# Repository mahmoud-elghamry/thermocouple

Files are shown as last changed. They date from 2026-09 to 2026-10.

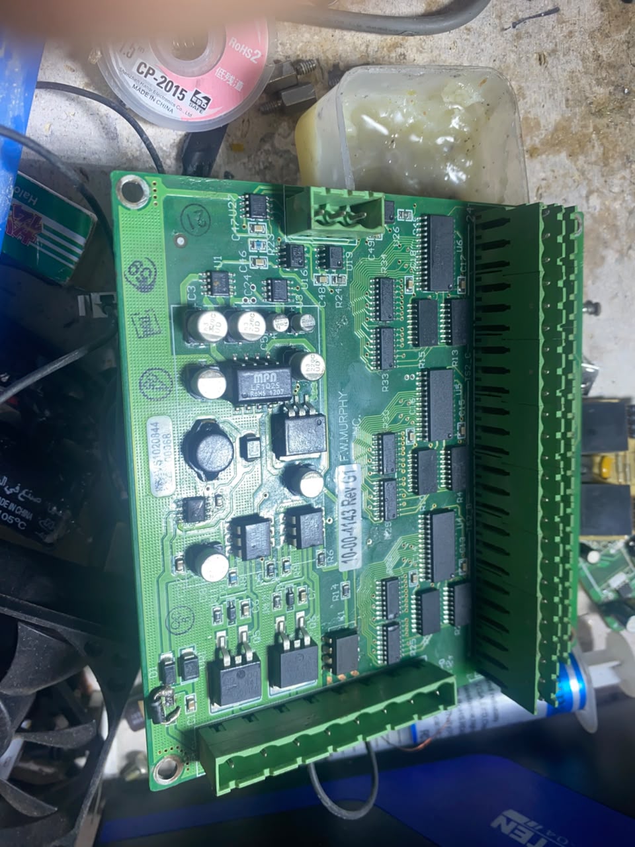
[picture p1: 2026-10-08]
docs/reference/benchmarks/murphy-tdxm/photo-7.jpg

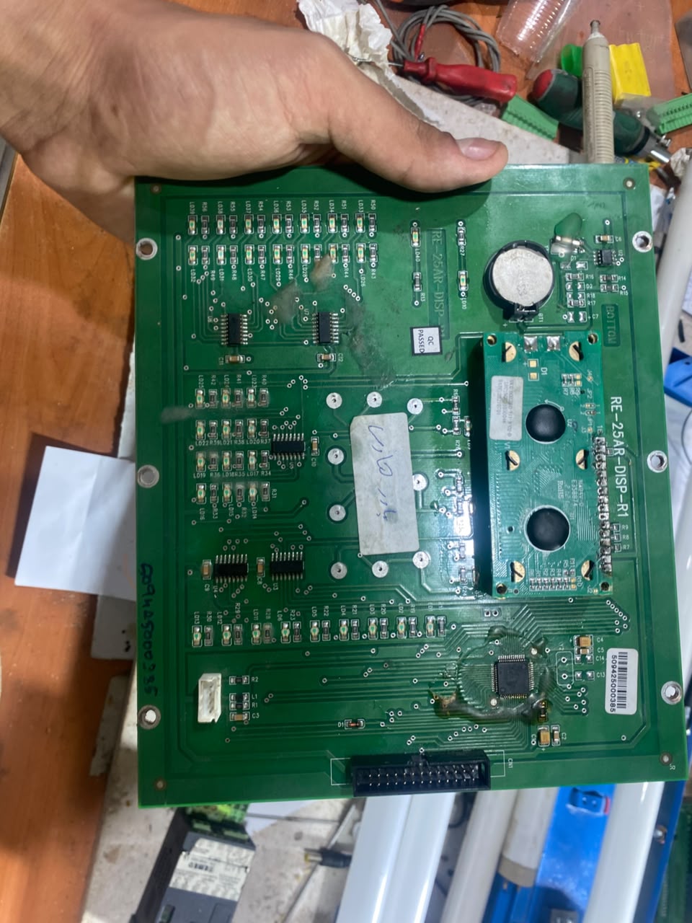
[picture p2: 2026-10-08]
docs/reference/benchmarks/murphy-tdxm/photo-6.jpg

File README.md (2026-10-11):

# Thermo — 24-channel thermocouple protection board

> Working on this repository with an AI agent? Start at **`AGENTS.md`**,
> then `docs/STATE.md`.

One board that reads **24 K-type thermocouples** on one engine (grounded,
insulated or mixed probes, roughly 50 m cables, no VFD) and opens a common
run-permit contact when any channel passes its own setpoint, the sensor fails
or the unit itself fails. It is being built to go on real equipment.

The output is **energised to run**: loss of power, a reset or a fault opens
the contact, so the engine cannot start.

## Where things are

| | |
|---|---|
| **The active board** | `hardware/24ch/` (REV A3, 3x AD7124-8) — see its README; repairs before ordering in `docs/ISSUES.md` P0 |
| **Earlier 8-channel board** | `hardware/8ch/` (REV A2) — reference only, never ordered |
| **Firmware** | `firmware/` — today only the 8-channel images; the 24-channel firmware is not written yet (I-100, I-104, I-118, I-119) |
| **What is done and what is next** | `docs/STATE.md` |
| **Open problems** | `docs/ISSUES.md` |
| **Why things are the way they are** | `docs/decisions/` (start with `0031`) |
| **Commands that actually work here** | `docs/TOOLS.md` |

`hardware/single-channel/` and `_old/` are **superseded** and kept only as a
record. Do not work from them and do not modify them.

## Build and check

```powershell
pwsh -File firmware\build.ps1                 # firmware images + host tests
cd hardware\24ch\gen; python build.py          # 24-ch schematic, ERC, netlist check
python docs\check_docs.py                     # entry documents agree with each other
```

> **The firmware images are not interchangeable.** The eight-channel image
> drives the run output HIGH only while it is *safe to run*; the legacy
> single-channel images drive the same pin HIGH on *over-temperature*.
> Flashing the wrong one inverts the safety function. `program.ps1` warns you.

## State

An **engineering prototype**: nothing has been built or electrically tested.
The isolation rules in `.kicad_dru` are functional, not qualified against any
standard; the contacts are rated for low-voltage signal loads only (30 VDC /
1 A). `docs/ISSUES.md` is the full list; nothing is claimed as done without a
report to back it.

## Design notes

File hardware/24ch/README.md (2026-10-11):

# hardware/24ch — the 24-channel board (REV A3)

One board for all 24 K-type thermocouples (`docs/decisions/0031`), front end
and parts per `docs/decisions/0032` (read all three revisions at its end).
`hardware/8ch/` (REV A2) stays as the reference design and is not modified.

## The schematic is generated

Edit the generator in `gen/`, never the `.kicad_sch` files:

```powershell
cd hardware\24ch\gen
python build.py      # writes the sheets, runs ERC, checks the netlist against the model
```

`build.py` exits non-zero unless kicad-cli ran cleanly and wrote fresh reports, ERC has **0 errors and 0 warnings** and every
pin in the exported netlist matches the model in `gen/c_*.py`.

| File | What it holds |
|---|---|
| `gen/c_power.py` | battery input, PTC, protection, LM5164 5 V buck, 5 V crowbar |
| `gen/c_mcu.py` | ATmega1284P, crystal, ISP, LCD header, five buttons |
| `gen/c_iso.py` | B0505S, LP2985, preload, AVDD clamp, 3x ISO7761, REF3030, V_MID/V_BIAS, engine-reference feed/sense |
| `gen/c_out.py` | trip relay (poles in series), alarm relay, isolated RS-485 |
| `gen/c_bank.py` | one bank: 2 headers, 8 input networks, AD7124-8, 2 ADT7310 (used three times) |
| `gen/model.py`, `emit.py`, `libs.py`, `sexp.py`, `customlib.py` | the generator itself |
| `lib/thermo24.kicad_sym` | AD7124-8 and ADT7310 symbols (generated) |

Every page is A4 or A3 (the owner prints nothing bigger): `build.py` splits a
sheet into `<name>_1`, `<name>_2` pages when it would not fit A3, and stops if a
page still comes out larger.

Nets that appear on more than one sheet become global labels automatically;
all others are local. References: banks 1xx/2xx/3xx, isolation 4xx, MCU 5xx,
power 6xx, outputs 7xx.

## The board

Run with KiCad's python (`C:/Program Files/KiCad/10.0/bin/python.exe`), in order:

| Step | Command | What it does |
|---|---|---|
| 1 | `pcb_new.py` (once) | empty 170 x 145 mm 4-layer board |
| 2 | `kicad-tool pcb sync thermo24.kicad_pcb thermo24.kicad_sch` | footprints and nets from the schematic (needs `KICAD10_FOOTPRINT_DIR`) |
| 3 | `place.py` | every footprint per floor plan v2; prints courtyard overlaps (must be 0) |
| 4 | `rules.py` | domains by pad position (a net in two domains stops it), net classes, `.kicad_dru`, planes, barrier keep-outs, U601 thermal vias |
| 5 | `route24.py --passes 30 --threads 4 [--board copy --tag x]` | Freerouting via DSN/SES, then zone refill |
| 6 | `finish.py` / `maze.py` | **incremental only, after a routing result is kept**: DRC, stubs, lock, hand routes (`add`), maze router + rip-up |
| - | `guard.py`, `fab.py` | `guard.py`: write guard for every tool that saves the board (refuses while KiCad has it open or another tool holds `output/.writer.json`; `guard.sha256`). `fab.py`: a NEW `production/24ch-reva3-<time>-<sha6>/` per run, DRC and plots on a snapshot copy (source never saved), `MANIFEST.txt` (commit, hashes, DRC, KiCad version), `ORDER-NOTES.txt` (I-106/I-105) |
| 7 | `buck24.py`, `move.py`, `capnear.py`, `fiducials.py`, `vbias_pour.py`, `silk.py` | **local repairs (`0034` D3, `0035`)**: buck stage, move parts, put a cap beside its pin (`capnear.py U403 1 C407 --apply`, `capnear.py via REF PAD`), fiducials, V_BIAS guard pours, silkscreen; then `finish.py dangling`/`dedupe`, `maze.py`, `pincaps.py` |
| - | `cost.py`, `view.py`, `kicad_ui.ps1`, `padcheck.py` | BOM cost from LCSC; render a region; drive the KiCad GUI; pad-gap check before routing |

Domains: sensor island = x < 42 or y > 103 (mm, y down); barrier bands x 42-45
and y 100-103, 3 mm copper-free on all layers; RS-485 bus pocket x 55-84,
y < 22. `fpinfo.py` lists courtyard sizes.

## Not done yet

See `docs/STATE.md`. Board repairs from the Astra review (`docs/decisions/0034`):
I-111 decoupling/buck parts beside their pins, I-112 fiducials, I-113 RUN PERMIT
label, I-114 CJ sensors, button header (`0034` D2), I-115 gates, I-116 accessory BOM.
Then `gen/fab.py` again. Every "check" item in `0032` still applies.

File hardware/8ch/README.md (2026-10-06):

# 8-channel thermocouple protection board — engineering prototype

**Status: not released for fabrication.** See “Where this actually stands”
below before drawing any conclusion from a clean check report.

This directory is a self-contained KiCad 10 project. It does not share files
with, and must not be confused with, the single-channel board in `hardware/single-channel/`.

---

## What the board is

| | |
|---|---|
| Size / stack-up | 250 × 140 mm, 4 layers |
| Measurement | 8 × MAX31856, one per K-type input, on a shared isolated island |
| Controller | ATmega32A-PU in a DIP-40 socket, internal RC oscillator, 5 V |
| Local HMI | 16×2 HD44780 in 4-bit mode, five buttons, contrast pot |
| Output | Energised-to-run SPDT dry contact (G5LE-1 24 V) via a BSS131 (240 V) low-side switch, REV A2 (`0022`) |
| Comms | Isolated half-duplex RS-485 (ADM2587E) with jumper-selected termination and bias |
| Supply | 24 VDC in → PTC + series Schottky + TVS → TSR 1-2450 → 5 V |
| Sensor supply | IA0505S isolated DC-DC → LP2985-3.3 → +3V3_SENS |

### Layer stack-up

```
F.Cu    signal + ground pour
In1.Cu  ground planes   GND_SENS | GND_CTRL | GND_RS485
In2.Cu  supply planes   +3V3_SENS | +5V_CTRL | +5V_RS485
B.Cu    signal + ground pour + chassis/PE ring
```

No signal is routed on In1 or In2. Every outer-layer track therefore has an
uninterrupted return directly beneath it, and the In1/In2 pair provides the
interplane capacitance that does most of the high-frequency decoupling for the
microvolt front end.

### Three copper islands

```
      x=6           x=145  x=151.5                  x=208 x=214     x=244
   +-----------------+ gap +-------------------------+ gap +---------+
   |  SENSOR ISLAND  |     |  CONTROL ISLAND         |     |         |  y=6
   |  8 × MAX31856   |     |  ATmega32A, LCD,        |     |(control)|
   |  GND_SENS       |     |  relay, 24 V input      |     |         |  y=97
   |  +3V3_SENS      |     |                   ------+-----+---------+
   |                 |     |                   | gap band            |  y=99
   |                 |     |                   |   RS-485 ISLAND     |
   +-----------------+     +-------------------+   GND_RS485         |  y=134
```

Signals cross a barrier only through U10/U11 (ISO7760 / ISO7761) and U15
(ADM2587E). The gap bands are emitted as KiCad rule areas, so the autorouter
cannot bridge them and a reviewer can see the intent on the board.

A fourth net, `CHASSIS_SHIELD`, is the cable-shield / protective-earth
reference. It is a B.Cu loop 3 mm inside the board edge, bonded to the four
plated M3 mounting holes, to J1.3, J4.4 and the eight thermocouple shield
screws — deliberately isolated from all three signal grounds so a shield
current cannot become a measurement ground loop.

---

## Files

| File | Role |
|---|---|
| `thermocouple_8ch.kicad_sch` | schematic root (A4 index) — the structural source of truth, with its sheets: |
| `power` / `mcu` / `isolation` / `relay_rs485.kicad_sch` | one A4 sheet per function (`docs/decisions/0021`) |
| `channel.kicad_sch` | the thermocouple channel, drawn once, used by TC1-TC8 (`0019`) |
| `thermocouple_8ch.kicad_pcb` | board |
| `thermocouple_8ch.kicad_pro` | project, **including the net classes** |
| `thermocouple_8ch.kicad_dru` | custom clearance rules (isolation, relay, chassis) |
| `sch_layout/build.py` | builds the schematic (base `05d6abd` + `sch_layout/`), with its own ERC and netlist gate |
| `kit_list.py` | the technician's through-hole kit list |
| `apply_rules.py` | writes net classes and `.kicad_dru` into the project |
| `board/` | the generator, split by responsibility - see `board/__init__.py` |
| `generate_board.py` | command-line entry point for `board/` |
| `route.py` | DSN → Freerouting → SES, then pours, stitching and finishing |
| `close_gaps.py` | joins anything DRC still reports as unconnected |
| `check_board.py` | structural checks DRC cannot make (islands, barriers, decoupling, cold junction, filter symmetry) |
| `run_all.ps1` | snapshot validation by default; explicit regeneration after owner authorization |
| `validate.ps1` / `check_commands.ps1` | fresh copy, source hashes, checked native exits and report gates |
| `test_gates.ps1` | fault injection for native-command and report failures |

Design rules live in the **project**, not in the scripts. Anyone opening
`thermocouple_8ch.kicad_pro` in KiCad sees the same track widths, via sizes and
clearances the generator used.

---

## Validating and rebuilding

```powershell
pwsh -File hardware\8ch\run_all.ps1
```

The default validates a fresh snapshot under `production/` without changing the
source hardware, including zone refill on the copy before DRC. Errors stop the
pipeline; warnings remain visible. Full regeneration requires `-Regenerate`; the owner lifted the REV A0 freeze
(`docs/decisions/0014`), so run `board_provenance.py --check` first. The commands
below are the regeneration sequence:

```bash
python sch_layout/build.py --in-place
kicad-cli sch erc --output erc-report.rpt --severity-error --severity-warning thermocouple_8ch.kicad_sch
kicad-cli sch export netlist --output thermocouple_8ch.net thermocouple_8ch.kicad_sch
python apply_rules.py
kicad-tool pcb sync thermocouple_8ch.kicad_pcb thermocouple_8ch.kicad_sch
"C:\Program Files\KiCad\10.0\bin\python.exe" generate_board.py
"C:\Program Files\KiCad\10.0\bin\python.exe" route.py --passes 40 --threads 1
"C:\Program Files\KiCad\10.0\bin\python.exe" check_board.py
kicad-cli pcb drc --output drc-report.rpt --severity-error --severity-warning --schematic-parity thermocouple_8ch.kicad_pcb
```

`generate_board.py` and `route.py` need KiCad 10's bundled Python (`pcbnew`).
Re-running regeneration discards the existing routing. Snapshot validation
checks the current saved board without relying on regeneration reproducibility.

### External tools

Routing needs **Freerouting 2.4.x** and a **Java 25** runtime. Neither is in
this repository. Defaults are `%LOCALAPPDATA%\kicad-tools\freerouting.jar` and
`%LOCALAPPDATA%\kicad-tools\jre25\*\bin\java.exe`; override with
`FREEROUTING_JAR` and `FREEROUTING_JAVA`. Freerouting 2.4.1 is compiled to
class-file version 69, so a Java 21 runtime will not load it.

---

## Check results

Read `erc-report.rpt` and `drc-report.rpt`; these numbers come from them.

| Check | Before | Now |
|---|---|---|
| clearance | 304 | **0** |
| shorting items | 19 | **0** |
| tracks crossing | 22 | **0** |
| dangling vias | 7 | 1 (warning) |
| hole clearance / hole-to-hole | 6 / 5 | **0 / 0** |
| zones intersecting | 2 | **0** |
| starved thermals | 2 | **0** |
| solder-mask bridges | 2 | **0** |
| footprint/symbol field mismatch | 146 | **0** |
| silkscreen overlap / over pad | 10 / 3 | 6 / 2 (warnings) |
| **unconnected items** | 46 | **0** |
| **schematic ↔ PCB parity** | — | **0** |
| ERC errors | 7 | **0** |
| ERC warnings | 189 | 171 (all `endpoint_off_grid`) |

**Zero errors.** The nine remaining violations are warnings: six silkscreen
overlaps, two pieces of silkscreen over a pad, and one dangling via.

`check_board.py` passes all six structural checks that DRC cannot make - island
membership, isolation barrier, decoupling proximity, cold-junction distance,
input-filter symmetry and routing completeness. Zero courtyard overlaps, zero
parts off the board edge, all 167 footprints carry a courtyard.

### Fabrication output

Generated into `production/8ch/` (not committed - regenerate it):

```bash
kicad-cli pcb export gerbers --output ../../production/8ch/     --layers F.Cu,In1.Cu,In2.Cu,B.Cu,F.Paste,B.Paste,F.Silkscreen,B.Silkscreen,F.Mask,B.Mask,Edge.Cuts     --subtract-soldermask thermocouple_8ch.kicad_pcb
kicad-cli pcb export drill --output ../../production/8ch/ --format excellon     --drill-origin absolute --excellon-units mm --generate-map --map-format gerberx2 thermocouple_8ch.kicad_pcb
kicad-cli pcb export pos --output ../../production/8ch/thermocouple_8ch-pos.csv     --format csv --units mm --side both thermocouple_8ch.kicad_pcb
kicad-cli pcb export ipcd356 --output ../../production/8ch/thermocouple_8ch.d356 thermocouple_8ch.kicad_pcb
```

Eleven Gerber layers, Excellon drill plus map, the `.gbrjob`, a placement CSV
and an IPC-D-356 netlist for the fab's electrical test.

**Do not hand-edit the board.** `generate_board.py` clears every track, via,
zone and drawing, so anything drawn by hand in KiCad is erased on the next run.
Fixes belong in `board/` or in `route.py`.

---

## Where this actually stands

Nothing here makes this board safe to put on a machine. The following remain
open and none of them can be closed by DRC, ERC, or a 3D render:

- **The shared sensor island is a conditional proof of concept.** It isolates
  the group of eight channels from the controller. It does **not** isolate the
  channels from each other. It is only valid if the eight thermocouple sheaths
  are measured to be at the same potential, on the same equipotential bond.
  That measurement has not been made.
- **MAX31856 is not a galvanic isolator.** It is a better thermocouple
  front end than MAX6675 — filtering, fault detection, input protection — but
  T+/T− are not separated from AGND/DGND. Its presence does not solve a
  grounded tip or a 50 m cable.
- **The isolation rules are functional, not certified.** `.kicad_dru` enforces
  3 mm between islands. That number comes from the tightest part on the board
  (the IA0505S module's own pin pitch), not from a creepage/clearance analysis
  against IEC 61010 at a stated working voltage and pollution degree.
- **The PE ring's spacing is set by connector geometry.** Screw terminals put
  the shield pin 5.00 mm from the adjacent signal pin, which leaves 2.4 mm of
  copper gap. The chassis clearance rule is 1.5 mm for that reason. It is not
  a mains-rated separation.
- **The dry contact is marked LOW-VOLTAGE LOAD ONLY** and its clearances are
  chosen to match that, not a mains rating.
- **No noise, EMC or real-sensor testing has been done.** Cables run about 50 m
  from engine cylinder bodies to a separate panel, with no VFD in the installation.
  Layout symmetry and a plane pair improve the odds;
  they do not substitute for measurement.
- **The unregulated isolated DC-DC needs review.** IA0505S is an unregulated
  ±5 V module. At the ~12 % load this island draws, its output can sit well
  above 5 V. The AP2112K was replaced by LP2985-3.3 with a higher input rating
  (decision 0002), but the converter's real output still needs measurement.
- **DRDY and FAULT are not brought to the MCU.** Both isolators are fully
  allocated (ISO7760: 6/6 forward; ISO7761: 5 forward + 1 reverse for MISO), so
  crossing sixteen more signals needs a second isolator plus fault-OR logic.
  The firmware reads the MAX31856 fault register (0x0F) on every sample. This
  is a deliberate trade-off — see the plan document — not an oversight.
- **Stock and price snapshots in `passives_catalog.json` are not a live
  availability guarantee.** Re-check before ordering.

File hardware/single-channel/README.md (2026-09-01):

# Thermocouple meter PCB

Editable two-layer KiCad 10 PCB for an ATmega32A, MAX31856, off-board 16x2
LCD, alarm LED and 5 V SPDT relay. The board is 150 x 70 mm. It accepts a
regulated 5 V input and makes 3.3 V locally with an AMS1117-3.3. The MCU and
MAX31856 run at 3.3 V; the LCD runs at 5 V.

The thermocouple front end follows the MAX31856 application guidance:

- BIAS is connected to T-.
- Matched 100 ohm series resistors are fitted in T+ and T-.
- 100 nF is fitted differentially across T+ and T-.
- 10 nF common-mode capacitors are fitted from each input to ground.
- 100 nF local bypass capacitors are fitted at AVDD and DVDD.

Generate the PCB from the deterministic Python source, run DRC, then export
Gerbers, drill files, PDF and 3D previews:

```powershell
& 'C:\Program Files\KiCad\10.0\bin\python.exe' .\generate_board.py
& .\build_outputs.ps1
```

J2 is a standard 16-pin HD44780 LCD header. J4 is a 6-pin AVR ISP header.
The ATmega32 uses its internal 8 MHz clock, so no crystal is required.

PB3 (DIP pin 4) drives Q1 through R4; Q1 switches the K1 coil. D1 clamps the
coil flyback voltage, R5 keeps the relay off during reset, and D2/R6 indicate
the output state. J5 exposes COM/NO/NC. This contact area is intended only for
low-voltage loads in this revision; it is not documented or certified for mains.

## Delivered fabrication files

- `thermocouple_meter.kicad_pcb`: editable KiCad 10 board.
- `drc-report.txt`: zero violations and zero unconnected pads.
- `gerbers/`: copper, solder-mask, silkscreen, outline and drill files.
- `output/thermocouple_meter_gerbers.zip`: fabrication archive.
- `output/thermocouple_meter_layers.pdf`: printable layer plots.
- `output/positions.csv`: component positions.
- `output/pcb_top.png`, `pcb_bottom.png`, `pcb_isometric.png`: 3D previews.
- `output/kicad_happy_pcb_analysis.json`: extra PCB/DFM analysis.
- `output/kicad_happy_gerber_analysis.json`: extra Gerber analysis.

Three global fiducials are included. The router also forbids layer changes in
pad keepouts, eliminating the via-in-pad warnings found during the additional
DFM pass. The remaining PCB-analyzer warning is low test-point coverage, which
is accepted for this hand-assembled educational revision.

This board is for the **MAX31856 final hardware**. MAX6675 is used only as a
Proteus fallback and is not a pin-compatible replacement for MAX31856.

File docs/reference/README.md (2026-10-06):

# Reference

Background documents. **These are not sources of truth any more.**

The live documents are `AGENTS.md` at the repository root and the five files in
`docs/`. If something here disagrees with `docs/STATE.md`, `docs/ISSUES.md` or
`docs/decisions/`, those win.

| File | What it is | Still useful for |
|---|---|---|
| `INDUSTRIAL_8CH_PLAN_AR.md` | the original requirements and architecture study | the reasoning behind the isolation architecture, the No-Go conditions, the standards list. **Its §22 prototype geometry (250 x 140, 30 mm channel pitch) was never justified - see `0028`, I-090** |
| `SOFTWARE_ARCHITECTURE_AR.md` | the MCAL/HAL/APP layering | firmware work |
| `CONNECTIONS.md` | pin map used by the Proteus simulation | the simulation only — not the 8-channel board |

`analysis/` holds a kicad-happy run against the single-channel board from
2026-09-01. It is kept on disk but not tracked: it is machine output, and the
findings it supported are now issues in `docs/ISSUES.md`.

Moved to `_old/docs-reference/` on 2026-10-06: `DESIGN_REVIEW_AR.md` (single-channel
review, findings already in ISSUES), `LESSONS_LEARNED_AR.md`, `PROJECT_GUIDE_AR.md`.

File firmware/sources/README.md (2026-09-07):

# Source lists

One file per link unit, one source path per line, relative to `firmware/src/`.

Both build systems read these files instead of carrying their own copy of the
list. Before this, `Makefile` and `build.ps1` each held a hand-maintained set
of sources that had already started to drift, and a file added to one but not
the other builds green on the developer's machine and fails in CI, or worse,
links a different program than the one that was tested (`I-022`).

Blank lines and `#` comments are ignored.

| File | Links into |
|---|---|
| `base.txt` | every target: GPIO, SPI, board pin map, LCD |
| `app_8ch.txt` | the eight-channel protection application, minus its converter |
| `bank_max31856.txt` | the real board's converter bank (`U2`..`U9`) |
| `bank_max6675.txt` | the Proteus simulation's converter bank |
| `app_legacy.txt` | the superseded single-channel board's application |
| `sensor_max31856.txt` | single-channel MAX31856 backend for the legacy app |
| `sensor_max6675.txt` | single-channel MAX6675 backend for the legacy app |
| `host_test.txt` | the pure modules the host tests link natively |
| `host_test_app.txt` | `main_8ch.c`'s application modules, linked natively against HAL doubles alongside `main_8ch.c` itself (pulled in by `#include`, not listed here - see the list's own comment) (I-042) |
| `host_test_driver.txt` | the MAX31856 bank driver, linked natively against a register model (I-042) |

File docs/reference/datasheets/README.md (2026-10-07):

# Datasheets

The documents this design was actually reasoned against. Downloaded 2026-09-10.

Tracked on purpose. A hardware project that cites a clamping voltage or an
input range should be able to show where the number came from, and manufacturer
URLs rot. About 23 MB in total.

| File | Part | What it settles here |
|---|---|---|
| `ATmega32A.pdf` | ATmega32A | fuse map (`firmware/fuses.md`): `CKSEL` for internal RC 8 MHz, BOD levels, and that **JTAGEN is programmed from the factory and occupies PC2-PC5** |
| `TSR1-series.pdf` | Traco TSR 1-2450 (was `U14`; replaced by LM5164, `0016`) | input range **6.5-36 V**, which is what carries a cranking dip and what fails on a 58 V load dump (`I-028`) |
| `R-78HB-0.5.pdf` | Recom R-78HB (candidate) | input **9-72 V**, 0.5 A. The wide-input candidate - note the 9 V minimum is *worse* for cranking than the 6.5 V fitted part |
| `G5LE-relay.pdf` | Omron G5LE-1 DC24 (`K1`) | coil 1.44 kOhm / 16.7 mA, must-operate 18 V, **must-release 2.4 V** - why an energised relay does not drop out during a cranking dip |
| `ISO7760.pdf` | TI ISO7760 (`U10`) | six-channel digital isolator, control to sensor island |
| `ISO7761.pdf` | TI ISO7761 (`U11`) | five-forward/one-reverse isolator, carries MISO back |
| `LP2985.pdf` | TI LP2985-3.3 (`U13`) | the 3.3 V sensor-island regulator chosen in `docs/decisions/0002` |
| `LM74930.pdf` | TI LM74930-Q1 | not fitted. An ISO 16750-2 load-dump protection controller, kept as the reference for what the battery case in `I-028` would actually need |
| `LM5164.pdf` | TI LM5164 (`U14`), SNVSAU4D, from ti.com, added 2026-09-26 | the source of every value in `CALCULATIONS.md` section 1: 100 V absolute maximum, EN/UVLO thresholds, R_RON, feedback, ripple injection |
| `ADM2587E.pdf` | ADI ADM2582E/ADM2587E (`U15`), Rev. C, from LCSC `C12081` (analog.com blocked), added 2026-09-26 | supply current: **120 mA maximum**, 98 mA typical into 54 Ohm - replaced the 100 mA estimate in `CALCULATIONS.md` 1.1 |
| `MAX31856.pdf` | Maxim MAX31856 (`U2`-`U9`), 19-7534 Rev 0, from LCSC `C116632` (analog.com blocked the workstation), added 2026-09-26 | **T- is biased to ~0.735 V by the BIAS output**, and the typical circuit ties BIAS to T- with a floating thermocouple - so the ungrounded probes of `0008` need no extra resistor (`I-027`). BIAS floats between conversions, which is why the firmware runs continuous mode |
| `BSS131.pdf` | Infineon BSS131 (`Q1` since REV A2), Rev. 2.6, from LCSC `C151498`, added 2026-09-28 | **240 V** V(BR)DSS against D2's 96.8 V clamp; VGS(th) 0.8-1.8 V; RDS(on) 20 Ohm max at 4.5 V; **pinout 1 G, 2 S, 3 D** (p1 drawing); ESD Class 0 (`I-066`, `0022`) |
| `1812L-PTC.pdf` | LUTE 1812L series (`F1` 1812L075/60GR since REV A2), from LCSC `C48985874`, added 2026-09-28 | **60 V** max, 0.75 A hold / 1.5 A trip, R min 0.090 Ohm, and the **hold-current derating table** that sets the 70 °C limit in `CALCULATIONS.md` 4.4 (`I-068`) |

## Not here

The **actual physical K-type probe** and extension cable have no recorded
manufacturer/model. The owner reports a probably grounded junction and accepts
the shielded extension-cable basis (`0029`, 2026-10-07). `MAX31856.pdf` is the
reader IC's datasheet, not the probe's. It is already available offline; do not
download it again or substitute a generic probe catalog as an exact match.
An electrically ungrounded junction still measures temperature. Identify the
installed/chosen probe before obtaining its exact temperature/insulation limits.
ADI/Omega reference download attempts in this cloud returned HTTP 403.

Not downloaded: `IA0505S` (`U12`, XP Power), the SMBJ TVS series
(`D2`; Littelfuse blocks download - the SMBJ33A figures used in `I-028` are
33 V standoff, 36.7-40.6 V breakdown, 53.3 V clamping, 600 W at 10/1000 us),
`SS310`, `1N4007`/`M7`, and the `2N7000` REV A1 used.

## Adding one

Keep the filename the part name, add a row above saying **what question the
document answers for this project** - not what the part is. A datasheet nobody
can say the purpose of is a 3 MB file nobody opens.

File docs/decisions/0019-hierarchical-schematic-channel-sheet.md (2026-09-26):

# 0019 — A3 root plus one channel sheet used eight times

* Status: accepted; amended by `0021` (functional sheets on A4)
* Date: 2026-09-26
* Deciders: owner (asked for A4 sheets, a channel drawn once), agent (the split)
* Relates to: `I-062`, `I-002`, `docs/decisions/0012`

## Context

The schematic was one flat A2 sheet with all 201 parts. It was correct but
hard to print or read. The owner asked for sheets per function on A4, with
the thermocouple channel drawn once and used eight times.

Net names are not cosmetic here. `apply_rules.py` assigns net classes by name
pattern, and those classes drive the isolation rules in `.kicad_dru`. The
board generator finds the RS-485 planes by name, and `check_board.py` sorts
nets into islands by name. A hierarchical sheet prefixes every net that stays
inside it with the sheet path.

Measured on the netlist: only **seven** nets leave a channel (its CS, plus
SCK, MOSI, MISO, +3V3_SENS, GND_SENS and CHASSIS_SHIELD). The other blocks,
however, have 65 sheet-local nets, and many of them are named in the rules
and in the generator: `+5V_RS485`, `GND_RS485`, `RELAY_*`, `RS485_*`,
`+24V_*`, `+5V_ISO`.

## Options

* **(a) Every function on its own A4 sheet.** This renames about 65 nets
  across the isolation rules, the plane generator and the checks.
* **(b) The channels only, as one reused sheet; the rest stays on the root,
  packed onto A3.** This renames 40 nets, all inside channels, all following
  one pattern: `/TCn_FILT_P` becomes `/TCn/FILT_P`.
* **(c) Keep the old names** by bringing every internal net out to a root
  label. This needs more than a hundred extra labels on the root, which is
  more clutter than the flat sheet had.

## Decision

**(b).** It delivers what the owner wanted most: one channel drawing, reused.
It confines the renames to a single pattern, which three places can match.
The isolation-relevant names of the control, RS-485 and relay blocks are not
touched at all. The root is A3, not A4: the MCU, isolators, power supply,
RS-485 and relay together do not fit A4 at a readable size.

How it is done and proved:

* `sch_layout/hier.py` derives the two files from the flat wired sheet, as
  the last step of `build.py`. It refuses if any channel's symbols are not
  placed exactly like channel 1's.
* `netlist_fingerprint.py --allow-renames` matches nets by their pin sets:
  all 645 pins stayed on the same nets, no component was added or removed.
  Exactly two deliberate differences: the 40 renames, and JTC1–8's value
  `TCn_K_TYPE` becomes `K_TYPE`, because KiCad 10 keeps one value per symbol,
  not per sheet instance. The baseline was regenerated from that proven
  netlist, with the reason written into it.
* `apply_rules.py` patterns now read `/TC?/FILT_?`, `/TC?/RAW_?` and
  `/TC?/MISO_CH`. **Without that change the channel nets fall to Default,
  and DRC reported 499 isolation violations on a test copy.**
* `sch_layout/rename_board_nets.py` renames the board's nets in place, so
  pads, tracks and zones move together; `kicad-tool pcb sync` alone moved
  only the pads. Copper is unchanged.

## Consequences

* Result on the workstation, KiCad 10.0.6: ERC 0/0; netlist IDENTICAL to the
  revised baseline; DRC 0 errors, 0 warnings, 0 unconnected, 0 parity;
  `check_board.py` all 6 ok; all 40 channel nets in `SensorSignal`.
  `build.py` from `05d6abd` reproduces the result (IDENTICAL, ERC 0/0).
* A new channel-level net needs a pattern in `apply_rules.py` of the form
  `/TC?/NAME`.
* `validate.ps1` and `board_provenance.py` now carry `channel.kicad_sch`.
* The flat wired sheet exists only as an intermediate in `build.py`'s scratch
  folder. `populate_schematic.py` still writes flat, label-only output as
  before; `build.py` carries it to the hierarchy.

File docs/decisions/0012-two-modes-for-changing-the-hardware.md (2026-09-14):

---
status: accepted
date: 2026-09-13
deciders: Zain
amends: 0010
---

# Two modes for changing the hardware, with a guard between them

## Context

Until now the hardware had exactly one way to change: run the pipeline.
`populate_schematic.py` rewrites the schematic, `generate_board.py` clears every
track, via, zone and drawing and re-places from `board/`, and `route.py` runs
Freerouting over the result. `AGENTS.md` rule 9 said, correctly, that nothing
drawn by hand survives.

That was the right architecture for getting from nothing to a placed, routed,
DRC-clean board. It is the wrong one now, and the reason is `docs/decisions/0010`:
REV A0 is frozen, and what the board needs from here are surgical changes -
nudge one silkscreen label, drop one dangling via, add two resistors for the
run-permit read-back.

Regenerating for a change that size is not conservative, it is reckless:

    move one silkscreen label
      -> generate_board.py clears the whole board
      -> Freerouting routes from scratch, differently every run
      -> a board nobody has verified, in place of one that passed
         0 DRC errors, 0 unconnected, 0 parity

Meanwhile a KiCad MCP is now installed (`.mcp.json`), which makes direct editing
practical for an agent rather than only for a human in the GUI.

## Decision

**Both modes are legitimate. Pick by the size of the change.**

| | Generative | Incremental |
|---|---|---|
| How | `populate_schematic.py`, `generate_board.py`, `route.py` | KiCad, or the KiCad MCP's seven write tools |
| Right for | new parts, a changed stack-up, re-placement, anything touching many nets | one label, one via, a value, a small local edit |
| Cost | full re-route, full re-verification, new Gerbers | none beyond the edit and its checks |
| Reproducible | yes - rerun and get the same board | no - the edit lives only in the file |

**What is forbidden is not either mode. It is running the generator on top of
hand edits without knowing they are there**, which destroys work silently and
which nothing in the project could previously detect: `netlist_fingerprint.py`
compares the *schematic's* connectivity and never looks at the PCB, and
`validate.ps1` hashes files only within a single run.

So a guard was added: `hardware/8ch/board_provenance.py`.

- `--record` stores the SHA-256 of `thermocouple_8ch.kicad_pcb` and
  `.kicad_sch` as the generator left them. Run it after every generator run.
- `--check` compares. It exits non-zero when the files have drifted, which
  means hand edits exist and a generator run would lose them. It also refuses
  while KiCad holds a `~*.lck`, because a second writer is exactly how the
  board was lost on 2026-09-07.
- `--status` reports without failing.

Tested on 2026-09-13: drift detected on a one-byte change, lock file detected,
and a clean tree reports `regenerating is safe`.

## The rule for crossing between modes

Going generative → incremental is free. Going the other way is not:

> Once the board has been hand-edited, the generator may not be run until the
> edit is either **folded back into `board/` and the part tables**, or
> **deliberately abandoned** - and `--record` re-run to say so in writing.

`--check` enforces the first half. The second half is a human decision and
should leave a line in `docs/STATE.md` saying what was given up.

## On closing KiCad

The guard **refuses** while KiCad has the project open. It does not close
KiCad, and no agent should: the window may hold unsaved work, which is the
2026-09-07 failure exactly. Opening KiCad is harmless; closing it is the user's
call.

## Consequences

**`board/`, `generate_board.py` and `route.py` stay.** They are not dead. They
are how the board is rebuilt when a change is big enough to deserve it, and
they remain the record of how REV A0 came to exist. This decision does not
retire the generative pipeline; it stops it being the only option.

**`check_board.py` still applies in both modes.** Its six structural checks -
island membership, isolation barrier, decoupling proximity, cold-junction
distance, filter symmetry, routing completeness - read the board as it is on
disk and do not care who wrote it.

**A hand-edited board cannot be reproduced from source.** That is the real
price. It is acceptable for a frozen revision whose Gerbers already exist; it
would not be acceptable while the design was still moving.

**The MCP's seven write tools are NOT permitted.** They were, for a few hours
on 2026-09-13, until the server's source was read. Correction below.

## Correction, same day: the MCP is read-only here

This decision originally allowed the KiCad MCP's seven write tools in
incremental mode. That was written from the tool list, not from the code. The
code says otherwise.

`add_wire` in `schematic_editor.py` does this: read the file as text, build a
`(wire (pts ...))` string, strip the final `)`, concatenate, write the file
back. No parser, no schema, no check that the coordinates land on a pin, no ERC
afterwards. `add_label` and the rest are the same shape. That is a blunter
instrument than `populate_schematic.py`, which at least resolves pin positions
from `kicad-tool sch query symbol --format json` before it places anything.

So the incremental mode stands, but its tool is **KiCad itself, or our own
scripts** - not the MCP. The MCP stays for what it is genuinely better at:
reading the PCB through `pcbnew` (real track lengths, via counts, zone areas)
instead of through hand-written regex, which got connectivity wrong twice on
2026-09-07.

The seven write tools are denied in `.claude/settings.json` so this is enforced
rather than merely written down.

## Rejected

**Stay purely generative.** Rejected: it makes a one-label fix cost a full
re-route and re-verification, which in practice means the fix never happens -
`I-006` and `I-024` have been open since the board was first routed for exactly
this reason.

**Go purely incremental and delete the pipeline.** Rejected: the measurements
still ahead (`I-003`, `I-004`, `I-013`) may force a change big enough to want a
clean regeneration, and `I-028` could still replace the whole input stage.
Throwing away a working generator before those are settled would be premature.

**Let an agent close KiCad automatically.** Rejected on the evidence: the
2026-09-07 loss was unsaved work in an open window. An agent cannot tell
whether a window holds unsaved work, and losing a user's edits to save a prompt
is a bad trade.

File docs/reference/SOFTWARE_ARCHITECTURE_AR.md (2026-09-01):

# تقسيم البرنامج إلى MCAL / HAL / APP

## لماذا التقسيم؟

الهدف أن قرار المشروع لا يختلط بسجلات الميكرو أو بتفاصيل نوع الحساس. لو تغير
MAX6675 إلى MAX31856، تتغير طبقة Driver واحدة فقط، ويبقى منطق الشاشة والإنذار
كما هو. ولو تغير ATmega32 لاحقًا، نستبدل MCAL بدل إعادة كتابة التطبيق كله.

```text
APP: main + pure logic + 100/95 C decision
             |
HAL: LCD | temperature sensor | alarm output
             |
MCAL: GPIO | SPI | board pin mapping
             |
Hardware: ATmega32A registers and pins
```

## MCAL — Microcontroller Abstraction Layer

هي الطبقة الوحيدة التي تعرف سجلات AVR وأرقام البورتات. لا تتخذ قرار تشغيل
الريلاي ولا تعرف معنى درجة الحرارة.

| الملف | الوظيفة |
|---|---|
| `include/mcal/gpio.h` | أنواع ودوال عامة لضبط اتجاه الرجل وكتابتها وقراءتها. |
| `src/mcal/gpio.c` | تنفيذ GPIO باستخدام DDRx وPORTx وPINx. |
| `include/mcal/spi.h` | واجهة بدء SPI ونقل بايت مع نتيجة نجاح/فشل. |
| `src/mcal/spi.c` | إعداد SPI Hardware ونقل بانتظار محدود يمنع التعليق الدائم. |
| `include/mcal/board.h` | أسماء أرجل اللوحة: LCD وCS وPB3. |
| `src/mcal/board.c` | ربط الأسماء بأرجل PORTA وPORTB الحقيقية. |

ميزة `board.c`: إذا نقلنا LED من PB3 إلى رجل أخرى، نغير Pin Mapping في مكان
واحد بدل البحث داخل جميع الملفات.

## HAL — Hardware Abstraction Layer

تحول الهاردوير إلى وظائف مفهومة للتطبيق. APP تطلب «اقرأ الحرارة» أو «شغل
الخرج»، ولا ترسل SPI أو تحرك بتات GPIO بنفسها.

| الملف | الوظيفة |
|---|---|
| `include/hal/lcd.h` | واجهة بدء الشاشة وطباعة سطر. |
| `src/hal/lcd.c` | HD44780 في 4-bit mode وإرسال البايت على مرحلتين. |
| `include/hal/temperature_sensor.h` | واجهة موحدة لعينة فيها حرارة وصلاحية وبتات Fault. |
| `src/hal/temperature_max6675.c` | Driver محاكاة Proteus: إطار 16-bit وOpen fault. |
| `src/hal/temperature_max31856.c` | Driver اللوحة: تهيئة K-Type وقراءة الحرارة والأعطال. |
| `include/hal/alarm_output.h` | واجهة تشغيل/فصل خرج الإنذار. |
| `src/hal/alarm_output.c` | يقود PB3 ويحفظ حالته الحالية. |

ملفا الحساس ينفذان نفس أسماء الدوال في `temperature_sensor.h`. أثناء البناء
يُربط **ملف واحد فقط** منهما مع بقية البرنامج، لذلك APP لا تحتاج `#ifdef` ولا
تعرف أي MAX مستخدم.

## APP — Application Layer

| الملف | الوظيفة |
|---|---|
| `include/app/app_config.h` | حدود 1000/950 وسياسة الخرج عند عطل الحساس مع فحص Compile-time. |
| `include/app/app_logic.h` | واجهة المنطق المستقل القابل للاختبار. |
| `src/app/app_logic.c` | Hysteresis وتنسيق القراءة ورسائل Fault بلا سجلات AVR. |
| `src/app/main.c` | التهيئة، القراءة الدورية، إعادة المحاولة، LCD والـWatchdog. |

APP تنفذ السياسة التالية:

```text
Fault?             -> Output OFF
Output OFF و T>=100 -> Output ON
Output ON  و T<=95  -> Output OFF
T بين 95 و100       -> احتفظ بالحالة السابقة
```

## كيف ينتج ملفا HEX؟

`firmware/build.ps1` يبني ملفات MCAL وHAL المشتركة وAPP مرة واحدة، ثم:

- يربطها مع `temperature_max31856.c` لينتج `thermocouple_meter_max31856.hex`.
- يربطها مع `temperature_max6675.c` لينتج `thermocouple_meter_max6675.hex`.

يستخدم البناء `-Wall -Wextra -Werror`؛ أي Warning يعامل كخطأ. كما يحذف فقط
ملفات البناء `.o/.elf/.hex` قبل البناء حتى لا يبقى HEX قديم لا يطابق السورس.
بعد بناء AVR، يبني ويشغّل `tests/test_app_logic.c` على الكمبيوتر لاختبار حدود
100/95، الأعطال، الدرجات السالبة وتنسيق LCD. وMakefile ينشئ Dependency files
حتى يؤدي تغيير Header إلى إعادة بناء الملفات التابعة له بدل استعمال Object قديم.

أمر البناء على هذا الجهاز:

```powershell
& D:\tasks\thermo\firmware\build.ps1
```

## ماذا نغير عند التوسعة؟

- حد الحرارة: `app_config.h` فقط.
- نوع حساس جديد: Driver جديد في HAL يطبق `temperature_sensor.h`.
- ريلاي إضافي: Output جديد في HAL، ثم سياسة جديدة في APP.
- ميكرو مختلف: MCAL وboard mapping، مع إبقاء واجهات HAL/APP قدر الإمكان.

## النتيجة الحالية

- MAX31856: البناء ناجح، Program 2454 bytes، Data 191 bytes.
- MAX6675: البناء ناجح، Program 1932 bytes، Data 189 bytes.
- لا توجد أخطاء أو تحذيرات Compile.
- اختبارات Application logic تعمل وتنجح محليًا، وملف GitHub Actions يعيد
  البناء والاختبار عند كل Push أو Pull Request بعد رفع التعديلات.
- الزيادة الصغيرة في الحجم مقابل النسخة السابقة هي ثمن اكتشاف Faults، فحص
  إعداد MAX31856، Timeout، رسائل آمنة وWatchdog؛ وما زالت الذاكرة بعيدة عن الحد.

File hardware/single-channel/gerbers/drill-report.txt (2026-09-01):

Drill report for thermocouple_meter.kicad_pcb
Created on 2026-09-01T04:04:53

Copper Layer Stackup:
    =============================================================
    L1 :  F.Cu                      front
    L2 :  B.Cu                      back

Drill file 'thermocouple_meter-PTH.drl' contains
    plated through holes:
    =============================================================
    T1  0.300mm  0.0118"  (30 holes))
    T2  0.800mm  0.0315"  (43 holes))
    T3  1.000mm  0.0394"  (24 holes))
    T4  1.300mm  0.0512"  (4 holes))

    Total plated holes count 101

Drill file 'thermocouple_meter-NPTH.drl' contains
    unplated through holes:
    =============================================================
    T1  3.200mm  0.1260"  (4 holes))

    Total unplated holes count 4

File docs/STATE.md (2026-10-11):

# Current state

**Read second, after AGENTS.md; then read all of ISSUES.md (P0 first). Hard limit: 60 lines.**
**Last updated:** 2026-10-11 (workstation: doc sync, NORI answers, then the P0 repairs).

## Where we are

* REV A2 (8ch, reference) passes every gate (below), FW 0.2.1; never ordered. Next order is the
  24-ch **REV A3**. Superseded files are in `_old/` (see its README).

## 2026-10-08: ONE 24-channel board (`0031`) — read it before any work

* `0031` supersedes most of `0030`; still valid there: D2 comms never in trip path, D5, D8.
* Front end **3x AD7124-8** on one isolated island in parallel; 20 M TC- bias, mid-rail reference
  wire, CJ sensors at the terminals, open-TC check one channel per scan (~4 s each).
* 20x4 LCD (bought locally) + 5 buttons (+ panel header, `0034` D2); trip + alarm relay (30 VDC / 1 A signal);
  isolated RS-485/Modbus (ADM2587E); shield at panel entry; **all parts from one source** (NORI, I-103).
* `0032` = circuit + parts after Codex/Opus reviews (power `CALCULATIONS` 7, front end, floor plan).

**2026-10-09: 24-ch board, `hardware/24ch/` (README there), decisions `0032`-`0033`.**
Schematic 467 symbols, ERC 0/0, 12 pages A3/A4. Board 170 x 145 (`0033` D1). Fab NORI (I-106); parts ~$105 (`gen/cost.py`).
Board routed 2026-10-09 (history: git log). The 2026-10-09 fab set is **outdated**, moved to `production/_OLD_DO_NOT_ORDER/`
(board changed 2026-10-11) - never order from it; `gen/fab.py` makes a new one. Board: `hardware/24ch/thermo24.kicad_pcb`.

## Start here - next steps

**2026-10-11 (one session):** docs synced to `0031`-`0035`, `docs/check_docs.py` guards them (CI too);
ISSUES re-triaged (P0 = blocks the order only). NORI: our spec rides in ORDER-NOTES (I-106, I-105).
Board (`thermo24.kicad_pcb`, backups `output/bak/`): LM5164 stage re-laid (`gen/buck24.py`), ISO7761 +
MCU caps beside pins, crystal to the XTAL pins (I-121), J503 panel-button header (`0034` D2), fiducials,
installer silk (I-113), V_BIAS guard pours (`gen/vbias_pour.py`, I-105). Gates: DRC+parity+refill 0/0/0;
ERC 0/0 (468 symbols); `pincaps.py` 33/33 pass (exit 0).
New tools: `move.py`, `capnear.py` (spot search, rip, `via`), `finish.py dedupe`, `guard.py` on every writer.
**I-111 closed** (`0035` D6, owner: AD7124 supplies by plane vias, REGCAP/REFOUT <= 5 mm): `pincaps.py` 0 over.
**Next (only P0 left = I-078):** send `production/24ch-reva3-20261011-094327-940d10/` (git 7c7e25c, clean;
DRC 0/0/0, pincaps 0) to NORI for the turnkey quote incl. ACCESSORIES.csv. I-108 closed (owner: buy a 2004A that
fits H6-H9/J502), I-106/I-103 closed (ORDER-NOTES). Board warnings: 8 dangling stubs, 0 errors.
Then firmware P1 (I-118/119/104/100); bench P2 (I-120, I-101, I-105).

## Measured, not claimed (REV A2, before the shrink)

| Check | Result |
|---|---|
| Workstation, 2026-10-09 | 8ch snapshot `production/validation-20261009-043553-906505`: ERC/DRC 0/0, netlist identical; firmware 4 builds / 3 suites PASS. Separate 24ch report above. |
| `validate.ps1` 2026-10-06 22:09, after the cleanup | ERC 0/0; netlist IDENTICAL 202/163/647; 129/129 MPN match; DRC 0/0/0/0 (`production/validation-20261006-220958-ac80be`) |
| `firmware/build.ps1` 2026-10-06, after the cleanup | 3 suites PASS; 4 images built (8ch FW 0.2.1, 5918 B on 2026-10-01) |
| Cloud gates, 2026-10-07 | `make all test`: 4 targets/3 suites pass; ERC/DRC 0/0; netlist 202/163/647 identical; 129 MPN match; source unchanged (`production/validation-20261007-080427-e91cea`) |
| Board area (pcbnew, 2026-10-06) | 250.1 x 140.1 mm; 193 parts, courtyards 67 cm² = 19 % |

No physical qualification/SPICE. Git works; GitHub API HTTP 403.

## Preserve for hardware work
* Konnect is the only KiCad MCP (`0013`); run `board_provenance.py --check` before any board write, `--record` after.
* `route.py` re-drills vias to a 0.15 ring after the SES import (I-075). Check the exported drill file, not only DRC.
* `build.py` starts from `05d6abd` + `sch_layout/reva2.py`. kicad-tool clones inherit their MPN (I-054).
* `kicad-tool pcb sync` needs `KICAD10_FOOTPRINT_DIR`. Freerouting is deterministic for a given input.
* Never change a baseline to make a gate pass. Never edit `hardware/single-channel/` or anything in `_old/`.

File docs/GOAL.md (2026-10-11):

# Goal and requirements

**Owner: the user.** An agent may propose a change here but must not rewrite it
alone. Changes go through `docs/decisions/`. Status column synced to `0031`-`0034`
2026-10-11 at the owner's request.

**Keep under 120 lines.**

---

## The goal

A system that reads **24 K-type thermocouples** on **one 24-channel board**
(owner, 2026-10-08, `decisions/0031`; replaces three modules, `0024`). Any channel
trip opens the potential-free shutdown contact. A standalone 8-channel unit is the
same board partly fitted.

It is going onto real equipment. It is not a demonstration.

## Where it runs

Earlier eight-channel installation basis, corrected 2026-09-07. The 2026-09-29
24-channel clarification supersedes the system count; do not extrapolate the
old one-engine/one-probe-per-cylinder mapping to all 24 channels.

| | |
|---|---|
| The machine | Earlier basis: one eight-cylinder engine, no VFD. Common series shutdown for all 24 confirmed; physical sensor/engine mapping remains unconfirmed |
| The sensors | K-type; probably grounded-junction (owner, 2026-10-07), not verified. Earlier basis: cylinder bodies; exact model and 24-channel mapping unconfirmed |
| The unit | Same panel or nearby; K-type shielded twisted extension cable, roughly 50 m basis accepted (`0029`); exact cable/termination to be specified |
| Vibration and heat | Existing basis is a separate panel; moving acquisition onto/near the engine requires a fresh environmental assessment |
| The 24 V supply | Engine battery per accepted decision `0016`; surge qualification remains open (I-028/I-077) |

For the existing eight-channel same-engine basis, the shared isolated island
floats with the probe group and the barrier separates it from the controller.
That rationale must be rechecked if channel assignment spans different machines.

## What it must do

| # | Requirement | Status |
|---|---|---|
| R-1 | Read 24 K-type thermocouples, grounded, insulated or mixed | One board REV A3, 3x AD7124-8 (`0031`, `0032`): schematic and routed board exist, layout repairs open (`docs/ISSUES.md` P0); not built or tested |
| R-2 | Open the common potential-free dry-contact circuit when any channel exceeds its own setpoint | Trip relay G6K-2F-Y, both NO poles in series (`0032` rev 3); signal loads only, 30 VDC / 1 A (I-092); per-channel limits are 24-ch firmware (I-100); I-081 accepted limit |
| R-3 | Energised to run — power loss, reset or fault must stop the machine | Relay held only by a heartbeat from completed scans (I-118); single-fault limits in I-081 |
| R-4 | Show readings, channel limits and state locally | 20x4 LCD on standoffs on the board, five buttons plus a header for panel buttons (`0031` D4, `0034` D2); per-channel editing is firmware (I-100) |
| R-5 | Latch startup/reset/trip until manual ACK with valid, cool channels | Owner reconfirmed 2026-10-07 (`0029`, I-089 closed); per-channel reset checks pending I-100; I-073 fixed |
| R-6 | Detect a broken sensor (each channel checked about every 4 s) | **Open sensor trips by default**; "alarm only" is a deliberate, saved per-channel setting the display shows (owner 2026-10-09, `0034` D1; replaces `0031` D5's open default). Wire-to-wire or wire-to-sheath shorts can read plausibly on any two-wire front end; see `I-011` |
| R-7 | Survive an engine installation and 50 m cable runs | **not proven — needs measurement** |
| R-8 | Each channel has its own operator-settable persistent setpoint; values chosen at commissioning | Accepted 2026-10-07 (`0029`); the 24-ch firmware is not written yet; the 8-ch firmware has one shared limit (I-100) |
| R-9 | Communication with a PLC/SCADA master | Isolated RS-485 / Modbus RTU fitted on the board (`0031` D7, I-094); protocol not written; never in the trip path (I-086) |

## What it must not do

- Allow the machine to run when the unit itself has failed.
- Report a temperature it is not confident in.
- Depend on the isolation barrier for mains-level separation. It is not
  qualified for that.
- Treat potential-free contacts as unlimited ratings; they carry low-voltage signal loads only (30 VDC / 1 A).

## Response time

The trip must happen within **1 s** of the setpoint being crossed. The 24-ch
scan is ~0.62 s for 14 slots (I-119); contact timing is measured at the bench
(I-013, I-120). Communication is not in the shutdown path. Watchdog timing:
I-097, I-118.

## Explicitly out of scope for now

- Certification to IEC 61010 / IEC 61508.
- 4-20 mA or 0-10 V analogue output.
- Any IoT or cloud path. RS-485 to a local master only.

## Isolation and installation questions

All 24 thermocouples share one isolated island. That isolates the group from
the controller but **not the channels from each other**; accepted because all
24 are on one engine (owner, `0031`). A probe on another machine needs a fresh review.

Accepted, and the reasoning is now on record correctly in
`docs/decisions/0009-operating-environment-corrected.md`: the eight sensors sit
on one engine block, so channel-to-channel differences are small, and there is
no VFD injecting common-mode current into the frame. `0003` reached the same
answer from a wrong premise and is superseded; `0008` over-corrected from
another wrong premise.

Still to be confirmed before the unit is trusted:

- Measure the potential between the sensor sheaths and the panel ground with the
  engine running and while cranking (`I-004`).
- Verify the probable grounded junction against its actual model/continuity;
  ungrounded probes can also measure temperature (`0029`, I-026).

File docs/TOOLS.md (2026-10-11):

# Tools and commands

Only commands that have actually been run in this repository. If one stops
working, fix it here rather than working around it in a session.

---

## Installed

| Tool | Where | Used for |
|---|---|---|
| KiCad 10.0.6 (same as the cloud; updated 2026-09-26) | `C:\Program Files\KiCad\10.0` | everything hardware |
| KiCad Python (`pcbnew`) | `…\10.0\bin\python.exe` | the board generator and router scripts |
| `kicad-cli` | `…\10.0\bin\kicad-cli.exe` | ERC, DRC, netlist, BOM, Gerbers, 3D render |
| `kicad-tool` | `%USERPROFILE%\.local\bin` | schematic edits, schematic↔board sync. Install: `uv tool install git+https://github.com/mash/kicad-skills.git` - **never** `pip install kiutils`, that pulls upstream and breaks it |
| Freerouting 2.4.1 | `%LOCALAPPDATA%\kicad-tools\freerouting.jar` | autorouting via Specctra DSN/SES |
| Temurin JRE 25 | `%LOCALAPPDATA%\kicad-tools\jre25\*\bin\java.exe` | runs Freerouting |
| avr-gcc | see `firmware/build.ps1` | firmware |
| Konnect | `C:\Users\Public\AI-Tools\konnect\konnect.exe` (what `~/.claude.json` registers; `sch_layout/kon.py` needs it on PATH or in `KONNECT`) | the KiCad MCP - 226 tools; IPC when KiCad is open, S-expressions when it is closed |

Freerouting and the JRE are **not** in the repository. Override the paths with
`FREEROUTING_JAR` and `FREEROUTING_JAVA` if they move.

## Hardware — source-preserving validation

```powershell
pwsh -File hardware\8ch\run_all.ps1
```

This is now the default: copy the four KiCad source files into a fresh
`production/validation-*` directory, run ERC and the A0 netlist contract, then
refill and DRC the copy. The source hashes must remain unchanged. Errors,
unconnected pads and parity failures stop the run; warnings are reported.
KiCad ERC exit 5 can mean warnings, so its report is parsed before accepting it.

```powershell
pwsh -File hardware\8ch\test_gates.ps1  # injected native/report failures
```

## Hardware — regeneration

The explicit `run_all.ps1 -Regenerate` path checks every native exit and report,
and refuses while KiCad editors are open. **Authorized since the owner lifted
the REV A0 freeze on 2026-09-15** (`docs/decisions/0014`). It re-routes the
whole board, so everything after it has to be re-verified. The individual
commands, from `hardware/8ch/`:

```powershell
$py  = 'C:\Program Files\KiCad\10.0\bin\python.exe'
$cli = 'C:\Program Files\KiCad\10.0\bin\kicad-cli.exe'
$env:KICAD_CLI = $cli
$env:KICAD10_FOOTPRINT_DIR = 'C:\Program Files\KiCad\10.0\share\kicad\footprints'

python sch_layoutuild.py --in-place       # schematic: base 05d6abd + sch_layout/ (own ERC + netlist gate)
& $cli sch erc --output erc-report.rpt --severity-error --severity-warning thermocouple_8ch.kicad_sch
& $cli sch export netlist --output thermocouple_8ch.net thermocouple_8ch.kicad_sch
python apply_rules.py                        # net classes + .kicad_dru into the project
& $env:KICAD_TOOL pcb sync thermocouple_8ch.kicad_pcb thermocouple_8ch.kicad_sch
& $py generate_board.py                      # placement, planes, keepouts, PE ring, silkscreen
& $py route.py --passes 25 --threads 1       # DSN -> Freerouting -> SES -> stitching -> pours
& $cli pcb drc --output drc-report.rpt --severity-error --severity-warning --schematic-parity thermocouple_8ch.kicad_pcb
& $py close_gaps.py                          # joins whatever DRC still reports as open
& $py check_board.py                         # structural checks DRC cannot make
```

**Since the schematic is hierarchical (I-062), the order is different**, learned
on the REV A2 run (2026-09-28):

1. Schematic changes go into `sch_layout/` (a new part or a pin change in
   `reva2.py`-style code called from `fixes.py`, its position in `extra.py`,
   its block in `rootlayout.py`). Then run `build.py --in-place`.
   (`populate_schematic.py` was the flat-sheet tool; it is in `_old/` since
   2026-10-06.)
2. A deliberate connectivity change needs a new baseline. Write it only
   after `build.py`'s fingerprint lists exactly the differences you intended.
3. `kicad-tool pcb sync` needs `KICAD10_FOOTPRINT_DIR` set. Without it, every
   footprint comes back "unresolved" and new parts are not added.
4. `build.py` changes the sheet files, so `board_provenance.py --check`
   reports DRIFT. That is not hand work; run `--record`.
5. **Freerouting once stopped by itself after 2 s** ("Fanout stage
   interrupted", 151 unconnected), and `route.py` still exited 0. Re-running
   `generate_board.py` + `route.py` worked. Always read the unconnected count;
   DRC is the gate that catches it.

### After any generator run that ADDED parts

```powershell
python hardware\8ch\check_mpn_consistency.py          # --fix rewrites mismatches
```

`kicad-tool` creates a new symbol by cloning an existing one of the same type,
and the clone brings the donor's `MPN`/`Manufacturer`/`LCSC` with it. On
2026-09-16 that gave six new capacitors a **100 nF** part number and six new
resistors a **10 k** one. ERC passed, the netlist fingerprint passed - neither
looks at MPN. Run this whenever `build.py` adds symbols.
`I-054`.

## Firmware

```powershell
pwsh -File firmware\build.ps1     # -Wall -Wextra -Werror, plus host unit tests
```

## Visual check

```powershell
& $cli pcb render --output output\board_3d_top.png --width 1600 --height 1000 --side top --quality high thermocouple_8ch.kicad_pcb
```

## Gerbers — only when DRC is clean

Do not run this while `docs/ISSUES.md` still lists `I-001`.

A release goes to its own folder per revision under `production/`, not next to
the sources. The current one is `production/8ch-reva2/` (2026-09-28, with
`RELEASE.txt`, the upload zip and `validation-report/`). Superseded packages move to
`production/_OLD_DO_NOT_ORDER/` (REV A0, REV A1 - none was fabricated); stale
`validation-*` runs are deleted. `production/` is gitignored.

**Name the layers.** Without `--layers`, KiCad 10 plots every layer - Fab,
Courtyard, User.1-4 - and a fab may read them as copper or silk.

```powershell
$out = '..\..\production\8ch-reva2'
New-Item -ItemType Directory -Path $out | Out-Null     # fails if it exists: new revision, new folder
& $cli pcb export gerbers --check-zones --layers 'F.Cu,In1.Cu,In2.Cu,B.Cu,F.Mask,B.Mask,F.Paste,B.Paste,F.Silkscreen,B.Silkscreen,Edge.Cuts' --output "$out\" thermocouple_8ch.kicad_pcb
& $cli pcb export drill   --output "$out\" --format excellon --excellon-units mm --generate-map --map-format gerberx2 thermocouple_8ch.kicad_pcb
& $cli pcb export ipcd356 --output "$out\thermocouple_8ch.d356" thermocouple_8ch.kicad_pcb
& $cli pcb export pos     --output "$out\cpl.csv" --format csv --units mm --side both thermocouple_8ch.kicad_pcb
& $cli sch export bom     --output "$out/bom.csv" --fields 'Reference,Value,Footprint,MPN,Manufacturer,LCSC,${QUANTITY}' --group-by 'Value,MPN,LCSC' thermocouple_8ch.kicad_sch
```

The technician's kit (every through-hole part plus what is not on the board;
`0027`): `<KiCad python> hardware\8ch\kit_list.py <release>	echnician_kit.csv 3`.

Copy `docs/STATE.md`'s check numbers into the release folder as well. A
fabrication package without the report it passed is not a package.

## Schematic layout (`I-002`, `I-062`) - `hardware/8ch/sch_layout/`

**The schematic is six files, all A4, since 2026-09-26** (`0019`, `0021`):
`thermocouple_8ch.kicad_sch` (the root, an index of sheet blocks),
`power.kicad_sch`, `mcu.kicad_sch`, `isolation.kicad_sch`,
`relay_rs485.kicad_sch`, and `channel.kicad_sch` (used by TC1-TC8). Nets
that stay inside one sheet carry its path: `/TCn/FILT_P`, `/POWER/+24V_RAW`,
`/RELAY_RS485/GND_RS485`. A new one needs an `apply_rules.py` pattern
`/SHEET/NAME`, or it lands in Default and the isolation rule fires; board
scripts compare through `board/units.bare()`, which drops a functional-sheet
path. Print it: `kicad-cli sch export pdf --pages 1,2,3,4,5,6` gives the root,
the four functions and TC1 (TC2-TC8 are the same drawing). Compare netlists across a rename with
`netlist_fingerprint.py OLD NEW --allow-renames [map.json]` (nets matched by
pins), and carry a rename to the board with
`<KiCad python> sch_layout/rename_board_nets.py BOARD map.json` **before**
`kicad-tool pcb sync` - sync alone renames pads and leaves tracks behind.

```sh
python hardware/8ch/sch_layout/build.py              # scratch copy, prints the gate
python hardware/8ch/sch_layout/build.py --in-place   # rewrite the schematic
```

Measured 2026-09-24 in the cloud: about a minute; netlist IDENTICAL, ERC 0/0,
output equal to the committed sheet apart from UUIDs. With the `hier.py` step,
2026-09-26 on the workstation: 3 min, IDENTICAL, ERC 0/0 (put KiCad's `bin`
and the Konnect folder on PATH first). Every write goes through
Konnect over stdio (`kon.py`). Needs `konnect` and `kicad-cli` on PATH and
`KICAD10_SYMBOL_DIR` set (the cloud hook does all three; on the workstation set
it to `C:\Program Files\KiCad\10.0\share\kicad\symbols`).

| File | Holds |
|---|---|
| `build.py` | entry point and the gate |
| `fixes.py` | netlist corrections carried by the drawing (`I-058`, `I-057`) |
| `channel.py`, `chmap.py` | the channel template and which parts are which channel |
| `extra.py` | placement of every other block, in 1.27 mm grid units |
| `relayout.py` | move/rotate a part and carry its pin labels and NC flags |
| `route.py` | wires: never through another net's pin, wire, pin lead or a body |
| `labels.py` | one label per wired group, placed where its text is clear |
| `hier.py` | flat wired sheet -> A4 root + `channel.kicad_sch` x 8 + the functional sheets (`0019`, `0021`) |
| `rootlayout.py` | which functional block each root item belongs to |
| `funcsheets.py` | moves each block onto its A4 sheet (POWER, MCU, ISOLATION, RELAY_RS485; `0021`) |
| `sexpr.py` | minimal KiCad S-expression reader/writer (no kiutils) |
| `rename_board_nets.py` | renames board nets in place from a rename map |

**It starts from a label-only base** (`05d6abd`) and refuses one with wires.
Change a part's position in `extra.py`/`channel.py`, re-run, look at the
render (`kicad-cli sch export svg`), repeat. A netlist difference means the
layout moved connectivity - fix the script, never the baseline.

## Which mode am I in, and may I write?

Two ways to change the hardware, and a guard that tells them apart -
`AGENTS.md` rules 8 and 9, `docs/decisions/0012`.

```powershell
python hardware\8ch\board_provenance.py --status   # report, never fails
python hardware\8ch\board_provenance.py --check    # exit 1 if writing would lose work
python hardware\8ch\board_provenance.py --record   # after a generator run
```

`--check` fails for two reasons, and the message says which:

- **KiCad holds the project open** (`~*.lck` next to the board). Ask the user
  to close it. **Do not close KiCad yourself** - it may hold unsaved work,
  which is exactly how the board was lost on 2026-09-07.
- **The files have drifted** from the last generator run, so hand edits exist
  and regenerating would destroy them. Either fold them back into `board/`, or
  abandon them deliberately and `--record` again.

## One KiCad MCP, and what else there is

`Konnect` is the only KiCad MCP wired up. The Seeed server was
retired 2026-09-14 - `docs/decisions/0013`. Which layer does what:

| Layer | Tool | When |
|---|---|---|
| Live editing and queries | **Konnect** | KiCad open **or** closed |
| Offline deep analysis | `kicad` skill analysers | feeds `emc`; produces `net_lengths`, `ground_domains`, `layer_transitions` |
| File read/write CLI | `kicad-tool` skill | scripted edits, the generative pipeline |
| **This board's own rules** | `check_board.py`, `netlist_fingerprint.py`, `board_provenance.py`, `check_mpn_consistency.py`, `validate.ps1`, `test_gates.ps1` | **nothing generic can replace these** |

The last row is the point. Island membership, the isolation barrier, the
cold-junction distance, the 167/154/555 netlist contract, whether a generator
run would destroy hand edits - these are this project's rules. No MCP knows
them and none ever will.

## The KiCad IPC API - measured on this machine, 2026-09-13

KiCad's official API is protobuf over an NNG socket. Measured by reading the
installed binaries, not the docs:

| | Finding | Where |
|---|---|---|
| Server present | `kiapi.dll`, `nng.dll` | `KiCad/10.0/bin/` |
| **Server enabled** | **`"enable_server": false`** | `%APPDATA%/kicad/10.0/kicad_common.json` |
| Client library | `kipy` **not installed** | `pip install kicad-python` |
| Version | 10.0.3 | `kicad-cli version` |
| Schematic handler | **`API_HANDLER_SCH` present** | `_eeschema.dll` |
| Board handler | `API_HANDLER_PCB` present | `_pcbnew.dll` |
| Document types | `DOCTYPE_SCHEMATIC`, `DOCTYPE_PCB`, `DOCTYPE_SYMBOL`, `DOCTYPE_FOOTPRINT` | `kiapi.dll` |
| Schematic objects | 22 `KOT_SCH_*` including **`SYMBOL`, `PIN`, `LINE`, `JUNCTION`, `LABEL`, `NO_CONNECT`** | `kiapi.dll` |
| Edit commands | `GetItems`, `CreateItems`, `UpdateItems`, `DeleteItems`, `ParseAndCreateItemsFromString`, `HitTest`, `GetBoundingBox` | `kiapi.common.commands` |
| Transactions | **`BeginCommit` / `EndCommit`** - edits land in KiCad's undo stack | `kiapi.common.commands` |
| Plot / export | **zero commands** | grep found none |
| Run DRC / ERC | **none** - only `InjectDrcError`, for reporting *into* KiCad | `kiapi.board.commands` |

So the shape of it: **IPC can edit, and cannot verify.** `kicad-cli` and our
scripts stay the verification path either way.

**Correction to an earlier claim in this file.** It used to say the IPC API
"needs KiCad open, making the two-writer hazard permanent". That is backwards.
Editing *through* KiCad's API means KiCad is the only process writing the file,
and the edit joins its undo stack - which is **safer** than writing the file
under an open editor, which is precisely the 2026-09-07 failure. The real
Windows hazard is different and specific: a client that cannot find the socket
may **fall back to editing the file directly** while KiCad has it open. On
Windows, NNG `ipc://` is a named pipe under `\.\pipe\`, not a file, so
socket auto-detection fails on a default install. Set `KICAD_API_SOCKET`
explicitly before letting any IPC client write, and confirm it is live with a
read call first.

The "cannot plot or export before KiCad 11" half of that claim was correct and
is confirmed by the table above.

## Reading a datasheet

`pdftotext` ships with Git for Windows - no separate poppler install needed.

```powershell
& "C:\Program Files\Git\mingw64in\pdftotext.exe" -f 12 -l 14 docs
eference\datasheets\ATmega32A.pdf -
```

It is on the Bash tool's PATH as plain `pdftotext`, and on PowerShell's only by
full path. `-f`/`-l` bound the page range; a 400-page datasheet dumped whole is
unreadable. Version here is 4.00 (Xpdf build), verified 2026-09-13.

## EMC and SPICE

The `emc` skill consumes the `kicad` skill's analyser JSON, so run those first:

```powershell
python $env:USERPROFILE\.claude\skills\kicad\scriptsnalyze_schematic.py thermocouple_8ch.kicad_sch --analysis-dir ..\..\docs
eferencenalysispython $env:USERPROFILE\.claude\skills\kicad\scriptsnalyze_pcb.py thermocouple_8ch.kicad_pcb --full --analysis-dir ..\..\docs
eferencenalysispython $env:USERPROFILE\.claude\skills\emc\scriptsnalyze_emc.py --analysis-dir docs
eferencenalysis\ --text
```

Set `PYTHONIOENCODING=utf-8` first or the text report dies on an arrow
character under cp1252. `docs/reference/analysis/` is gitignored.

First run: 2026-09-13, 122 findings, triaged into `I-045` - most of the volume
is one heuristic firing per net. **The `spice` skill cannot run here:** it
needs ngspice, LTspice or Xyce on PATH and none of the three is installed.
KiCad's built-in ngspice is a library inside the GUI, not a CLI, so it does not
satisfy the skill.

## Cloud sessions (Claude Code on the web)

`.claude/hooks/session-start.sh`, registered as a `SessionStart` hook in
`.claude/settings.json`. It runs only when `CLAUDE_CODE_REMOTE=true`; on this
workstation it exits at once. It installs avr-gcc, KiCad 10 `kicad-cli` (KiCad
PPA), `pwsh`, `uv` + `kicad-tool`, and Konnect 0.11.1 (prebuilt Linux release -
keep the version equal to `konnect.exe --version` here), then registers Konnect
at **local** scope in the container. `.mcp.json` stays empty. No
`KICAD_API_SOCKET` is needed there: no KiCad GUI, so Konnect edits files directly.
First session takes a few minutes; its last lines list any tool that is
**MISSING**, with a log path. Tested 2026-09-24 in WSL Ubuntu without root:
pwsh, uv, kicad-tool and Konnect installed; the apt steps need root, which the
cloud container has.

**Measured in the real cloud container, 2026-09-24** - WSL did not show this:
the proxy returns **403 for `ppa.launchpadcontent.net` and `astral.sh`**, and
`add-apt-repository` fails (no `apt_pkg`). Worse, `apt-get install kicad` then
succeeds from Ubuntu's own archive with **KiCad 7.0.11**, which cannot open
these files, and the summary said *all tools present*. The hook now accepts
only a `kicad-cli` reporting `10.x`, and falls back to KiCad's image
`ghcr.io/kicad/kicad:10.0` (10.0.6; `docker.io` answers 429) behind a
`kicad-cli` wrapper in `~/.local/bin`, plus the stock library tables in
`~/.config/kicad/10.0`. `uv` falls back to PyPI. GitHub release downloads
(pwsh, Konnect) work. Result: every tool present, Konnect connected, second
run 16 s. The same image carries KiCad's `pcbnew` Python and `ngspice`, so
`-Regenerate` is closer than the table below says - Freerouting and a JRE are
what is still missing.

| Workstation | Cloud equivalent |
|---|---|
| `pwsh -File firmware\build.ps1` | `make -C firmware all test` (build.ps1 needs MSVC) |
| `pwsh -File hardware\8ch\run_all.ps1` | `pwsh -File hardware/8ch/validate.ps1` |
| `run_all.ps1 -Regenerate` | by hand, measured 2026-09-24: Temurin JRE 25 (`github.com/adoptium/temurin25-binaries`) and `freerouting-2.4.1.jar` (`github.com/freerouting/freerouting` releases) into `~/.local/opt`; KiCad's footprints copied out of the image; then `apply_rules.py`, `kicad-tool pcb sync`, and `generate_board.py` / `route.py` / `close_gaps.py` run with the image's `python3` (`docker run --user root` with `/tmp`, `/home`, `~/.local` mounted, `FREEROUTING_JAR`, `FREEROUTING_JAVA`, `JAVA_TOOL_OPTIONS=` cleared). Routing takes ~12 min. |

**Cloud work lives only in the container until it is pushed.** Commit and push
to a `claude/*` branch before the session ends; `git push` is in `ask`, not
`deny`, so the owner approves each push.

## Konnect - editing through a running KiCad

`docs/decisions/0013`. A single binary at `D:	ools\konnect\konnect.exe`,
registered at **user scope** - `~/.claude.json` for Claude Code,
`~/.codex/config.toml` for Codex - so both find it in every project. The
project's `.mcp.json` declares **no** servers: naming it in both places is a
collision, and on 2026-09-14 it produced `CONNECTION_CLOSED` against a server
that was provably healthy (starts in 0.01 s, survives idle, answers
`initialize`). 226 tools in 21 toolsets, loaded on demand:
`list_toolboxes`, then `load_toolset` for `sch_wiring`, `sch_analysis`,
`sch_batch`, `sch_export`, `sch_components`. `unload_toolset` keeps context
small.

**Three preconditions, in order. Check them; do not assume them.**

1. KiCad's API server is on - `kicad_common.json` -> `api.enable_server: true`.
2. **The editor you need is open**, not just the project manager. The handlers
   live in `_eeschema.dll` and `_pcbnew.dll`; with only `kicad.exe` running you
   get `AS_UNHANDLED` on every request.
3. `KICAD_API_SOCKET` is set. It lives in the user-scope registration and is
   **not optional on Windows**: NNG makes an `ipc://` endpoint a named pipe,
   not a file, so auto-detection fails and a client can decide KiCad is not
   running and start editing the file underneath it. `.mcp.json` carries the
   same warning for anyone setting the project up elsewhere.

Confirm with `open_project`, which reports `ipc_available` and
`kicad_ui_running`, **before** any write.

Useful, verified on this schematic 2026-09-13:

```
get_pin_connections {schematic, reference, pin_number}   net + absolute x/y
export_netlist_summary {schematic}                       every pin, one call
list_schematic_wires {schematic}                          -> count: 0  (I-002)
connect_pins / batch_connect_pins                        wire by ref+pin
run_erc, generate_netlist, export_schematic_svg          the checks
set_visual_baseline / compare_visual_baseline            visual regression
```

The argument is `schematic`, not `path` - the error message names the field it
wanted, so read it rather than guessing.

**Opening KiCad creates `~*.lck` and `board_provenance.py --check` will refuse
while it is there. That is correct.** Do not close KiCad to get past it
(`AGENTS.md` rule 8).

**Konnect is not installed into `~/.claude`.** `konnect init` would add 6
skills, 2 agents and 4 hooks to the global config; only the MCP server is wired
up here. The hooks guard the IPC-versus-file-fallback case and are worth
revisiting.

## 24-channel board (`hardware/24ch/`) - pipeline and the order of work

Lessons from 2026-10-08, when routing took a whole day it should not have.
Read `hardware/24ch/README.md` for the commands; this is the *order* and why.

**Two phases. Know which one you are in.**

1. **Generative, until placement is frozen.** `gen/build.py` (schematic),
   `kicad-tool pcb sync`, `gen/place.py`, `gen/rules.py --route-prep`,
   `gen/fanout.py`. Each run rebuilds from the generator and wipes every hand
   edit. Any move of a part invalidates all tracks, so routing restarts from
   `output/fanned.kicad_pcb`. Do placement experiments here, not after routing.
2. **Incremental, once a routing result is kept.** Never run `place.py` again.
   Freerouting reads the tracks already on the board and routes only what is
   missing, so a second run *continues* (`route24.py --board <kept copy>`);
   lock the good tracks first so it does not rip them up. The last few
   connections in congested spots are finished by direct edits:
   **Konnect (`pcb_routing`, `pcb_export`) through a running KiCad first**,
   or a person in KiCad with the interactive router (push-and-shove) - an
   engineer closes 50-80 short connections in a few hours. Computer-use on the
   KiCad window is the last resort, after Konnect was tried.

**Before any long Freerouting run (each pass is 2-8 minutes):**

**Interactive finishing and locks (2026-10-09):** the handed-off board had
3,336 locked tracks/vias and 558 unlocked. KiCad's Shove router cannot move
locked surrounding copper. Locking a kept route is useful when protecting it
from an autorouter, but is not a permanent finishing setting: before a local
Shove operation, select and unlock the necessary neighbouring tracks/vias,
leave footprints and unrelated copper protected, then save and re-run DRC.
Do not interpret a blocked escape as proof that the board needs re-placement.

- Run `gen/padcheck.py`. Freerouting sees the DSN clearance (net class + the
  `--pad` margin). If that is larger than the gap between two pads *of the same
  part*, every such pad is "already a violation" and Freerouting never connects
  it. On 2026-10-08 the AD7124 LFCSP (0.25 mm between pads) against 0.20 +
  0.06 mm, and the relays (1.4 mm) against a 2.0 mm Contact class, left ~85
  connections that no number of passes could route. Fix: class clearance below
  the tightest in-part gap (Island/Default 0.15 mm, Contact 1.0 mm); the big
  clearances *to other classes* (3 mm island, 2 mm contacts) belong in
  `.kicad_dru` pair rules, and `route24.py --contact-rule` passes the contact
  one to the router as a `class_class` rule.
- Watch the unrouted count per pass in `output/freerouting*.log`. If it stops
  falling for ~5 passes, stop and find the cause; more passes, more threads or
  a longer run will not fix a rule or placement problem.
- Result of the 2026-10-09 variants (same board, 30 passes, KiCad DRC after import):
  router margin 25 um -> 395-488 clearance errors (Freerouting rounds below 0.15 mm);
  40 um plus the contact/chassis pair rules -> 10 errors, 25 unconnected. Those are
  now `route24.py` defaults. The router's own "unrouted" count (69) includes plane
  nets; only KiCad DRC's unconnected count matters.
- Prefer 2-3 variants in parallel (`--board output/var_x.kicad_pcb --tag x`,
  each with its own `var_x.kicad_pro` copy) over one long run.
- Long router runs cost no model usage. If you must stop (usage limit, owner
  away), **start the long run in the background first**, then stop.

**Finishing the last connections (2026-10-09), in this order:**
1. `gen/finish.py drc` then `finish.py stubs` (pad-to-via stubs the router dropped).
2. `route24.py --tag x --passes 2` on a **locked** board (`finish.py lock`): a short
   fill. Longer locked or unlocked runs did not help - Freerouting counted ~209
   "unrouted" against KiCad's 13 and gained one per 5-10 min pass.
3. `gen/maze.py` - a grid maze router (0.05 mm) with the real clearances (0.21 to
   pads/vias/power, 0.16 signal-to-signal, 2 mm contacts, 1.5 mm chassis), domain and
   barrier masks, via-to-plane endings for plane nets. `--skip NET` leaves a net for
   hand routing (it would have drawn a 40 mm decoupling loop).
4. `maze.py --ripup` -> `finish.py rip` -> `maze.py`: rips the few signal tracks in the
   way; the rip-up's target nets route first, else the ripped nets retake the corridor.
* Codex in the desktop app, asked to use KiCad's interactive router, wrote a script per
  connection on board copies instead: 4 of 7 correct, but >50 % of the owner's weekly
  limit. Prefer `maze.py`; give an agent the GUI only with a hard budget.

* **Driving the KiCad GUI (2026-10-09).** The computer-use MCP returned an all-dark screenshot on this
  machine every time, while a GDI capture worked: `gen/kicad_ui.ps1` (cap / crop / click / keys, DPI-aware,
  Windows scaling 125 % -> clicks are in the 1536x864 screenshot frame). Calibrate board mm to screen from
  the status bar `X Y`. Only with the owner away from the keyboard: keys go to the foreground window, and
  in pcbnew plain letters are hotkeys (a stray Ctrl+A selected 5683 items). The interactive router (X, Shove)
  could not leave a pad boxed in by another net's track - fix the blocker first.
* **One writer, also for scratch copies.** After a session restart an orphaned background loop kept writing
  `output/work.kicad_pcb` while a new one started - both runs were wasted. `tasklist | grep python` first.
* **When a general tool fails twice on one connection, stop and route it by hand coordinates**
  (`finish.py add NET LAYER W x1,y1 x2,y2 ... [via]`) after reading the blockers (`near.py`-style listing of
  tracks in a box). Rip-up loops around a dense LFCSP cascaded instead of converging.

**Looking at the board yourself:** `kicad-cli pcb export pdf` (or `sch export
pdf`) and render pages with PyMuPDF (`pip install pymupdf` into
`C:\Users\malgh\AppData\Local\Programs\Python\Python310`); `kicad-tool ...
render-region` needs `rsvg-convert`, which is not installed. Konnect's
`pcb_export` also writes SVG/PNG. Ask the owner for photos only of what is not
in the files (the LCD module bought locally, the enclosure, the panel).

**Schematic pages are A4 or A3 only** (owner, 2026-10-08): `build.py`
splits sheets and refuses anything bigger.

**Finishing the 24-ch board (2026-10-09)** - `gen/finish.py nori` pushes tracks off pads to the NORI
0.2 mm (re-run until DRC is clean; tracks pinned at both ends by hand), `finish.py dangling` deletes
router stubs, each checked by a DRC run on a copy (pcbnew cannot load a second board after a Remove:
board edits run in a child process). `maze.py` with `THERMO24_MAZE_IN2=1` may use In2.Cu. A work copy in
`output/` needs its own `.kicad_pro`/`.kicad_dru` next to it, or DRC uses default 0.2 mm classes.
`gen/silk.py` places labels by obstacle search (pads, Fab body outlines, other text; KiCad text boxes
include line spacing - use the glyph box); board min text height 0.8 mm. `gen/fab.py` runs DRC with
`--refill-zones --save-board` so the Gerbers carry the pours DRC checked (scripts save boards unfilled).
Render check: `kicad-cli pcb render --side top`.

- **24-ch gates (I-115):** `gen/build.py` and `gen/fab.py` exit non-zero if kicad-cli fails or writes no fresh report (exit 5 = violations, also a fail); `gen/guard.py` (`check`, `claim`, `sha256`) refuses while KiCad holds a `~*.lck` or another tool holds `output/.writer.json`; `fab.py` writes a new `production/24ch-reva3-<time>-<sha6>/` from a snapshot copy (source never saved) with `MANIFEST.txt` and `ORDER-NOTES.txt`. Test on copies: `THERMO24_SCH_OUT` (build.py), `THERMO24_FAB_PCB` / `THERMO24_FAB_SCH` / `THERMO24_FAB_OUT` (fab.py), `THERMO24_WRITER_CLAIM`.

**Local repairs on the 24-ch board (2026-10-11, `0035`):** `gen/capnear.py U403 1 C407 [--soft-vias]
[--avoid "TC*"] [--apply [--rip]]` finds a spot within N mm of a pin and scores what is in the way;
`capnear.py via REF PAD [mm]` puts a plane via beside a pad (never in it, never in a band); `move.py` moves
named parts and drops only their own-net tracks; then `finish.py dangling`, `finish.py dedupe`, `maze.py`,
`pincaps.py`. A rip-up near the AD7124 went badly (maze made DOUT_ISO 168 mm): there, route by hand
(`finish.py add`) after listing **all layers** in the box, B.Cu included.
* pcbnew python: `via.GetWidth()` without a layer raises a modal assert dialog that hangs the script -
  use `GetWidth(pcbnew.F_Cu)`. After `board.Remove(zone)` the zone list is stale: read first, remove last.
* Delete tracks "touching a pad" by the pad's **own net** only - another net's segment can end under a pad.
* Paths with backslashes written through a bash heredoc can turn ``/`` into control characters; check
  with `python -m py_compile` and a grep for control characters.

## Things that will bite you

- **A gate that reads a file can pass on the wrong file.** Two did on
  2026-09-26: `close_gaps.py` read a `drc-report.rpt` from 2026-09-07 and said
  "no missing connections" on a board with one (it now runs its own DRC with
  `--refill-zones` and refuses an older report), and `check_mpn_consistency.py`
  read only the root after `I-062` - 56 symbols checked instead of 128, still
  "all match" (it now follows every `Sheetfile`). When a check's count drops,
  suspect the check.
- **`populate_schematic.py` (now in `_old/`) refused the hierarchical root**
  (`I-062`); `sch_layout/build.py` replaced it.

- **`PCB_VIA::GetWidth()` needs a layer argument** in KiCad 10. The no-argument
  form trips a wxWidgets assert that opens a modal dialog and hangs a headless
  run. `generate_board.py` disables wx asserts for this reason.
- **KiCad's SWIG bindings degrade after any `board.Remove()`** — every container
  accessor then returns bare pointers, for the rest of the process. Clearing is
  done in a child process (`generate_board.py --clear-only`).
- **Freerouting's multi-threaded optimiser is broken** by its own warning and
  generates clearance violations. Always `--threads 1` for a run you keep
  (on 2026-10-08 a single-thread 24-ch pass took 8 min against 2.5 min on 4
  threads; 4-thread runs are for comparing variants, and their result must pass
  KiCad DRC before it is kept).
- **Killing `route24.py` does not stop Freerouting.** The Java process keeps
  running (`taskkill /F /IM java.exe`), and Freerouting writes its `.ses` only
  at the end - a cancelled run leaves nothing to import.
- **Codex 0.162 alpha cannot run any command with the elevated Windows sandbox**
  (`helper_unknown_error: setup refresh had errors`; it then reviews blind). Run
  `codex exec -c 'windows.sandbox="unelevated"' -s read-only -o report.md - < brief.txt`.
- **`kicad-tool` on Windows needs `KICAD_CLI`** (its default is the macOS path;
  the error is a bare `[WinError 2]`) and `KICAD10_FOOTPRINT_DIR` for `pcb sync`.
- **Freerouting rounds clearances down** (0.2454 mm against a 0.25 mm rule), so
  `route.py` pads the values it writes into the DSN.
- **KiCad exports every copper layer as `(type signal)`.** `route.py` rewrites
  In1/In2 to `(type power)` so signals stay on the outer layers.
- **`kicad-tool` regenerates UUIDs on every write**, so a label UUID from an
  earlier query is stale after the first delete. Re-query each round.
- **Heredocs in this environment mangle backslashes.** Write patch scripts to a
  file instead of piping them inline.

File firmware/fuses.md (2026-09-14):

# Fuse map — ATmega32A, THERMO-8CH REV A0

**A unit whose fuses have not been read back and recorded is not a unit that
has been commissioned.** Programming the flash is half the job; the fuses
decide the clock, the brown-out threshold and which pins exist.

Issues: `I-015`, `I-032`, `I-016`.

---

## The values

| Fuse | Factory default | **Required** |
|---|---|---|
| Low | `0xE1` | **`0x3F`** |
| High | `0x99` | **`0xD1`** |
| Lock | `0xFF` | `0xFF` for prototypes — see below |

Program them with `firmware/program.ps1`, which reads them back and fails if
they do not match.

---

## Low fuse `0x3F` = `0b0011_1111`

| Bit | Name | Value | Meaning |
|---|---|---|---|
| 7 | BODLEVEL | 0 | brown-out trigger level **4.0 V** |
| 6 | BODEN | 0 | brown-out detector **enabled** |
| 5 | SUT1 | 1 | start-up 16K CK + 65 ms |
| 4 | SUT0 | 1 | (crystal, slowly rising power) |
| 3–0 | CKSEL3..0 | 1111 | **crystal oscillator, 3–8 MHz** (`Y1`) |

### CKSEL is the one that will bite you

The factory default is `CKSEL = 0001` — internal RC at **1 MHz**. The firmware
is built with `F_CPU=8000000UL`.

On a fresh chip that has not had its fuses set, every `_delay_ms()` runs **eight
times longer** than the code intends. The 456 ms sensor scan becomes about
3.6 s, and the 1 s trip requirement in `docs/GOAL.md` is missed by roughly four
times.

Nothing reports this. The image is correct, the build is clean, the LCD updates,
the temperatures are right. The unit simply takes four seconds to open a contact
it was specified to open in one. This is `I-032`.

### Brown-out at 4.0 V, not 2.7 V

`docs/ISSUES.md` `I-015` says the right level is 2.7 V "at 3.3 V". That was
wrong, and it is corrected here.

`U1` runs from **`+5V_CTRL`**, not 3.3 V. The 3.3 V rail (`+3V3_SENS`) feeds the
eight MAX31856 converters, and they are on the far side of the isolation
barrier. On a 5 V rail the correct trigger is **4.0 V**: it resets the part
before the supply sags into the region where instruction execution is undefined
and arbitrary code could raise `RUN_PERMIT`.

With BOD disabled — the factory default — a slow supply sag is exactly the
condition under which this unit would permit an engine to run while executing
garbage.

---

## High fuse `0xD1` = `0b1101_0001`

| Bit | Name | Value | Meaning |
|---|---|---|---|
| 7 | OCDEN | 1 | on-chip debug disabled |
| 6 | JTAGEN | 1 | **JTAG disabled** |
| 5 | SPIEN | 0 | serial programming enabled — required for ISP |
| 4 | CKOPT | 1 | low-power oscillator, correct for the internal RC |
| 3 | EESAVE | 0 | **EEPROM preserved through a chip erase** |
| 2 | BOOTSZ1 | 0 | boot size 1024 words (unused) |
| 1 | BOOTSZ0 | 0 | |
| 0 | BOOTRST | 1 | reset vector at 0x0000 |

### JTAG is enabled by default and it takes four pins

`JTAGEN` is programmed (enabled) on a factory chip, and JTAG occupies **PC2,
PC3, PC4 and PC5** — `SPARE_PC2`..`SPARE_PC5` in the schematic.

Any future use of those pins reads a constant value until `JTAGEN` is
unprogrammed. The first one planned is the run-permit driver read-back on PC2
(`I-016`, part of the REV A1 change set in `docs/decisions/0010`).

### EESAVE protects the setpoint

The operator setpoint lives in EEPROM (`src/hal/settings_store.c`, `I-012`).

With `EESAVE` programmed (`0`, as specified here) a chip erase leaves it alone,
so reprogramming a unit in the field keeps its setpoint.

With `EESAVE` unprogrammed — the factory default — reprogramming **erases the
setpoint**. The unit then comes back config-locked: it shows `SET SETPOINT` and
refuses to permit running until an operator stores one. That is the safe
behaviour and it is deliberate, but the site has to be told why, or it looks
like the unit failed.

---

## Lock bits

Leave at `0xFF` while prototyping, so the fuses and the flash can still be read
back for diagnosis.

For production units, consider `0xFC` (LB1, LB2 programmed — further programming
and verification disabled). The trade-off: it prevents reading the image back
from a unit that has come off a machine, which is usually the first thing you
want when something has gone wrong in the field. Do not set it until the design
is settled.

---

## Verification

```powershell
avrdude -c usbasp -p m32 -U lfuse:r:-:h -U hfuse:r:-:h -U lock:r:-:h
```

Expect `0x3F`, `0xD1`, `0xff`. `program.ps1` does this automatically and exits
non-zero on a mismatch, but a commissioning record should carry the values read
back from that specific unit, together with the firmware version shown on the
LCD at boot (`APP_FIRMWARE_VERSION` in `include/app/version.h`).

---

## These values assume the crystal is fitted

`Y1` (8 MHz) with `C60`/`C61` 22 pF load capacitors drives `U1` pins 12 and 13,
added to the schematic on 2026-09-15 as part of REV A1 (`docs/decisions/0010`,
`I-032`). The low fuse moved from `0x24` to `0x3F` in the same change.

**A chip fused `0x3F` on a board with no crystal will not run at all** — it
waits for an oscillator that never starts, and looks bricked. Recovery needs a
high-voltage programmer or an external clock injected on XTAL1. If you are
programming a board without `Y1` fitted, use `-LowFuse 0x24` and set
`BOARD_HAS_RUN_PERMIT_SENSE` back to `0`.

The high fuse does not change. With the crystal, `R-9` (Modbus RTU) is no
longer gated on oscillator accuracy — see `docs/decisions/0010` consequences.

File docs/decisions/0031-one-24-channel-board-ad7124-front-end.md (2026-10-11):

# 0031 — One 24-channel board, AD7124-8 front end, single-source parts

* Status: accepted (owner, 2026-10-08). Engineering items marked "design" or
  "verify" are still open.
* Date: 2026-10-08
* Deciders: owner; front end reviewed adversarially by Codex gpt-6.1-sol
  (read-only, `production/review-20261008/codex-frontend-review.md`, local)
* Supersedes: `0030` D1, D1a, D3, D4, D4a, D6, D7 and its W3 work item.
  `0030` D2 (comms never in the trip path), D5 (signal relay) and D8 (per-channel
  setpoints, timing) still apply. Partly supersedes `0024` (three modules).
* Relates to: I-101, I-102, I-091, I-092, I-093, I-094, I-095, I-096, I-097,
  I-078, I-081, I-085, I-090, I-100; `0020`, `0028`, `0029`

## Why the plan changed the same day

`0030` kept 8x MAX31856 per module. The probes are made to order and their
junction type is unknown and may be mixed (I-101). With grounded probes the
engine joins every T- line, and the MAX31856 BIAS outputs then fight (ADI
guidance: T- of several MAX3185x must not be joined; `CALCULATIONS` 6.1).
Commercial instruments that accept both probe types connect **one probe at a
time to one converter** (Murphy TDXM, 24 channels; NI 9213, 16 channels with
high-value bias to COM; `reference/benchmarks/murphy-tdxm/`).

Once the front end is a multiplexed converter, two of the reasons `0030` gave
for rejecting one 24-channel board disappear: there are no 24 BIAS sources on
one island, and the channel design is new on either path.

## Decisions

**D1. One 24-channel board** (owner, 2026-10-08), replacing three stacked
modules. One MCU, one power stage, one trip relay, one display and keypad. No
inter-module RS-485, master role, stack header, ACK fan-out diodes or address
jumpers. A standalone 8-channel unit is the same PCB with one acquisition bank
fitted, its channel count fixed at the factory and locked; a missing required
channel trips.
* Accepted cost (Codex Q6): a welded trip contact or an undetected MCU fault
  now affects all 24 channels instead of 8 (I-081 scope grows). A second relay
  in series can be added later if the owner wants it.

**D2. Front end: 3x AD7124-8 on one isolated island, scanning concurrently.**
Each converts 8 differential channels through its internal mux (16 AIN pins,
all used). One AD7124 for 24 channels would take 24 x 41.8 ms = 1.0 s before
diagnostics, so it is rejected (Codex Q6b). Rejected: per-channel isolation
(8 converters + 8 isolated supplies per bank; Codex Q5), LTC2983 (167 ms per
channel), ADS124S08 (6 pairs, narrower input window at gain 32; Codex Q5).
Required changes from the review, to be designed before the schematic:
* **Common-mode reference:** each TC- biased through a high value (order of
  10-39 Mohm) **plus one protected reference wire** from the island to the
  engine at mid-rail, not AVSS. Every mix of probes must work, including all
  insulated, and losing the reference wire or the last grounded probe must not
  read plausibly. The leakage budget (~38 nA for 1.5 V at 39 Mohm) includes
  protection, board and connector leakage. Common-mode recovery after burnout
  (39 Mohm x 20 nF = 0.78 s) limits the filter capacitors.
* **Input protection redesigned:** the REV A2 BAV199 rail clamp allows ~4.2 V
  against the AD7124's AVDD + 0.3 V = 3.6 V absolute maximum.
* **Cold junction:** a sensor next to each terminal group, not the ADC die
  sensor (CN-0391 uses local RTDs). K-type NIST functions in firmware, done in
  voltage, not by adding temperatures.
* **Diagnostics every scan:** SPI CRC and register read-back, device ID and
  silicon revision, channel tag and fresh-data checks, error register, MCLK
  counter, zero and non-zero checks through the gain used, and a reference
  check against an **independent** quantity (a reference-derived ladder cannot
  see reference drift; a 2 % rise reads ~10 °C low).
* **Timing:** 25 SPS single-cycle settling is ~42-43 ms per switched channel
  (Rev B Table 61), so 8 TC + 2 checks is ~0.47 s per bank, the three banks in
  parallel. Burnout is tested on **one channel per scan in rotation**, so each
  channel is checked about every 4 s (owner: acceptable, 2026-10-08). Burnout
  readings are never used as temperatures. The firmware loop must service the
  ADCs faster than the 50 ms loop delay, and the watchdog follows I-097.
* **Known limit:** a wire-to-wire or wire-to-sheath short can read plausibly
  on any two-wire thermocouple front end, including per-channel isolation.
  R-6 is amended to say so.

**D3. Processor: ATmega32A class is enough** (Codex Q6c: 24 conversions per
scan ~30 ms estimated; present image 5918 B flash, 437 B static RAM). Prefer a
pin-compatible ATmega644PA or ATmega1284P (same code, 2-8x memory) **if** stock
and footprint check out at the single source (D6). Murphy's board uses a
44-pin Microchip 8-bit MCU for 24 channels (inferred from photo-2).

**D4. Operator interface on the board** (owner, 2026-10-08). The panel door
is not modified.
* **20x4 character LCD** (HD44780-compatible, 16-pin header) on standoffs above
  the board; no tall parts under it. **Bought locally in Egypt** (owner,
  2026-10-08): LCSC had no 20x4 in stock (HS204A C5329590: 3 pcs). It plugs into
  a header and is screwed on, so it is not part of the factory assembly. This is
  the one agreed exception to D6. Rejected: 128x64 ST7920 from LCSC (8 lines, but
  needs a framebuffer and more firmware).
* **Five buttons beside the LCD:** UP, DOWN, SET (enter/save), ESC, and a
  larger or differently coloured **ACK**.
* Still to ask the operations engineer: is opening the door to read the
  display and press ACK acceptable?

**D5. Outputs.** One **trip** relay (energised-to-run, `0030` D5) and one
**alarm** relay of the same signal type (owner, 2026-10-08), for warnings that
must not stop the engine: open thermocouple, approaching limit. Whether an
open thermocouple trips or only alarms is a firmware setting; its default is
still to be chosen (owner said alarm-only is acceptable). **Superseded by `0034` D1:
an open thermocouple trips by default.** Both contacts:
30 VDC / 1 A maximum, signal loads only.

**D6. All parts from one source** (owner, 2026-10-08). The board will most
likely be made and assembled by NORI, who probably order from abroad. Every
part, including terminals, LCD and buttons, must come from **one catalogue**
with stock, so nothing needs a separate search or shipment. The owner recalls
that NORI buys parts, and has boards above two layers made, **in China**, so
**LCSC is the primary catalogue**. As a fallback each part should be stocked at **LCSC and at one
global distributor (DigiKey or Mouser)**: then the BOM works whichever route
NORI buys through. A part found only at one of them is flagged in the BOM. This rules out
special imports such as Phoenix FRONT-MC terminals and Newhaven displays
unless that catalogue stocks them.

**D7. RS-485 / Modbus RTU fitted** (owner, 2026-10-08) so the board can send
readings to a PLC/SCADA and take commands. **Isolated**, because the far end is
outside this board's ground: ADM2587E as in REV A2 (LCSC C12081, 6,979 pcs
2026-10-08; ~120 mA, into I-096); Chipanalog CA-IS2092W (C5121950) is a cheaper
alternate to evaluate. It is never in the trip path: no message can grant RUN,
clear a trip or bypass protection, and comms loss never grants RUN. Remote
setpoint writes, if allowed at all, need CRC, read-back and a local enable
(jumper or menu lock); to be specified with the protocol.

**D8. Cable shield bonded at panel entry** to a ground bar, not on the PCB.
Each thermocouple then needs two terminals (48 in total), pluggable 3.81 mm
blocks, possibly in tiers as on the Murphy board. Plus cold-junction sensors
at each terminal zone.

**D9. Mounting:** the board on standoffs on a metal plate in the panel, with
screws. Not DIN rail.

**D10. Board size is set by a to-scale floor plan**, not assumed. 100 x 100 mm
is not expected to hold 48 TC terminals, power and relay terminals, a 20x4
LCD (~98 x 60 mm) and five buttons. The first concept floor plan (2026-10-08,
placeholder blocks) came out at 170 x 130 mm; v1 with the `0032` parts is
170 x 120 mm, 4 layers. The floor plan is shown to the owner before any board write.

## Work split now

| Worker | Does |
|---|---|
| W1 Claude workstation | Floor plan, front-end design, schematic and board (only hardware writer) |
| W2 Codex | Calculations (fuse I-102, power I-096, front-end numbers), firmware core |
| W3 cloud | **On hold.** The RS-485 master/display task is cancelled |

## What could still go wrong (and how it is caught)

* A part goes out of stock between design and order: dated stock check at the
  single source before ordering, alternates named in the BOM.
* Assembly capability: AD7124-8 is a 5 x 5 mm LFCSP; confirm NORI assembles
  it, otherwise the order fails.
* Engine ground voltage during cranking is unknown: owner measurement
  requested (DC and AC, between distant probe locations and to battery
  negative).
* Grounded/insulated/mixed behaviour is proven only on the bench: build the
  first small batch, test all mixes and a cut wire, before machine use.
* Engine-room humidity, oil and vibration: **washing and conformal coating are
  mandatory** (`0032` rev 3, I-105); locking
  connectors to be decided.

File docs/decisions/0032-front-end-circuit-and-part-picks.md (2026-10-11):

# 0032 — Front-end circuit and first part picks for the 24-channel board

* Status: **accepted, revision 4** (2026-10-08): revision 1 after Codex reviews, then
  revisions 2-4 at the end of this file, which override the text above them. The 24-ch
  schematic implements revision 4; every "check" not closed in `ISSUES.md` is still open.
* Relates to: `0031` (architecture), I-101, I-103, I-091, I-093, I-094, I-095,
  I-096; Codex review `production/review-20261008/codex-frontend-review.md`
* Sources: AD7124-8 Rev B (LCSC C97314 PDF), local datasheets, LCSC stock read
  2026-10-08 in the browser

## Per-channel input (x24)

```
TC+ ──┬────────── R_s 1k ──┬────────┬──── AIN(2k)
      │                    │BAV199  │ C_cm 1n C0G to AVSS
      │                    │        ├── C_d 10n C0G ──┐
TC- ──┼── R_b 20M to V_mid │        │                 │
      └────────── R_s 1k ──┴────────┴──── AIN(2k+1) ──┘
```

* **R_b = 20 Mohm from each TC- terminal to V_mid**, on the terminal side of R_s,
  so the bias current does not flow through R_s. 39 Mohm was dropped: LCSC
  stocks 99 pcs at 33 M and 54 pcs at 39 M, but 245,086 at 20 M (FRG0805F2005TS,
  C3013337, 1 %).
  * Grounded probes, 100 mV between cylinders: I = 0.1 / 20M = 5 nA; error
    = 5 nA x 50 ohm assumed TC- lead = 0.25 uV = 0.006 degC (41 uV/degC).
  * Floating probe: common-mode shift = (I+ + I-) x R_b = 2 x 3.3 nA (AD-B p.7
    typ, full power) x 20M = 0.13 V. Leakage budget for 1.5 V headroom:
    1.5 / 20M = 75 nA per channel (was 38 nA at 39M).
  * Common-mode recovery after burnout: 20M x 2 x 1 nF = 40 ms (was 0.78 s
    with 10 nF C_cm at 39M, Codex Q2).
* **R_s = 1 kohm per leg** (0805, 1 %): limits clamp current. ADC input
  current mismatch error <= 3.3 nA x 1k = 3.3 uV = 0.08 degC worst, typically
  far less. Check: AD-B input current max over temperature.
* **Clamp: BAV199 per leg** to AVDD and AVSS, after R_s (low leakage, pA-nA;
  Nexperia 5 nA max at 75 V, 25 degC). **Check:** REV A2's code C5184419
  (15,280 pcs) is an **HXY MOSFET** BAV199, not Nexperia; its leakage must be
  read from the HXY datasheet, or a Nexperia code found. HXY datasheet (LCSC
  PDF, read 2026-10-08): IR 5 nA max at 70 V, 25 degC; VF 0.9 V at 1 mA; no
  high-temperature leakage figure, so measure it at the bench or prefer Nexperia. A Schottky clamp was rejected: its
  reverse leakage at 85 degC is microamps, which breaks the 75 nA budget.
  Codex Q1c: BAV199 lets the node reach ~AVDD + 0.9 V at 1 mA against the
  AD7124's AVDD + 0.3 V. The AD7124 also rates **AINx input current 10 mA**
  absolute maximum (AD-B p.13, Table 4). **Check:** whether a second series
  resistor (1k) between the clamp node and the AIN pin is needed so the
  internal diode never carries more than its allowance; leaning yes, it costs
  48 resistors.
* **Filter:** C_d 10 nF C0G across the pair, C_cm 1 nF C0G each leg to AVSS
  (was 100 nF / 10 nF). Burnout charge time to gain-32 full scale:
  (10n + 1n/2) x 78 mV / 0.5 uA = 1.6 ms. RFI corner 1/(2 pi x 2k x 10.5n)
  = 7.6 kHz; 50/60 Hz rejection is the AD7124's digital filter.
* **Gain 32**: full scale +/-2.5 V / 32 = +/-78 mV covers K-type to ~1370 degC.
  High-gain CMR window at 3.3 V: 0.116 to 3.184 V (AD-F Table 3 note 8), i.e.
  about +/-1.5 V around V_mid.
* No TVS on the thermocouple inputs: any practical TVS leaks microamps.
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

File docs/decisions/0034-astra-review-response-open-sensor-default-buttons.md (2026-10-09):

# 0034 - Response to the Astra review: open-sensor default, buttons, layout repair

* Status: accepted (owner 2026-10-09 for D1; engineer's call, owner delegated, for D2-D3)
* Date: 2026-10-09
* Builds on: `0031`, `0032`, `0033`
* Evidence: `docs/reference/review-20261009-astra.md` (Codex GPT-6-Astra, whole-project
  review at commit `5f8abc6`; its evidence files stay in `production/review-20261009-system/`)
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

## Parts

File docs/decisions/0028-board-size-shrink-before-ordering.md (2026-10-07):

# 0028 — Shrink the board before ordering; stay on four layers

* Status: **proposed — the owner chooses the target size** (see "Open")
* Date: 2026-10-06
* Deciders: owner (raised by an outside engineer; "no mechanical constraint")
* Relates to: `I-090`, `I-025`, `0014` (four layers), `0024` (3 modules), `I-078`

## Context

An experienced engineer told the owner the board is large with empty areas:
it could be much smaller, or two layers, and perhaps 100 x 100 mm "with
difficulty".

Measured on the REV A2 board (KiCad 10, courtyards, 2026-10-06):

* Outline **250 x 140 mm = 350 cm²**, four layers.
* 193 parts, all on the top side. Their courtyards total **67 cm², 19 % of the
  board**. The largest are U1 (DIP-40, 51.5 x 18.4 mm), K1, eleven terminal
  blocks (16 x 11 mm each), J2 (1 x 16 LCD header, 42 mm long), U12, U15.
* **No decision or calculation ever justified 250 x 140.** It came from the
  first 8-channel plan (`board/config.py`, there since `f60e6d3`, 2026-09-07)
  and was never questioned. `CALCULATIONS` 5.5 already notes it is "not an
  optimized minimum".
* The owner says there is **no enclosure or panel constraint** on the shape.

A to-scale map is in `production/board-size-map.svg` (local, not tracked).

### Prices (JLCPCB online calculator, 2026-10-06)

Bare PCB, 5 boards, 1.6 mm FR-4, green, HASL, calculator defaults. Shipping by
DHL is about $31-33 in every case. Not checked: PCBWay, and assembly (PCBA) and
stencil, which change much less with size.

| Size | 4 layers | 2 layers |
|---|---|---|
| 250 x 140 (now) | **$46.60** ($25 engineering fee + $21.60 board) | $20.90 |
| 160 x 100 | **$34.90** ($25 + $9.90) | $11.70 |
| 100 x 100 | **$8.00** (special offer, no engineering fee) | $4.00 |

So the money is small next to the parts (eight MAX31856 per board). The
step that matters is 100 x 100: four layers become **$8** because the $25
engineering fee disappears. 160 x 100 saves only ~$12 per order.
The bigger gain of any shrink is **panel space**: three modules (`0024`).

## Options

| | Target | What changes | Risk |
|---|---|---|---|
| **A** | **~160 x 100 mm** (−55 % area) | Placement and routing only. Schematic, netlist, BOM and firmware stay the same | Low: re-place, re-route, re-verify everything (DRC, power stage `0026`, vias I-075, drill file) |
| B | **100 x 100 mm** (−70 %) | Also: U1 DIP-40 → ATmega32A-AU (TQFP-44, SMD, same firmware); J2 1x16 → 2x8 header; probably parts on both sides; a denser analogue area | Medium-high: a schematic change, a new netlist baseline, a tighter isolation layout, and maybe two-sided assembly (costs more) |
| C | Two layers | Already tried in the old `8ch-2layer` (now `_old/`): hours of routing, 14 unfinished `+3V3_SENS` connections, and no ground plane under the microvolt inputs | Rejected: it saves $14-26 per order at the cost of the 50 m-cable noise immunity. Shrinking saves as much without that loss |

## Recommendation

**Shrink, and keep four layers.** The outside engineer was right about the
size and wrong about the layers.

The 2026-10-06 audit of inherited choices (I-091 to I-099) shows that the size
is not the only thing carried over unexamined. Several of those choices set the
board's edge length and area: where the HMI goes, the relay, the shield
screws, isolated RS-485, the DIP-40 and the channel pitch. So **the target size
is chosen after the owner answers I-091 to I-096, not before**:

* If the answers keep every part, go to A (~160 x 100), with a layout-only change.
* If the owner accepts the part changes in I-095 (TQFP MCU, 2x8 header, J6/C51/
  R17-R24 removed), and maybe I-093/I-094, then **B (100 x 100, $8) becomes
  realistic**. In that case it is one schematic change plus one layout pass,
  done once.

## Remaining design work

1. Complete I-091 (HMI delegated to design team in `0029`), I-092 (dry-contact
   ratings), I-093 (shield termination), I-094 (RS-485 form) and I-095 (verified parts).
   The owner conditionally accepts part changes (update below). I-096 is for
   the agent to do.
2. Then choose A or B. The agent proposes the floor plan and the owner approves
   it before any board write.

## Consequences

* `production/8ch-reva2/` stays **on hold**. The shrink is a new layout, so
  the board revision becomes **A3** (silkscreen, `BOARD_REV`, firmware
  `APP_TARGET_BOARD`).
* Every hardware gate is re-run and re-quoted after the shrink. The power-stage
  distances in `CALCULATIONS` 5.2 are re-measured, not assumed.
* I-025 (two-layer backup) is closed; the backup is in `_old/8ch-2layer/`.

## Update 2026-10-07 — sourcing candidate and conditional part changes

The owner permits changing the MCU and other components **provided the exact
replacements are available and suitable for normal use**. Exact choices,
ATmega32A-AU stock, proposed deletions and the floor plan still need review. Check
pin mapping, electrical/reset behavior, package, lifecycle and dated supplier
stock before committing to a replacement. The LCD will sit off the main PCB;
button mounting and cable distance remain design work (I-091, delegated in `0029`).

**NORI Solutions is the likely supplier, not a final order decision.** The
owner reports local two-layer fabrication and imported four-layer boards.
The supplied calculator screenshot at <https://norisolutions.com/pcb-fabrication>
shows **5 boards, 100 x 100 mm, 4 layers, FR-4 1.6 mm, green, EGP 2,530 total
(EGP 506 each), estimated 2–3 weeks**. No Gerbers are uploaded in the screenshot.
This is an indicative bare-board quote, not proof the current design fits that
size. Finish, stack-up, copper, manufacturing limits, assembly, tax and delivery
inclusions must be confirmed; direct page access in this cloud returned HTTP 403.

Compare like-for-like delivered totals: PCB + shipping + customs/taxes/clearance
+ payment costs, with assembly and components separately identified. The
historical JLCPCB 100 x 100 quote above totals about USD 39–41 with shipping,
before import costs. Re-quote the actual verified A3 size and specifications
with both suppliers before ordering; do not assume the promotional price lasts.

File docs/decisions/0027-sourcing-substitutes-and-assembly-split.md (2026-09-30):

# 0027 — Three sourcing substitutes, technician fits the through-hole parts, three boards

* Status: accepted
* Date: 2026-10-01
* Deciders: owner ("اعمل توصياتك"; technician for THT; 3 boards)
* Relates to: `I-078`, `I-069`, `0024`

## Context

Five BOM lines had no LCSC code and were found under the exact MPN, or as the
same part on a reel: U2-U9, U13, U15, U1 and RV1 (see I-078). Three could not
be found that way.

## Decision

| Ref | Was | Now | Why |
|---|---|---|---|
| K1 | Omron G5LE-1 DC24 | **Omron G5LE-14 DC24**, LCSC `C116965` | G5LE-1 is not at LCSC. The Omron datasheet lists -14 as the "fully sealed" version of the same SPDT relay: same terminals, same footprint. Rejected: G5LE-1-VD DC24, of which only 5 are in stock. |
| C53 | Panasonic EEUFC2A220 | **Rubycon 100YXF22MEFC8X11.5**, LCSC `C88838` | Not at LCSC. The replacement is the same rating (22 uF, 100 V, 105 °C, 8 mm, 3.5 mm pitch), from a known maker, with 11.8 k in stock. Rejected: the cheapest no-name parts. |
| U12 | XP Power IA0505S | **XP Power IA0505S, unchanged; bought at DigiKey** (`1470-1345-5-ND`), hand-fitted | LCSC only has other makers' "IA0505S-1W..." parts, which are the I-069 trap. The XP part is in production (lifecycle "Production") and stocked at DigiKey. |

**Assembly split:** the factory fits the SMD parts. The technician fits every
through-hole part:

* relay, terminal blocks, DIP socket, headers, buttons;
* IA0505S, C53, RV1, LED, test points.

The owner said this is easy for the technician. The factory THT option is
worth taking only if the quote shows the price difference is small.

**Quantity:** 3 boards, one per 8-channel module (`0024`).

## Consequences

* K1's value changed to G5LE-14 DC24. The netlist baseline was revised for that
  value only; connectivity is unchanged.
* The C53 catalog entry now names the Rubycon part.
* U12 needs a DigiKey order (and customs) separate from the fab order. Order it
  early.

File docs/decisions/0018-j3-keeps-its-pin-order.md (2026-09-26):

# 0018 — J3 keeps its COM/NO/NC order; the board moves to match K1

* Status: accepted
* Date: 2026-09-25
* Deciders: owner
* Relates to: `I-058`, `I-061`

## Context

After the `I-058` fix, K1's real contact pads are NO = pad 3 (219, 79.2) and
NC = pad 4 (231, 79.2). `J3` (rot 90, entry facing the edge) presents
COM/NO/NC bottom-to-top. So the relay-to-terminal traces have to cross, and
`RELAY_NC` could only be routed by breaking the 2 mm relay-contact clearance.

## Options

* **(a) Move `J3` (and `R33`, which is in the way) so its pins line up with
  K1's pads.** Only the layout changes. The installer sees the same terminal
  order.
* **(b) Change `J3`'s pin order in the schematic.** Routing gets easier, but the
  order the installer wires to changes.

## Decision

**(a).** J3 is the dry contact of an energised-to-run safety output. A terminal
order that differs from what an installer expects is a wiring error waiting to
happen. A miswired contact can defeat the protection with no visible symptom.
Moving two parts costs less than that risk.

## Consequences

* `board/placement.py`: move `J3` (for example, pins at y 89/84/79) and `R33`.
  Check it in KiCad, then regenerate. DRC must show zero `clearance` errors on
  `RELAY_*`, and `check_board.py` must pass.
* J3's silkscreen and the installation wiring note stay as they are.

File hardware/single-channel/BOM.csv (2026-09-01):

Reference | Quantity | Value | Package | Notes
U1 | 1 | ATmega32A-PU | DIP-40 | Internal 8 MHz clock
U2 | 1 | MAX31856MUD+ | TSSOP-14 | Precision thermocouple converter
U3 | 1 | AMS1117-3.3 | SOT-223 | 3.3 V regulator
J1 | 1 | 5V regulated input | 2-pin 5.00mm terminal block | Observe polarity
J2 | 1 | LCD 16x2 | 1x16 2.54mm header | HD44780-compatible
J3 | 1 | K-type thermocouple | 2-pin 5.00mm terminal block | Use thermocouple-compatible connector if accuracy is critical
J4 | 1 | AVR ISP | 2x3 2.54mm header | 3.3 V programming
J5 | 1 | Relay contacts | 3-pin 5.00mm terminal block | COM / NO / NC; low-voltage loads only
RV1 | 1 | 10k | 3296W trimmer | LCD contrast
R1 R2 | 2 | 100R 0.1% | 0805 | Matched thermocouple input resistors
R3 | 1 | 10k | 0805 | RESET pull-up
R4 | 1 | 1k | 0805 | Q1 base current limit
R5 | 1 | 10k | 0805 | Q1 base pull-down keeps relay off during reset
R6 | 1 | 1k | 0805 | Alarm LED current limit
R7 | 1 | 100R | 0805 | LCD backlight current limit
C1 C2 | 2 | 10uF 10V | 1210 | Regulator input/output
C3 C4 C5 C6 C10 | 5 | 100nF | 0805 | Supply and AREF bypass
C7 | 1 | 100nF C0G | 0805 | Differential thermocouple filter
C8 C9 | 2 | 10nF C0G | 0805 | Common-mode thermocouple filter
TP1 TP2 | 2 | Test point | THT 2mm | DRDY and FAULT
Q1 | 1 | 2N3904 | TO-92 E-B-C | Relay low-side driver; verify the purchased part pinout
D1 | 1 | 1N4007 | DO-41 | Flyback diode across relay coil
D2 | 1 | Alarm LED | LED 5mm | Lights when PB3 alarm output is active
K1 | 1 | SRD-05VDC-SL-C | Songle SRD SPDT THT | 5 V coil; footprint and contact ratings must match purchased relay
H1 H2 H3 H4 | 4 | M3 mounting hole | 3.2mm drill

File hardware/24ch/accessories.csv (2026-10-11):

Item | Qty per board | LCSC | MPN | Maker | Source | Status (lookup 2026-10-11: hardware/24ch/output/accessories-lookup-20261011.md)
TC plug 8 pin 3.81 mm for J101-J302 | 6 | C14234 | WJ15EDGK-3.81-08P-14-00A | KANGNEX | LCSC | 12,333 in stock; no alternate found
ENGINE REF plug 2 pin 3.81 mm for J401 | 1 | C8466 | WJ15EDGK-3.81-02P-14-00A | KANGNEX | LCSC | 88,555 in stock; alt C62113
Panel-button cable housing XH 6 pin for J503 | 1 | C144405 | XHP-6 | JST | LCSC | 21,420 in stock; alt C493080
XH crimp contacts | 6 | C140573 | SXH-001T-P0.6 | JST | LCSC | 996,800 in stock; alt C385122
Panel push buttons (UP DOWN SET ESC ACK) | 5 |  |  |  | local | industrial 12-16 mm, momentary NO, oil/glove rated - pick with the panel (0034 D2)
LCD 16 pin female header for J502 | 1 | C350305 | 2685Y-116CNG1SNA01 | HOAUC | LCSC | 330 in stock; or solder the LCD pins
20x4 HD44780 LCD | 1 |  |  |  | local | bought locally (0031 D4): standard 2004A 98x60 mm, M3 holes 93x55 mm centres, 16-pin row on top, pin 1 7.5 mm right of the top-left hole (fits H6-H9/J502)
LCD standoffs M3 female-female ~15-20 mm | 4 |  |  |  | local | length from the LCD drawing (face ~24 mm above board)
Board standoffs M3 x 10 mm + screws M3 x 6 | 6 |  |  |  | local | not on LCSC
Jumper shunts 2.54 mm for JP731-JP733 | 3 |  |  |  | local | not found on LCSC; fit per RS-485 bus position
Panel fuse 1 A time-delay >= 80 VDC >= 10 kA + holder | 1 |  |  |  | local | spec CALCULATIONS 7.4 / I-102; no DC-rated part on LCSC
Conformal coating acrylic IPC-CC-830 | 1 can per ~10 boards |  | MG Chemicals 419D or equal |  | local | not on LCSC; procedure in ORDER-NOTES (I-105)

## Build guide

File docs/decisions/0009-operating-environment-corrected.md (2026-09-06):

---
status: accepted
date: 2026-09-07
deciders: Zain, Claude
amends: 0003, 0008
---

# The operating environment, corrected

## Context

Two facts in the project record were wrong. Both came from agents assuming
rather than asking, and both were corrected by the user on 2026-09-07.

| Recorded | Actual |
|---|---|
| Eight sensors on the same cylinder | Same engine, **eight different cylinders** |
| A motor/VFD panel | **An engine.** There is no VFD anywhere |
| — | The unit lives in **its own panel**, 50 m of cable away from the engine |
| — | The sensors read **cylinder body** temperature, not exhaust gas |

`docs/GOAL.md` R-7 still says *"Survive a motor/VFD panel and 50 m cable runs"*.
That file is owned by the user, so it is flagged here rather than edited.

## What this settles

**Vibration and ambient temperature are not design constraints.** The board is
in a dedicated panel, not on the engine. The DIP-40 socket, the relay, the
radial electrolytic and the DC-DC modules are all fine where they are. This
removes what would otherwise have been the most serious mechanical problem on
the board - a socketed microcontroller on an engine walks out of its socket.

**The shared isolated island suits this application well.** All eight sheaths
bond to one engine block, so channel-to-channel differences are small. The
island floats up to engine-block potential as a whole and the isolation barrier
carries the difference between the engine and the panel - which is exactly the
job it was designed for. `0003` reached the right answer for the wrong reason;
`0008` over-corrected on a premise that was also wrong.

**Ungrounded probes drop from blocker to insurance.** Worth specifying if the
supplier has them, because they remove the cranking-current path for free, but
they no longer gate the design. `I-026` is downgraded accordingly.

**The setpoint is a stored, operator-settable value.** The user is explicit that
it must not be hard-coded and must survive a power cycle so the engineer can set
it on site. That is `I-012`, and it is a stated requirement rather than a
nice-to-have.

## What is still open

**Where the 24 V comes from is undecided, and it changes the input protection.**

- *A 24 V supply in the panel, off the mains.* The present protection - 0.5 A
  PTC, SS34 series diode, SMBJ33A clamp, TSR 1-2450 - is adequate. No change.
- *The engine's own battery and alternator.* It is not. Load dump on a 24 V
  system reaches 60-120 V; the SMBJ33A clamps near 53 V and the TSR 1-2450 is
  rated to 36 V input, so the regulator sits below the clamp and would be
  destroyed. That case needs a wide-input regulator - the Recom R-78HB series
  runs 9-72 V and KiCad already carries the footprint - plus a clamp chosen
  under its ceiling. Tracked as `I-028`.

The barrier still has to be measured (`I-004`), and no EMC or real-sensor
testing has been done. Neither is changed by any of the above.

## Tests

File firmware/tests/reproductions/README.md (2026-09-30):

# Preserved review reproductions — 2026-09-29

These source files preserve I-073 and I-074 outside ignored `production/`.
They include the current real application source using relative paths. They
are diagnostic reproductions, **not additional passing release gates** and
are deliberately not linked by `firmware/build.ps1` or the Makefile yet.
When fixing the issues, integrate the relevant cases into the normal tests
without retaining duplicate test plumbing indefinitely.

| Source | What is real / modeled | Historical result on reviewed firmware |
|---|---|---|
| `repro_save_ack.c` | Real application/protection/settings/monitor; HAL doubles | Exit 1, seven failed safety assertions. Stored limit 100 C, first save fails at tick 11, inputs change 90 to 120 C at tick 15, successful retry at 23, ACK at 24. RUN_PERMIT is wrongly on at ticks 24–30. A fix must keep it off while hot or invalid and allow normal safe recovery. |
| `repro_boot.c` | Real application **and** MAX31856 bank driver; SPI register model | **I-074 fixed in FW 0.2.1; assertions rewritten.** Historical result on reviewed firmware: exit 0 confirmed the old defect (false CH1 FAULT through tick 19, ACK cleared it at 20, display said SAFE while off). Now exit 0 means the owner's 2026-10-01 policy holds: eight healthy 20 C inputs, stored 100 C limit, output off and status `START: PRESS ACK` for ticks 0-19 (through the driver's settling sweep, no false fault, never SAFE), ACK at tick 20 accepted, permit on, `SAFE`. The same scenario is covered in the normal gate by `test_app_integration.c`; this file keeps the real-driver variant. |

Both were compiled with MSVC C11 `/W4 /WX` and rerun after relocation on
2026-09-29. Output is in
`production/review-20260929/preserved-reproductions/` (ignored).
Loop ticks are simulated iterations, not measured physical milliseconds.

## Windows reproduction

Run from the repository root in PowerShell with the same installed Visual
Studio C build tools used by `firmware/build.ps1`. No AVR programmer or
physical board is involved. This is the compile/run sequence exercised in
the review; inspect each executable's exit code using the table above.

```powershell
$vswhere = 'C:\Program Files (x86)\Microsoft Visual Studio\Installer\vswhere.exe'
$vsInstall = & $vswhere -latest -products * -requires Microsoft.VisualStudio.Component.VC.Tools.x86.x64 -property installationPath
$vsDevCmd = Join-Path $vsInstall 'Common7\Tools\VsDevCmd.bat'
$reproOutput = Join-Path (Get-Location) 'production\review-20260929\preserved-reproductions'
New-Item -ItemType Directory -Path $reproOutput -Force | Out-Null
$common = 'firmware\src\app\protection.c firmware\src\app\sensor_monitor.c firmware\src\app\settings.c'
foreach ($case in @('repro_save_ack', 'repro_boot')) {
    $extra = if ($case -eq 'repro_boot') { 'firmware\src\hal\temperature_max31856_bank.c firmware\src\hal\tc_decode.c' } else { '' }
    $compile = "call `"$vsDevCmd`" -arch=x64 -no_logo && cl /nologo /std:c11 /W4 /WX /Ifirmware\tests\host_mocks /Ifirmware\include firmware\tests\reproductions\$case.c $common $extra /Fe:`"$reproOutput\$case.exe`" /Fo:`"$reproOutput\\`""
    & $env:ComSpec /d /s /c $compile
    if ($LASTEXITCODE -ne 0) { throw "Compilation failed for $case" }
    & "$reproOutput\$case.exe"
    Write-Output "$case exit code: $LASTEXITCODE"
}
```

## Evidence preservation

The production-folder logs and binaries can be regenerated. Keep these
sources and the issue descriptions when committing the review; no commit
was made by the review agent. Original artifact copies remain untouched.
Hardware measurements are not simulated by these tests.

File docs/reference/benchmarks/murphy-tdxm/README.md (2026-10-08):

# Murphy TDXM — a commercial 24-channel engine pyrometer, for reference

Photos taken by the owner on 2026-10-08 of boards from a commercial engine
temperature scanner. They are kept as a design reference for REV A3
(`docs/decisions/0030`). **They are reference only, not a source to copy.**

| File | What it shows |
|---|---|
| `photo-1.jpg` | Display board, solder side (raw PCB 10-05-1281 rev C): 2x17 connector to the input board, through-hole LCD pins |
| `photo-2.jpg` | Display board, component side ("F.W. MURPHY MFG."): custom 7-segment LCD (U17, backlight BL1 under it), LCD driver U7 (PCF8566-type), 44-pin MCU U8, crystal, programming header P2 |
| `photo-3.jpg` | Input board 10-00-4143 rev G1, component side: three rows of pluggable terminals TS2_A/B/C (24 channels), isolated supply block (MPD LF102S, LP2954 regulator, Coilcraft inductor), LDA111 opto-couplers, D2PAK output FETs, 28-pin parts U4-U6 (multiplexers, inferred) |
| `photo-4.jpg` | Display board, solder side close-up (raw PCB 10-05-1281 rev C) |
| `photo-5.jpg` | A second display board (raw PCB 10-05-1261 rev B): RJ-style jack JR1, 2x17 header |
| `photo-6.jpg` | A different product, "RE-25AR-DISP-R1": 16x2 character LCD module on screws, alarm LEDs, coin cell, 26-pin IDC |
| `photo-7.jpg`, `photo-8.jpg` | Input board 10-00-4143 rev G1, whole board: the terminal rows stacked side by side on one edge |

## What the manual says

From the Murphy TDXM manual
(https://www.manualsdir.com/manuals/124629/murphy-temperature-scanner_pyrometer-tdxm.html,
read 2026-10-08):
* Inputs: up to 24 type J or K thermocouples, "grounded or ungrounded". The
  manual **recommends ungrounded**: grounded probes may read wrongly because
  of ground differences.
* Scans all channels in 2 s; a tripped setpoint is detected within 2 s.
* Outputs: two FET sinks (0.5 A, 350 VDC) and one form C solid-state relay
  (0.125 A, 350 VDC / 240 VAC). These are signal-level outputs.
* 10-32 VDC supply, 750 mW maximum. RS-485 Modbus RTU slave. An open
  thermocouple drives the reading high.

## Lessons recorded for REV A3

* **One converter behind analog multiplexers** (inferred from the board):
  only one probe is connected to the measurement at a time, which is how it
  accepts both probe types.
* **Pluggable terminals in tiers along one edge** fit 24 channels into about
  12 cm of board edge.
* **Signal-level solid-state outputs** are normal for this class of device.

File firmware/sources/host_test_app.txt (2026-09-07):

# main_8ch.c is not listed here: tests/test_app_integration.c pulls it in by
# #include, with its own main() renamed out of the way, so it must not also
# be compiled as a separate translation unit (that would link two mains).
# It is already accounted for by app_8ch.txt.
app/protection.c
app/sensor_monitor.c
app/settings.c

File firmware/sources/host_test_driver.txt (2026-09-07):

hal/temperature_max31856_bank.c
hal/tc_decode.c

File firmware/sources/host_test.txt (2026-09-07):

app/app_logic.c
app/protection.c
app/sensor_monitor.c
app/settings.c
hal/tc_decode.c

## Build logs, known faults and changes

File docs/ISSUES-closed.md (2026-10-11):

# Closed issues

Archive of closed issues, moved out of `ISSUES.md` on 2026-10-01 so that file
stays short enough for every agent to read in full (`decisions/0025`). Rows are
kept as they were written. A closed issue is never renumbered or deleted; if it
comes back, reopen it in `ISSUES.md` under the same number.

| # | Closed | What fixed it |
|---|---|---|
| I-089 | 2026-10-07 | Owner reconfirmed manual ACK (`0029`). Retain the I-074 startup/reset latch and no automatic restart; acknowledge only with valid readings below reset limits. A brown-out/watchdog reset still removes RUN until ACK. Per-channel limit conversion and reset checks remain implementation work in I-100. |
| I-074 | 2026-10-01 | Owner policy: **every power-up waits for ACK.** The boot latches `APP_TRIP_CAUSE_STARTUP`, and the display shows `START: PRESS ACK`, never SAFE. The settling sweep can no longer latch a false fault on top. The ACK is accepted only when every channel is valid and cool; otherwise `NO ACK CHn FAULT/HOT`. A blank EEPROM keeps `SET SETPOINT`. 3 logic and 4 integration tests; 4 older integration tests shifted to ACK first (reasons in the commit). `FW 0.2.1`. `build.ps1` 2026-10-01: exit 0, 3 suites PASS, 8ch image 5918 B. Done by a Sonnet sub-agent; reviewed and built in the main tree. Consequence: I-089. |
| I-082 | 2026-10-01 | `program.ps1` now **refuses** any image except `thermo_8ch_max31856.hex` (exact name), exiting 2 before avrdude runs; `-AllowUnapprovedImage` overrides it with a loud warning. Run 2026-10-01 with `legacy_1ch_max31856.hex`: exit 2, no avrdude call. Limit: it checks the name, not the content. Done by a Sonnet sub-agent; reviewed and run in the main tree. |
| I-088 | 2026-10-01 | The status line now shows `NO ACK CHn HOT` / `NO ACK CHn FAULT` after a refused ACK (save-fault and config paths) and clears once the channel cools. Display only: the permit logic is unchanged. Tests are in `test_app_logic.c` (`test_ack_refusal_status_text`) and the extended integration test. `build.ps1` 2026-10-01: exit 0, 3 suites PASS, 8ch image 5840 B. |
| I-055 | 2026-10-06 | Moot: `populate_schematic.py`, which placed new parts at the old offset, was replaced by `sch_layout/build.py` and moved to `_old/hardware-8ch/`. |
| I-025 | 2026-10-06 | The two-layer backup was a revision behind and never finished. Moved to `_old/8ch-2layer/`; four layers stays (`0014`, `0028`). Two layers was re-judged on 2026-10-06 against JLCPCB prices: it saves $14-26 per order and loses the plane under the thermocouple inputs. |
| I-075 | 2026-10-01 | Cause found: the SES import gives every via its netclass drill, so **41** vias placed before routing (U14's six, the 32 MAX31856 supply vias, C41, and two power-stage vias) came back 0.6/0.4. The review saw only U14's six. Fix: `route.py` re-drills any via with a ring under 0.15 mm, and `apply_rules.py` sets `min_via_annular_width` 0.15, so DRC now fails a 0.10 ring; before the fix it reported 39 errors on the old board. Measured 2026-10-01 in the board **and** the exported `.drl`: six 0.3 mm holes at U14, minimum ring 0.15 mm everywhere. |
| I-073 | 2026-10-01 | `protection.c`: a recovered save fault now falls through to the normal ACK checks (every sample valid and at or below the reset temperature). Five regression tests were added to the normal gate (4 in `test_app_logic.c`, 1 in `test_app_integration.c`); they fail against the old code (10 and 14 checks). `repro_save_ack.c`: 7 failures before, all pass after. `firmware/build.ps1` 2026-10-01: exit 0, 3 suites PASS, 8ch image 5598 B. Done by a sub-agent in a worktree and reviewed before landing. |
| I-070 | 2026-10-01 | `APP_TARGET_BOARD` is now `"THERMO-8CH REVA2"`. It is written REVA2 because the LCD cuts at 16 characters and "REV A2" would lose the digit. `_Static_assert`s keep both boot strings at 16 or fewer. |
| I-071 | 2026-10-01 | `.github/workflows/hardware.yml` now compares against `netlist-baseline-reva2.json`. |
| I-065 | 2026-09-28 | Fixed in **REV A2** (`0022`) with both proposed fixes, because neither is enough alone: `U10`/`U11` are now `ISO7760DWR`/`ISO7761DWR` (no F), so an open input defaults HIGH and every CS stays deselected in reset (ISO7761 datasheet, function table); and **`R61` 2k2** now sits between `U11` pin 7 and `MISO_CTRL`, so the AVR wins MISO during ISP. 2k2 rather than the 1k first proposed keeps contention at 2.3 mA, inside the ISO7761's 4 mA (`CALCULATIONS.md` 4.2). No firmware change: SPI is 500 kHz, and the MISO low level with the pull-up is 0.5 V. **Still to do at the bench:** program `U1` in-circuit through `J5`. The finding as written: commit `cf69b03`. |
| I-066 | 2026-09-28 | Fixed in **REV A2** (`0022`): `Q1` is a **BSS131** (Infineon, 240 V, SOT-23, LCSC `C151498`), 2.5x D2's 96.8 V worst clamp. VGS(th) is at most 1.8 V and RDS(on) at most 20 Ohm at 4.5 V, a 0.33 V drop at 16.7 mA (`CALCULATIONS.md` 4.1). Pinout G1/S2/D3 is read from the datasheet drawing. Symbol `Q_NMOS_GSD`; the netlist moved Q1's pin numbers, not its nets. BSS123 (100 V, 3 % margin) was rejected. The part is ESD Class 0, so it needs ESD care at assembly. The finding as written: commit `cf69b03`. |
| I-067 | 2026-09-28 | Fixed in **REV A2** (`0022`): `R53`/`R54` are **100k / 22k**. That is 4.33 V at 24 V and 0.28 mA into PC2's clamp at 58 V (was 1.2 mA). The input still reads a valid high down to 16.6 V (was 17.0 V). Two value changes, no new part (`CALCULATIONS.md` 4.3). The finding as written: commit `cf69b03`. |
| I-068 | 2026-09-28 | Fixed in **REV A2** (`0022`): `F1` is **1812L075/60GR** (LUTE, 60 V, 0.75 A hold, 1812, LCSC `C48985874`). It holds the 0.39 A cranking-floor load up to a 70 °C panel ambient (derating table, `CALCULATIONS.md` 4.4). Faults after the regulator are capped by the LM5164's own current limit. **Open assumption:** the panel's maximum ambient temperature is not known; above 70 °C, look again. LCSC stock is thin (~2 k). The finding as written: commit `cf69b03`. |
| I-069 | 2026-09-28 | Fixed in **REV A2** (`0022`): (a) `U12`'s description now says **XP Power IA0505S, not the 'IA0505S-1WR3'**, and it has no LCSC code that could pull the wrong part. (b) `D3` value and MPN are now **M7** (MDD, SMA, LCSC `C95872`), so the BOM no longer says a bare "1N4007". (c) `D2` is drawn as a unidirectional diode (`Device:D_Zener`), cathode on `+24V_PROT`, with the footprint unchanged. Its `Manufacturer` now matches its LCSC code (R+O). **Still to do on the assembled board:** check D2's band. The finding as written: commit `cf69b03`. |
| I-027 | 2026-09-26 | **No schematic change needed.** MAX31856 datasheet (19-7534 Rev 0, now `docs/reference/datasheets/MAX31856.pdf`): "T- is biased to approximately 0.735V by the BIAS output", and "the thermocouple wires connect directly to inputs T- and T+, with a common-mode bias voltage provided by the BIAS output"; its typical circuit is a floating thermocouple with BIAS on T-. Every channel already ties `BIAS` (pin 2) to `T-` (pin 3) on `/TCn/FILT_N`. The datasheet also says BIAS "is floating when no conversions are taking place" - the bank driver runs continuous mode (`CR0_CMODE`, `temperature_max31856_bank.c`) and verifies it by read-back, so BIAS is always driven. An ungrounded probe (`I-026`, `0008`) therefore works on this board as built. |
| I-045 | 2026-09-26 | All four EMC items settled on the REV A1 board, measured. (a) BAV199 input clamps `D7`-`D22` are on the board (parity 0). (b) Layer-transition return vias: **0 vias on the `/TCn/FILT_*` nets**; 8 on `/TCn/RAW_*` (terminal to 100R) - copper-copper, no thermal EMF, ~0.5 mOhm against 100 Ohm; only effect is loop area for noise, which the bench settles (`I-004`); SPI at ~1 MHz. Accepted, not fixed. (c) Pours stop 6 mm from the edge **by design**: the chassis/PE ring runs 3 mm inside the edge and is kept off every signal ground (`.kicad_dru`). (d) **`U12` decoupling fixed: 18 mm / 10 mm -> 4.2 mm on all four pins** - `C45` had been placed beside `U10`, 55 mm away; `C45`/`C46` now sit under `U12`'s pins, one each side of the barrier (`placement.py`). Board regenerated and routed; `validate.ps1` passed (ERC 0/0, IDENTICAL, DRC 0/0/0/0), `check_board.py` all ok. |
| I-062 | 2026-09-26 | **Schematic is an A3 root plus `channel.kicad_sch` (A4) used by sheets TC1-TC8** (`0019`). `sch_layout/hier.py`, last step of `build.py`, derives it from the flat wired sheet; `rootlayout.py` packs the root blocks onto A3. Only the channels were split: their 7 external nets keep their names through sheet pins; 40 internal nets renamed `/TCn_X` -> `/TCn/X`; every other name untouched. Proved with the new `netlist_fingerprint.py --allow-renames`: 645 pins on the same nets, 201 components; only other change JTC1-8 value -> `K_TYPE` (KiCad 10: one value per symbol). Baseline regenerated from that netlist, reason recorded in it. `apply_rules.py` patterns updated (without it: 499 isolation violations on a test copy); board nets renamed in place by `rename_board_nets.py`, copper unchanged. Workstation: ERC 0/0, netlist IDENTICAL, DRC 0/0/0/0, `check_board.py` all ok, all 40 channel nets `SensorSignal`; `build.py` from `05d6abd` reproduces it. Fab package re-exported (BOM 79 lines). **Amended the same day by `0021`:** the rest of the root now sits on four A4 sheets too (POWER, MCU, ISOLATION, RELAY_RS485), and the root is an A4 index. 56 more nets gained a sheet path. Every board net keeps its netclass (162 compared, 0 changed); `validate.ps1` all green. |
| I-051 | 2026-09-26 | Verified 2026-09-26 from a fresh BOM export: 86 lines / 201 parts, **every line has an MPN except TP1-TP9** (bare pads, nothing to order). 10 lines have no LCSC code (C53, K1, RV1, U1, U2-U9, U10, U11, U12, U13, U15) - they need JLC global sourcing or hand assembly, a sourcing choice, not a gap. `check_mpn_consistency.py`: 128/128. |
| I-032 | 2026-09-26 | The regenerated board carries `Y1` + `C60`/`C61` on `U1` 12/13: parity 0, 0 unconnected. **Fuse the chip `0x3F` only on this board**; `-LowFuse 0x24` is the escape (`fuses.md`). |
| I-016 | 2026-09-26 | The regenerated board carries `R53`/`R54` on `RUN_PERMIT_SENSE`: schematic parity 0, 0 unconnected (`validate.ps1` 2026-09-26). Firmware side was already live. |
| I-024 | 2026-09-26 | Gone with the REV A1 regeneration: DRC reports **0 warnings**, so no dangling via remains. |
| I-006 | 2026-09-26 | Silkscreen now placed by measured boxes, not estimates: `place_labels()` puts free text at its first clear candidate (and refuses to leave the required dry-contact marking anywhere else - it had been printed over K1's pads), designators get corners, 90-degree and a nearest-clear grid fallback. `generate_board.py --silk-only` applies it to a routed board. `validate.ps1`: **DRC 0 errors, 0 warnings.** |
| I-063 | 2026-09-26 | Workstation updated KiCad 10.0.3 -> **10.0.6** (winget), the cloud's version; `Converter_DCDC_Isolated` now present. `validate.ps1` on the workstation: **ERC 0/0, netlist IDENTICAL 201/162/645, DRC 0 errors / 14 warnings / 0 unconnected / 0 parity, sources unchanged.** |
| I-061 | 2026-09-26 | **REV A1 board regenerated and routed.** J3 moved to K1 (`0018`); R59/R60 turned to 270 so R60's GND pad is not walled in; the MAX31856 GND pins (1, 14) get fixed vias like the supply pins (`board/stitching.py`) - left to the pour, one per run floated (U3.14, then U5.14); `route.py` re-stitches pour pieces after closing gaps. Measured on the workstation, KiCad 10.0.3: route.py "0 unconnected pad pairs"; `check_board.py` all 6 ok; `kicad-cli pcb drc --refill-zones --schematic-parity` on a copy: **0 errors, 0 unconnected, 0 parity**, 14 silkscreen warnings (8 overlap, 6 over copper, `I-006`). `validate.ps1` stops on ERC `I-063`, not on the board. Freerouting's own "157 violations" is its plane-less model, not DRC. |
| I-060 | 2026-09-26 | Kept the 0.2 mm thermal vias, board minimum 0.2 mm (`0017`); DRC shows no `drill_out_of_range`. Check the fab quote. |
| I-002 | 2026-09-24 | **The schematic is a drawing.** Every block laid out by function and wired: eight identical channels (connector, 100R pair, filter, BAV199 clamps, MAX31856, CS pull-up, MISO series R), the two isolators with their series resistors, the isolated 5 V / LP2985 rail, the MCU with crystal/reset/LCD/buttons/ISP, RS-485, the relay, and the 24 V input with the LM5164. One label per wired group, placed on its wire where the text fits. Done through Konnect by `hardware/8ch/sch_layout/build.py`, which starts from the last label-only schematic and is repeatable. Measured: netlist **IDENTICAL** to `netlist-baseline-reva1.json` (201/162/645), **ERC 0 errors, 0 warnings** (the 171 `endpoint_off_grid` are gone), `check_mpn_consistency.py` 128/128. What is left is cosmetic: `I-059`. Found `I-058` on the way. |
| I-057 | 2026-09-24 | `U12` relinked to `Converter_DCDC_Isolated:IA0505S` with Konnect `replace_component`, and `populate_schematic.py` changed to match. The KiCad 10 `IA0505S` extends `IA0305S`, so the pins are identical - netlist IDENTICAL - and it is the dual +/-5 V part the board uses (+Vout -> `+5V_ISO`, 0V -> `GND_SENS`, -Vout unused). ERC now reports 0 warnings in the cloud as well as on the workstation. |
| I-053 | 2026-09-15 | **The pitch was never the problem - the part number was a two-way block on a three-way footprint.** Owner ruled that 0.08 mm of pitch does not matter and nothing is to be re-footprinted; checking the order code before applying that ruling showed the premise was wrong in a worse way. Phoenix **1935161 is `PT 1,5/ 2-5,0-H`: 2 positions, 5.0 mm pitch** - not an MKDS at all. So the pitch on the footprint (5.000 mm) was right all along, and what would have arrived is a connector with **one terminal too few** on ten positions - eight thermocouple inputs plus `J1` and `J3`. The MKDS 1,5/3-5,08 the row assumed is order code 1715734. **Fixed without touching a single footprint**, exactly as the owner asked: all ten move to `WJ128V-5.0-3P` (`C8270`, KANGNEX, 5.0 mm, 3 positions) and `J4` to `WJ128V-5.0-04P-14-00A` (`C192769`) - one family, 5.0 mm throughout, stocked at LCSC where this board is sourced, instead of a Phoenix specialty import. `populate_schematic.py` was corrected too, so a rebuild cannot put the wrong number back. Verified: ERC **0 violations**, netlist **188/155/613 IDENTICAL**, BOM exports the new codes on all eleven. Residual, accepted: the footprint's silkscreen body is the Phoenix outline, so the KANGNEX body may sit a fraction outside it - pads and pitch are what solder, and this is a cosmetic courtyard note to check at layout, not a fit problem. |
| I-052 | 2026-09-15 | **`populate_schematic.py --refresh-properties` resets symbol POSITIONS, not just properties, and it silently undid the whole `I-002` re-layout.** Run to make `Y1` pick up its corrected footprint, it moved every symbol back to the coordinate in the generator's part table: `U1` from x 326 to x 29, `U15` from 538 to 254, and ERC went **0 -> 188 `endpoint_off_grid`** because the off-grid table coordinates came back with them. The netlist stayed correct, so `netlist_fingerprint.py` did **not** catch this one - ERC did, which is why the gate hardening in `I-049` mattered. Recovered from the owner's commit `ea0e4ee` (`git show HEAD:... > temp`, verified the extents and paper size, then copied over - `git checkout` was refused as destructive, and verifying first was better anyway). **The flag's name promises far less than it does.** Use a targeted `edit_schematic_component` for a single part's value or footprint; `--refresh-properties` is only safe on a schematic whose layout is still the generator's. |
| I-050 | 2026-09-15 | **A uniform bulk move is not uniform on an off-grid sheet, and it shorted four nets.** Konnect's `bulk_move_schematic_components` snaps each symbol to the 1.27 mm grid **independently**, so `C60` moved with `dy=0` and its y still went 163 -> 162.56, and `U1` moved `+284` from x=42 and landed on 326.39 rather than 326. On a sheet that is off-grid by definition - the 192 `endpoint_off_grid` warnings *are* `I-002` - relative geometry therefore shifts by up to ~0.5 mm and pins that were distinct collide. Four did: `GND_RS485` merged into `+5V_RS485` (**a ground onto a 5 V rail**), `SCK_CTRL` into `GND_CTRL`, `SCK_SENS_RAW` into `GND_SENS`, `RS485_RE_N` into `RS485_DE`. `netlist_fingerprint.py` caught all four; nothing else would have. Two were a passive's pin landing on an IC pin (`C41`/`C42` on `U10`), fixed by moving the passive 3 grid units. The other two were subtler and are `I-049`'s mechanism again: the stale `GND_RS485` and `RS485_RE_N` labels survived pruning **because they had come to rest on a different component's pin** (`U15.19` and `U15.6`), so `prune_dangling_labels()` saw them as legitimately placed. **The rule that follows: once a sheet is on-grid, move only in exact multiples of 1.27 mm** - then the snap is a no-op, which was confirmed on the repair move (all four landed at exactly -3.81, no y drift). |
| I-049 | 2026-09-15 | **A stale label survived a net rename, and the gate could not see it.** Adding the REV A1 parts moved `U1` pin 24 from `SPARE_PC2` to `RUN_PERMIT_SENSE`, but `ensure_labels()` only adds labels and `prune_dangling_labels()` only removes labels **not** on a pin - and this one *was* on a pin. Both names ended up on the same node. ERC saw it: *"Both RUN_PERMIT_SENSE and SPARE_PC2 are attached to the same items; RUN_PERMIT_SENSE will be used in the netlist"*. **KiCad picked the winner, not us, on a safety read-back net.** The netlist happened to be right, which is why the fingerprint diff looked clean. `[multiple_net_names]` is a **warning**, and `Assert-ErcReport` threw only on errors - so the gate was green. Found by reading the report, which is not a gate. Fixed twice over: the stale label deleted, and `Assert-ErcReport` now fails on any warning class outside an explicit tolerated list. Only `endpoint_off_grid` is tolerated, with the reason recorded in the code - 192 of them, all of `I-002`, tracked. Tested both ways: the real report passes, an injected `multiple_net_names` is rejected and the message names the offending class. |
| I-048 | 2026-09-15 | **The project's core tool lived in `%TEMP%` and a reboot deleted it.** `kicad-tool` was installed to `%LOCALAPPDATA%\Temp\thermo-kicad-tool-venv`, which Windows is entitled to clear - and did, taking the entire generative pipeline with it: `ModuleNotFoundError: No module named 'kicad_tool'`. Reinstalled with `uv tool install git+https://github.com/mash/kicad-skills.git` to `~/.local/bin`, which persists. **Never `pip install kiutils`** - that pulls upstream, which lacks the API this fork needs. All five references updated to prefer the persistent path and fall back to the old one: `run_all.ps1`, `validate.ps1`, `populate_schematic.py`, `output/render_review.py`, `docs/TOOLS.md`. Also learned the hard way that `kicad-tool` shells out to `kicad-cli` and needs `KICAD_CLI` set - `run_all.ps1` does it, a bare shell does not, and the failure is a bare `[WinError 2] The system cannot find the file specified`. |
| I-047 | 2026-09-14 | **Found while sequencing `I-002`, fixed before it could fire.** `prune_dangling_labels()` in `populate_schematic.py` deletes every label not sitting exactly on a pin coordinate. Its docstring states the premise - *"connectivity in this schematic is carried entirely by labels placed on pin endpoints"* - and **`I-002` is the task that voids it**: a wired sheet legitimately carries labels on wire segments away from any pin. **The path was live, not hypothetical.** `run_all.ps1` calls `populate_schematic.py --labels-only` as step **1/8 of every run**, including a plain validation, and `__main__` prunes unconditionally - the `--labels-only` switch only skips `ensure_parts()`. So the first `run_all.ps1` after the redraw would have deleted the new connectivity from the file. `netlist_fingerprint.py` is step 3 and would have failed loudly afterwards, but by then the schematic on disk is already damaged - the gate reports the corpse, it does not prevent it. Fixed by a guard: if the sheet matches `\(wire\b`, skip pruning and say so, because ERC is the right tool for dangling labels once a drawing exists. Verified both ways - the real schematic today has **0 wires** so pruning is unchanged, a KiCad-written `(wire (pts ...))` triggers the skip, and `(bus (pts`, `(wire_note` and `"wire"` do not false-positive. `docs/STATE.md` had carried this as a one-line warning since the reverted redraw; it is now code. |
| I-041 | 2026-09-08 | Verified by reading inside the archive, not by trusting the rename. `thermocouple_8ch.pdsprj` is a zip; its `ROOT.DSN` now references `thermo_8ch_max6675_sim.hex`, and that file exists in `firmware/build/` alongside the three other images. The obsolete `thermocouple_meter_max6675_8ch.hex` name is gone. **Proteus itself was not launched**, so this closes the stale-filename defect and nothing more - the simulation has still never been run against the current firmware, and the MAX6675 image remains a simulation aid whose converter is not the one on the board. |
| I-035 | 2026-09-08 | Owner chose X7R; `docs/decisions/0011` has the reasoning and what was rejected. `populate_schematic.py` now writes `100n X7R 50V` for `C1`/`C6`/`C11`/`C16`/`C21`/`C26`/`C31`/`C36`, and `passives_catalog.json` resolves it to `CC0805KRX7R9BB104` (JLCPCB basic, 15.7 M in stock). Acceptable in this position specifically: the capacitor sits across `T+`/`T-` with no DC bias so X7R's voltage coefficient does not apply, the board is in a panel 50 m from the engine so nothing excites its piezoelectric response, and the 10:1 ratio against the C0G common-mode pair - the part CMRR actually depends on - is unchanged. Verified after the edit: ERC 0 errors / 171 `endpoint_off_grid` warnings, DRC **0 unconnected and 0 schematic parity issues**, netlist 167 components / 154 nets / 555 pins. The PCB was not touched. |
| I-044 | 2026-09-08 | Found by the same run, and recorded because the root cause is different from `I-035`. `populate_schematic.py` has specified `C48` (the LP2985-3.3 output bypass feeding all eight MAX31856 and both isolators) as `4.7u X7R 16V` since commit `f60e6d3`, while the committed schematic still carried `1u X7R`. Nothing noticed, because `ensure_parts()` only writes properties for symbols that do not yet exist - an existing symbol keeps its old value unless `--refresh-properties` is passed, and nothing in `run_all.ps1` or `validate.ps1` compares the schematic against its own generator. The generator is the source of truth, so the schematic has been corrected to 4.7 uF and `passives_catalog.json` now carries `CGA0805X7R475K350MT` for it. **The gate gap is the real finding**: `validate.ps1` checks the schematic as committed, so any future drift between generator and schematic is invisible again. A regenerate-then-compare step would close it, but that writes the schematic, so it needs the owner's view on where it belongs relative to the REV A0 freeze. |
| I-040 | 2026-09-08 | Verified 2026-09-08 line by line; every item it lists was already reconciled. `GOAL.md` R-8 now reads *EEPROM implementation exists* and R-9 *deferred for REV A0 by decision 0010*. `AGENTS.md` and `hardware/8ch/README.md` state *no VFD in the installation* - the corrected environment from `0009`, not the old premise. The hardware README says the AP2112K *was replaced by* LP2985-3.3, and records that the passive catalog exists while the 100 nF filter specification still conflicts (`I-035`). `STATE.md` is 60 lines against its 60-line limit, down from 86, and no longer lists closed work as pending. |
| I-005 | 2026-09-08 | Closed as **accepted**, not fixed. DRDY and FAULT on all eight MAX31856 stay unconnected because both isolators are fully allocated; the reasoning is on record in `docs/decisions/0004`. Fault detection reads the status register instead, and since `I-038` the driver also re-reads CR0/CR1 every scan, so a converter that stops answering is caught without those pins. Nothing further to do unless a REV A1 frees isolator channels. |
| I-008 | 2026-09-08 | Closed as **not applicable**. The Murata NCS1S is not on the board and was only ever a candidate for a wide-creepage regulated isolated module; `docs/decisions/0002` chose the LP2985-3.3 path instead and that is what is fitted. Its unknown control-pin logic cannot affect this design. Reopen only if that module is revisited. |
| I-036 | 2026-09-07 | Verified 2026-09-07 by running the gate, not by reading the diff. `main_8ch.c` now keeps `candidate_setpoint_x10` and `active_setpoint_x10` apart: UP/DOWN move only the candidate, protection only ever evaluates the active value, and a save that cannot be read back raises `APP_TRIP_CAUSE_SAVE_FAILED` and discards the candidate instead of the stored limit. `tests/test_app_integration.c` drives the real `main_8ch.c` against HAL doubles and passes. |
| I-037 | 2026-09-07 | Verified 2026-09-07. The `config_locked` branch in `app_format_status_line` now comes **after** the editing branch, so a blank unit shows the candidate limit while still refusing to permit running. Covered by `test_app_integration.c`. |
| I-038 | 2026-09-07 | Verified 2026-09-07, and fixed more strongly than the issue asked for. `configuration_ok()` re-reads CR0 and CR1 and checks them against the masks on **every scan**, not once after init, so a MISO stuck at 0x00 or 0xFF fails immediately instead of reading a plausible 0 degC as valid for ~55 s. A recovered channel also burns one settling scan so it cannot report a conversion that was still running. The residual limit is documented in the source: a MISO stuck at a level that happens to satisfy both masks would still pass, because register read-back is not bus verification. `tests/test_bank_driver.c` passes. |
| I-039 | 2026-09-07 | Verified 2026-09-07 by running it. `check_commands.ps1` provides `Invoke-CheckedNative` plus report assertions; `validate.ps1` checks a snapshot copy and never writes the source board; `test_gates.ps1` injects failures and confirms all eight gates reject them. Three defects in the gates themselves were found while exercising them and fixed - see `I-043`. |
| I-042 | 2026-09-07 | Verified 2026-09-07 by running the gate. `sources/check_lists.py` is now invoked by `build.ps1`, the `Makefile` and firmware CI (10 lists, 19 source files, all accounted for). `tests/test_app_integration.c` links the real `main_8ch.c` against `tests/host_mocks/`, and `tests/test_bank_driver.c` drives the real MAX31856 bank driver against a register model. All three suites report `all checks passed` and `build.ps1` exits 0. |
| I-043 | 2026-09-07 | Found while running the gates for the first time end to end, all three fixed. (1) `build.ps1` exited 1 while every suite passed: `VsDevCmd.bat` writes a harmless "vswhere.exe is not recognized" line to stderr and `ErrorActionPreference = 'Stop'` promotes a native tool's stderr to a terminating error. Native calls now go through `Invoke-Native` and are judged on exit code. (2) `test_gates.ps1` and `validate.ps1` returned a non-zero exit on success - `test_gates.ps1` deliberately runs a command that exits 17 as one of its fixtures and `$LASTEXITCODE` kept that value - so CI would have read a passing gate as a failure. Both now `exit 0` explicitly. (3) Worst of the three: `validate.ps1` printed "Sources unchanged" **without having hashed anything**. Windows PowerShell 5.1 will not bind plain strings from the pipeline to `Get-FileHash`, so both the before and after lists were empty and `Compare-Object` compared two empty sets. A gate claiming a check it never performed is worse than one that fails. Hashing is now by `-LiteralPath` and refuses to report success unless every file was hashed; `validation.json` records four real SHA-256 values where it recorded none. |
| I-030 | 2026-09-07 | Wrote `src/hal/temperature_max31856_bank.c`: eight MAX31856 on one bus, per-channel configured/not-configured state, configuration read back after writing, and a channel that loses the bus re-configured on its next scan instead of taking the bank down. The board has firmware for the first time. |
| I-031 | 2026-09-07 | Added `hal/run_permit.{h,c}` with permit semantics in the name, kept `hal/alarm_output.*` for the superseded board, and stopped tracking every `.hex` in git - a stale binary with the opposite polarity was the actual hazard. `program.ps1` warns when the image is not the eight-channel one. |
| I-011 | 2026-09-07 | `app/sensor_monitor.c`: a reading that has not moved 0.1 degC in 120 scans is frozen, and a jump beyond 50 degC in one scan is not physics. Either marks the sample invalid, which latches the trip. Host-tested including the case of a channel returning from a fault. |
| I-012 | 2026-09-07 | `app/settings.c` + `hal/settings_store.c`: setpoint in EEPROM behind a CRC-16, written then read back. An invalid record does **not** fall back to a working setpoint - there is no safe guess for someone else's engine - it config-locks the unit, which shows `SET SETPOINT` and refuses to permit running until an operator stores one. |
| I-014 | 2026-09-07 | `mcal_spi_transfer` now reads `SPDR` on the timeout path, so `SPIF` clears and the byte stream cannot slip permanently. The re-init path is in the new bank driver. |
| I-015 | 2026-09-07 | `firmware/fuses.md` + `firmware/program.ps1`, which reads the fuses back and fails on a mismatch. **The issue text was wrong and is corrected there**: `U1` runs from `+5V_CTRL`, not 3.3 V, so the brown-out level is 4.0 V. It also found that `JTAGEN` is enabled by default and occupies `PC2`-`PC5`, and that `EESAVE` must be programmed or reprogramming wipes the setpoint. |
| I-017 | 2026-09-07 | `PORTB |= (1 << PB6)` in `mcal_spi_master_init`. |
| I-018 | 2026-09-07 | `HAL_MAX6675_SPI_MODE` defaults to mode 0 - the silicon - and the Proteus target overrides it to mode 1 with a `-D`. Nobody ships the simulation's timing by accident. |
| I-019 | 2026-09-07 | Decoding moved to `hal/tc_decode.c`, which has no AVR headers and links into the host tests. Eight cases including -10 and -200 degC, which is what catches a dropped sign extension. |
| I-022 | 2026-09-07 | `firmware/sources/*.txt` is now the single source list; `Makefile` and `build.ps1` both read it. `sources/check_lists.py` fails if a listed file is missing **or if a `.c` under `src/` is in no list** - the second half is what would have caught `I-030`. |
| I-023 | 2026-09-07 | `include/app/version.h`, shown on the LCD at boot and recorded on the commissioning sheet by `program.ps1`. |
| I-007 | 2026-09-07 | `hardware/8ch/source_passives.py` holds the electrical requirement for all 22 distinct passives and resolves each against LCSC; `passives_catalog.json` is the result with MPN, LCSC code, stock, price and the alternates. 22 of 22 resolved - and the search is what found `I-035`. |
| I-021 | 2026-09-07 | `.github/workflows/hardware.yml` exports the netlist from the committed schematic in a KiCad container and compares it with `netlist_fingerprint.py` against the REV A0 contract, plus a check that every passive still has a part number. |
| I-033 | 2026-09-07 | `README.md` rewritten. It described the project as a 100 degC alarm meter and named the superseded single-channel board as the "final physical design". |
| I-034 | 2026-09-07 | ERC re-run against the real schematic: **171 `endpoint_off_grid`, 0 errors** - confirming the number in `docs/STATE.md` was right. (A 714-violation reading during the session came from a broken intermediate file, not the schematic.) |
| I-010 | 2026-09-07 | `git mv semulation simulation` and the project file from `thermocouble [Autosaved]f.pdsprj` to `thermocouple_8ch.pdsprj`, history kept. Proteus was closed this time. |
| I-020 | 2026-09-07 | Split `generate_board.py` (1211 lines) into a `board/` package of ten modules, 18-258 lines each, by responsibility: config, units, geometry, boardio, placement, silkscreen, zones, copper, stitching, connections. `generate_board.py` is now a 65-line entry point and the stable import surface for `route.py`, `check_board.py` and `close_gaps.py`. Verified identical output: same 166 reference designators, same 16 supply vias, same structural checks, zero courtyard overlaps. |
| I-029 | 2026-09-07 | `docs/GOAL.md` corrected by the user's instruction: R-7 no longer says VFD, R-8 states the setpoint must never be hard-coded, and a new "Where it runs" section records the engine, the cylinder-body sensors, the dedicated panel and the 50 m cable so no agent has to guess again. |
| I-001 | 2026-09-07 | Not nine routing problems but three causes: `add_plane_stitching` filtered on `+3V3_SENS` so five of the six plane nets were never stitched; `finish()` poured the outer grounds *after* stitching so their isolated pieces did not exist yet; and `C56`/`C57`/`R33` sat in a 1 mm strip. Fixed by stitching every plane net, pouring before stitching, adding `stitch_pour_islands`, a 0.6 mm via fallback and a 1 mm placement move. `docs/decisions/0007`. DRC: 0 errors, 0 unconnected. Gerbers in `production/8ch/`. |
| I-009 | 2026-09-07 | `hardware/8ch/README.md` rewritten with the LP2985-3.3 and the measured numbers. |
| I-000 | 2026-09-06 | `Q1` had gate and source swapped — the gate sat on GND and the drive signal on the source, so the MOSFET could never turn on, the relay could never energise and `RUN_PERMIT` could never assert. The machine could not have started. Fixed in `populate_schematic.py`. |
| I-107 | 2026-10-09 | 24-ch routing finished: TC21_NA (old PA loop re-assigned, PA via In2.Cu) and CS_CJ5_ISO (`maze.py` with In2), then `rules.py` full + NORI nudges + stub cleanup + `pcb sync`. `output/drc-synced.rpt`: 0/0/0. |
| I-110 | 2026-10-09 | EP vias moved onto the paste-window gaps: U301 4, U101 2, U201 2 (B.Cu CS_ADC3_ISO and DIN_ISO moved off the pad centre), U601 3 on its only wide gap (hole flush with paste - NORI I-106 Q2). Measured hole-to-paste +0.025..+0.097 mm on the ADCs; `fanout.py`/`rules.py` match. `output/drc-ep.rpt` 0/0/0. |
| I-117 | 2026-10-11 | Entry documents synced 2026-10-11 at the owner's request: GOAL status column to `0031`-`0034` (open TC trips by default, LCD on the board, RS-485 fitted, one island), root README rewritten for the 24-ch board, `0032` header says accepted revision 4, `0031` D5 marked superseded by `0034` D1. `docs/check_docs.py` now catches stale phrases (`docs/superseded.txt`). |
| I-090 | 2026-10-11 | Board 170 x 145 routed on that placement: `production/24ch-reva3-20261009/drc-report.rpt` 0 violations, 0 unconnected; ERC 0/0. Remaining layout work is I-111..I-114. |
| I-095 | 2026-10-11 | ATmega1284P-AU C33575 (LCSC 1,943 on 2026-10-08) chosen; every pin checked against its datasheet in the `0032` revision 4 pin-level review. |
| I-092 | 2026-10-11 | Drawn in `hardware/24ch/gen/c_out.py`: G6K-2F-Y DC5 on +5V, 2N7002 low side, 1N4148W flyback, 10 k read-back of the coil low side, trip drive through a charge pump; checked in the `0032` rev 4 pin review. Stock goes to I-103; rating text stays on the board and I-113. |
| I-077 | 2026-10-11 | Not applicable to the 24-ch board: its relays are G6K-2F-Y DC5 on the regulated 5 V rail (`0032` rev 1), so the 58 V load dump never reaches a coil. The finding concerned the 8-ch board's G5LE DC24 coil. |
| I-097 | 2026-10-11 | Superseded: the 8-ch firmware will not ship. The watchdog (<= 0.5 s) and the scan budget move to I-118/I-119 for the 24-ch firmware. |
| I-099 | 2026-10-11 | 8-ch-only leftovers; the 24-ch board has none of them (SM712 on RS-485, no 0.1 % input resistors). Backlight resistor sizing is in I-096. |
| I-112 | 2026-10-11 | FID1 (7, 10), FID2 (160, 9.5), FID3 (10, 135): 1 mm dot, 2 mm mask, 0.5 mm local clearance so no pour shows in the opening; board-only, out of BOM/CPL (`gen/fiducials.py`). DRC with parity and refill 0/0/0. |
| I-113 | 2026-10-11 | Silk 2026-10-11 (`gen/silk.py`): J701 titled RUN PERMIT C-NO, J601 pin 3 CHAS, J401 adds "2 WIRES, JOINED ONLY AT THE ENGINE", J503 pin legend. The site wiring sheet part moved into I-085. |
| I-115 | 2026-10-11 | `build.py` fails on kicad-cli errors and stale reports; `gen/guard.py` (KiCad lock + writer claim) wraps every board-writing tool; `fab.py` writes a unique release folder from a snapshot (no fills saved into the source), MANIFEST with sha256 and ORDER-NOTES. Each failure path reproduced (Sonnet sub-agent, reviewed); guard refusal re-run 2026-10-11. CI part stays I-084. |
| I-121 | 2026-10-11 | Y501 left of U501 beside pins 7/8, C501/C502 between: XTAL1 33.1 -> 8.3 mm, XTAL2 48.9 -> 14.6 mm (load-cap branches included), vias 4 -> 0 (`0035` D4). XTAL2 is over the 10 mm aimed for because C503 (pin-5 VCC) keeps the straight path. |
| I-116 | 2026-10-11 | `hardware/24ch/accessories.csv`: plugs (C14234 x6, C8466), XH housing/contacts (C144405, C140573), LCD female header (C350305), and the local items (LCD, panel buttons, standoffs, shunts, panel fuse, coating) with what is not on LCSC. `fab.py` copies it into every release as ACCESSORIES.csv. NORI's quote against it stays in I-078. |
| I-111 | 2026-10-11 | `gen/pincaps.py` exits 0 (33 pins) and DRC with parity/refill 0/0/0. LM5164 stage re-laid (`gen/buck24.py`), ISO7761/MCU caps beside pins (`gen/capnear.py`), AD7124 by the rule in `0035` D6 (owner): supplies by plane vias, REGCAPA/REGCAPD/REFOUT <= 5 mm (2.3-4.3). Crystal moved too (I-121). Backups in `hardware/24ch/output/bak/`. |
| I-108 | 2026-10-11 | Owner: no board change; buy a standard 20x4 HD44780 module (2004A, 98 x 60 mm, M3 holes 93 x 55 mm on centres, 16-pin row on top, pin 1 7.5 mm right of the top-left hole) to fit H6-H9/J502 as placed; spec in `accessories.csv`. J503 panel header done (`0034` D2). Panel cut-out moved to I-122. |
| I-106 | 2026-10-11 | Owner: where/how NORI assembles is theirs; our spec is the ORDER-NOTES.txt that `gen/fab.py` writes into every release (layers, ENIG, tented vias, paste, wash, coating). Their acceptance rides in I-078. |
| I-103 | 2026-10-11 | Easiest route (owner): no named alternates list; stock read 2026-10-11 (`output/stock-20261011.csv`, 0 out of stock) and ORDER-NOTES says no substitution without written approval, so NORI reports any shortage on the day and we pick then. Folded into I-078. |

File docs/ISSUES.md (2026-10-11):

# Open issues

**How this file works** (`decisions/0025`, 2026-10-01):

* It is an **index sorted by priority**, and it stays short so every agent
  reads all of it. One table row per issue.
* A row is at most about 600 characters and holds four things: what is wrong,
  why it matters, where the evidence is, and when the issue can be closed.
  Long arithmetic goes to `reference/CALCULATIONS.md`, a choice between
  alternatives goes to `decisions/`, and raw logs go to `production/review-*/`.
  The row points there.
* No narrative sections. A review's findings become rows here. Its coverage
  notes become rows too, or one bullet under "Not verified by anyone" below.
* Numbers are never reused. Closing an issue means moving its row to
  `ISSUES-closed.md` with the date and what fixed it.
* **Review weight.** A finding an agent judged overstated keeps its row, but
  says so, together with the agreed weight and the reason. Nothing is silently
  dropped.

Severity: **blocker** stops fabrication · **high** is a real failure mode ·
**medium** costs time or quality · **low** is tidiness.

**Priority:**

* **P0** blocks the board order.
* **P1** must be done before a unit protects a machine.
* **P2** is measured at the bench when boards arrive.
* **P3** is later, or an accepted limit.

---

## P0 — blocks ordering the 24-ch board (REV A3)

| # | Sev | Issue | Close when |
|---|---|---|---|
| I-078 | medium | **Send the release to NORI and review the quote.** Release `production/24ch-reva3-20261011-094327-940d10/` (git 7c7e25c, tree clean, DRC 0/0/0, pincaps 0, BOM 94 lines all LCSC): send the zip, BOM, CPL, ORDER-NOTES and ACCESSORIES.csv. NORI reads stock on the day and asks before any substitution (ORDER-NOTES; was I-103). Earlier: bare 4-layer EGP 8,710 for 5 / 11,500 for 10 (2026-10-09), parts ~$105/board (`gen/cost.py`). | NORI quote (PCB + assembly + each ACCESSORIES line covered or excluded) reviewed with the owner |

## P1 — before a unit protects a machine

| # | Sev | Issue | Close when |
|---|---|---|---|
| I-122 | low | **Front-panel cut-out drawing** (from I-108): window for the 20x4 LCD and holes for the 5 buttons, from the bought LCD and the panel. Not needed for the board order. | Panel drawing made with the enclosure |
| I-118 | high | **Heartbeat must prove the scan, not just a timer** (Astra R-03): RUN_PERMIT PWM from OC0A can keep the charge pump alive while the main loop hangs. Toggle the heartbeat only when a fresh scan of all channels completes; watchdog not fed from an independent ISR. | Fault injection: hung loop with timers running opens the contact within the set time |
| I-119 | high | **24-ch firmware port list** (Astra R-04/R-05/R-11/R-12): scan needs >= 14 slots (~0.62 s, burnout ~5 s, common-mode ~10 s); ADT7310 0x0000 is 0 degC, not a dead bus (use ID/status/freshness); negative EMF is normal when the tip is colder than CJ; `program.ps1`/fuses are ATmega32 only; integration test mocks readback/WDT/EEPROM; `'1'+index` breaks at CH10; samples need timestamps; fault byte is full; EEPROM A/B records; watchdog <= 0.5 s against the 1 s budget (from I-097). | Each item in target24 with a test or bench measurement |
| I-104 | high | **24-ch firmware requirements from the front-end reviews** (`0032` rev 3-4): burnout lower window + per-channel baseline; ADT7310 ID/config/status checks (0x0000 is 0 degC - I-119), two-sensor cross-check per bank; reference ratio calibrated at production; PGA gain-ratio test; AVDD/6 every scan; mid-power mode; CRC on every read; reversed-polarity fault; open TC trips by default (`0034` D1); >= 14-slot schedule (I-119); RUN_PERMIT PWM into the charge pump toggled only by completed scans (I-118); JTAG off, WDTON, BOD; REFOK active-low. | Implemented and each one shown by fault injection at the bench |
| I-100 | high | **Independent channel limits are required but not implemented** (owner, 2026-10-07, `0029`). The 24-ch firmware is not written; the 8-ch firmware has one scalar setpoint. Needed: 24 operator-adjustable persistent limits, channel selection on the 20x4 LCD, per-channel trip/reset/hysteresis, per-channel "alarm only" and "not fitted" (`0034` D1), CRC/readback, EEPROM A/B records, config lock. Never invent commissioning temperatures. | Behaviour tested on the host and the bench; all build gates pass |
| I-085 | high | **24-channel installation drawing pending** (`0031`): trip (RUN PERMIT C-NO, from I-113) and alarm contacts, J601 3 = CHASSIS bar, J401 FEED and SENSE as two wires joined only at the engine, J503 panel buttons, probe-to-channel map, ground compatibility. An unused input reads open and trips (`0034` D1), so a partly fitted board needs a saved per-channel "not fitted" setting (I-100). | Panel drawing shows every terminal, the contacts' rated load and battery power; all 24 sensors mapped |
| I-102 | medium | **Panel fuse** (off-board, `CALCULATIONS` 7.4): `0020` stands conditionally (1 A time-delay, >= 80 V DC, >= 10 kA, pre-arc I²t >= 1 A²s): steady margin 2.65x at 9 V, inrush screening 0.509 A²s at 32 V = 1.96x. Goes into the accessory BOM (I-116). | Exact fuse and holder picked against DC rating, fault current and derating; startup I²t measured |
| I-091 | medium | **Operator interface** (`0031` D4): 20x4 LCD bought locally, five buttons + panel header (`0034` D2). Ask the operations engineer whether opening the door to read and ACK is acceptable. | Operations engineer answered; LCD part recorded |
| I-093 | medium | **Terminals and shield:** shield bonded at panel entry (`0031` D8); 48 pluggable 3.81 mm TC terminals (Kangnex) on the board. Exact extension cable and gauge still to specify. | Cable specified on the installation drawing (I-085) |
| I-094 | medium | **RS-485/Modbus** (`0031` D7): ADM2587E + SM712 on the board. Remote setpoint writes need CRC, read-back and a local enable; comms loss never grants RUN (protocol: I-086). | Protocol written and tested |
| I-086 | low | No Modbus firmware yet. The master is the plant PLC/SCADA (`0031` D7); the RS-485 hardware is on the board (I-094). Never in the trip path; comms loss never grants RUN. | Register map written and tested |

## P2 — measure at the bench when boards arrive

| # | Sev | Issue | Close when |
|---|---|---|---|
| I-114 | medium | **CJ sensors 25-35 mm from the terminal pads** (Astra R-08). The I-111 repair freed no room near the terminals (2026-10-11), so this is measured, not moved. | Gradient test with LCD, relays and RS-485 loaded: compensated error inside the budget |
| I-105 | high | **Board leakage is a measurement error source** (`0032` rev 3, H1): 3.2 k per leg turns ~10 Mohm node leakage into ~4 degC. **Layout guard done 2026-10-11** (`gen/vbias_pour.py`): V_BIAS pours over each bank's input network on F/B.Cu, island pour cut out there; input-node pads with GND_ISO within 0.5 mm 197 -> 6 (the 6 are ADC pins beside AVSS/EP). Washing + coating: `gen/fab.py` ORDER-NOTES carries the procedure (NORI if offered, else us). R_leak > ~120 Mohm per node. | Coated boards pass a humidity/leakage test at the bench |
| I-101 | high | **Probe junction type cannot be controlled** (custom, maybe mixed). Direction (`0031`): 3x AD7124-8, one probe at a time, 20 M TC- bias + buffered mid-rail engine-reference wire. Circuit in `0032` rev 2 after three Codex reviews: 2.2 k / BAV199 / 1 k protection, 150 ohm AVDD preload as clamp sink, REF3030 cross-check at gain 1, sensed engine-reference wire, 2 ADT7310 per bank, 13-slot scan 0.57 s. Out of scope: DC miswire survival (I-080). Still open (owner 2026-10-09: not before ordering - at the first engine test): engine ground volts at cranking; cable capacitance; hot leakage. | Schematic reviewed; bench test with grounded, insulated, mixed probes, a cut wire and a lost reference wire |
| I-120 | medium | **Bench and field test matrix** (Astra section 12): every channel and its location, <= 1 s contact response, open sensor, mixed grounds and cut FEED/SENSE, CJ gradient, partial power, firmware hang, ACK/startup, EEPROM power cut, Modbus flood, 50 m cable, humidity, installer trial, per-unit production test. | Each row run and logged on the first boards |
| I-098 | medium | **STUCK and step checks may nuisance-trip** (audit 12). A reading that stays inside 0.1 °C for 120 scans (~55 s) trips and needs ACK; a steady or stopped engine body can do that. `MAX_STEP` 50 °C/scan is from the cylinder-body basis, which GOAL says not to extend to all 24. Not inherited, but never validated. | Logged on a running and a stopped engine; window widened if needed |
| I-076 | high | **Buck layout measured, not claimed.** 24-ch U601: after the I-111 repair, measure rails, SW ringing and sensor noise. (8-ch U14 layout history: `0026`, `CALCULATIONS` 5.2.) | Rails, ringing on SW and sensor noise measured on an assembled 24-ch board |
| I-003 | high | The isolated module (24-ch: U401 B0505S-1WR2) is unregulated; its light-load output may approach 6 V. Mitigated by the LP2985 (`0002`) and the preload (`0032` rev 2), never measured. | Module output measured at real load |
| I-004 | high | The isolation barrier was never tested electrically. The 3 mm in `.kicad_dru` is functional, not a standard. | Insulation test across the barrier |
| I-013 | high | The 1 s trip requirement has never been measured. 24-ch budget: I-119 (~0.62 s scan). | Input stepped past the setpoint, contact timed on a scope |
| I-028 | medium | Battery input (24-ch: F601 PTC, D601, D602 SMBJ60A, U601 LM5164; panel fuse I-102). Open: (b) SMBJ60A clamps at ~96.8 V at its peak current, 3.2 V under the LM5164's 100 V; ISO 7637-2 fast pulses not worked through; (c) EMC of the switcher, ties to I-076. History: `git show 7107a94:docs/ISSUES.md`. | Fast-transient analysis or test; EMC and noise measured on hardware |
| I-096 | medium | **5 V budget** (`CALCULATIONS` 7, 7.7): with rev 3-4 parts and R502 = 22 ohm the 5 V worst is ~0.45 A, 9 V battery 0.35 A, 23 % margin on F601 at 70 degC; island preload fitted (`0032` rev 2). Open: the LCD's real backlight current and the operating envelope. | LCD measured; operating envelope (max ambient, min battery) agreed |

## P3 — later, or accepted limits

| # | Sev | Issue | Close when |
|---|---|---|---|
| I-081 | medium | A welded contact or a shorted driver keeps RUN permitted. 24-ch: both trip-relay NO poles in series (`0032` rev 3), so one welded pole is covered; a shorted Q701 or a weld on both poles is not. Read-back is the coil low side, not the contact. **Review weight:** accepted, documented limit (owner, 2026-10-01). A redundant shutdown path is a machine-safety decision. | The owner records the machine's other protection, or asks for a second path |
| I-080 | low | 24 V wired by mistake onto a TC terminal: 24-ch input is 2.2 k + BAV199 + 1 k into the island rails; not re-derived for the shunt clamp (8-ch figure: `CALCULATIONS` 5.3). **Review weight:** agreed low. We do not design for this miswire. | Only if the owner requires miswire tolerance |
| I-026 | low | **Superseded by I-101** (2026-10-08). Probe model does not exist (made to order); junction type to be measured on receipt with clip leads on the tip metal, not fingers. Electrical sheath isolation is not thermal isolation. | I-101 closed and probes classified on receipt |
| I-046 | medium | Konnect is AGPL-3.0; exposure today is zero (nothing distributed, no Konnect code in the repo). | Settled before shipping anything built around Konnect |
| I-054 | low | kicad-tool clones inherit the donor's MPN; `check_mpn_consistency.py` in `validate.ps1` catches it. | kicad-tool fixed upstream |
| I-056 | medium | Doc-system review (2026-09-17). The file-size and row-length parts are handled by `0025`. Still open: a dated evidence log, a decisions index, requirement-to-evidence traceability. | Those three exist, or are explicitly declined |
| I-084 | low | CI has no 24-ch job (schematic ERC/netlist, DRC, `pincaps.py`), and the 8-ch job runs fewer checks than `validate.ps1`. Ties to I-115. | CI runs the 24-ch gates, or the difference is documented |
| I-109 | low | **Cost options for the next revision** (`0033` D3): ADT7310 x6 is $32.4 of $104.9/board; TMP117 (C699536, ~$1.03, I2C, needs a bus change) saves ~$26/board. 52 extended LCSC codes cost a per-order setup fee at JLC-style assemblers (basic-part check by Haiku 5.5 and Sonnet 5.5, 2026-10-09: only 2N7002 -> C8545 and 2.2n -> C28260 C0G qualify, ~$6); non-critical pull-ups, LED resistors and bypass caps could move to basic parts (keep C0G, 20 M, BAV199). Codex 2026-10-09 (`production/review-20261008/codex-alternatives-review.md`): 3 CJ sensors + 2 ISO7761 (~$19, needs terminal-gradient data), RS-485 optional (~$9) or CA-IS2092W (~$5). Market (`market-scan.md`): Murphy TDXM 24-ch $2,200-3,600, PLC routes $1,900-3,300. Open designs (`open-designs-scan.md`): none replaces ours; ADI CN-0376 uses 3 k per input path (ours 3.2 k). | Decided at REV B |

## REV A2 (8-ch reference board) only

The 8-ch board is never ordered (`0031`); these stay open only for it: I-079, I-058, I-072, I-087, I-059, I-064, I-083.

| # | Sev | Issue | Close when |
|---|---|---|---|
| I-079 | medium | **`production/8ch-reva2/RELEASE.txt` said the K1 coil is ~2.9 kOhm.** The G5LE-1 DC24 coil is **1.44 kOhm ±10 %** at 23 °C (16.7 mA; `datasheets/G5LE-relay.pdf`). The 2.9 came from an old I-058 text, copied without checking. The package is marked on hold. | The re-exported package's RELEASE text uses 1.44 kOhm |
| I-058 | high | K1 coil pins were fixed in the schematic and PCB (2026-09-24/26). Before power-up: pins 2-5 read **1.44 kOhm ±10 %**, 1-4 read 0 Ohm and 1-3 open. | Measured on an assembled board |
| I-072 | low | Stale overview text: `hardware/8ch/README.md` (TSR 1-2450), firmware comments on feedback. **Audit 2026-10-06 (24) adds:** VFD comments `config.py:80`, `check_board.py:174`; "C_diff 100n C0G" (X7R since `0011`) `config.py:73`; "AP2112K" for U13 `placement.py:78`; "0.5 A PTC" `apply_rules.py:59`; "G5LE-1" `placement.py:150`; value text "10u 10V" on C45/C46/C55 (MPNs are 25 V/16 V). | Reconciled |
| I-087 | low | The Proteus project simulates a MAX6675, not the fitted MAX31856, so it proves nothing about the real sensor path (review 2026-09-29). | Updated, or labelled as legacy |
| I-059 | low | Field-text overlaps in dense schematic spots; readable, not tidy. | KiCad GUI touch-up |
| I-064 | low | The board overlaps the PCB-editor page frame. Cosmetic; fabrication is unaffected. | Offset applied at a regeneration |
| I-083 | low | `build.py` needs git history (base `05d6abd`); a source ZIP cannot regenerate the schematic. Not wrong, just coupled. | The release notes name the base commit, or the base is kept as a file |

## Not verified by anyone yet

This list is from the 2026-09-29 review coverage. The full table is in
`production/review-20260929/ISSUES-as-reviewed-20260929.md`, which is
local-only.

* Worst-case tolerances of every component; cold-junction gradients; 50 m cable accuracy and noise.
* Partial power-up and backfeed across the isolators; live SPI/ISP edges.
* Contact load and inrush against the relay rating; real contact timing.
* The exact LCD module, cable orientation and terminal mechanical drawings; the fab's rotation preview.
* RS-485 bus details (termination, bias, cable, EMC).
* Stock and lifecycle across all sources (58 parts "unknown").

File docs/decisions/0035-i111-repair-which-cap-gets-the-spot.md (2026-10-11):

# 0035 - I-111 layout repair: which part gets the spot next to the pin

* Status: accepted (engineer's call; owner delegated the layout repair in `0034` D3 and asked on
  2026-10-11 to work the P0 list through without stopping)
* Date: 2026-10-11
* Builds on: `0034` D3 (local repair, no regeneration); gate `hardware/24ch/gen/pincaps.py`

## Context

Moving every decoupling cap beside its pin is local, but the space beside a pin is often
already taken by another part or by routed copper. Each such conflict needed a choice.
Tools written for this: `gen/move.py` (move named parts, drop only their tracks),
`gen/capnear.py` (search a spot within N mm of a pin, score collisions, optional rip of
the signal tracks in the way, plane via beside a pad), `gen/buck24.py` (the LM5164 stage,
recorded as a script like the 8-ch `powerstage.py`).

## Decisions

**D1 - Every AD7124 bypass pin is equal: supplies, regulators and REFOUT.** The thermocouples
convert on the internal reference (`0032` "Converters, reference"), so REFOUT's 100 nF is part
of the measurement, not an unused pin; an early attempt that moved C191 away to make room
for AVDD was reverted. The gate covers AVDD (26), IOVDD (2), REGCAPA (24), REGCAPD (1) and
REFOUT (22) on all three ADCs.
* The ISO7761 island-side cap C408 swapped places with R402 (33 ohm SCLK damping): the cap
  must sit right of pin 16, the resistor can sit under pin 15 with no crossing.

**D2 - Analog input traces are never ripped to make room.** Thermocouple pairs (TC*) keep
their symmetric routes; only digital nets (SCLK, DIN, DOUT, CS, LCD, REFTEST, buttons) are
lifted and re-routed by `maze.py`. A spot that needs a TC track moved is not used.

**D3 - No via inside an SMD pad** (solder wicks down the hole). `maze.py` and `capnear.py`
now refuse it; two found (C408, C505) were removed. The exposed-pad thermal vias of the
AD7124/LM5164 are the only vias in pads, as before (`I-110`).

**D4 - Crystal moved to the XTAL pins (I-121).** Y501 sat ~25 mm away on the other side of
U501, traces under the chip on B.Cu. Moved left of U501 with C501/C502 between it and pins
7/8, traces on F.Cu only: XTAL1 ~8 mm, XTAL2 ~13 mm (C503, the pin-5 VCC cap, keeps the
straight path). Rejected: a 3225 crystal (smaller, would fit closer) - a part change for the
next revision, not needed to pass.

**D5 - The FB check counts the divider resistor.** The LM5164 FB network is R602/R603 at
FB; `pincaps.py` measured only capacitors. Limit unchanged (5 mm).

**D6 - AD7124: the rule follows how each pin is connected (owner, 2026-10-11: "the easiest
solution, even if we change decisions").** The 3 mm rule could not be met around the three
AD7124s without re-routing the SPI bus through the thermocouple area (tried twice, reverted).
* AVDD and IOVDD sit on the +3V3_ISO plane (In2) over the GND_ISO plane (In1): the current path
  is pin - via - plane - via - cap, so what counts is a via beside the pin and beside the cap.
  Gate: own via within 1.5 mm of the pin and of a cap no farther than 12 mm. Result: all six pass.
* REGCAPA, REGCAPD and REFOUT are single traces (no plane), and REFOUT is the reference the
  thermocouples convert against: a long trace picks up the SPI clock and may upset the internal
  regulators. Gate: 5 mm (was 3). Result 2.3-4.3 mm after moving C391-C393 (U301 above/right of
  the ADC) and swapping C193/C197, C293/C297 in the cap rows (REGCAPD 9 -> 3.3 mm).
* Rejected: 3 mm everywhere (re-routes the SPI bus around each ADC by hand, hours, risk to the
  TC traces); no limit (REGCAP/REFOUT at 9-12 mm is a real noise/stability risk).
* Bench check: reference and regulator noise is part of I-120.

## Consequences

* `pincaps.py` checks all five AD7124 bypass pins on each ADC (D6) and is a release gate in `fab.py`.
* A generic rip-up around the AD7124 failed (DOUT_ISO re-routed to 168 mm, three nets
  unroutable) and was reverted from `output/bak/thermo24-20261011-before-adc.kicad_pcb`;
  the ADC neighbourhoods are re-laid by hand coordinates instead.

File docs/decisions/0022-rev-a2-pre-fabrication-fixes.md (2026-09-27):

# 0022 — REV A2: the pre-fabrication review's fixes, and a new revision for them

* Status: accepted
* Date: 2026-09-28
* Deciders: owner (asked the agent to choose; "شوف الأنسب")
* Relates to: `I-065`, `I-066`, `I-067`, `I-068`, `I-069`; amends `0014`, `0016`

## Context

The 2026-09-27 review checked the REV A1 netlist pin by pin against the
datasheets. It found two high findings that had to be settled before ordering
(`I-065`, `I-066`) and three medium ones (`I-067`..`I-069`). REV A1 had a
finished fabrication package in `production/8ch-reva1/`, but it had not been
ordered.

The arithmetic behind every value here is in `CALCULATIONS.md` section 4.

## Decisions

### I-065 — both fixes: (a) R61 2k2 and (b) isolators without the F suffix

Neither fix does the job alone:

* **(b) alone** keeps every CS deselected in reset, because ISO776x without F
  drives an open input HIGH (ISO7761 datasheet, function table). But U11's MISO
  output is still push-pull and still wired straight to the AVR's MISO, so
  ISP still fights it.
* **(a) alone** lets ISP work. But with F parts all eight MAX31856 would still
  be selected while the AVR sits in reset. They would then receive the ISP's
  SCK/MOSI traffic as register writes and drive MISO_SENS against each other.

So both. (b) costs nothing: same package, same pinout, same datasheet. It also
makes the isolators agree with R17-R24, the CS pull-ups that were already
there "so CS defaults high". (a) is one 0805.

**R61 = 2k2, not the 1k first proposed.** The ISO7761 recommends at most
4 mA of output current at 5 V. 1k would allow 5 mA of contention, 2k2 allows
2.3 mA. The cost is 33 ns of RC delay on a 500 kHz SPI and 0.5 V on MISO against
the AVR's pull-up. Both are far inside the limits.

Rejected: **pull-ups on CS1-8_CTRL**. Eight parts, where a part-number change does
the same thing. **Programming only in an external programmer**: it works because
U1 is socketed, but it leaves the reset-state contention and makes every
firmware update a board-out job.

### I-066 — Q1 becomes a BSS131 (240 V, SOT-23)

Q1's drain sits at the battery rail whenever the relay is off. A shorted Q1
energises the relay with no MCU, which is RUN_PERMIT granted by a dead part.
So Q1 must survive the worst voltage D2 lets through, 96.8 V.

| Candidate | V(BR)DSS | Against 96.8 V | Verdict |
|---|---|---|---|
| 2N7000 (fitted) | 60 V | below D2's 66.7 V minimum breakdown | the finding |
| BSS123 | 100 V | 3 % margin | rejected: the margin is thin exactly where the failure is unsafe |
| **BSS131** (Infineon, AEC-Q101) | **240 V** | **2.5x** | **chosen**: VGS(th) at most 1.8 V, RDS(on) at most 20 Ohm at 4.5 V, which is 0.33 V at 16.7 mA |
| BSS127 | 600 V | - | rejected: 21-70 mA and 160-600 Ohm, too weak for the coil |

The cost is about $0.10 against $0.02. One real cost: the BSS131 is ESD Class 0.
It is only exposed through R30 from the MCU, but it needs ESD handling at
assembly. No TO-92 part of this rating was sought: the package change is free,
because the board is regenerated for R61 anyway.

### I-067 — R53/R54 become 100k/22k

Same 4.3 V at 24 V (4.22 V before). At a 58 V dump the current into PC2's clamp
falls from 1.2 mA to 0.28 mA, under the ~1 mA Microchip allows. The input still
reads a valid high down to 16.6 V (17.0 V before). Rejected: **a clamp diode at
PC2**. It works too, but it is a part, where changing two values does the same.

### I-068 — F1 becomes 1812L075/60GR (60 V, 0.75 A hold, 1812)

60 V covers the 58 V suppressed load dump, the design basis of `0016`. The
0.75 A hold still holds the 0.39 A cranking-floor current up to 70 °C
(0.45 A), where a 0.5 A part of the same series is down to 0.35 A at 60 °C.
Stock at LCSC is thin (2265) and the maker is LUTE, not Littelfuse. The
Littelfuse-numbered 60 V parts at LCSC were 0.5 A.

The price of the higher hold is that faults between 0.75 A and 1.5 A may
not trip it. A fault after the regulator cannot get there: the LM5164 limits
its own peak current to 1.25-1.75 A at 5 V, which is at most ~0.4 A from 24 V.
A fault before the regulator is a failed TVS or capacitor, and those go on to a
hard short, which trips the PTC (0.2 s at 8 A) and the panel fuse (`0020`).

Rejected: **1812L050/72GR** (72 V, 0.5 A). It has more voltage margin but may trip
while cranking in a warm panel. **Removing F1**: the panel fuse covers the lead,
but not a board fault well below 1 A.

### I-069 — D2 drawn unidirectional, D3 ordered as "M7"

D2 is now `Device:D_Zener`, which shows its polarity on the schematic. The pins
and the footprint are unchanged. D3's value and MPN are now **M7** (MDD, LCSC
`C95872`), the SMA 1N4007. The BOM can no longer be filled with the through-hole
DO-41 part by name. D2's `Manufacturer` now matches its LCSC code (R+O). U12's
description now warns against the "IA0505S-1WR3" of another maker.

### A new revision: REV A2

The circuit changed, and REV A1 has a complete, uploadable package. A board
that says "REV A1" with a different netlist is the fab mix-up waiting to
happen. So: `BOARD_REV = "A2"`, the netlist contract is
`netlist-baseline-reva2.json` (202 / 163 / 647), and the release goes to
`production/8ch-reva2/`. **`production/8ch-reva1/` must not be ordered.**

## How it was done

These are generative changes (`0012`), because a new part and two new
footprints mean re-placing. The schematic changes live in
`hardware/8ch/sch_layout/reva2.py`, which `fixes.py` applies to the label-only
base. `build.py` therefore still reproduces the whole schematic from source.
Then: `kicad-tool pcb sync`, `generate_board.py`, `route.py`, and the gates.
`populate_schematic.py` was updated to match, for the record.

## Consequences

* The board was re-routed from scratch; everything about it is re-verified,
  not inherited from REV A1 (`docs/STATE.md` has the reports).
* `hardware/8ch-2layer/` (parked, `I-025`) is now a revision behind.
* The ISO776x without F and the LUTE PTC have low LCSC stock. That is fine for a
  prototype run; check it before a production order.

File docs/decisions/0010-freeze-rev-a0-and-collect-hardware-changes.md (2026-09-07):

---
status: accepted
date: 2026-09-07
deciders: Zain
---

# Freeze the board at REV A0 and collect hardware changes into REV A1

## Context

A full review on 2026-09-07 found three problems whose fixes touch the board:
a missing crystal (`I-032`), no read-back on the run-permit driver (`I-016`),
and eight silkscreen overlaps plus one dangling via (`I-006`, `I-024`).

The board is already placed, routed, DRC-clean and has Gerbers in
`production/8ch/`. It cost a long session to get there. Nothing in the pipeline
is incremental: `generate_board.py` clears every track, via, zone and drawing,
and `route.py` runs Freerouting from scratch, so **any** board change - even a
silkscreen nudge - means a full regeneration, a fresh route that will not match
the old one, a new DRC run and new Gerbers.

Set against that, none of the three is a defect in what REV A0 does today. The
unit reads eight thermocouples and opens a contact. The crystal matters for
Modbus and for timing determinism; the read-back matters for detecting a failed
relay driver; the silkscreen matters for looks.

## Decision

**REV A0 is frozen.** No agent regenerates the board. The three changes are
collected here as a REV A1 change set, to be applied together in one
regeneration if and when a respin is worth it.

`hardware/8ch/netlist-baseline-reva0.json` records the connectivity REV A0 was
routed from - 167 components, 154 nets, 555 pins. Any schematic edit is checked
against it with `netlist_fingerprint.py`, and a match is the proof that the
board does not need regenerating. That is what allows `I-002` - redrawing the
schematic so a human can read it - to go ahead without touching the PCB.

## The REV A1 change set

Apply all of it at once, or none of it.

### 1. 8 MHz crystal (`I-032`)

`U1` pins 12 and 13 (XTAL1/XTAL2) are unconnected; the ATmega32A runs on its
internal RC oscillator. Add `Y1` (8 MHz, HC-49 or 3225 SMD) with two 22 pF
load capacitors to `GND_CTRL`, close to the pins.

Then in firmware: change `CKSEL` in `firmware/fuses.md` from `0100`
(internal RC 8 MHz) to `1111` with `SUT1..0 = 11` (crystal, 3-8 MHz, slowly
rising power), making the low fuse `0x3F` instead of `0x24`.

### 2. Run-permit driver read-back (`I-016`)

A divider from the `Q1` drain (`RELAY_LOW`, which swings 0 V to +24 V) to
`PC2`, currently `SPARE_PC2`:

- `R53` 22 k from `RELAY_LOW` to a new net `RUN_PERMIT_SENSE`
- `R54` 4.7 k from `RUN_PERMIT_SENSE` to `GND_CTRL`

At +24 V that gives about 4.2 V at the pin - a valid logic high on the 5 V
rail with margin under VCC. Both are `CONTROL` island nets, so the isolation
rules are unaffected.

The firmware is already written and waiting. `hal/run_permit.c` implements the
check; `mcal/board.h` defines `BOARD_HAS_RUN_PERMIT_SENSE`, which is `0`.
**Set it to `1` in the same commit that adds the divider** - not before. On
REV A0 the pin is unconnected and reading it would invent drive faults out of
noise.

JTAG must also be disabled (high fuse `0xD1`, already specified) or `PC2` is
a JTAG pin and reads a constant.

### 3. Silkscreen and the dangling via (`I-006`, `I-024`)

Nine DRC warnings, all cosmetic: six silkscreen overlaps, two silkscreen over
pads, one via on `+3V3_SENS` at (67.80, 25.92) that reaches the plane and
nothing else. They ride along with the respin because they cost nothing once
the board is being regenerated anyway, and are not worth a regeneration on
their own.

## Consequences

**`R-9` (Modbus RTU over RS-485) is deferred.** The ATmega32A's internal RC is
specified to a few percent over voltage and temperature, which is outside what
an asynchronous 8-bit UART frame tolerates. The RS-485 hardware on the board is
complete and correct - `U15` (ADM2587E), termination and bias jumpers, the
isolated island - but a Modbus master will see frame errors that come and go
with panel temperature. `R-9` is not achievable on REV A0 and `docs/GOAL.md`
records it as deferred rather than ready.

**The trip time depends on an RC oscillator.** The calculated worst case is
623 ms against a 1 s requirement (`firmware/include/app/app_config.h`), so
there is margin for the oscillator's drift. It is still a protection device
whose timebase is not a crystal, and that belongs on the record.

**`I-016` stays open.** The unit cannot detect a welded or failed relay driver.

**The prototype is honest about what it is.** REV A0 is an engineering
prototype for bench and site evaluation, not a product build. Freezing it does
not make it more finished than it is; the open issues say what is missing.

## Rejected

**Respin now.** Rejected by the project owner. The board works for what it has
to do next - be built and evaluated - and a respin buys nothing until that
evaluation has happened. Measuring the barrier (`I-004`), the isolated
converter output (`I-003`) and the real trip time (`I-013`) may well produce
more REV A1 changes, and doing one respin that includes those is better than
two.

**Apply only the silkscreen fixes.** Rejected: the regeneration cost is the
same whether one warning is fixed or all nine, and a re-route that nobody
needed is a fresh chance to introduce something worse.

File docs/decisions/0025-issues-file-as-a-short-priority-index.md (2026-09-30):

# 0025 — ISSUES.md is a short priority index; closed issues live in their own file

* Status: accepted
* Date: 2026-10-01
* Deciders: owner, with the agent's recommendation
* Relates to: `I-056`, `0001`

## Context

The "one line per issue" rule existed so the file would not grow unreadable.
It did not hold. By 2026-09-30 `ISSUES.md` was **72 KB**:

* 94 rows, one of them 7.7 KB (`I-028`);
* four narrative sections from the 2026-09-29 review;
* open and closed issues mixed, and no order of importance.

An agent reads a file that size partly or not at all, which is the failure the
rule was meant to prevent. The owner asked which is right: long rows that
explain everything, or short rows.

An agent does not need the explanation in the row. It needs enough to know
what is wrong and how much it matters, plus where to look. It follows the
pointer when it works on the issue. Long text in the index costs every reader,
every session, for the benefit of the one who works on that row.

## Decision

* `ISSUES.md` holds **open issues only**, grouped by priority:
  * **P0** blocks the order;
  * **P1** before a unit protects a machine;
  * **P2** measured at the bench;
  * **P3** later or accepted.
* Each row is at most about 600 characters: what, why, evidence pointer, close-when.
* Detail goes where it belongs: arithmetic to `CALCULATIONS.md`, choices to
  `decisions/`, logs to `production/review-*/`.
* Closed issues move to **`ISSUES-closed.md`**. It is an archive, read only when
  an old number comes up.
* A finding judged overstated **keeps its row**, marked "Review weight: rated X,
  agreed Y" with the reason. Disagreement is visible, never silent.
* No narrative sections. What a review could not verify becomes one bullet
  under "Not verified by anyone yet".

Result on 2026-10-01: 72 KB → about 11 KB. The pre-restructure text is in git
history (`7107a94`) and, for the uncommitted 2026-09-29 review, in
`production/review-20260929/ISSUES-as-reviewed-20260929.md`.

## Rejected

* **Keep long rows "so every agent understands"**: this is what produced 72 KB.
  The explanation is still one pointer away.
* **One file per issue**: `0001` rejected a scatter of small files, because a
  list you cannot see at once is not an index.
* **Delete closed issues**: their "what fixed it" is how a regression gets
  recognised.

## Consequences

* A new agent reads `AGENTS.md`, `STATE.md` and then all of `ISSUES.md`, which
  is now possible in one read.
* Anyone adding a row keeps it short. A row that needs more has a missing
  calculation or decision file.

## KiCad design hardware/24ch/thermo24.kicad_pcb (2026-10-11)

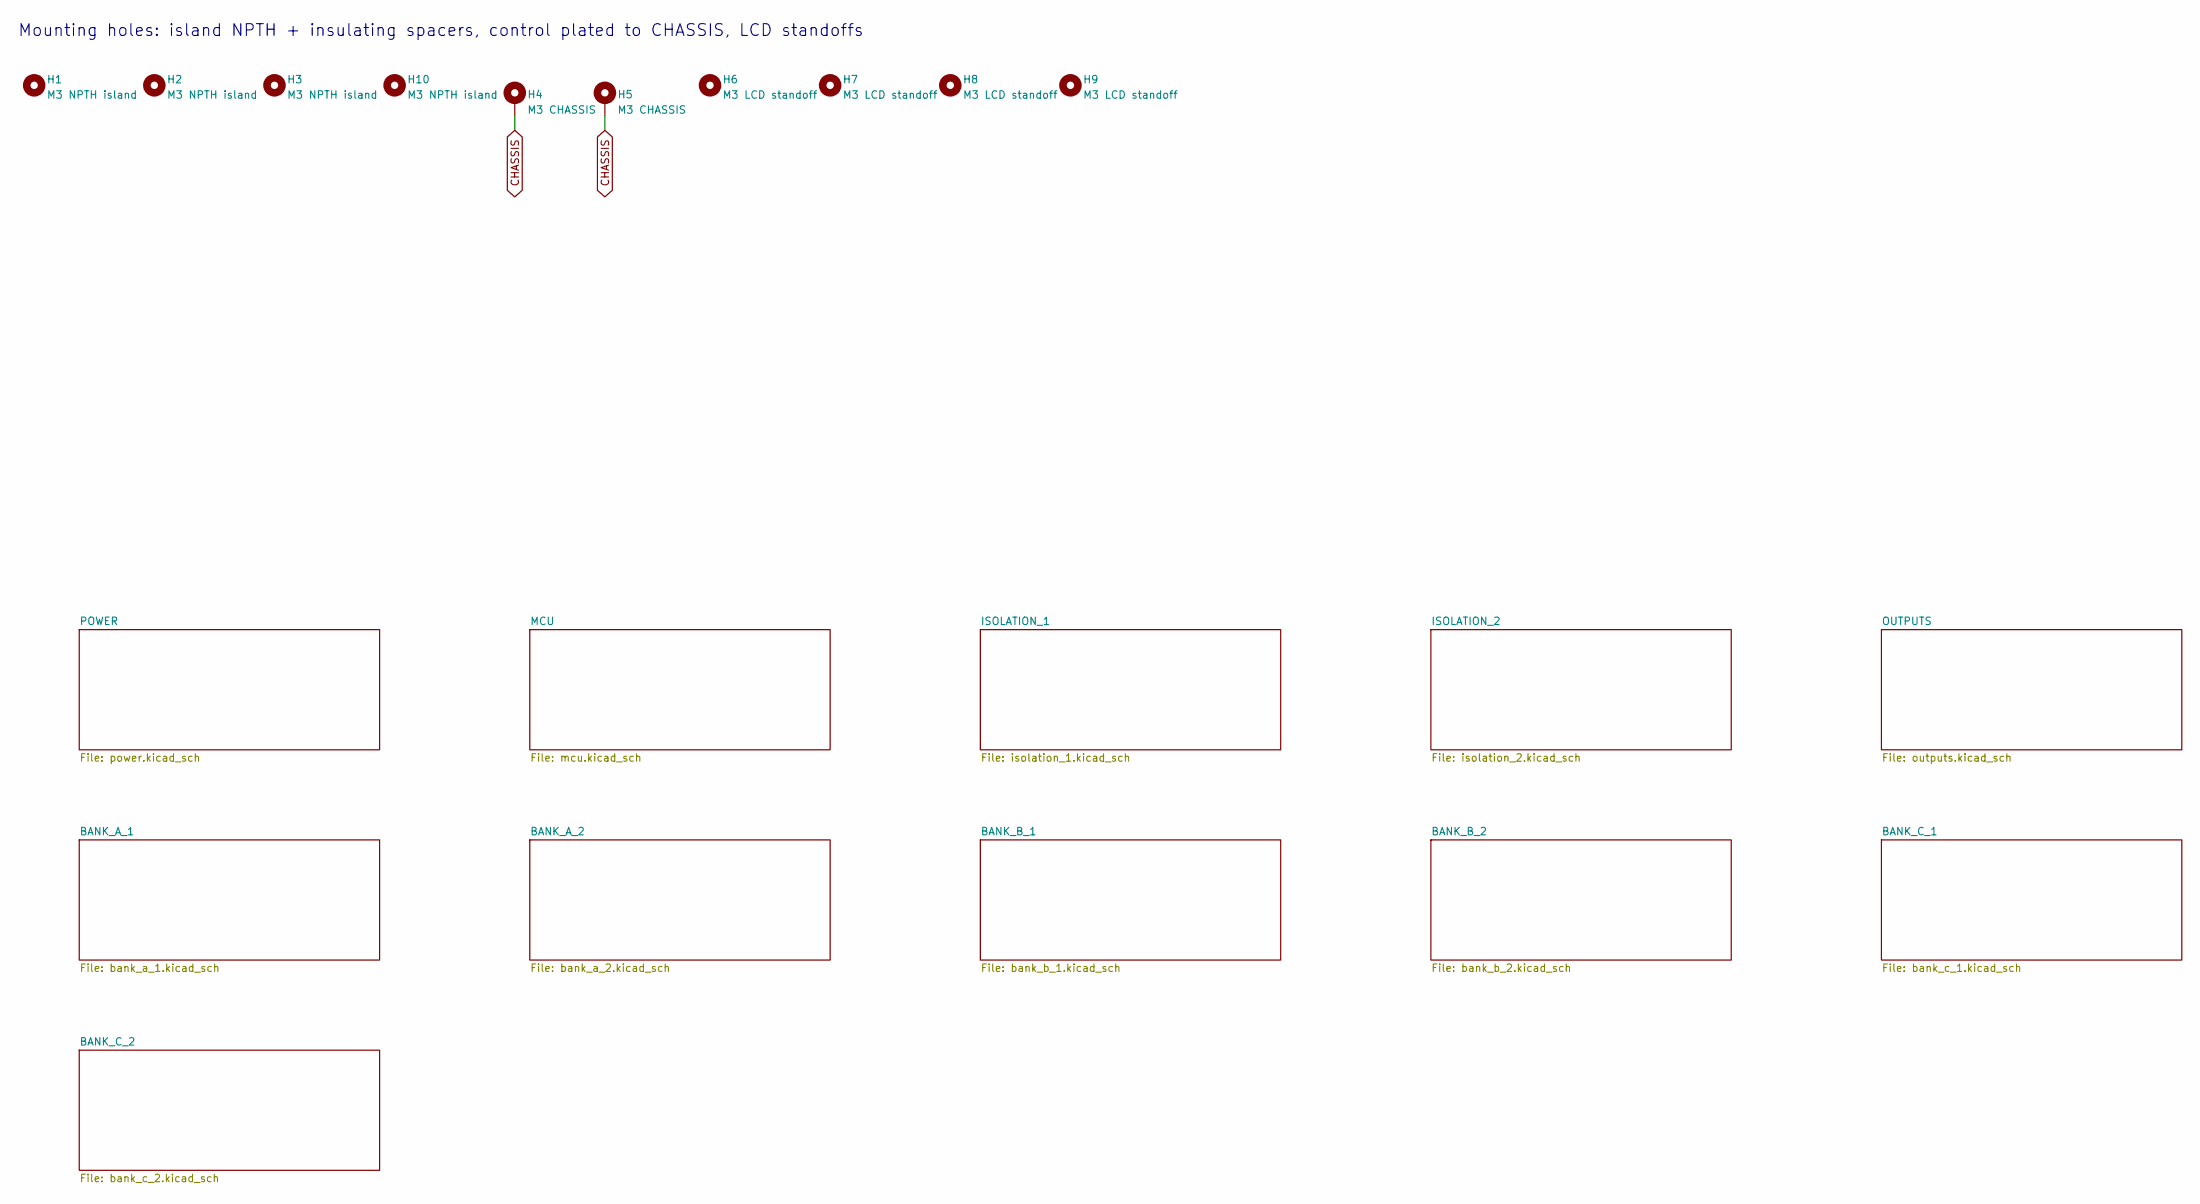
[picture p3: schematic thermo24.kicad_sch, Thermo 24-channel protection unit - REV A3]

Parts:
H1, H2, H3, H10: M3 NPTH island; MountingHole_3.2mm_M3
H4, H5: M3 CHASSIS; MountingHole_3.2mm_M3_Pad
H6, H7, H8, H9: M3 LCD standoff; MountingHole_3.2mm_M3

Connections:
CHASSIS: H4.1 (1_1), H5.1 (1_1); also elsewhere on the board

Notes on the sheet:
Mounting holes: island NPTH + insulating spacers, control plated to CHASSIS, LCD standoffs

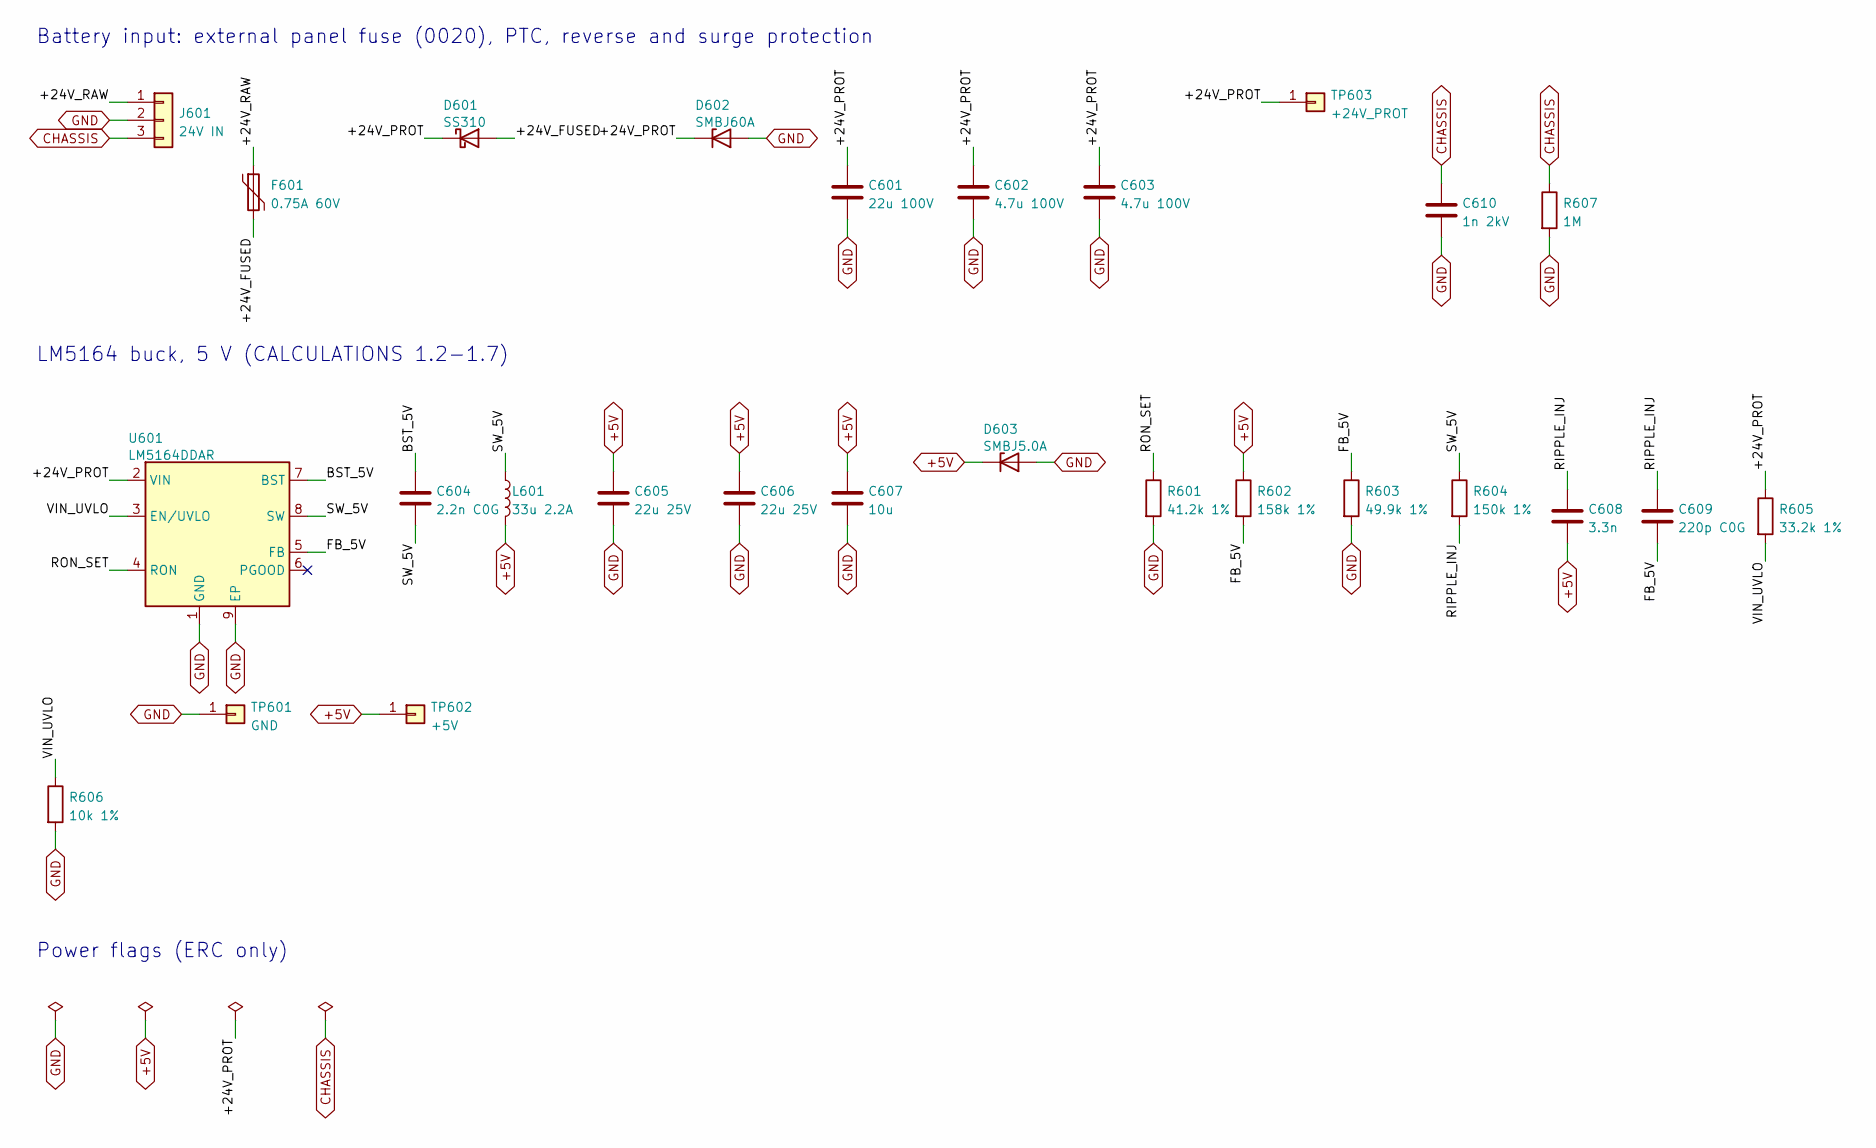
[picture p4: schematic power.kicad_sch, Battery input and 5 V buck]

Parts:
C601: 22u 100V; CP_Radial_D8.0mm_P3.50mm; MPN 100YXF22MEFC8X11.5; LCSC C88838
C602, C603: 4.7u 100V; C_1210_3225Metric; MPN FS32X475K101EGG; LCSC C381466
C604: 2.2n C0G; C_0805_2012Metric; MPN CL21C222JBFNNNE; LCSC C28260
C605, C606: 22u 25V; C_1210_3225Metric; MPN CL32B226KAJNNNE; LCSC C309062
C607: 10u; C_0805_2012Metric; MPN CL21B106KOQNNNE; LCSC C95841
C608: 3.3n; C_0805_2012Metric; MPN 0805B332K500NT; LCSC C1738
C609: 220p C0G; C_0805_2012Metric; MPN CC0805JRNPO0BN221; LCSC C113819
C610: 1n 2kV; C_1206_3216Metric; MPN 1206B102K202NT; LCSC C9196
D601: SS310; D_SMA; MPN SS310; LCSC C15874
D602: SMBJ60A; D_SMB; MPN SMBJ60A; LCSC C49066953
D603: SMBJ5.0A; D_SMB; MPN SMBJ5.0A; LCSC C83333
F601: 0.75A 60V; Fuse_2920_7451Metric; MPN MF-SM075/60-2; LCSC C210842
J601: 24V IN; TerminalBlock_Phoenix_MKDS-1,5-3_1x03_P5.00mm_Horizontal; MPN WJ128V-5.0-3P; LCSC C8270
L601: 33u 2.2A; L_10.4x10.4_H4.8; MPN SMDRH104R-330MT; LCSC C9936
R601: 41.2k 1%; R_0805_2012Metric; MPN FRC0805F4122TS; LCSC C2933440
R602: 158k 1%; R_0805_2012Metric; MPN RT0805BRD07158KL; LCSC C865205
R603: 49.9k 1%; R_0805_2012Metric; MPN 0805W8F4992T5E; LCSC C17719
R604: 150k 1%; R_0805_2012Metric; MPN 0805W8F1503T5E; LCSC C17470
R605: 33.2k 1%; R_0805_2012Metric; MPN FRC0805F3322TS; LCSC C2933418
R606: 10k 1%; R_0805_2012Metric; MPN 0805W8F1002T5E; LCSC C17414
R607: 1M; R_1206_3216Metric; MPN 1206W4F1004T5E; LCSC C17927
TP601: GND; TestPoint_THTPad_D2.0mm_Drill1.0mm
TP602: +5V; TestPoint_THTPad_D2.0mm_Drill1.0mm
TP603: +24V_PROT; TestPoint_THTPad_D2.0mm_Drill1.0mm
U601: LM5164DDAR; HSOP-8-1EP_3.9x4.9mm_P1.27mm_EP2.41x3.1mm; MPN LM5164DDAR; LCSC C477928

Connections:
+5V: C605.1, C606.1, C607.1, C608.2, D603.1 (K), L601.2, R602.1, TP602.1 (Pin_1_1); also elsewhere on the board
/POWER/+24V_FUSED: D601.2 (A), F601.2
/POWER/+24V_PROT: C601.1, C602.1, C603.1, D601.1 (K), D602.1 (K), R605.1, TP603.1 (Pin_1_1), U601.2 (VIN)
/POWER/+24V_RAW: F601.1, J601.1
/POWER/BST_5V: C604.1, U601.7 (BST)
/POWER/FB_5V: C609.2, R602.2, R603.1, U601.5 (FB)
/POWER/RIPPLE_INJ: C608.1, C609.1, R604.2
/POWER/RON_SET: R601.1, U601.4 (RON)
/POWER/SW_5V: C604.2, L601.1, R604.1, U601.8 (SW)
/POWER/VIN_UVLO: R605.2, R606.1, U601.3 (EN/UVLO)
CHASSIS: C610.1, J601.3, R607.1; also elsewhere on the board
GND: C601.2, C602.2, C603.2, C605.2, C606.2, C607.2, C610.2, D602.2 (A), D603.2 (A), J601.2, R601.2, R603.2, R606.2, R607.2, TP601.1 (Pin_1_1), U601.1 (GND), U601.9 (EP); also elsewhere on the board

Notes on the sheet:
Battery input: external panel fuse (0020), PTC, reverse and surge protection
LM5164 buck, 5 V (CALCULATIONS 1.2-1.7)
Power flags (ERC only)

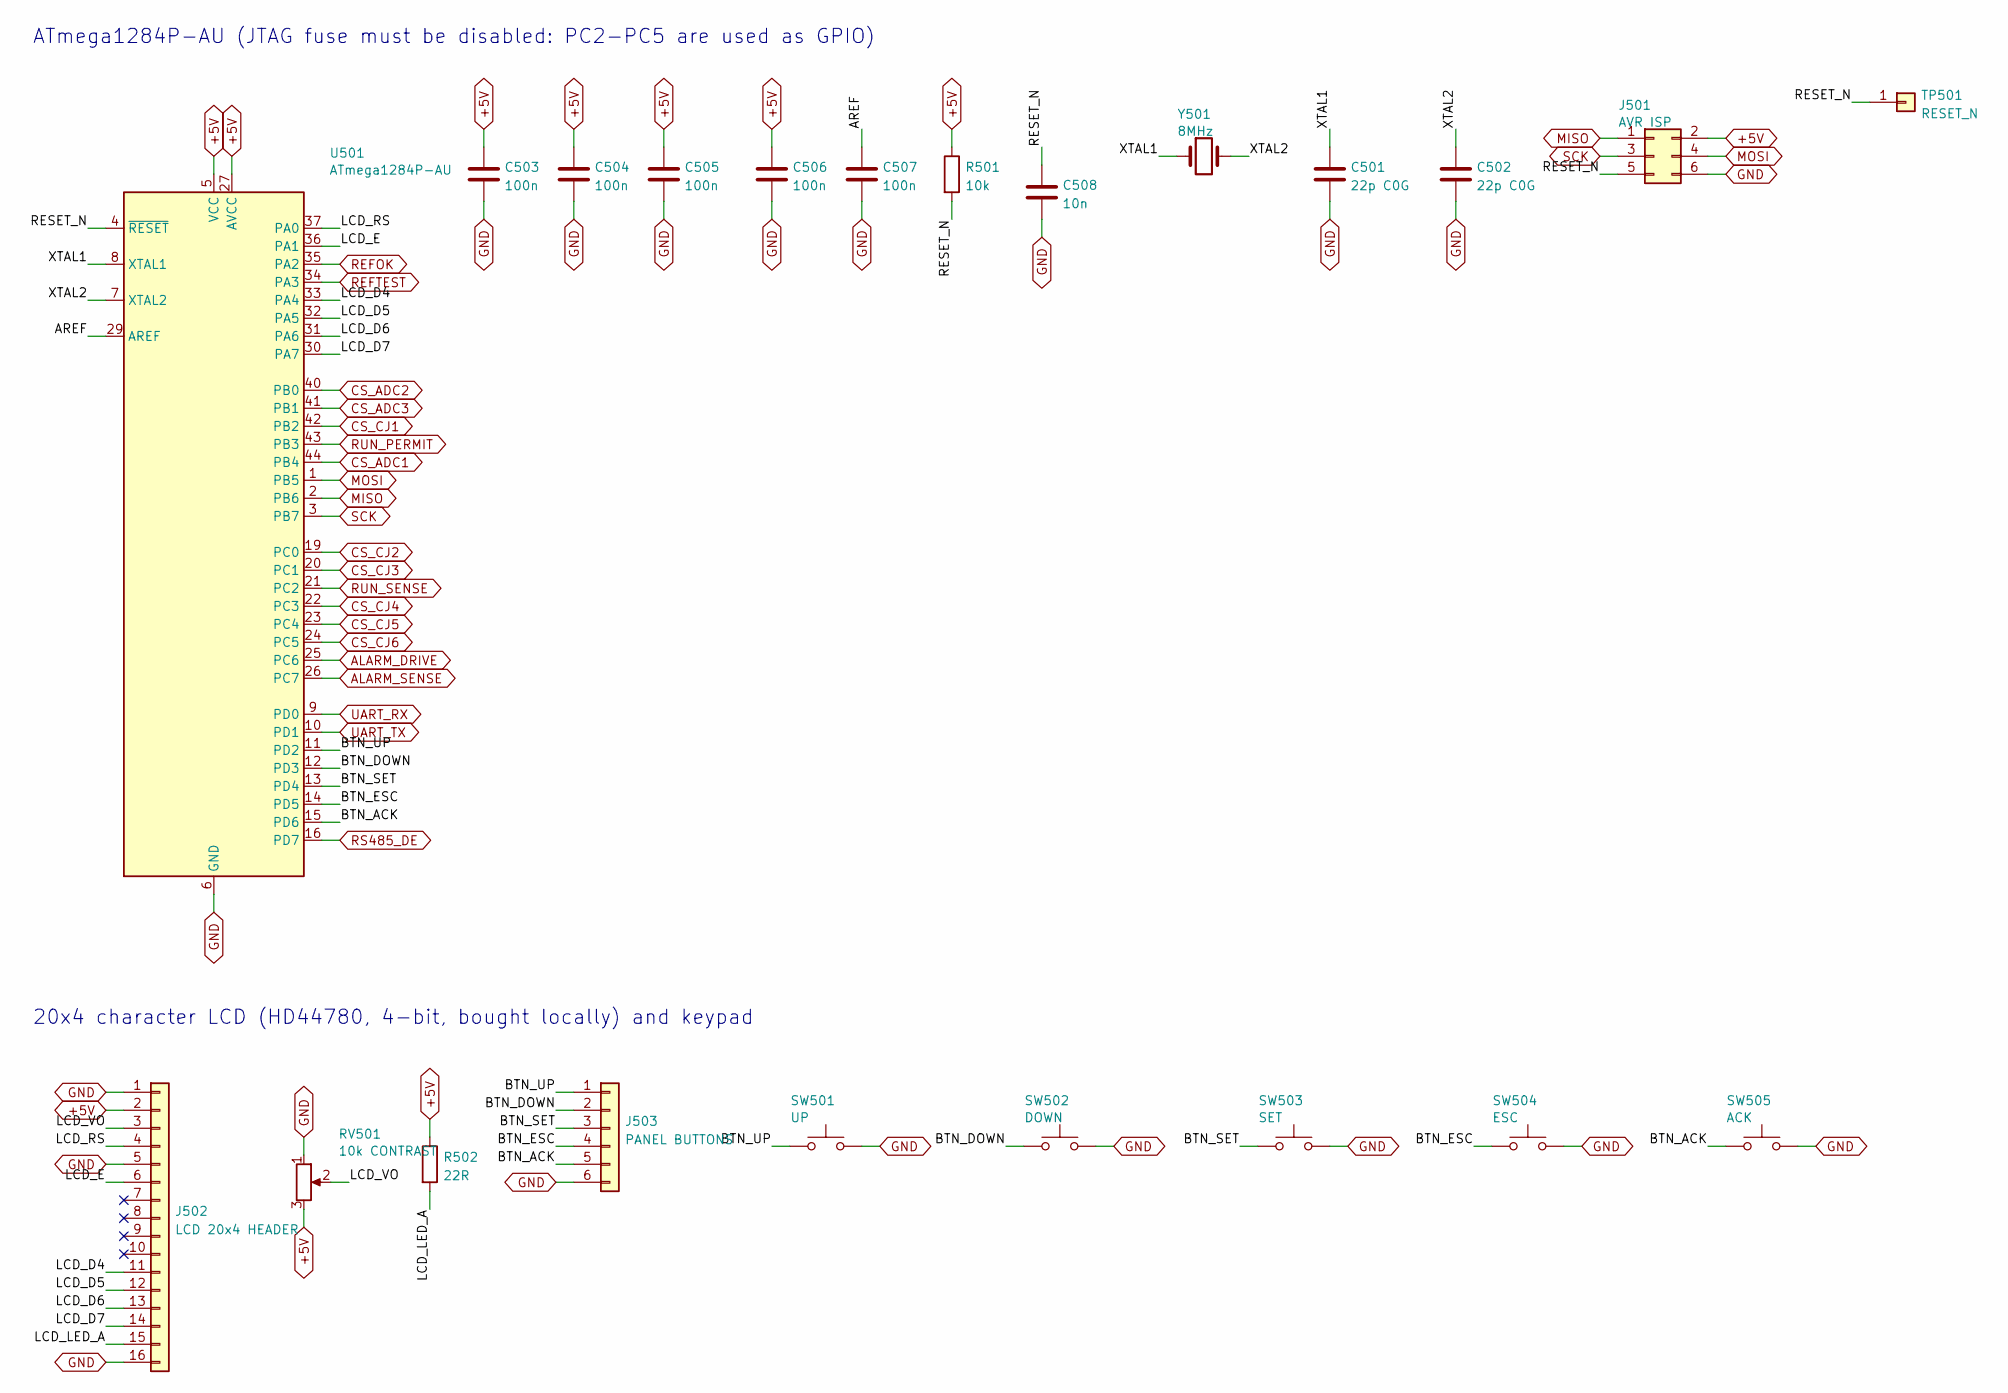
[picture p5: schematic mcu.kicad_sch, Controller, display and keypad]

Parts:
C501, C502: 22p C0G; C_0805_2012Metric; MPN CL21C220JBANNNC; LCSC C1804
C503, C504, C505, C506, C507: 100n; C_0805_2012Metric; MPN CC0805KRX7R9BB104; LCSC C49678
C508: 10n; C_0805_2012Metric; MPN CL21B103KBANNNC; LCSC C1710
J501: AVR ISP; PinHeader_2x03_P2.54mm_Vertical; MPN PZ254V-12-6P; LCSC C492420
J502: LCD 20x4 HEADER; PinHeader_1x16_P2.54mm_Vertical; MPN ZX-PZ2.54-1-16PZZ; LCSC C7501270
J503: PANEL BUTTONS; JST_XH_B6B-XH-A_1x06_P2.50mm_Vertical; MPN B6B-XH-A(LF)(SN); LCSC C144397
R501: 10k; R_0805_2012Metric; MPN 0805W8F1002T5E; LCSC C17414
R502: 22R; R_1206_3216Metric; MPN 1206W4F220JT5E; LCSC C17958
RV501: 10k CONTRAST; Potentiometer_Bourns_3296W_Vertical; MPN 3296W-1-103LF; LCSC C34846
SW501: UP; SW_PUSH_6mm; MPN ZX-QC66-9.5CJ; LCSC C7470135
SW502: DOWN; SW_PUSH_6mm; MPN ZX-QC66-9.5CJ; LCSC C7470135
SW503: SET; SW_PUSH_6mm; MPN ZX-QC66-9.5CJ; LCSC C7470135
SW504: ESC; SW_PUSH_6mm; MPN ZX-QC66-9.5CJ; LCSC C7470135
SW505: ACK; SW_PUSH_6mm; MPN ZX-QC66-9.5CJ; LCSC C7470135
TP501: RESET_N; TestPoint_THTPad_D2.0mm_Drill1.0mm
U501: ATmega1284P-AU; TQFP-44_10x10mm_P0.8mm; MPN ATMEGA1284P-AU; LCSC C33575
Y501: 8MHz; Crystal_SMD_HC49-SD; MPN X49SM8MSD2SC; LCSC C12674

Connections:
+5V: C503.1, C504.1, C505.1, C506.1, J501.2, J502.2, R501.1, R502.1, RV501.3, U501.5 (VCC), U501.17 (VCC), U501.27 (AVCC), U501.38 (VCC); also elsewhere on the board
/MCU/AREF: C507.1, U501.29 (AREF)
/MCU/BTN_ACK: J503.5, SW505.1, U501.15 (PD6)
/MCU/BTN_DOWN: J503.2, SW502.1, U501.12 (PD3)
/MCU/BTN_ESC: J503.4, SW504.1, U501.14 (PD5)
/MCU/BTN_SET: J503.3, SW503.1, U501.13 (PD4)
/MCU/BTN_UP: J503.1, SW501.1, U501.11 (PD2)
/MCU/LCD_D4: J502.11, U501.33 (PA4)
/MCU/LCD_D5: J502.12, U501.32 (PA5)
/MCU/LCD_D6: J502.13, U501.31 (PA6)
/MCU/LCD_D7: J502.14, U501.30 (PA7)
/MCU/LCD_E: J502.6, U501.36 (PA1)
/MCU/LCD_LED_A: J502.15, R502.2
/MCU/LCD_RS: J502.4, U501.37 (PA0)
/MCU/LCD_VO: J502.3, RV501.2
/MCU/RESET_N: C508.1, J501.5, R501.2, TP501.1 (Pin_1_1), U501.4 (~RESET)
/MCU/XTAL1: C501.1, U501.8 (XTAL1), Y501.1
/MCU/XTAL2: C502.1, U501.7 (XTAL2), Y501.2
ALARM_DRIVE: U501.25 (PC6); also elsewhere on the board
ALARM_SENSE: U501.26 (PC7); also elsewhere on the board
CS_ADC1: U501.44 (PB4); also elsewhere on the board
CS_ADC2: U501.40 (PB0); also elsewhere on the board
CS_ADC3: U501.41 (PB1); also elsewhere on the board
CS_CJ1: U501.42 (PB2); also elsewhere on the board
CS_CJ2: U501.19 (PC0); also elsewhere on the board
CS_CJ3: U501.20 (PC1); also elsewhere on the board
CS_CJ4: U501.22 (PC3); also elsewhere on the board
CS_CJ5: U501.23 (PC4); also elsewhere on the board
CS_CJ6: U501.24 (PC5); also elsewhere on the board
GND: C501.2, C502.2, C503.2, C504.2, C505.2, C506.2, C507.2, C508.2, J501.6, J502.1, J502.5, J502.16, J503.6, RV501.1, SW501.2, SW502.2, SW503.2, SW504.2, SW505.2, U501.6 (GND), U501.18 (GND), U501.28 (GND), U501.39 (GND); also elsewhere on the board
MISO: J501.1, U501.2 (PB6); also elsewhere on the board
MOSI: J501.4, U501.1 (PB5); also elsewhere on the board
REFOK: U501.35 (PA2); also elsewhere on the board
REFTEST: U501.34 (PA3); also elsewhere on the board
RS485_DE: U501.16 (PD7); also elsewhere on the board
RUN_PERMIT: U501.43 (PB3); also elsewhere on the board
RUN_SENSE: U501.21 (PC2); also elsewhere on the board
SCK: J501.3, U501.3 (PB7); also elsewhere on the board
UART_RX: U501.9 (PD0); also elsewhere on the board
UART_TX: U501.10 (PD1); also elsewhere on the board

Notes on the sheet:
ATmega1284P-AU (JTAG fuse must be disabled: PC2-PC5 are used as GPIO)
20x4 character LCD (HD44780, 4-bit, bought locally) and keypad

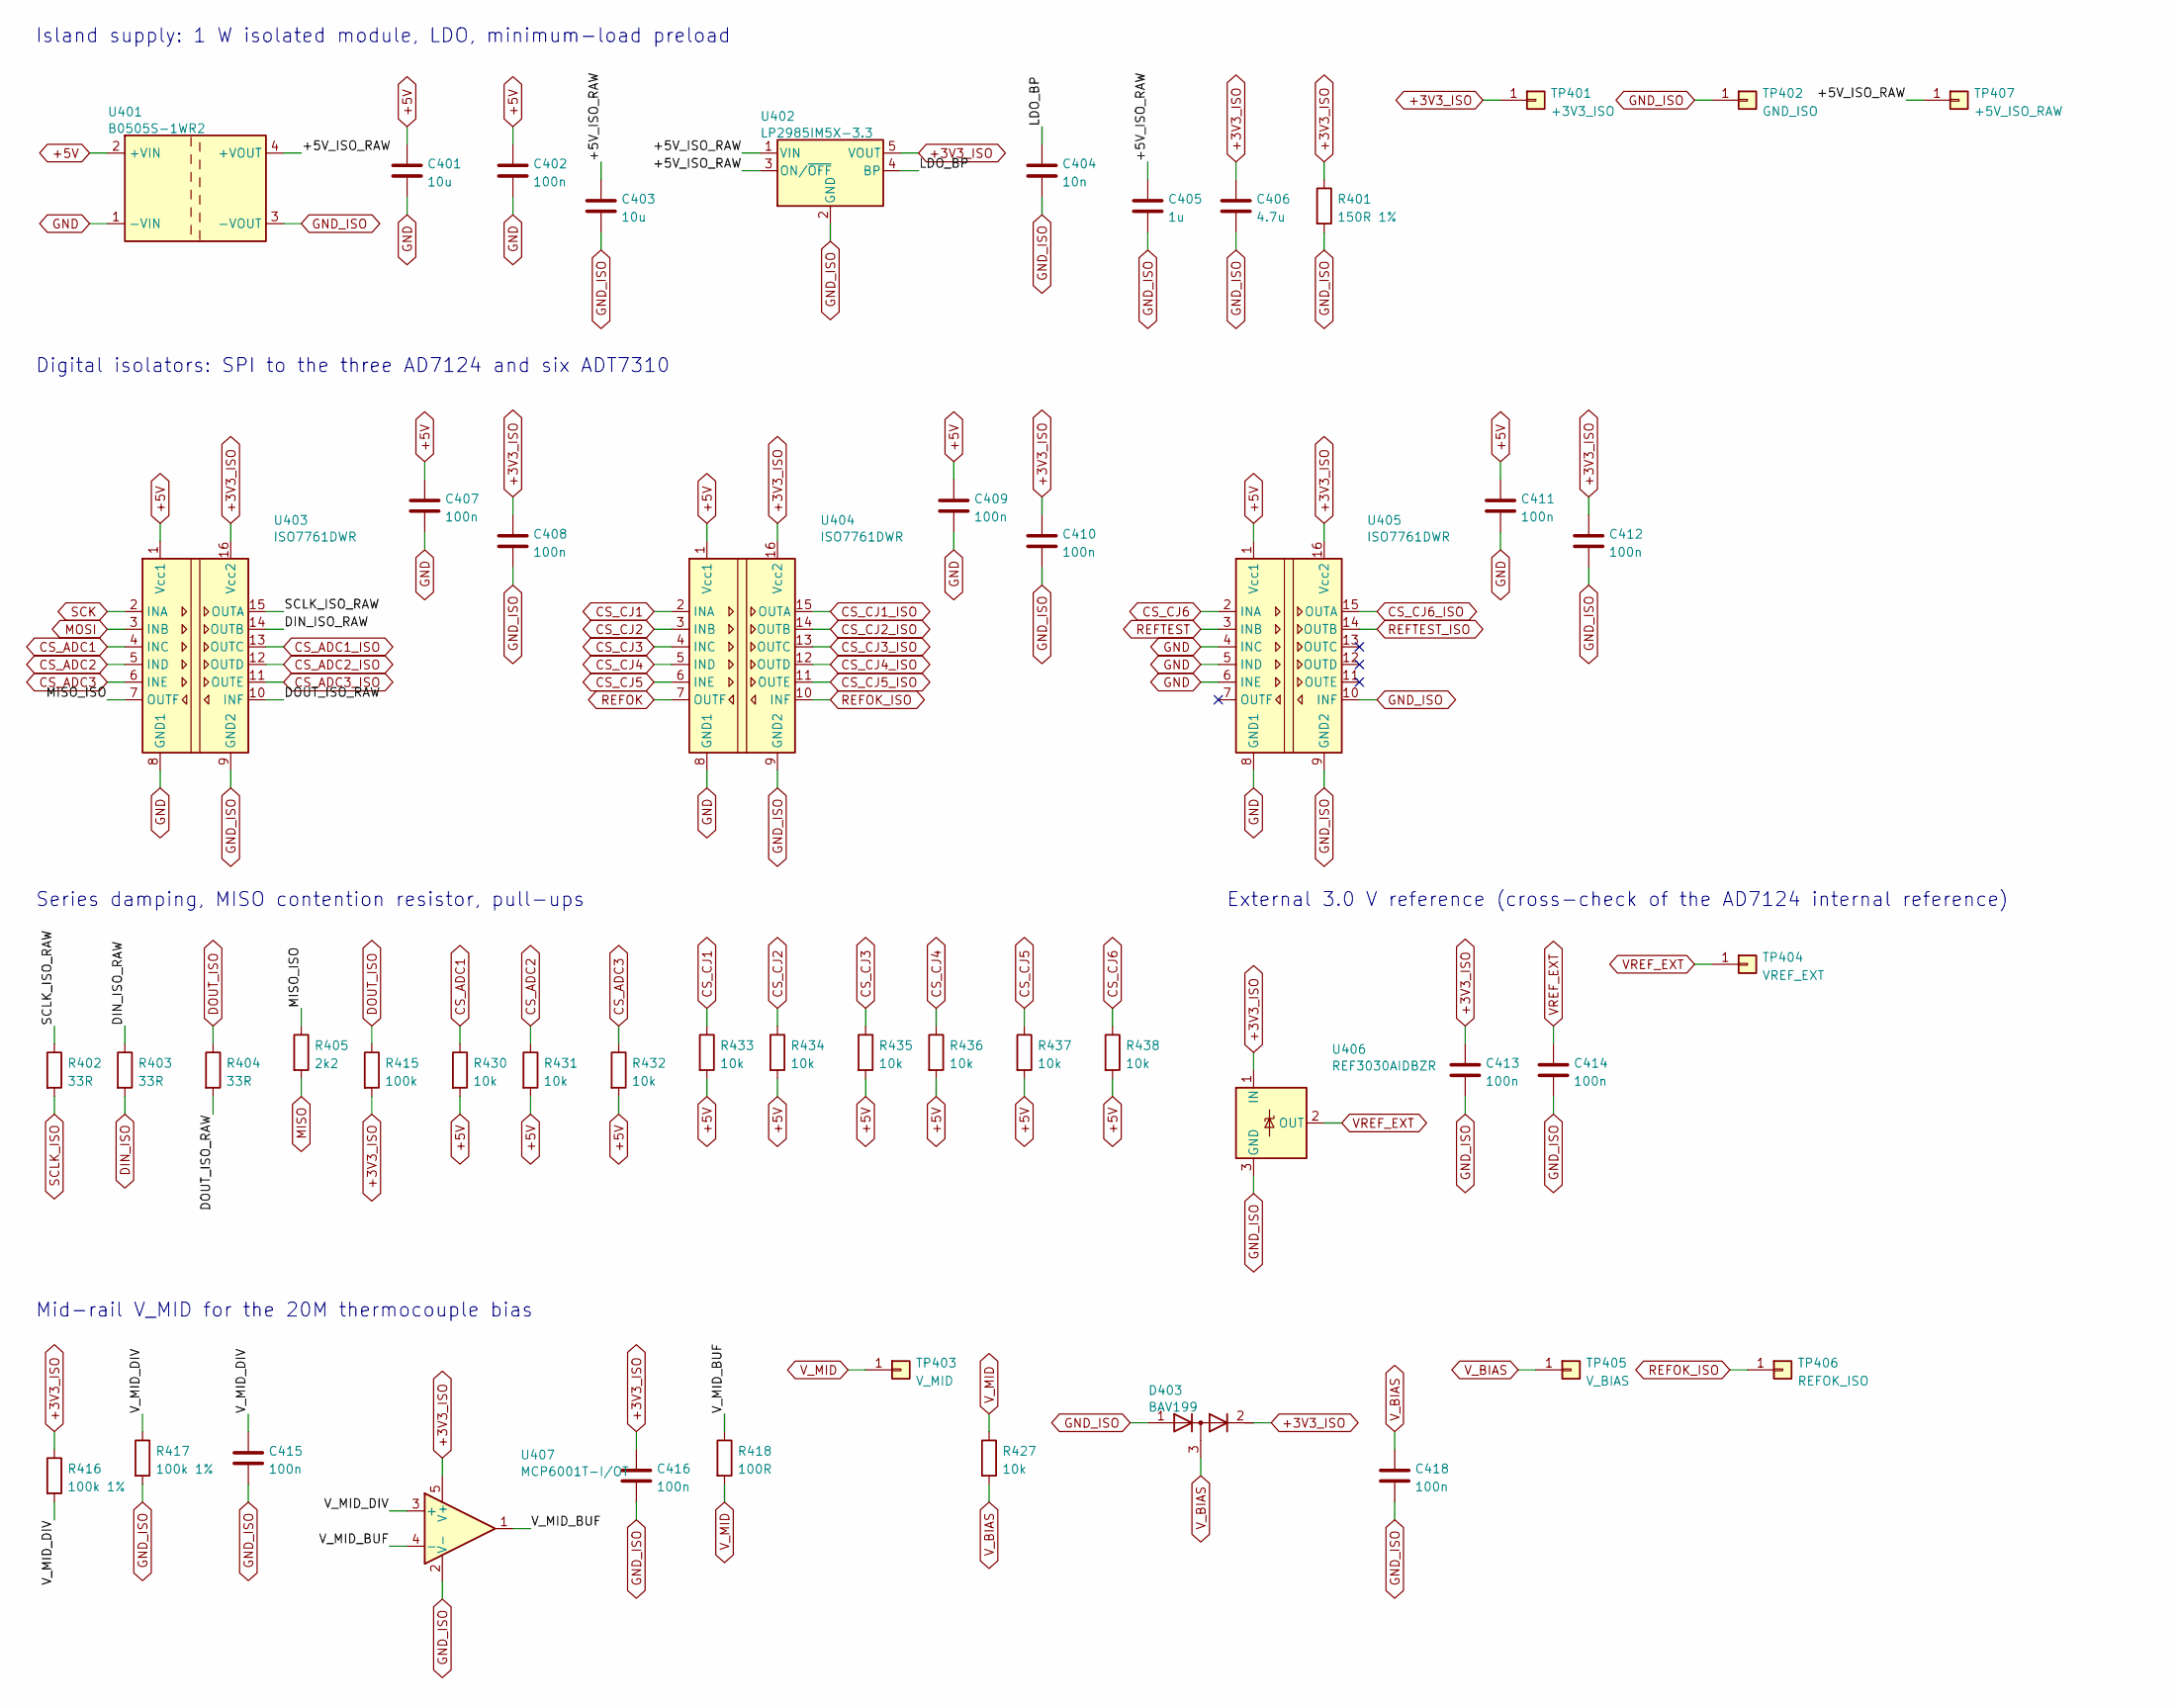
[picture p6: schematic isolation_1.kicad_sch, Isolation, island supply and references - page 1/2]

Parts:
C401, C403: 10u; C_0805_2012Metric; MPN CL21A106KAYNNNE; LCSC C15850
C402, C407, C408, C409, C410, C411, C412, C413, C414, C415, C416, C418: 100n; C_0805_2012Metric; MPN CC0805KRX7R9BB104; LCSC C49678
C404: 10n; C_0805_2012Metric; MPN CL21B103KBANNNC; LCSC C1710
C405: 1u; C_0805_2012Metric; MPN CL21B105KBFNNNE; LCSC C28323
C406: 4.7u; C_0805_2012Metric; MPN CGA0805X7R475K350MT; LCSC C6119943
D403: BAV199; SOT-23; MPN BAV199,215; LCSC C40919
R401: 150R 1%; R_1206_3216Metric; MPN 1206W4F1500T5E; LCSC C17917
R402, R403, R404: 33R; R_0805_2012Metric; MPN 0805W8F330JT5E; LCSC C17634
R405: 2k2; R_0805_2012Metric; MPN 0805W8F2201T5E; LCSC C17520
R415: 100k; R_0805_2012Metric; MPN 0805W8F1003T5E; LCSC C149504
R416, R417: 100k 1%; R_0805_2012Metric; MPN 0805W8F1003T5E; LCSC C149504
R418: 100R; R_0805_2012Metric; MPN 0805W8F1000T5E; LCSC C17408
R427, R430, R431, R432, R433, R434, R435, R436, R437, R438: 10k; R_0805_2012Metric; MPN 0805W8F1002T5E; LCSC C17414
TP401: +3V3_ISO; TestPoint_THTPad_D2.0mm_Drill1.0mm
TP402: GND_ISO; TestPoint_THTPad_D2.0mm_Drill1.0mm
TP403: V_MID; TestPoint_THTPad_D2.0mm_Drill1.0mm
TP404: VREF_EXT; TestPoint_THTPad_D2.0mm_Drill1.0mm
TP405: V_BIAS; TestPoint_THTPad_D2.0mm_Drill1.0mm
TP406: REFOK_ISO; TestPoint_THTPad_D2.0mm_Drill1.0mm
TP407: +5V_ISO_RAW; TestPoint_THTPad_D2.0mm_Drill1.0mm
U401: B0505S-1WR2; Converter_DCDC_Murata_CRE1xxxxxxSC_THT; MPN B0505S-1WR2; LCSC C2992393
U402: LP2985IM5X-3.3; SOT-23-5; MPN LP2985IM5X-3.3/NOPB; LCSC C129375
U403, U404, U405: ISO7761DWR; SOIC-16W_7.5x10.3mm_P1.27mm; MPN ISO7761DWR; LCSC C2871529
U406: REF3030AIDBZR; SOT-23; MPN REF3030AIDBZR; LCSC C38423
U407: MCP6001T-I/OT; SOT-23-5; MPN MCP6001T-I/OT; LCSC C116490

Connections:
+3V3_ISO: C406.1, C408.1, C410.1, C412.1, C413.1, C416.1, D403.2 (K), R401.1, R415.2, R416.1, TP401.1 (Pin_1_1), U402.5 (VOUT), U403.16 (Vcc2), U404.16 (Vcc2), U405.16 (Vcc2), U406.1 (IN), U407.5 (V+); also elsewhere on the board
+5V: C401.1, C402.1, C407.1, C409.1, C411.1, R430.2, R431.2, R432.2, R433.2, R434.2, R435.2, R436.2, R437.2, R438.2, U401.2 (+VIN), U403.1 (Vcc1), U404.1 (Vcc1), U405.1 (Vcc1); also elsewhere on the board
/ISOLATION_1/+5V_ISO_RAW: C403.1, C405.1, TP407.1 (Pin_1_1), U401.4 (+VOUT), U402.1 (VIN), U402.3 (ON/~OFF)
/ISOLATION_1/DIN_ISO_RAW: R403.1, U403.14 (OUTB)
/ISOLATION_1/DOUT_ISO_RAW: R404.2, U403.10 (INF)
/ISOLATION_1/LDO_BP: C404.1, U402.4 (BP)
/ISOLATION_1/MISO_ISO: R405.1, U403.7 (OUTF)
/ISOLATION_1/SCLK_ISO_RAW: R402.1, U403.15 (OUTA)
/ISOLATION_1/V_MID_BUF: R418.1, U407.1, U407.4 (-)
/ISOLATION_1/V_MID_DIV: C415.1, R416.2, R417.1, U407.3 (+)
CS_ADC1: R430.1, U403.4 (INC); also elsewhere on the board
CS_ADC1_ISO: U403.13 (OUTC); also elsewhere on the board
CS_ADC2: R431.1, U403.5 (IND); also elsewhere on the board
CS_ADC2_ISO: U403.12 (OUTD); also elsewhere on the board
CS_ADC3: R432.1, U403.6 (INE); also elsewhere on the board
CS_ADC3_ISO: U403.11 (OUTE); also elsewhere on the board
CS_CJ1: R433.1, U404.2 (INA); also elsewhere on the board
CS_CJ1_ISO: U404.15 (OUTA); also elsewhere on the board
CS_CJ2: R434.1, U404.3 (INB); also elsewhere on the board
CS_CJ2_ISO: U404.14 (OUTB); also elsewhere on the board
CS_CJ3: R435.1, U404.4 (INC); also elsewhere on the board
CS_CJ3_ISO: U404.13 (OUTC); also elsewhere on the board
CS_CJ4: R436.1, U404.5 (IND); also elsewhere on the board
CS_CJ4_ISO: U404.12 (OUTD); also elsewhere on the board
CS_CJ5: R437.1, U404.6 (INE); also elsewhere on the board
CS_CJ5_ISO: U404.11 (OUTE); also elsewhere on the board
CS_CJ6: R438.1, U405.2 (INA); also elsewhere on the board
CS_CJ6_ISO: U405.15 (OUTA); also elsewhere on the board
DIN_ISO: R403.2; also elsewhere on the board
DOUT_ISO: R404.1, R415.1; also elsewhere on the board
GND: C401.2, C402.2, C407.2, C409.2, C411.2, U401.1 (-VIN), U403.8 (GND1), U404.8 (GND1), U405.4 (INC), U405.5 (IND), U405.6 (INE), U405.8 (GND1); also elsewhere on the board
GND_ISO: C403.2, C404.2, C405.2, C406.2, C408.2, C410.2, C412.2, C413.2, C414.2, C415.2, C416.2, C418.2, D403.1 (A), R401.2, R417.2, TP402.1 (Pin_1_1), U401.3 (-VOUT), U402.2 (GND), U403.9 (GND2), U404.9 (GND2), U405.9 (GND2), U405.10 (INF), U406.3 (GND), U407.2 (V-); also elsewhere on the board
MISO: R405.2; also elsewhere on the board
MOSI: U403.3 (INB); also elsewhere on the board
REFOK: U404.7 (OUTF); also elsewhere on the board
REFOK_ISO: TP406.1 (Pin_1_1), U404.10 (INF); also elsewhere on the board
REFTEST: U405.3 (INB); also elsewhere on the board
REFTEST_ISO: U405.14 (OUTB); also elsewhere on the board
SCK: U403.2 (INA); also elsewhere on the board
SCLK_ISO: R402.2; also elsewhere on the board
VREF_EXT: C414.1, TP404.1 (Pin_1_1), U406.2 (OUT); also elsewhere on the board
V_BIAS: C418.1, D403.3 (common), R427.2, TP405.1 (Pin_1_1); also elsewhere on the board
V_MID: R418.2, R427.1, TP403.1 (Pin_1_1); also elsewhere on the board

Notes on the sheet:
Island supply: 1 W isolated module, LDO, minimum-load preload
Digital isolators: SPI to the three AD7124 and six ADT7310
Series damping, MISO contention resistor, pull-ups
External 3.0 V reference (cross-check of the AD7124 internal reference)
Mid-rail V_MID for the 20M thermocouple bias

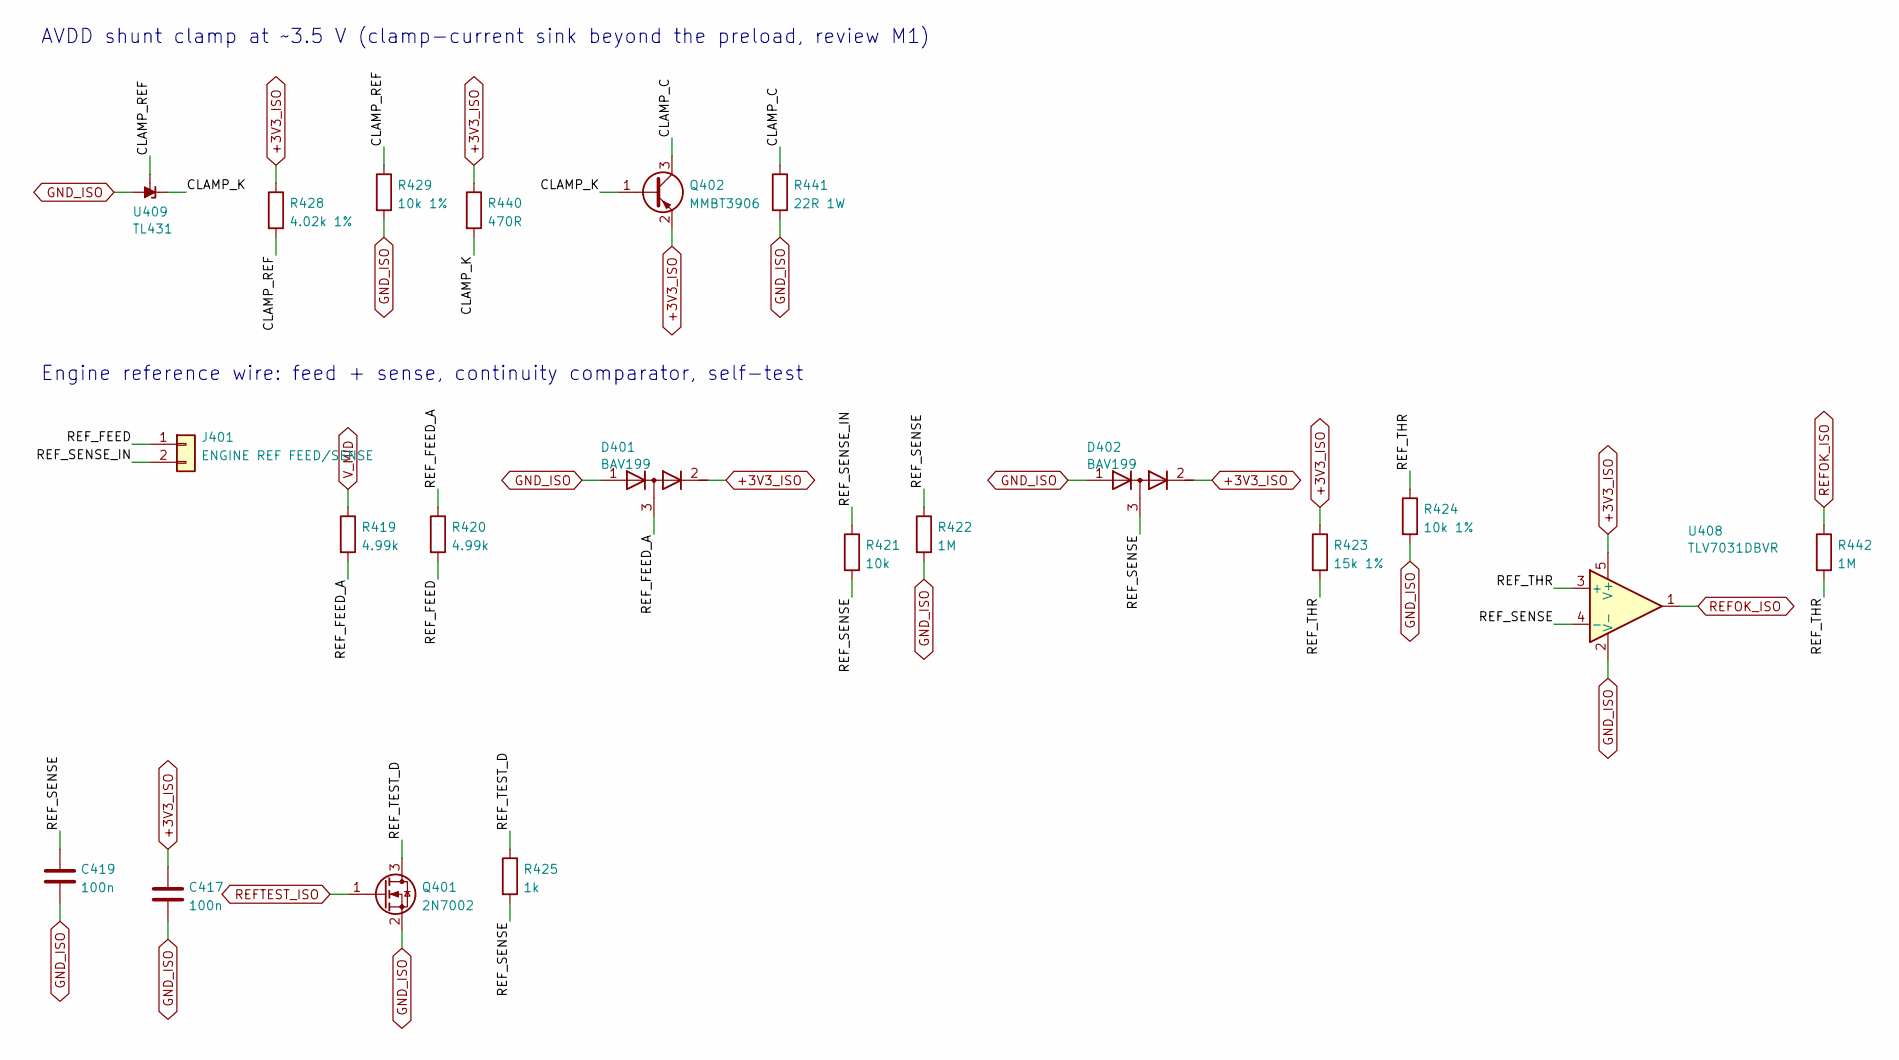
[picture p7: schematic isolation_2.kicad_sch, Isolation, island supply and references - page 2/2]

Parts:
C417, C419: 100n; C_0805_2012Metric; MPN CC0805KRX7R9BB104; LCSC C49678
D401, D402: BAV199; SOT-23; MPN BAV199,215; LCSC C40919
J401: ENGINE REF FEED/SENSE; PhoenixContact_MC_1,5_2-G-3.81_1x02_P3.81mm_Horizontal; MPN WJ15EDGRC-3.81-02P-14-00A; LCSC C8387
Q401: 2N7002; SOT-23; MPN 2N7002; LCSC C8545
Q402: MMBT3906; SOT-23; MPN MMBT3906LT1G; LCSC C53444
R419, R420: 4.99k; R_1206_3216Metric; MPN FRC1206F4991TS; LCSC C3013259
R421: 10k; R_0805_2012Metric; MPN 0805W8F1002T5E; LCSC C17414
R422, R442: 1M; R_0805_2012Metric; MPN 0805W8F1004T5E; LCSC C17514
R423: 15k 1%; R_0805_2012Metric; MPN 0805W8F1502T5E; LCSC C17475
R424, R429: 10k 1%; R_0805_2012Metric; MPN 0805W8F1002T5E; LCSC C17414
R425: 1k; R_0805_2012Metric; MPN 0805W8F1001T5E; LCSC C17513
R428: 4.02k 1%; R_0805_2012Metric; MPN 0805W8F4021T5E; LCSC C17663
R440: 470R; R_0805_2012Metric; MPN 0805W8F4700T5E; LCSC C17710
R441: 22R 1W; R_2512_6332Metric; MPN 25121WF220JT4E; LCSC C118189
U408: TLV7031DBVR; SOT-23-5; MPN TLV7031DBVR; LCSC C2869832
U409: TL431; SOT-23; MPN TL431BIDBZR; LCSC C41283

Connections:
+3V3_ISO: C417.1, D401.2 (K), D402.2 (K), Q402.2 (E), R423.1, R428.1, R440.1, U408.5 (V+); also elsewhere on the board
/ISOLATION_2/CLAMP_C: Q402.3 (C), R441.1
/ISOLATION_2/CLAMP_K: Q402.1 (B), R440.2, U409.1 (K)
/ISOLATION_2/CLAMP_REF: R428.2, R429.1, U409.2 (REF)
/ISOLATION_2/REF_FEED: J401.1, R420.2
/ISOLATION_2/REF_FEED_A: D401.3 (common), R419.2, R420.1
/ISOLATION_2/REF_SENSE: C419.1, D402.3 (common), R421.2, R422.1, R425.2, U408.4 (-)
/ISOLATION_2/REF_SENSE_IN: J401.2, R421.1
/ISOLATION_2/REF_TEST_D: Q401.3 (D), R425.1
/ISOLATION_2/REF_THR: R423.2, R424.1, R442.2, U408.3 (+)
GND_ISO: C417.2, C419.2, D401.1 (A), D402.1 (A), Q401.2 (S), R422.2, R424.2, R429.2, R441.2, U408.2 (V-), U409.3 (A); also elsewhere on the board
REFOK_ISO: R442.1, U408.1; also elsewhere on the board
REFTEST_ISO: Q401.1 (G); also elsewhere on the board
V_MID: R419.1; also elsewhere on the board

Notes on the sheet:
AVDD shunt clamp at ~3.5 V (clamp-current sink beyond the preload, review M1)
Engine reference wire: feed + sense, continuity comparator, self-test

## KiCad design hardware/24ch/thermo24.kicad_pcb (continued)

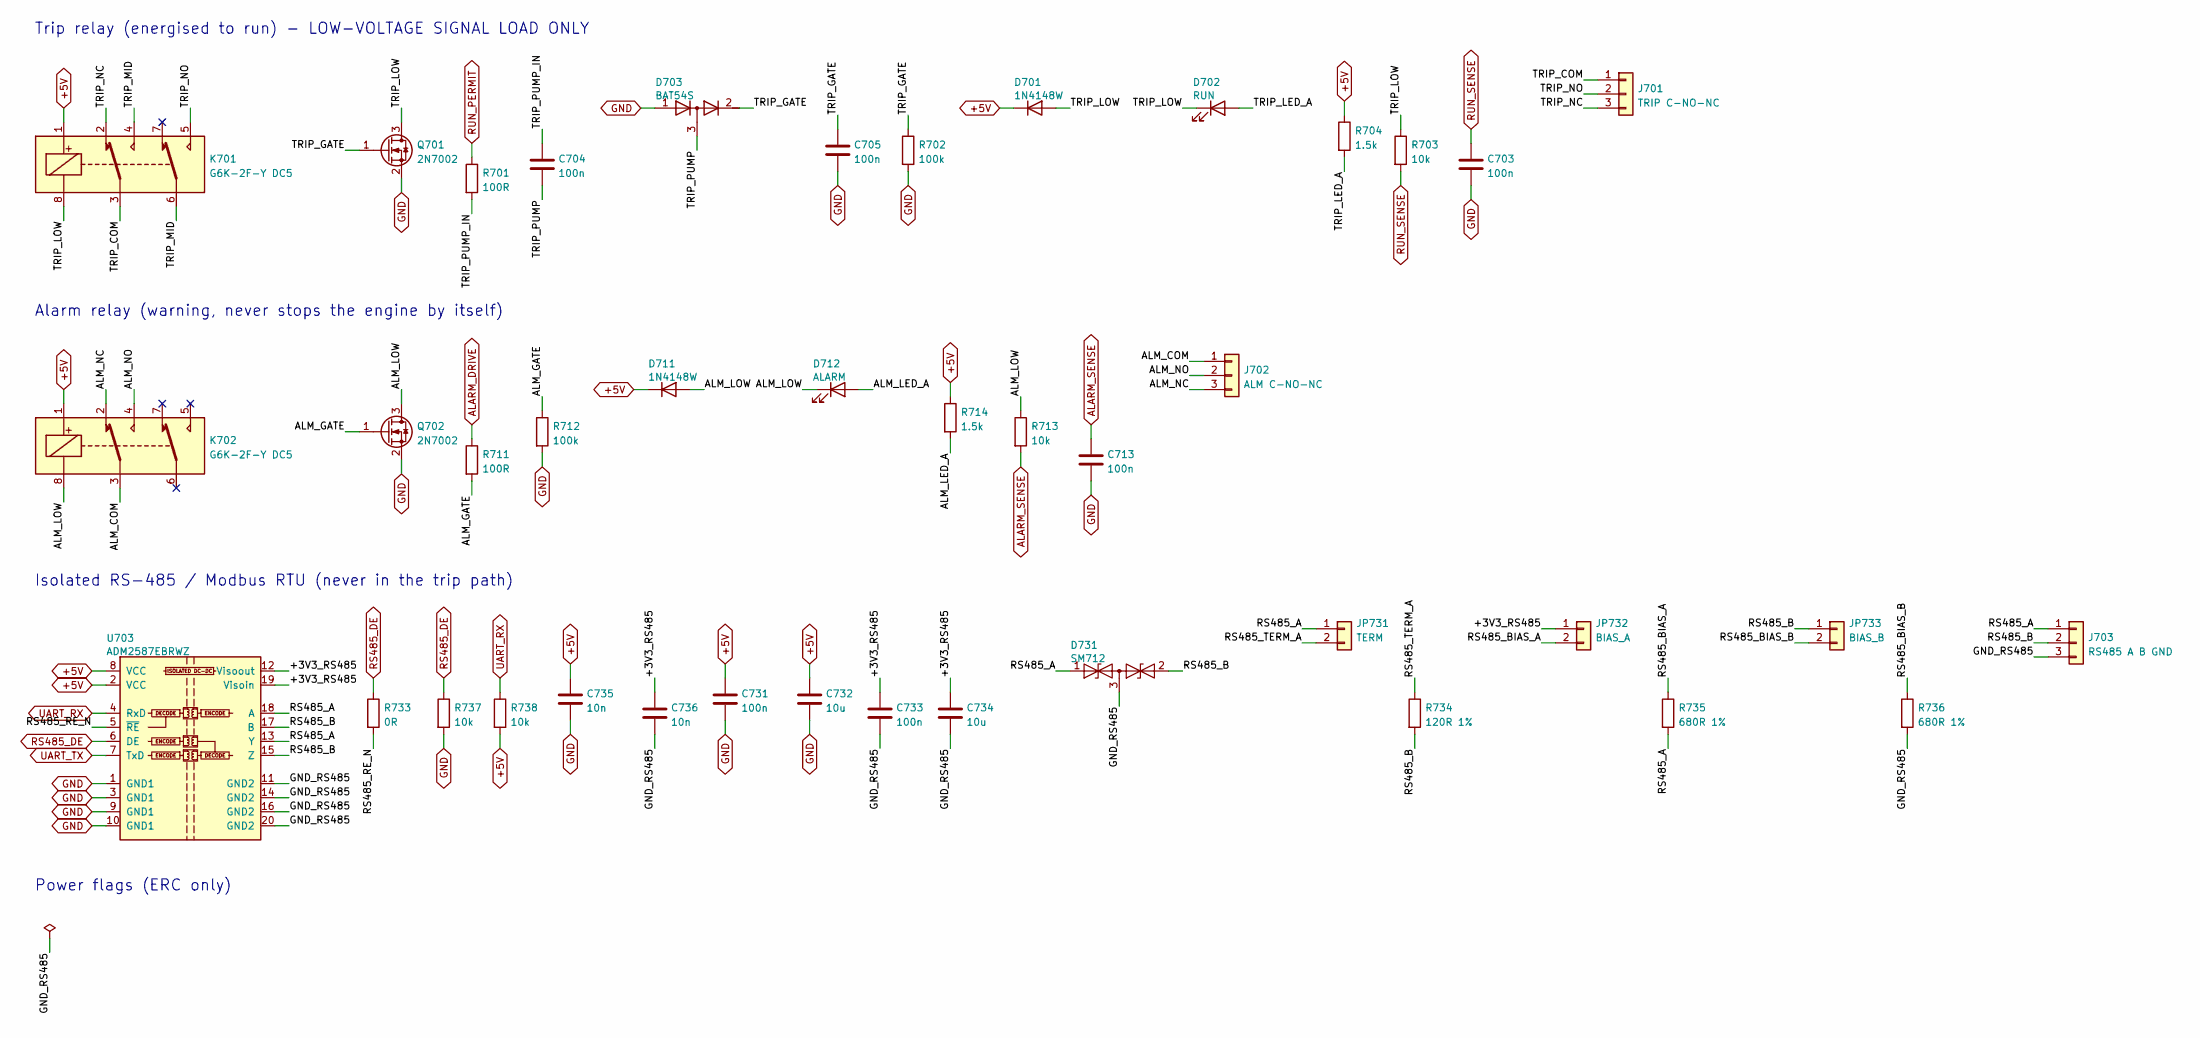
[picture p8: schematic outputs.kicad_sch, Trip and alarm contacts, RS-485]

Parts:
C703, C704, C705, C713, C731, C733: 100n; C_0805_2012Metric; MPN CC0805KRX7R9BB104; LCSC C49678
C732, C734: 10u; C_0805_2012Metric; MPN CL21B106KOQNNNE; LCSC C95841
C735, C736: 10n; C_0805_2012Metric; MPN CL21B103KBANNNC; LCSC C1710
D701, D711: 1N4148W; D_SOD-123; MPN 1N4148W-7-F; LCSC C83528
D702: RUN; LED_D3.0mm; MPN 3A4GUD; LCSC C52034646
D703: BAT54S; SOT-23; MPN BAT54S,215; LCSC C47546
D712: ALARM; LED_D3.0mm; MPN 204-10SURD/S530-A3-L; LCSC C99771
D731: SM712; SOT-23; MPN SM712.TCT; LCSC C12067
J701: TRIP C-NO-NC; TerminalBlock_Phoenix_MKDS-1,5-3_1x03_P5.00mm_Horizontal; MPN WJ128V-5.0-3P; LCSC C8270
J702: ALM C-NO-NC; TerminalBlock_Phoenix_MKDS-1,5-3_1x03_P5.00mm_Horizontal; MPN WJ128V-5.0-3P; LCSC C8270
J703: RS485 A B GND; TerminalBlock_Phoenix_MKDS-1,5-3_1x03_P5.00mm_Horizontal; MPN WJ128V-5.0-3P; LCSC C8270
JP731: TERM; PinHeader_1x02_P2.54mm_Vertical; MPN PZ254V-11-02P; LCSC C492401
JP732: BIAS_A; PinHeader_1x02_P2.54mm_Vertical; MPN PZ254V-11-02P; LCSC C492401
JP733: BIAS_B; PinHeader_1x02_P2.54mm_Vertical; MPN PZ254V-11-02P; LCSC C492401
K701, K702: G6K-2F-Y DC5; Relay_DPDT_Omron_G6K-2F-Y; MPN G6K-2F-Y DC5; LCSC C2982926
Q701, Q702: 2N7002; SOT-23; MPN 2N7002; LCSC C8545
R701, R711: 100R; R_0805_2012Metric; MPN 0805W8F1000T5E; LCSC C17408
R702, R712: 100k; R_0805_2012Metric; MPN 0805W8F1003T5E; LCSC C149504
R703, R713, R737, R738: 10k; R_0805_2012Metric; MPN 0805W8F1002T5E; LCSC C17414
R704, R714: 1.5k; R_0805_2012Metric; MPN 0805W8F1501T5E; LCSC C4310
R733: 0R; R_0805_2012Metric; MPN 0805W8F0000T5E; LCSC C17477
R734: 120R 1%; R_0805_2012Metric; MPN 0805W8F1200T5E; LCSC C17437
R735, R736: 680R 1%; R_0805_2012Metric; MPN 0805W8F6800T5E; LCSC C17798
U703: ADM2587EBRWZ; SOIC-20W_7.5x12.8mm_P1.27mm; MPN ADM2587EBRWZ-REEL7; LCSC C12081

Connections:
+5V: C731.1, C732.1, C735.1, D701.1 (K), D711.1 (K), K701.1, K702.1, R704.1, R714.1, R738.2, U703.2 (VCC), U703.8 (VCC); also elsewhere on the board
/OUTPUTS/+3V3_RS485: C733.1, C734.1, C736.1, JP732.1, U703.12 (Visoout), U703.19 (Visoin)
/OUTPUTS/ALM_COM: J702.1, K702.3
/OUTPUTS/ALM_GATE: Q702.1 (G), R711.2, R712.1
/OUTPUTS/ALM_LED_A: D712.2 (A), R714.2
/OUTPUTS/ALM_LOW: D711.2 (A), D712.1 (K), K702.8, Q702.3 (D), R713.1
/OUTPUTS/ALM_NC: J702.3, K702.2
/OUTPUTS/ALM_NO: J702.2, K702.4
/OUTPUTS/GND_RS485: C733.2, C734.2, C736.2, D731.3 (common), J703.3, R736.2, U703.11 (GND2), U703.14 (GND2), U703.16 (GND2), U703.20 (GND2)
/OUTPUTS/RS485_A: D731.1 (A1), J703.1, JP731.1, R735.2, U703.13 (Y), U703.18 (A)
/OUTPUTS/RS485_B: D731.2 (A2), J703.2, JP733.1, R734.2, U703.15 (Z), U703.17 (B)
/OUTPUTS/RS485_BIAS_A: JP732.2, R735.1
/OUTPUTS/RS485_BIAS_B: JP733.2, R736.1
/OUTPUTS/RS485_RE_N: R733.2, U703.5 (~RE)
/OUTPUTS/RS485_TERM_A: JP731.2, R734.1
/OUTPUTS/TRIP_COM: J701.1, K701.3
/OUTPUTS/TRIP_GATE: C705.1, D703.2 (K), Q701.1 (G), R702.1
/OUTPUTS/TRIP_LED_A: D702.2 (A), R704.2
/OUTPUTS/TRIP_LOW: D701.2 (A), D702.1 (K), K701.8, Q701.3 (D), R703.1
/OUTPUTS/TRIP_MID: K701.4, K701.6
/OUTPUTS/TRIP_NC: J701.3, K701.2
/OUTPUTS/TRIP_NO: J701.2, K701.5
/OUTPUTS/TRIP_PUMP: C704.2, D703.3 (common)
/OUTPUTS/TRIP_PUMP_IN: C704.1, R701.2
ALARM_DRIVE: R711.1; also elsewhere on the board
ALARM_SENSE: C713.1, R713.2; also elsewhere on the board
GND: C703.2, C705.2, C713.2, C731.2, C732.2, C735.2, D703.1 (A), Q701.2 (S), Q702.2 (S), R702.2, R712.2, R737.2, U703.1 (GND1), U703.3 (GND1), U703.9 (GND1), U703.10 (GND1); also elsewhere on the board
RS485_DE: R733.1, R737.1, U703.6 (DE); also elsewhere on the board
RUN_PERMIT: R701.1; also elsewhere on the board
RUN_SENSE: C703.1, R703.2; also elsewhere on the board
UART_RX: R738.1, U703.4 (RxD); also elsewhere on the board
UART_TX: U703.7 (TxD); also elsewhere on the board

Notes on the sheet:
Trip relay (energised to run) - LOW-VOLTAGE SIGNAL LOAD ONLY
Alarm relay (warning, never stops the engine by itself)
Isolated RS-485 / Modbus RTU (never in the trip path)
Power flags (ERC only)

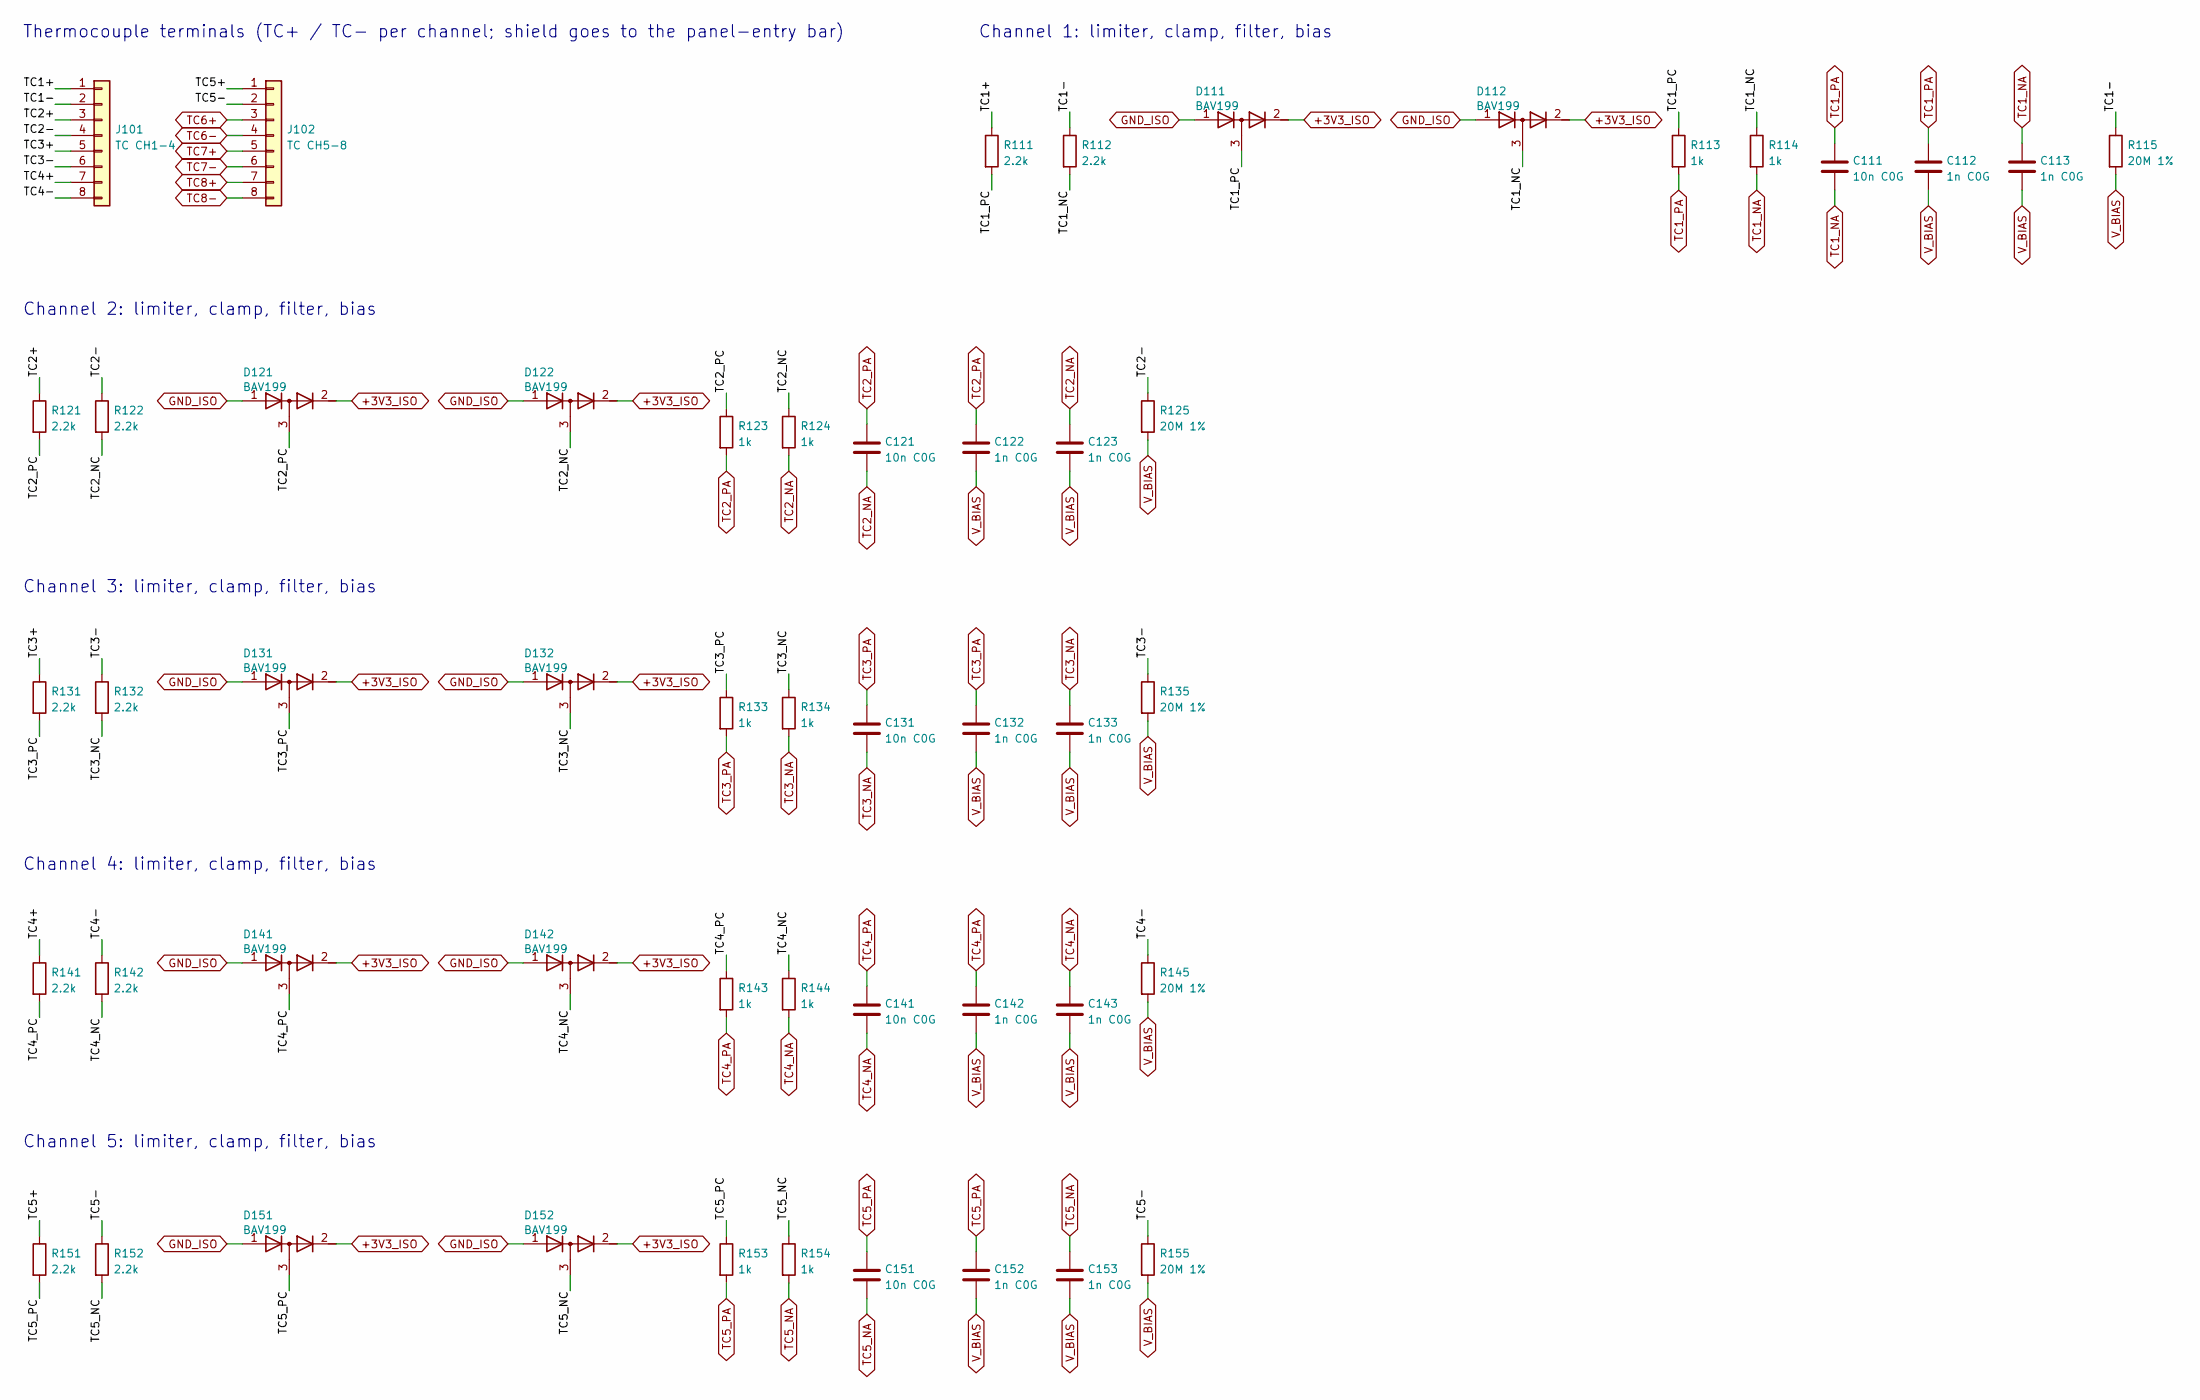
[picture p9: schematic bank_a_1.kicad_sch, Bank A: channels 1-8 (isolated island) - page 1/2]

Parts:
C111, C121, C131, C141, C151: 10n C0G; C_0805_2012Metric; MPN GRM2195C1H103JA01D; LCSC C97905
C112, C113, C122, C123, C132, C133, C142, C143, C152, C153: 1n C0G; C_0805_2012Metric; MPN CL21C102JBCNNNC; LCSC C1791
D111, D112, D121, D122, D131, D132, D141, D142, D151, D152: BAV199; SOT-23; MPN BAV199,215; LCSC C40919
J101: TC CH1-4; PhoenixContact_MC_1,5_8-G-3.81_1x08_P3.81mm_Horizontal; MPN WJ15EDGRC-3.81-8P; LCSC C14235
J102: TC CH5-8; PhoenixContact_MC_1,5_8-G-3.81_1x08_P3.81mm_Horizontal; MPN WJ15EDGRC-3.81-8P; LCSC C14235
R111, R112, R121, R122, R131, R132, R141, R142, R151, R152: 2.2k; R_0805_2012Metric; MPN 0805W8F2201T5E; LCSC C17520
R113, R114, R123, R124, R133, R134, R143, R144, R153, R154: 1k; R_0805_2012Metric; MPN 0805W8F1001T5E; LCSC C17513
R115, R125, R135, R145, R155: 20M 1%; R_1206_3216Metric; MPN FRG1206F2005TS; LCSC C3000606

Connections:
+3V3_ISO: D111.2 (K), D112.2 (K), D121.2 (K), D122.2 (K), D131.2 (K), D132.2 (K), D141.2 (K), D142.2 (K), D151.2 (K), D152.2 (K); also elsewhere on the board
/BANK_A_1/TC1+: J101.1, R111.1
/BANK_A_1/TC1-: J101.2, R112.1, R115.1
/BANK_A_1/TC1_NC: D112.3 (common), R112.2, R114.1
/BANK_A_1/TC1_PC: D111.3 (common), R111.2, R113.1
/BANK_A_1/TC2+: J101.3, R121.1
/BANK_A_1/TC2-: J101.4, R122.1, R125.1
/BANK_A_1/TC2_NC: D122.3 (common), R122.2, R124.1
/BANK_A_1/TC2_PC: D121.3 (common), R121.2, R123.1
/BANK_A_1/TC3+: J101.5, R131.1
/BANK_A_1/TC3-: J101.6, R132.1, R135.1
/BANK_A_1/TC3_NC: D132.3 (common), R132.2, R134.1
/BANK_A_1/TC3_PC: D131.3 (common), R131.2, R133.1
/BANK_A_1/TC4+: J101.7, R141.1
/BANK_A_1/TC4-: J101.8, R142.1, R145.1
/BANK_A_1/TC4_NC: D142.3 (common), R142.2, R144.1
/BANK_A_1/TC4_PC: D141.3 (common), R141.2, R143.1
/BANK_A_1/TC5+: J102.1, R151.1
/BANK_A_1/TC5-: J102.2, R152.1, R155.1
/BANK_A_1/TC5_NC: D152.3 (common), R152.2, R154.1
/BANK_A_1/TC5_PC: D151.3 (common), R151.2, R153.1
GND_ISO: D111.1 (A), D112.1 (A), D121.1 (A), D122.1 (A), D131.1 (A), D132.1 (A), D141.1 (A), D142.1 (A), D151.1 (A), D152.1 (A); also elsewhere on the board
TC1_NA: C111.2, C113.1, R114.2; also elsewhere on the board
TC1_PA: C111.1, C112.1, R113.2; also elsewhere on the board
TC2_NA: C121.2, C123.1, R124.2; also elsewhere on the board
TC2_PA: C121.1, C122.1, R123.2; also elsewhere on the board
TC3_NA: C131.2, C133.1, R134.2; also elsewhere on the board
TC3_PA: C131.1, C132.1, R133.2; also elsewhere on the board
TC4_NA: C141.2, C143.1, R144.2; also elsewhere on the board
TC4_PA: C141.1, C142.1, R143.2; also elsewhere on the board
TC5_NA: C151.2, C153.1, R154.2; also elsewhere on the board
TC5_PA: C151.1, C152.1, R153.2; also elsewhere on the board
TC6+: J102.3; also elsewhere on the board
TC6-: J102.4; also elsewhere on the board
TC7+: J102.5; also elsewhere on the board
TC7-: J102.6; also elsewhere on the board
TC8+: J102.7; also elsewhere on the board
TC8-: J102.8; also elsewhere on the board
V_BIAS: C112.2, C113.2, C122.2, C123.2, C132.2, C133.2, C142.2, C143.2, C152.2, C153.2, R115.2, R125.2, R135.2, R145.2, R155.2; also elsewhere on the board

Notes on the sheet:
Thermocouple terminals (TC+ / TC- per channel; shield goes to the panel-entry bar)
Channel 1: limiter, clamp, filter, bias
Channel 2: limiter, clamp, filter, bias
Channel 3: limiter, clamp, filter, bias
Channel 4: limiter, clamp, filter, bias
Channel 5: limiter, clamp, filter, bias

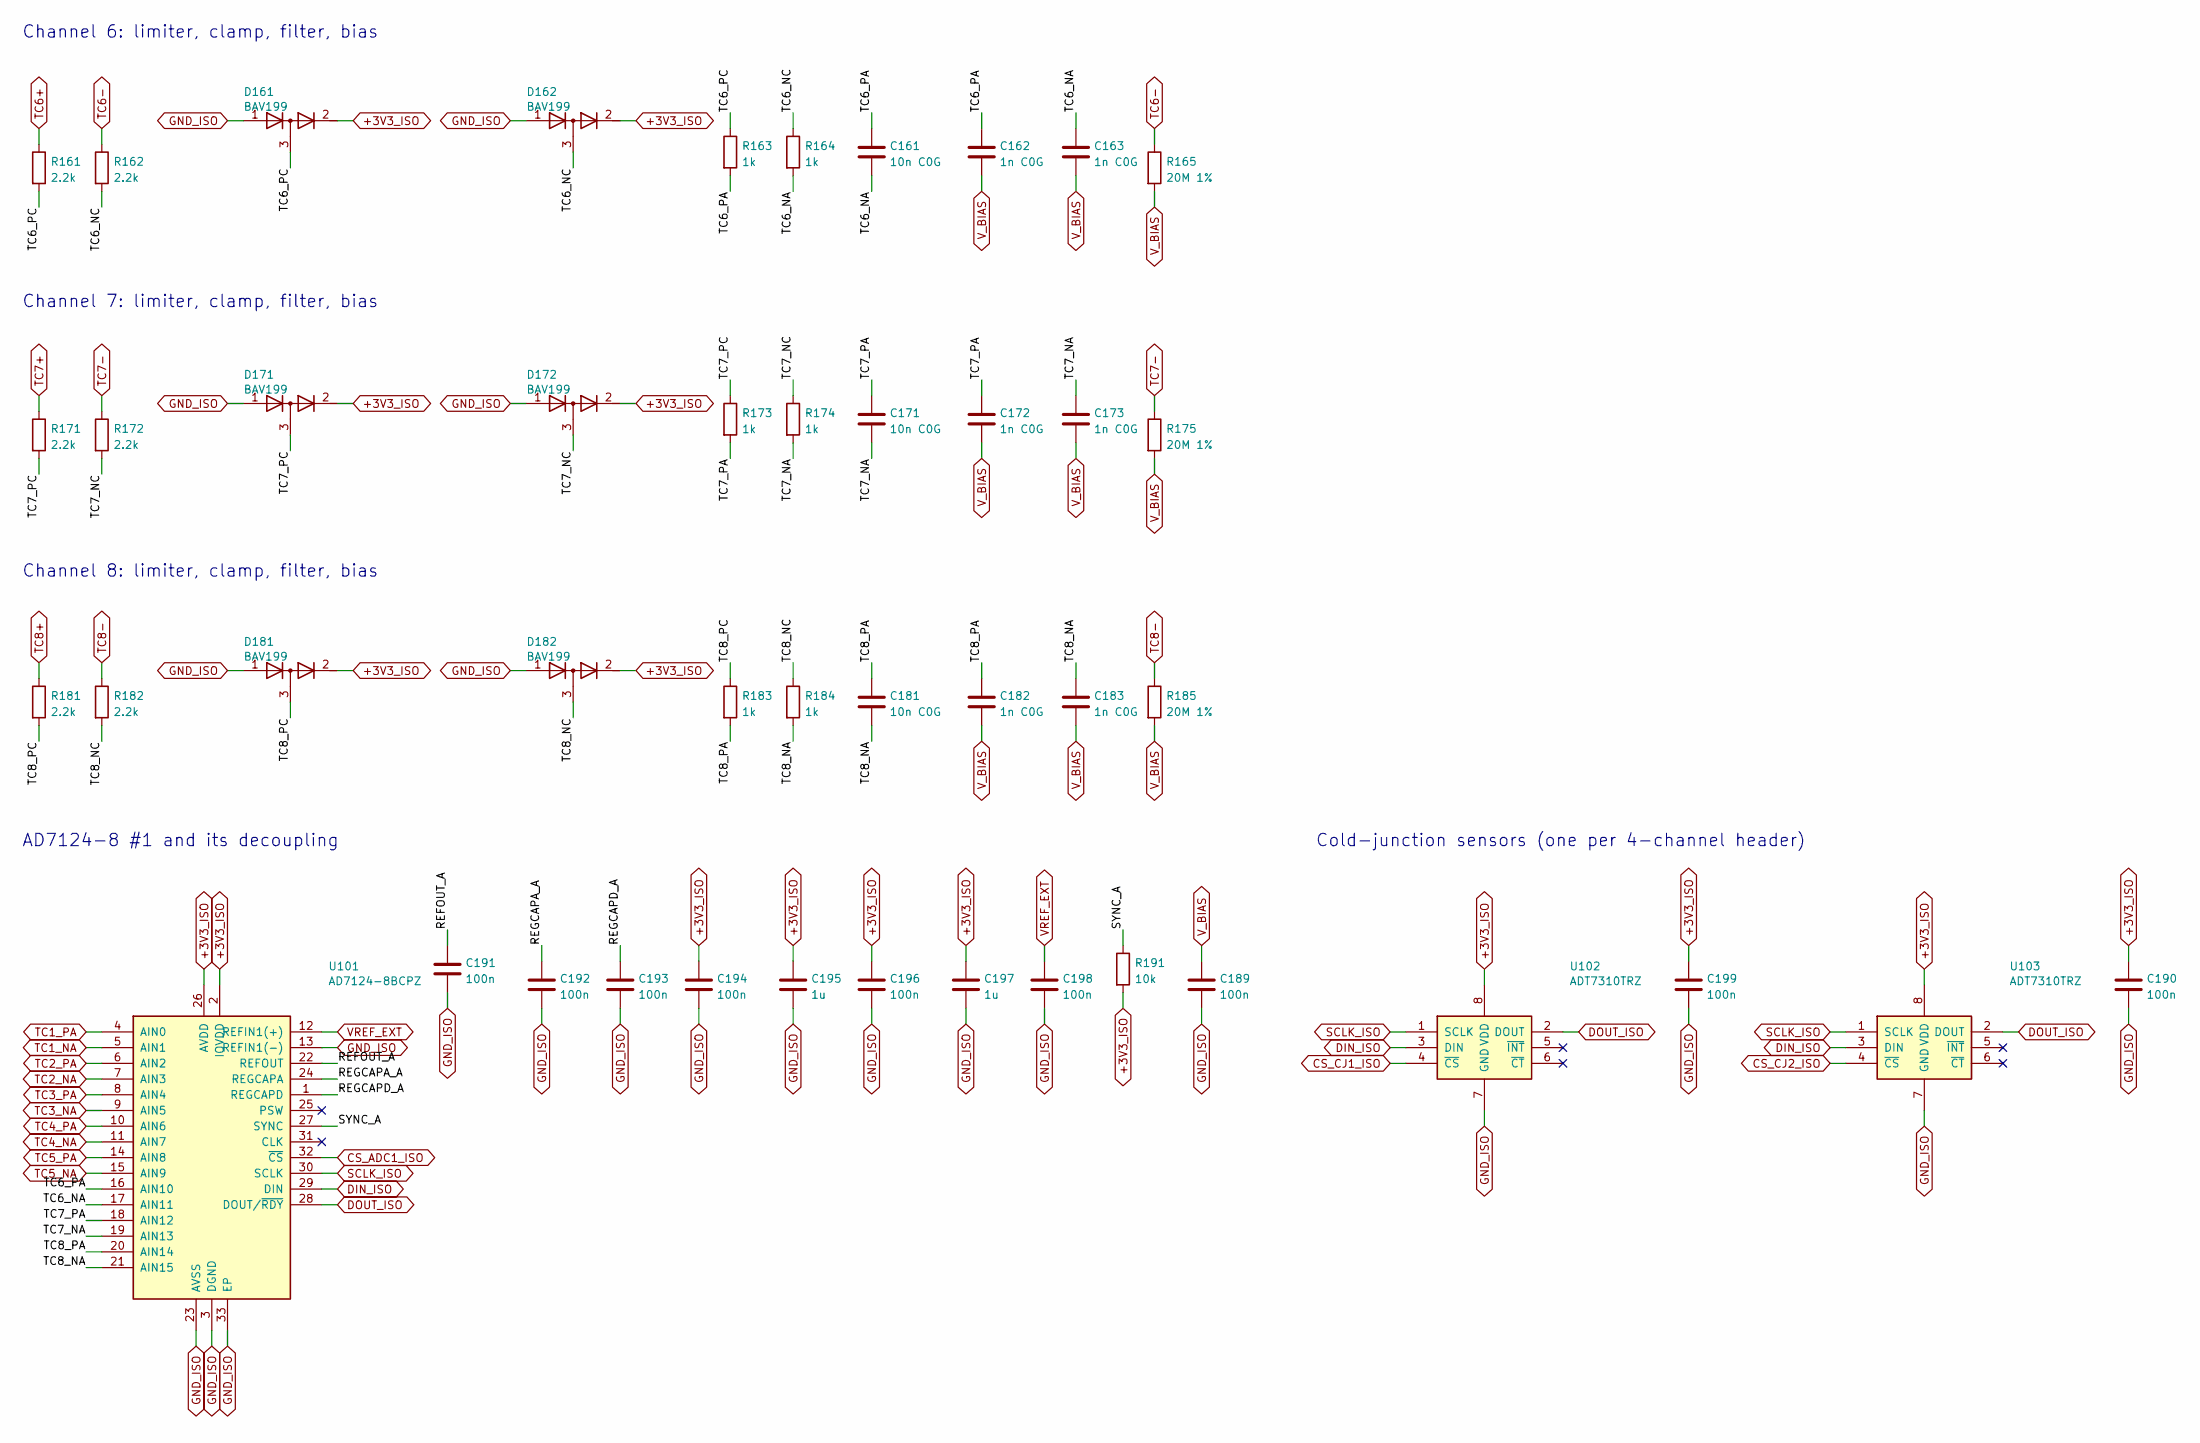
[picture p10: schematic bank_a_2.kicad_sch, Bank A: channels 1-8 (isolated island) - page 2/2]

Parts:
C161, C171, C181: 10n C0G; C_0805_2012Metric; MPN GRM2195C1H103JA01D; LCSC C97905
C162, C163, C172, C173, C182, C183: 1n C0G; C_0805_2012Metric; MPN CL21C102JBCNNNC; LCSC C1791
C189, C190, C191, C192, C193, C194, C196, C198, C199: 100n; C_0805_2012Metric; MPN CC0805KRX7R9BB104; LCSC C49678
C195, C197: 1u; C_0805_2012Metric; MPN CL21B105KBFNNNE; LCSC C28323
D161, D162, D171, D172, D181, D182: BAV199; SOT-23; MPN BAV199,215; LCSC C40919
R161, R162, R171, R172, R181, R182: 2.2k; R_0805_2012Metric; MPN 0805W8F2201T5E; LCSC C17520
R163, R164, R173, R174, R183, R184: 1k; R_0805_2012Metric; MPN 0805W8F1001T5E; LCSC C17513
R165, R175, R185: 20M 1%; R_1206_3216Metric; MPN FRG1206F2005TS; LCSC C3000606
R191: 10k; R_0805_2012Metric; MPN 0805W8F1002T5E; LCSC C17414
U101: AD7124-8BCPZ; LFCSP-32-1EP_5x5mm_P0.5mm_EP3.6x3.6mm; MPN AD7124-8BCPZ; LCSC C97314
U102, U103: ADT7310TRZ; SOIC-8_3.9x4.9mm_P1.27mm; MPN ADT7310TRZ-REEL7; LCSC C578060

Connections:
+3V3_ISO: C190.1, C194.1, C195.1, C196.1, C197.1, C199.1, D161.2 (K), D162.2 (K), D171.2 (K), D172.2 (K), D181.2 (K), D182.2 (K), R191.2, U101.2 (IOVDD), U101.26 (AVDD), U102.8 (VDD), U103.8 (VDD); also elsewhere on the board
/BANK_A_2/REFOUT_A: C191.1, U101.22 (REFOUT)
/BANK_A_2/REGCAPA_A: C192.1, U101.24 (REGCAPA)
/BANK_A_2/REGCAPD_A: C193.1, U101.1 (REGCAPD)
/BANK_A_2/SYNC_A: R191.1, U101.27 (SYNC)
/BANK_A_2/TC6_NA: C161.2, C163.1, R164.2, U101.17 (AIN11)
/BANK_A_2/TC6_NC: D162.3 (common), R162.2, R164.1
/BANK_A_2/TC6_PA: C161.1, C162.1, R163.2, U101.16 (AIN10)
/BANK_A_2/TC6_PC: D161.3 (common), R161.2, R163.1
/BANK_A_2/TC7_NA: C171.2, C173.1, R174.2, U101.19 (AIN13)
/BANK_A_2/TC7_NC: D172.3 (common), R172.2, R174.1
/BANK_A_2/TC7_PA: C171.1, C172.1, R173.2, U101.18 (AIN12)
/BANK_A_2/TC7_PC: D171.3 (common), R171.2, R173.1
/BANK_A_2/TC8_NA: C181.2, C183.1, R184.2, U101.21 (AIN15)
/BANK_A_2/TC8_NC: D182.3 (common), R182.2, R184.1
/BANK_A_2/TC8_PA: C181.1, C182.1, R183.2, U101.20 (AIN14)
/BANK_A_2/TC8_PC: D181.3 (common), R181.2, R183.1
CS_ADC1_ISO: U101.32 (~CS); also elsewhere on the board
CS_CJ1_ISO: U102.4 (~CS); also elsewhere on the board
CS_CJ2_ISO: U103.4 (~CS); also elsewhere on the board
DIN_ISO: U101.29 (DIN), U102.3 (DIN), U103.3 (DIN); also elsewhere on the board
DOUT_ISO: U101.28 (DOUT/~RDY), U102.2 (DOUT), U103.2 (DOUT); also elsewhere on the board
GND_ISO: C189.2, C190.2, C191.2, C192.2, C193.2, C194.2, C195.2, C196.2, C197.2, C198.2, C199.2, D161.1 (A), D162.1 (A), D171.1 (A), D172.1 (A), D181.1 (A), D182.1 (A), U101.3 (DGND), U101.13 (REFIN1(-)), U101.23 (AVSS), U101.33 (EP), U102.7 (GND), U103.7 (GND); also elsewhere on the board
SCLK_ISO: U101.30 (SCLK), U102.1 (SCLK), U103.1 (SCLK); also elsewhere on the board
TC1_NA: U101.5 (AIN1); also elsewhere on the board
TC1_PA: U101.4 (AIN0); also elsewhere on the board
TC2_NA: U101.7 (AIN3); also elsewhere on the board
TC2_PA: U101.6 (AIN2); also elsewhere on the board
TC3_NA: U101.9 (AIN5); also elsewhere on the board
TC3_PA: U101.8 (AIN4); also elsewhere on the board
TC4_NA: U101.11 (AIN7); also elsewhere on the board
TC4_PA: U101.10 (AIN6); also elsewhere on the board
TC5_NA: U101.15 (AIN9); also elsewhere on the board
TC5_PA: U101.14 (AIN8); also elsewhere on the board
TC6+: R161.1; also elsewhere on the board
TC6-: R162.1, R165.1; also elsewhere on the board
TC7+: R171.1; also elsewhere on the board
TC7-: R172.1, R175.1; also elsewhere on the board
TC8+: R181.1; also elsewhere on the board
TC8-: R182.1, R185.1; also elsewhere on the board
VREF_EXT: C198.1, U101.12 (REFIN1(+)); also elsewhere on the board
V_BIAS: C162.2, C163.2, C172.2, C173.2, C182.2, C183.2, C189.1, R165.2, R175.2, R185.2; also elsewhere on the board

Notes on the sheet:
Channel 6: limiter, clamp, filter, bias
Channel 7: limiter, clamp, filter, bias
Channel 8: limiter, clamp, filter, bias
AD7124-8 #1 and its decoupling
Cold-junction sensors (one per 4-channel header)

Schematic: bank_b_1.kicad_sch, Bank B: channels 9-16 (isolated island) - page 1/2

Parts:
C211, C221, C231, C241, C251: 10n C0G; C_0805_2012Metric; MPN GRM2195C1H103JA01D; LCSC C97905
C212, C213, C222, C223, C232, C233, C242, C243, C252, C253: 1n C0G; C_0805_2012Metric; MPN CL21C102JBCNNNC; LCSC C1791
D211, D212, D221, D222, D231, D232, D241, D242, D251, D252: BAV199; SOT-23; MPN BAV199,215; LCSC C40919
J201: TC CH9-12; PhoenixContact_MC_1,5_8-G-3.81_1x08_P3.81mm_Horizontal; MPN WJ15EDGRC-3.81-8P; LCSC C14235
J202: TC CH13-16; PhoenixContact_MC_1,5_8-G-3.81_1x08_P3.81mm_Horizontal; MPN WJ15EDGRC-3.81-8P; LCSC C14235
R211, R212, R221, R222, R231, R232, R241, R242, R251, R252: 2.2k; R_0805_2012Metric; MPN 0805W8F2201T5E; LCSC C17520
R213, R214, R223, R224, R233, R234, R243, R244, R253, R254: 1k; R_0805_2012Metric; MPN 0805W8F1001T5E; LCSC C17513
R215, R225, R235, R245, R255: 20M 1%; R_1206_3216Metric; MPN FRG1206F2005TS; LCSC C3000606

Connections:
+3V3_ISO: D211.2 (K), D212.2 (K), D221.2 (K), D222.2 (K), D231.2 (K), D232.2 (K), D241.2 (K), D242.2 (K), D251.2 (K), D252.2 (K); also elsewhere on the board
/BANK_B_1/TC9+: J201.1, R211.1
/BANK_B_1/TC9-: J201.2, R212.1, R215.1
/BANK_B_1/TC9_NC: D212.3 (common), R212.2, R214.1
/BANK_B_1/TC9_PC: D211.3 (common), R211.2, R213.1
/BANK_B_1/TC10+: J201.3, R221.1
/BANK_B_1/TC10-: J201.4, R222.1, R225.1
/BANK_B_1/TC10_NC: D222.3 (common), R222.2, R224.1
/BANK_B_1/TC10_PC: D221.3 (common), R221.2, R223.1
/BANK_B_1/TC11+: J201.5, R231.1
/BANK_B_1/TC11-: J201.6, R232.1, R235.1
/BANK_B_1/TC11_NC: D232.3 (common), R232.2, R234.1
/BANK_B_1/TC11_PC: D231.3 (common), R231.2, R233.1
/BANK_B_1/TC12+: J201.7, R241.1
/BANK_B_1/TC12-: J201.8, R242.1, R245.1
/BANK_B_1/TC12_NC: D242.3 (common), R242.2, R244.1
/BANK_B_1/TC12_PC: D241.3 (common), R241.2, R243.1
/BANK_B_1/TC13+: J202.1, R251.1
/BANK_B_1/TC13-: J202.2, R252.1, R255.1
/BANK_B_1/TC13_NC: D252.3 (common), R252.2, R254.1
/BANK_B_1/TC13_PC: D251.3 (common), R251.2, R253.1
GND_ISO: D211.1 (A), D212.1 (A), D221.1 (A), D222.1 (A), D231.1 (A), D232.1 (A), D241.1 (A), D242.1 (A), D251.1 (A), D252.1 (A); also elsewhere on the board
TC9_NA: C211.2, C213.1, R214.2; also elsewhere on the board
TC9_PA: C211.1, C212.1, R213.2; also elsewhere on the board
TC10_NA: C221.2, C223.1, R224.2; also elsewhere on the board
TC10_PA: C221.1, C222.1, R223.2; also elsewhere on the board
TC11_NA: C231.2, C233.1, R234.2; also elsewhere on the board
TC11_PA: C231.1, C232.1, R233.2; also elsewhere on the board
TC12_NA: C241.2, C243.1, R244.2; also elsewhere on the board
TC12_PA: C241.1, C242.1, R243.2; also elsewhere on the board
TC13_NA: C251.2, C253.1, R254.2; also elsewhere on the board
TC13_PA: C251.1, C252.1, R253.2; also elsewhere on the board
TC14+: J202.3; also elsewhere on the board
TC14-: J202.4; also elsewhere on the board
TC15+: J202.5; also elsewhere on the board
TC15-: J202.6; also elsewhere on the board
TC16+: J202.7; also elsewhere on the board
TC16-: J202.8; also elsewhere on the board
V_BIAS: C212.2, C213.2, C222.2, C223.2, C232.2, C233.2, C242.2, C243.2, C252.2, C253.2, R215.2, R225.2, R235.2, R245.2, R255.2; also elsewhere on the board

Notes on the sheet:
Thermocouple terminals (TC+ / TC- per channel; shield goes to the panel-entry bar)
Channel 9: limiter, clamp, filter, bias
Channel 10: limiter, clamp, filter, bias
Channel 11: limiter, clamp, filter, bias
Channel 12: limiter, clamp, filter, bias
Channel 13: limiter, clamp, filter, bias

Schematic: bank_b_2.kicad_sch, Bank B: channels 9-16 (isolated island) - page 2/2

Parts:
C261, C271, C281: 10n C0G; C_0805_2012Metric; MPN GRM2195C1H103JA01D; LCSC C97905
C262, C263, C272, C273, C282, C283: 1n C0G; C_0805_2012Metric; MPN CL21C102JBCNNNC; LCSC C1791
C289, C290, C291, C292, C293, C294, C296, C298, C299: 100n; C_0805_2012Metric; MPN CC0805KRX7R9BB104; LCSC C49678
C295, C297: 1u; C_0805_2012Metric; MPN CL21B105KBFNNNE; LCSC C28323
D261, D262, D271, D272, D281, D282: BAV199; SOT-23; MPN BAV199,215; LCSC C40919
R261, R262, R271, R272, R281, R282: 2.2k; R_0805_2012Metric; MPN 0805W8F2201T5E; LCSC C17520
R263, R264, R273, R274, R283, R284: 1k; R_0805_2012Metric; MPN 0805W8F1001T5E; LCSC C17513
R265, R275, R285: 20M 1%; R_1206_3216Metric; MPN FRG1206F2005TS; LCSC C3000606
R291: 10k; R_0805_2012Metric; MPN 0805W8F1002T5E; LCSC C17414
U201: AD7124-8BCPZ; LFCSP-32-1EP_5x5mm_P0.5mm_EP3.6x3.6mm; MPN AD7124-8BCPZ; LCSC C97314
U202, U203: ADT7310TRZ; SOIC-8_3.9x4.9mm_P1.27mm; MPN ADT7310TRZ-REEL7; LCSC C578060

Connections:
+3V3_ISO: C290.1, C294.1, C295.1, C296.1, C297.1, C299.1, D261.2 (K), D262.2 (K), D271.2 (K), D272.2 (K), D281.2 (K), D282.2 (K), R291.2, U201.2 (IOVDD), U201.26 (AVDD), U202.8 (VDD), U203.8 (VDD); also elsewhere on the board
/BANK_B_2/REFOUT_B: C291.1, U201.22 (REFOUT)
/BANK_B_2/REGCAPA_B: C292.1, U201.24 (REGCAPA)
/BANK_B_2/REGCAPD_B: C293.1, U201.1 (REGCAPD)
/BANK_B_2/SYNC_B: R291.1, U201.27 (SYNC)
/BANK_B_2/TC14_NA: C261.2, C263.1, R264.2, U201.17 (AIN11)
/BANK_B_2/TC14_NC: D262.3 (common), R262.2, R264.1
/BANK_B_2/TC14_PA: C261.1, C262.1, R263.2, U201.16 (AIN10)
/BANK_B_2/TC14_PC: D261.3 (common), R261.2, R263.1
/BANK_B_2/TC15_NA: C271.2, C273.1, R274.2, U201.19 (AIN13)
/BANK_B_2/TC15_NC: D272.3 (common), R272.2, R274.1
/BANK_B_2/TC15_PA: C271.1, C272.1, R273.2, U201.18 (AIN12)
/BANK_B_2/TC15_PC: D271.3 (common), R271.2, R273.1
/BANK_B_2/TC16_NA: C281.2, C283.1, R284.2, U201.21 (AIN15)
/BANK_B_2/TC16_NC: D282.3 (common), R282.2, R284.1
/BANK_B_2/TC16_PA: C281.1, C282.1, R283.2, U201.20 (AIN14)
/BANK_B_2/TC16_PC: D281.3 (common), R281.2, R283.1
CS_ADC2_ISO: U201.32 (~CS); also elsewhere on the board
CS_CJ3_ISO: U202.4 (~CS); also elsewhere on the board
CS_CJ4_ISO: U203.4 (~CS); also elsewhere on the board
DIN_ISO: U201.29 (DIN), U202.3 (DIN), U203.3 (DIN); also elsewhere on the board
DOUT_ISO: U201.28 (DOUT/~RDY), U202.2 (DOUT), U203.2 (DOUT); also elsewhere on the board
GND_ISO: C289.2, C290.2, C291.2, C292.2, C293.2, C294.2, C295.2, C296.2, C297.2, C298.2, C299.2, D261.1 (A), D262.1 (A), D271.1 (A), D272.1 (A), D281.1 (A), D282.1 (A), U201.3 (DGND), U201.13 (REFIN1(-)), U201.23 (AVSS), U201.33 (EP), U202.7 (GND), U203.7 (GND); also elsewhere on the board
SCLK_ISO: U201.30 (SCLK), U202.1 (SCLK), U203.1 (SCLK); also elsewhere on the board
TC9_NA: U201.5 (AIN1); also elsewhere on the board
TC9_PA: U201.4 (AIN0); also elsewhere on the board
TC10_NA: U201.7 (AIN3); also elsewhere on the board
TC10_PA: U201.6 (AIN2); also elsewhere on the board
TC11_NA: U201.9 (AIN5); also elsewhere on the board
TC11_PA: U201.8 (AIN4); also elsewhere on the board
TC12_NA: U201.11 (AIN7); also elsewhere on the board
TC12_PA: U201.10 (AIN6); also elsewhere on the board
TC13_NA: U201.15 (AIN9); also elsewhere on the board
TC13_PA: U201.14 (AIN8); also elsewhere on the board
TC14+: R261.1; also elsewhere on the board
TC14-: R262.1, R265.1; also elsewhere on the board
TC15+: R271.1; also elsewhere on the board
TC15-: R272.1, R275.1; also elsewhere on the board
TC16+: R281.1; also elsewhere on the board
TC16-: R282.1, R285.1; also elsewhere on the board
VREF_EXT: C298.1, U201.12 (REFIN1(+)); also elsewhere on the board
V_BIAS: C262.2, C263.2, C272.2, C273.2, C282.2, C283.2, C289.1, R265.2, R275.2, R285.2; also elsewhere on the board

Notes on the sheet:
Channel 14: limiter, clamp, filter, bias
Channel 15: limiter, clamp, filter, bias
Channel 16: limiter, clamp, filter, bias
AD7124-8 #2 and its decoupling
Cold-junction sensors (one per 4-channel header)

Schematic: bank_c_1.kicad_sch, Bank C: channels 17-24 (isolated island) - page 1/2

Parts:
C311, C321, C331, C341, C351: 10n C0G; C_0805_2012Metric; MPN GRM2195C1H103JA01D; LCSC C97905
C312, C313, C322, C323, C332, C333, C342, C343, C352, C353: 1n C0G; C_0805_2012Metric; MPN CL21C102JBCNNNC; LCSC C1791
D311, D312, D321, D322, D331, D332, D341, D342, D351, D352: BAV199; SOT-23; MPN BAV199,215; LCSC C40919
J301: TC CH17-20; PhoenixContact_MC_1,5_8-G-3.81_1x08_P3.81mm_Horizontal; MPN WJ15EDGRC-3.81-8P; LCSC C14235
J302: TC CH21-24; PhoenixContact_MC_1,5_8-G-3.81_1x08_P3.81mm_Horizontal; MPN WJ15EDGRC-3.81-8P; LCSC C14235
R311, R312, R321, R322, R331, R332, R341, R342, R351, R352: 2.2k; R_0805_2012Metric; MPN 0805W8F2201T5E; LCSC C17520
R313, R314, R323, R324, R333, R334, R343, R344, R353, R354: 1k; R_0805_2012Metric; MPN 0805W8F1001T5E; LCSC C17513
R315, R325, R335, R345, R355: 20M 1%; R_1206_3216Metric; MPN FRG1206F2005TS; LCSC C3000606

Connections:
+3V3_ISO: D311.2 (K), D312.2 (K), D321.2 (K), D322.2 (K), D331.2 (K), D332.2 (K), D341.2 (K), D342.2 (K), D351.2 (K), D352.2 (K); also elsewhere on the board
/BANK_C_1/TC17+: J301.1, R311.1
/BANK_C_1/TC17-: J301.2, R312.1, R315.1
/BANK_C_1/TC17_NC: D312.3 (common), R312.2, R314.1
/BANK_C_1/TC17_PC: D311.3 (common), R311.2, R313.1
/BANK_C_1/TC18+: J301.3, R321.1
/BANK_C_1/TC18-: J301.4, R322.1, R325.1
/BANK_C_1/TC18_NC: D322.3 (common), R322.2, R324.1
/BANK_C_1/TC18_PC: D321.3 (common), R321.2, R323.1
/BANK_C_1/TC19+: J301.5, R331.1
/BANK_C_1/TC19-: J301.6, R332.1, R335.1
/BANK_C_1/TC19_NC: D332.3 (common), R332.2, R334.1
/BANK_C_1/TC19_PC: D331.3 (common), R331.2, R333.1
/BANK_C_1/TC20+: J301.7, R341.1
/BANK_C_1/TC20-: J301.8, R342.1, R345.1
/BANK_C_1/TC20_NC: D342.3 (common), R342.2, R344.1
/BANK_C_1/TC20_PC: D341.3 (common), R341.2, R343.1
/BANK_C_1/TC21+: J302.1, R351.1
/BANK_C_1/TC21-: J302.2, R352.1, R355.1
/BANK_C_1/TC21_NC: D352.3 (common), R352.2, R354.1
/BANK_C_1/TC21_PC: D351.3 (common), R351.2, R353.1
GND_ISO: D311.1 (A), D312.1 (A), D321.1 (A), D322.1 (A), D331.1 (A), D332.1 (A), D341.1 (A), D342.1 (A), D351.1 (A), D352.1 (A); also elsewhere on the board
TC17_NA: C311.2, C313.1, R314.2; also elsewhere on the board
TC17_PA: C311.1, C312.1, R313.2; also elsewhere on the board
TC18_NA: C321.2, C323.1, R324.2; also elsewhere on the board
TC18_PA: C321.1, C322.1, R323.2; also elsewhere on the board
TC19_NA: C331.2, C333.1, R334.2; also elsewhere on the board
TC19_PA: C331.1, C332.1, R333.2; also elsewhere on the board
TC20_NA: C341.2, C343.1, R344.2; also elsewhere on the board
TC20_PA: C341.1, C342.1, R343.2; also elsewhere on the board
TC21_NA: C351.2, C353.1, R354.2; also elsewhere on the board
TC21_PA: C351.1, C352.1, R353.2; also elsewhere on the board
TC22+: J302.3; also elsewhere on the board
TC22-: J302.4; also elsewhere on the board
TC23+: J302.5; also elsewhere on the board
TC23-: J302.6; also elsewhere on the board
TC24+: J302.7; also elsewhere on the board
TC24-: J302.8; also elsewhere on the board
V_BIAS: C312.2, C313.2, C322.2, C323.2, C332.2, C333.2, C342.2, C343.2, C352.2, C353.2, R315.2, R325.2, R335.2, R345.2, R355.2; also elsewhere on the board

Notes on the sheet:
Thermocouple terminals (TC+ / TC- per channel; shield goes to the panel-entry bar)
Channel 17: limiter, clamp, filter, bias
Channel 18: limiter, clamp, filter, bias
Channel 19: limiter, clamp, filter, bias
Channel 20: limiter, clamp, filter, bias
Channel 21: limiter, clamp, filter, bias

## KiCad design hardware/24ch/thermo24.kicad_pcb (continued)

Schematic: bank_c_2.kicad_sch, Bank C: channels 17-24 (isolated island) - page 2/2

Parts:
C361, C371, C381: 10n C0G; C_0805_2012Metric; MPN GRM2195C1H103JA01D; LCSC C97905
C362, C363, C372, C373, C382, C383: 1n C0G; C_0805_2012Metric; MPN CL21C102JBCNNNC; LCSC C1791
C389, C390, C391, C392, C393, C394, C396, C398, C399: 100n; C_0805_2012Metric; MPN CC0805KRX7R9BB104; LCSC C49678
C395, C397: 1u; C_0805_2012Metric; MPN CL21B105KBFNNNE; LCSC C28323
D361, D362, D371, D372, D381, D382: BAV199; SOT-23; MPN BAV199,215; LCSC C40919
R361, R362, R371, R372, R381, R382: 2.2k; R_0805_2012Metric; MPN 0805W8F2201T5E; LCSC C17520
R363, R364, R373, R374, R383, R384: 1k; R_0805_2012Metric; MPN 0805W8F1001T5E; LCSC C17513
R365, R375, R385: 20M 1%; R_1206_3216Metric; MPN FRG1206F2005TS; LCSC C3000606
R391: 10k; R_0805_2012Metric; MPN 0805W8F1002T5E; LCSC C17414
U301: AD7124-8BCPZ; LFCSP-32-1EP_5x5mm_P0.5mm_EP3.6x3.6mm; MPN AD7124-8BCPZ; LCSC C97314
U302, U303: ADT7310TRZ; SOIC-8_3.9x4.9mm_P1.27mm; MPN ADT7310TRZ-REEL7; LCSC C578060

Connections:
+3V3_ISO: C390.1, C394.1, C395.1, C396.1, C397.1, C399.1, D361.2 (K), D362.2 (K), D371.2 (K), D372.2 (K), D381.2 (K), D382.2 (K), R391.2, U301.2 (IOVDD), U301.26 (AVDD), U302.8 (VDD), U303.8 (VDD); also elsewhere on the board
/BANK_C_2/REFOUT_C: C391.1, U301.22 (REFOUT)
/BANK_C_2/REGCAPA_C: C392.1, U301.24 (REGCAPA)
/BANK_C_2/REGCAPD_C: C393.1, U301.1 (REGCAPD)
/BANK_C_2/SYNC_C: R391.1, U301.27 (SYNC)
/BANK_C_2/TC22_NA: C361.2, C363.1, R364.2, U301.17 (AIN11)
/BANK_C_2/TC22_NC: D362.3 (common), R362.2, R364.1
/BANK_C_2/TC22_PA: C361.1, C362.1, R363.2, U301.16 (AIN10)
/BANK_C_2/TC22_PC: D361.3 (common), R361.2, R363.1
/BANK_C_2/TC23_NA: C371.2, C373.1, R374.2, U301.19 (AIN13)
/BANK_C_2/TC23_NC: D372.3 (common), R372.2, R374.1
/BANK_C_2/TC23_PA: C371.1, C372.1, R373.2, U301.18 (AIN12)
/BANK_C_2/TC23_PC: D371.3 (common), R371.2, R373.1
/BANK_C_2/TC24_NA: C381.2, C383.1, R384.2, U301.21 (AIN15)
/BANK_C_2/TC24_NC: D382.3 (common), R382.2, R384.1
/BANK_C_2/TC24_PA: C381.1, C382.1, R383.2, U301.20 (AIN14)
/BANK_C_2/TC24_PC: D381.3 (common), R381.2, R383.1
CS_ADC3_ISO: U301.32 (~CS); also elsewhere on the board
CS_CJ5_ISO: U302.4 (~CS); also elsewhere on the board
CS_CJ6_ISO: U303.4 (~CS); also elsewhere on the board
DIN_ISO: U301.29 (DIN), U302.3 (DIN), U303.3 (DIN); also elsewhere on the board
DOUT_ISO: U301.28 (DOUT/~RDY), U302.2 (DOUT), U303.2 (DOUT); also elsewhere on the board
GND_ISO: C389.2, C390.2, C391.2, C392.2, C393.2, C394.2, C395.2, C396.2, C397.2, C398.2, C399.2, D361.1 (A), D362.1 (A), D371.1 (A), D372.1 (A), D381.1 (A), D382.1 (A), U301.3 (DGND), U301.13 (REFIN1(-)), U301.23 (AVSS), U301.33 (EP), U302.7 (GND), U303.7 (GND); also elsewhere on the board
SCLK_ISO: U301.30 (SCLK), U302.1 (SCLK), U303.1 (SCLK); also elsewhere on the board
TC17_NA: U301.5 (AIN1); also elsewhere on the board
TC17_PA: U301.4 (AIN0); also elsewhere on the board
TC18_NA: U301.7 (AIN3); also elsewhere on the board
TC18_PA: U301.6 (AIN2); also elsewhere on the board
TC19_NA: U301.9 (AIN5); also elsewhere on the board
TC19_PA: U301.8 (AIN4); also elsewhere on the board
TC20_NA: U301.11 (AIN7); also elsewhere on the board
TC20_PA: U301.10 (AIN6); also elsewhere on the board
TC21_NA: U301.15 (AIN9); also elsewhere on the board
TC21_PA: U301.14 (AIN8); also elsewhere on the board
TC22+: R361.1; also elsewhere on the board
TC22-: R362.1, R365.1; also elsewhere on the board
TC23+: R371.1; also elsewhere on the board
TC23-: R372.1, R375.1; also elsewhere on the board
TC24+: R381.1; also elsewhere on the board
TC24-: R382.1, R385.1; also elsewhere on the board
VREF_EXT: C398.1, U301.12 (REFIN1(+)); also elsewhere on the board
V_BIAS: C362.2, C363.2, C372.2, C373.2, C382.2, C383.2, C389.1, R365.2, R375.2, R385.2; also elsewhere on the board

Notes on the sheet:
Channel 22: limiter, clamp, filter, bias
Channel 23: limiter, clamp, filter, bias
Channel 24: limiter, clamp, filter, bias
AD7124-8 #3 and its decoupling
Cold-junction sensors (one per 4-channel header)

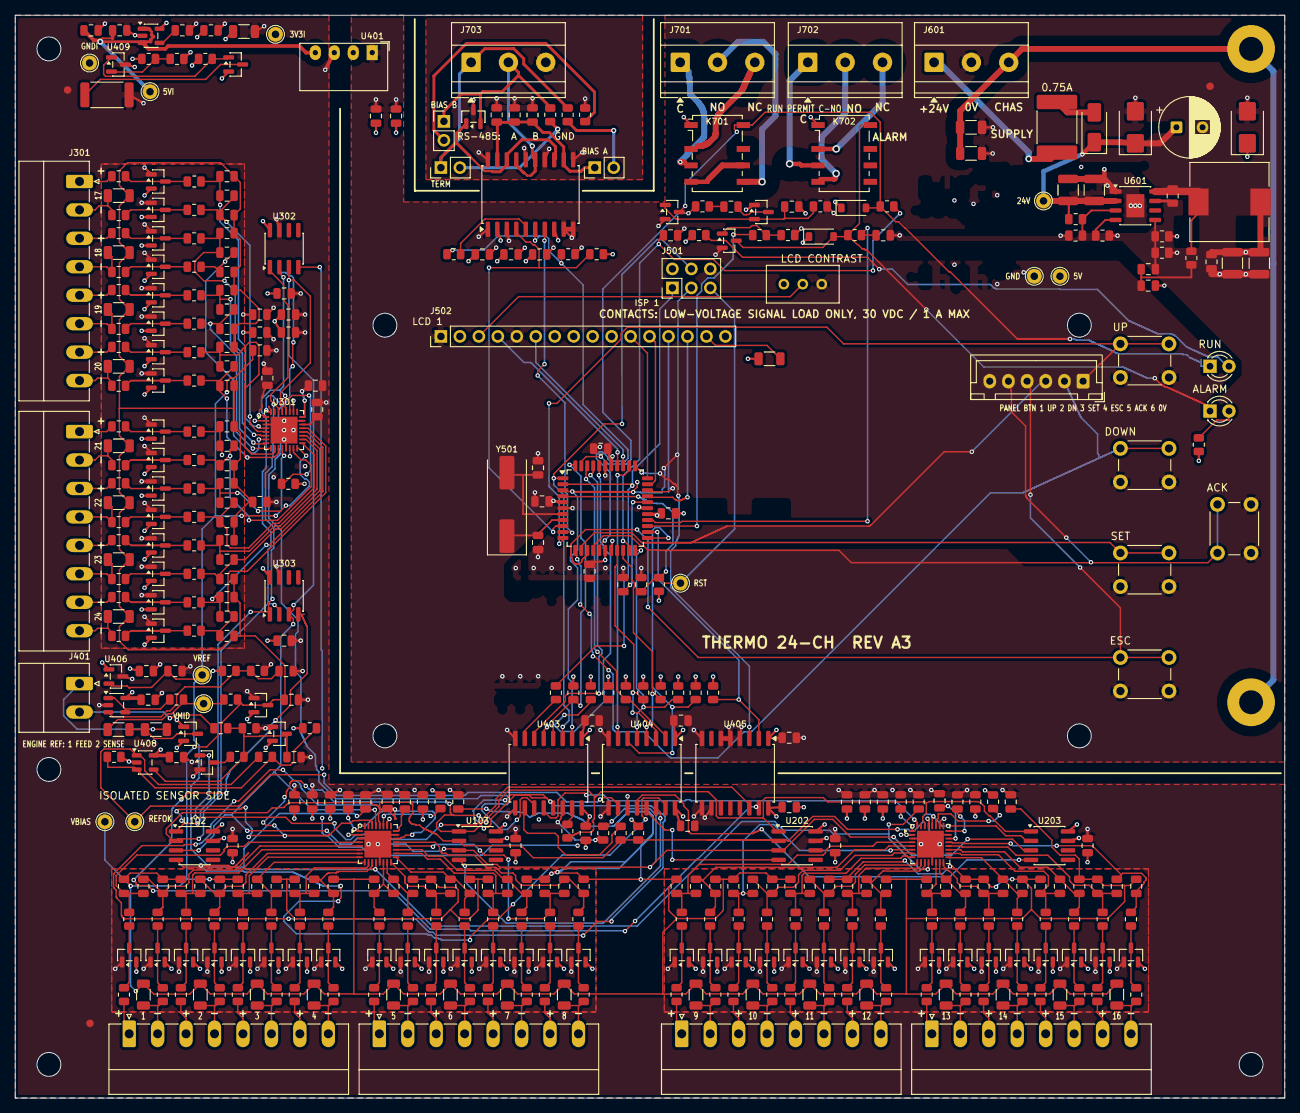
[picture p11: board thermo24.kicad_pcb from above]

Board: 4 copper layers, 170.0 x 145.0 mm, 466 parts (0 on the bottom side), 265 nets.

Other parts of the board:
FID1, FID2, FID3: Fiducial_1mm_Mask2mm

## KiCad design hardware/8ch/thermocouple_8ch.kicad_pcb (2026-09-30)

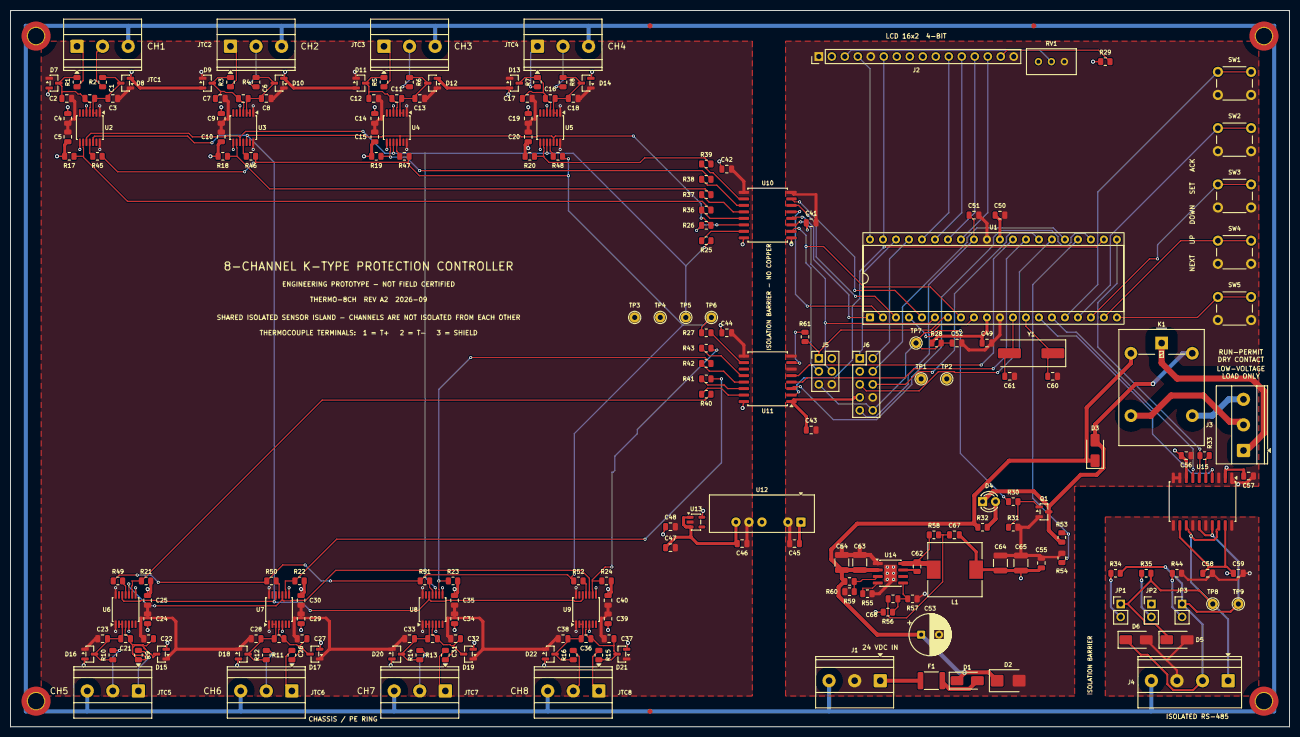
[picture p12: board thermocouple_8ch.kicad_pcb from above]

Board: 4 copper layers, 250.0 x 140.0 mm, 209 parts (0 on the bottom side), 130 nets.

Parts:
C1, C6, C11, C16, C21, C26, C31, C36: 100n X7R 50V; C_0805_2012Metric
C2, C3, C7, C8, C12, C13, C17, C18, C22, C23, C27, C28, C32, C33, C37, C38: 10n C0G 50V; C_0805_2012Metric
C4, C5, C9, C10, C14, C15, C19, C20, C24, C25, C29, C30, C34, C35, C39, C40, C41, C42, C43, C44, C49, C50, C51, C56, C58: 100n X7R; C_0805_2012Metric
C45, C46: 10u 10V; C_0805_2012Metric
C47: 1u X7R; C_0805_2012Metric
C48: 4.7u X7R 16V; C_0805_2012Metric
C52: 10n X7R; C_0805_2012Metric
C53: 22u 100V; CP_Radial_D8.0mm_P3.50mm
C54, C63: 4.7u 100V X7R; C_1210_3225Metric
C55: 10u 10V X7R; C_0805_2012Metric
C57, C59: 10u X7R; C_0805_2012Metric
C60, C61: 22p C0G 50V; C_0805_2012Metric
C62: 2.2n 50V X7R; C_0805_2012Metric
C64, C65: 22u 25V X7R; C_1210_3225Metric
C67: 3.3n 50V X7R; C_0805_2012Metric
C68: 220p C0G 50V; C_0805_2012Metric
D1: SS310; D_SMA
D2: SMBJ60A; D_SMB
D3: M7; D_SMA
D4: RUN PERMIT; LED_D3.0mm
D5, D6: SMAJ6.0CA; D_SMA
D7, D8, D9, D10, D11, D12, D13, D14, D15, D16, D17, D18, D19, D20, D21, D22: BAV199; SOT-23
F1: PTC 0.75A 60V; Fuse_1812_4532Metric
FID1: FID1; Fiducial_1mm_Mask2mm
FID2: FID2; Fiducial_1mm_Mask2mm
FID3: FID3; Fiducial_1mm_Mask2mm
H1: H1; MountingHole_3.2mm_M3_ISO7380_Pad_TopBottom
H2: H2; MountingHole_3.2mm_M3_ISO7380_Pad_TopBottom
H3: H3; MountingHole_3.2mm_M3_ISO7380_Pad_TopBottom
H4: H4; MountingHole_3.2mm_M3_ISO7380_Pad_TopBottom
J1: 24V_INPUT; TerminalBlock_Phoenix_MKDS-1,5-3_1x03_P5.00mm_Horizontal
J2: LCD_16x2_HEADER; PinHeader_1x16_P2.54mm_Vertical
J3: RELAY_COM_NO_NC; TerminalBlock_Phoenix_MKDS-1,5-3_1x03_P5.00mm_Horizontal
J4: RS485_A_B_GND_SHIELD; TerminalBlock_Phoenix_MKDS-1,5-4_1x04_P5.00mm_Horizontal
J5: AVR_ISP; PinHeader_2x03_P2.54mm_Vertical
J6: MCU_EXPANSION; PinHeader_2x05_P2.54mm_Vertical
JP1: TERM_ENABLE; PinHeader_1x02_P2.54mm_Vertical
JP2: BIAS_A_ENABLE; PinHeader_1x02_P2.54mm_Vertical
JP3: BIAS_B_ENABLE; PinHeader_1x02_P2.54mm_Vertical
JTC1, JTC2, JTC3, JTC4, JTC5, JTC6, JTC7, JTC8: K_TYPE; TerminalBlock_Phoenix_MKDS-1,5-3_1x03_P5.00mm_Horizontal
K1: G5LE-14 DC24; Relay_SPDT_Omron-G5LE-1
L1: 33u 2.2A; L_10.4x10.4_H4.8
Q1: BSS131; SOT-23
R1, R2, R3, R4, R5, R6, R7, R8, R9, R10, R11, R12, R13, R14, R15, R16: 100R 0.1%; R_0805_2012Metric
R17, R18, R19, R20, R21, R22, R23, R24, R28: 10k; R_0805_2012Metric
R25, R26, R27: 33R; R_0805_2012Metric
R29: 220R; R_0805_2012Metric
R30, R45, R46, R47, R48, R49, R50, R51, R52: 100R; R_0805_2012Metric
R31, R53: 100k; R_0805_2012Metric
R32: 4.7k 0.25W; R_0805_2012Metric
R33: 0R; R_0805_2012Metric
R34: 120R 1%; R_0805_2012Metric
R35, R44: 680R 1%; R_0805_2012Metric
R36, R37, R38, R39, R40, R41, R42, R43: 22R; R_0805_2012Metric
R54: 22k; R_0805_2012Metric
R55: 41.2k 1%; R_0805_2012Metric
R56: 158k 1%; R_0805_2012Metric
R57: 49.9k 1%; R_0805_2012Metric
R58: 150k 1%; R_0805_2012Metric
R59: 33.2k 1%; R_0805_2012Metric
R60: 10k 1%; R_0805_2012Metric
R61: 2k2; R_0805_2012Metric
RV1: 10k LCD CONTRAST; Potentiometer_Bourns_3296W_Vertical
SW1: NEXT; SW_PUSH_6mm
SW2: UP; SW_PUSH_6mm
SW3: DOWN; SW_PUSH_6mm
SW4: SET; SW_PUSH_6mm
SW5: ACK; SW_PUSH_6mm
TP1: GND_CTRL; TestPoint_THTPad_D2.0mm_Drill1.0mm
TP2: +5V_CTRL; TestPoint_THTPad_D2.0mm_Drill1.0mm
TP3: GND_SENS; TestPoint_THTPad_D2.0mm_Drill1.0mm
TP4: +3V3_SENS; TestPoint_THTPad_D2.0mm_Drill1.0mm
TP5: SCK_SENS; TestPoint_THTPad_D2.0mm_Drill1.0mm
TP6: MISO_SENS; TestPoint_THTPad_D2.0mm_Drill1.0mm
TP7: RESET_N; TestPoint_THTPad_D2.0mm_Drill1.0mm
TP8: RS485_A; TestPoint_THTPad_D2.0mm_Drill1.0mm
TP9: RS485_B; TestPoint_THTPad_D2.0mm_Drill1.0mm
U1: ATmega32A-PU; DIP-40_W15.24mm_Socket
U2, U3, U4, U5, U6, U7, U8, U9: MAX31856MUD+; TSSOP-14_4.4x5mm_P0.65mm
U10: ISO7760DWR; SOIC-16W_7.5x10.3mm_P1.27mm
U11: ISO7761DWR; SOIC-16W_7.5x10.3mm_P1.27mm
U12: IA0505S; Converter_DCDC_XP_POWER-IAxxxxS_THT
U13: LP2985-3.3; SOT-23-5
U14: LM5164DDAR; SOIC-8-1EP_3.9x4.9mm_P1.27mm_EP2.41x3.3mm
U15: ADM2587EBRWZ; SOIC-20W_7.5x12.8mm_P1.27mm
Y1: 8MHz 20pF; Crystal_SMD_HC49-SD

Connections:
/+3V3_SENS: C4.1, C5.1, C9.1, C10.1, C14.1, C15.1, C19.1, C20.1, C24.1, C25.1, C29.1, C30.1, C34.1, C35.1, C39.1, C40.1, C42.1, C44.1, C48.1, D7.2 (K), D8.2 (K), D9.2 (K), D10.2 (K), D11.2 (K), D12.2 (K), D13.2 (K), D14.2 (K), D15.2 (K), D16.2 (K), D17.2 (K), D18.2 (K), D19.2 (K), D20.2 (K), D21.2 (K), D22.2 (K), R17.1, R18.1, R19.1, R20.1, R21.1, R22.1, R23.1, R24.1, TP4.1 (Pin_1_1), U2.5 (AVDD), U2.8 (DVDD), U3.5 (AVDD), U3.8 (DVDD), U4.5 (AVDD), U4.8 (DVDD), U5.5 (AVDD), U5.8 (DVDD), U6.5 (AVDD), U6.8 (DVDD), U7.5 (AVDD), U7.8 (DVDD), U8.5 (AVDD), U8.8 (DVDD), U9.5 (AVDD), U9.8 (DVDD), U10.16 (Vcc2), U11.16 (Vcc2), U13.5 (VOUT)
/+5V_CTRL: C41.1, C43.1, C45.1, C49.1, C50.1, C55.1, C56.1, C57.1, C64.1, C65.1, C67.2, J2.2, J5.2, J6.7, L1.2, R28.1, R29.1, R56.1, RV1.3, TP2.1 (Pin_1_1), U1.10 (VCC), U1.30 (AVCC), U10.1 (Vcc1), U11.1 (Vcc1), U12.1 (+Vin), U15.2 (VCC), U15.8 (VCC)
/+24V_PROT: C53.1, C54.1, C63.1, D1.1 (K), D2.1 (K), D3.1 (K), K1.2, R32.1, R59.1, U14.2 (VIN)
/CHASSIS_SHIELD: H1.1, H2.1, H3.1, H4.1, J1.3, J4.4, JTC1.3, JTC2.3, JTC3.3, JTC4.3, JTC5.3, JTC6.3, JTC7.3, JTC8.3
/CS1_CTRL: U1.1 (PB0), U10.4 (INC)
/CS1_SENS: R17.2, R36.2, U2.9 (~CS)
/CS2_CTRL: U1.2 (PB1), U10.5 (IND)
/CS2_SENS: R18.2, R37.2, U3.9 (~CS)
/CS3_CTRL: U1.3 (PB2), U10.6 (INE)
/CS3_SENS: R19.2, R38.2, U4.9 (~CS)
/CS4_CTRL: U1.5 (PB4), U10.7 (INF)
/CS4_SENS: R20.2, R39.2, U5.9 (~CS)
/CS5_CTRL: U1.22 (PC0), U11.2 (INA)
/CS5_SENS: R21.2, R40.2, U6.9 (~CS)
/CS6_CTRL: U1.23 (PC1), U11.3 (INB)
/CS6_SENS: R22.2, R41.2, U7.9 (~CS)
/CS7_CTRL: U1.28 (PC6), U11.4 (INC)
/CS7_SENS: R23.2, R42.2, U8.9 (~CS)
/CS8_CTRL: U1.29 (PC7), U11.5 (IND)
/CS8_SENS: R24.2, R43.2, U9.9 (~CS)
/GND_CTRL: C41.2, C43.2, C45.2, C49.2, C50.2, C51.2, C52.2, C53.2, C54.2, C55.2, C56.2, C57.2, C60.2, C61.2, C63.2, C64.2, C65.2, D2.2 (A), J1.2, J2.1, J2.5, J2.16, J5.6, J6.8, Q1.2 (S), R31.2, R54.2, R55.2, R57.2, R60.2, RV1.1, SW1.2, SW2.2, SW3.2, SW4.2, SW5.2, TP1.1 (Pin_1_1), U1.11 (GND), U1.31 (GND), U10.8 (GND1), U11.6 (INE), U11.8 (GND1), U12.2 (-Vin), U14.1 (GND), U14.9 (EP), U15.1 (GND1), U15.3 (GND1), U15.9 (GND1), U15.10 (GND1)
/GND_SENS: C2.2, C3.2, C4.2, C5.2, C7.2, C8.2, C9.2, C10.2, C12.2, C13.2, C14.2, C15.2, C17.2, C18.2, C19.2, C20.2, C22.2, C23.2, C24.2, C25.2, C27.2, C28.2, C29.2, C30.2, C32.2, C33.2, C34.2, C35.2, C37.2, C38.2, C39.2, C40.2, C42.2, C44.2, C46.2, C47.2, C48.2, D7.1 (A), D8.1 (A), D9.1 (A), D10.1 (A), D11.1 (A), D12.1 (A), D13.1 (A), D14.1 (A), D15.1 (A), D16.1 (A), D17.1 (A), D18.1 (A), D19.1 (A), D20.1 (A), D21.1 (A), D22.1 (A), TP3.1 (Pin_1_1), U2.1 (AGND), U2.14 (DGND), U3.1 (AGND), U3.14 (DGND), U4.1 (AGND), U4.14 (DGND), U5.1 (AGND), U5.14 (DGND), U6.1 (AGND), U6.14 (DGND), U7.1 (AGND), U7.14 (DGND), U8.1 (AGND), U8.14 (DGND), U9.1 (AGND), U9.14 (DGND), U10.9 (GND2), U11.9 (GND2), U12.5 (0V), U13.2 (GND)
/ISOLATION/+5V_ISO: C46.1, C47.1, U12.6 (+Vout), U13.1 (VIN), U13.3 (ON/~OFF)
/ISOLATION/CS1_SENS_RAW: R36.1, U10.13 (OUTC)
/ISOLATION/CS2_SENS_RAW: R37.1, U10.12 (OUTD)
/ISOLATION/CS3_SENS_RAW: R38.1, U10.11 (OUTE)
/ISOLATION/CS4_SENS_RAW: R39.1, U10.10 (OUTF)
/ISOLATION/CS5_SENS_RAW: R40.1, U11.15 (OUTA)
/ISOLATION/CS6_SENS_RAW: R41.1, U11.14 (OUTB)
/ISOLATION/CS7_SENS_RAW: R42.1, U11.13 (OUTC)
/ISOLATION/CS8_SENS_RAW: R43.1, U11.12 (OUTD)
/ISOLATION/MISO_ISO: R61.2, U11.7 (OUTF)
/ISOLATION/MISO_SENS_RAW: R27.2, U11.10 (INF)
/ISOLATION/MOSI_SENS_RAW: R26.1, U10.14 (OUTB)
/ISOLATION/SCK_SENS_RAW: R25.1, U10.15 (OUTA)
/MCU/AREF: C51.1, J6.9, U1.32 (AREF)
/MCU/BTN_ACK: SW5.1, U1.20 (PD6)
/MCU/BTN_DOWN: SW3.1, U1.18 (PD4)
/MCU/BTN_NEXT: SW1.1, U1.16 (PD2)
/MCU/BTN_SET: SW4.1, U1.19 (PD5)
/MCU/BTN_UP: SW2.1, U1.17 (PD3)
/MCU/LCD_D4: J2.11, U1.36 (PA4)
/MCU/LCD_D5: J2.12, U1.35 (PA5)
/MCU/LCD_D6: J2.13, U1.34 (PA6)
/MCU/LCD_D7: J2.14, U1.33 (PA7)
/MCU/LCD_E: J2.6, U1.39 (PA1)
/MCU/LCD_LED_A: J2.15, R29.2
/MCU/LCD_RS: J2.4, U1.40 (PA0)
/MCU/LCD_VO: J2.3, RV1.2
/MCU/RESET_N: C52.1, J5.5, J6.10, R28.2, TP7.1 (Pin_1_1), U1.9 (~RESET)
/MCU/SPARE_PA2: J6.1, U1.38 (PA2)
/MCU/SPARE_PA3: J6.2, U1.37 (PA3)
/MCU/SPARE_PC3: J6.4, U1.25 (PC3)
/MCU/SPARE_PC4: J6.5, U1.26 (PC4)
/MCU/SPARE_PC5: J6.6, U1.27 (PC5)
/MCU/XTAL1: C60.1, U1.13 (XTAL1), Y1.1
/MCU/XTAL2: C61.1, U1.12 (XTAL2), Y1.2
/MISO_CTRL: J5.1, R61.1, U1.7 (PB6)
/MISO_SENS: R27.1, R45.2, R46.2, R47.2, R48.2, R49.2, R50.2, R51.2, R52.2, TP6.1 (Pin_1_1)
/MOSI_CTRL: J5.4, U1.6 (PB5), U10.3 (INB)
/MOSI_SENS: R26.2, U2.12 (SDI), U3.12 (SDI), U4.12 (SDI), U5.12 (SDI), U6.12 (SDI), U7.12 (SDI), U8.12 (SDI), U9.12 (SDI)
/POWER/+24V_FUSED: D1.2 (A), F1.2
/POWER/+24V_RAW: F1.1, J1.1
/POWER/BST_5V: C62.1, U14.7 (BST)
/POWER/FB_5V: C68.2, R56.2, R57.1, U14.5 (FB)
/POWER/RIPPLE_INJ: C67.1, C68.1, R58.2
/POWER/RON_SET: R55.1, U14.4 (RON)
/POWER/SW_5V: C62.2, L1.1, R58.1, U14.8 (SW)
/POWER/VIN_UVLO: R59.2, R60.1, U14.3 (EN/UVLO)
/RELAY_RS485/+5V_RS485: C58.1, C59.1, JP2.1, U15.12 (Visoout), U15.19 (Visoin)
/RELAY_RS485/GND_RS485: C58.2, C59.2, D5.2 (A2), D6.2 (A2), J4.3, R44.2, U15.11 (GND2), U15.14 (GND2), U15.16 (GND2), U15.20 (GND2)
/RELAY_RS485/RELAY_COM: J3.1, K1.1
/RELAY_RS485/RELAY_GATE: Q1.1 (G), R30.2, R31.1
/RELAY_RS485/RELAY_LED_A: D4.2 (A), R32.2
/RELAY_RS485/RELAY_LOW: D3.2 (A), D4.1 (K), K1.5, Q1.3 (D), R53.1
/RELAY_RS485/RELAY_NC: J3.3, K1.4
/RELAY_RS485/RELAY_NO: J3.2, K1.3
/RELAY_RS485/RS485_A: D5.1 (A1), J4.1, JP1.1, R35.2, TP8.1 (Pin_1_1), U15.13 (Y), U15.18 (A)
/RELAY_RS485/RS485_B: D6.1 (A1), J4.2, JP3.1, R34.2, TP9.1 (Pin_1_1), U15.15 (Z), U15.17 (B)
/RELAY_RS485/RS485_BIAS_A: JP2.2, R35.1
/RELAY_RS485/RS485_BIAS_B: JP3.2, R44.1
/RELAY_RS485/RS485_RE_N: R33.2, U15.5 (~RE)
/RELAY_RS485/RS485_TERM_A: JP1.2, R34.1
/RS485_DE: R33.1, U1.21 (PD7), U15.6 (DE)
/RUN_PERMIT: R30.1, U1.4 (PB3)
/RUN_PERMIT_SENSE: R53.2, R54.1, U1.24 (PC2)
/SCK_CTRL: J5.3, U1.8 (PB7), U10.2 (INA)
/SCK_SENS: R25.2, TP5.1 (Pin_1_1), U2.10 (SCK), U3.10 (SCK), U4.10 (SCK), U5.10 (SCK), U6.10 (SCK), U7.10 (SCK), U8.10 (SCK), U9.10 (SCK)
/TC1/FILT_N: C1.2, C3.1, D8.3 (common), R2.2, U2.2 (BIAS), U2.3 (T-)
/TC1/FILT_P: C1.1, C2.1, D7.3 (common), R1.2, U2.4 (T+)
/TC1/MISO_CH: R45.1, U2.11 (SDO)
/TC1/RAW_N: JTC1.2, R2.1
/TC1/RAW_P: JTC1.1, R1.1
/TC2/FILT_N: C6.2, C8.1, D10.3 (common), R4.2, U3.2 (BIAS), U3.3 (T-)
/TC2/FILT_P: C6.1, C7.1, D9.3 (common), R3.2, U3.4 (T+)
/TC2/MISO_CH: R46.1, U3.11 (SDO)
/TC2/RAW_N: JTC2.2, R4.1
/TC2/RAW_P: JTC2.1, R3.1
/TC3/FILT_N: C11.2, C13.1, D12.3 (common), R6.2, U4.2 (BIAS), U4.3 (T-)
/TC3/FILT_P: C11.1, C12.1, D11.3 (common), R5.2, U4.4 (T+)
/TC3/MISO_CH: R47.1, U4.11 (SDO)
/TC3/RAW_N: JTC3.2, R6.1
/TC3/RAW_P: JTC3.1, R5.1
/TC4/FILT_N: C16.2, C18.1, D14.3 (common), R8.2, U5.2 (BIAS), U5.3 (T-)
/TC4/FILT_P: C16.1, C17.1, D13.3 (common), R7.2, U5.4 (T+)
/TC4/MISO_CH: R48.1, U5.11 (SDO)
/TC4/RAW_N: JTC4.2, R8.1
/TC4/RAW_P: JTC4.1, R7.1
/TC5/FILT_N: C21.2, C23.1, D16.3 (common), R10.2, U6.2 (BIAS), U6.3 (T-)
/TC5/FILT_P: C21.1, C22.1, D15.3 (common), R9.2, U6.4 (T+)
/TC5/MISO_CH: R49.1, U6.11 (SDO)
/TC5/RAW_N: JTC5.2, R10.1
/TC5/RAW_P: JTC5.1, R9.1
/TC6/FILT_N: C26.2, C28.1, D18.3 (common), R12.2, U7.2 (BIAS), U7.3 (T-)
/TC6/FILT_P: C26.1, C27.1, D17.3 (common), R11.2, U7.4 (T+)
/TC6/MISO_CH: R50.1, U7.11 (SDO)
/TC6/RAW_N: JTC6.2, R12.1
/TC6/RAW_P: JTC6.1, R11.1
/TC7/FILT_N: C31.2, C33.1, D20.3 (common), R14.2, U8.2 (BIAS), U8.3 (T-)
/TC7/FILT_P: C31.1, C32.1, D19.3 (common), R13.2, U8.4 (T+)
/TC7/MISO_CH: R51.1, U8.11 (SDO)
/TC7/RAW_N: JTC7.2, R14.1
/TC7/RAW_P: JTC7.1, R13.1
/TC8/FILT_N: C36.2, C38.1, D22.3 (common), R16.2, U9.2 (BIAS), U9.3 (T-)
/TC8/FILT_P: C36.1, C37.1, D21.3 (common), R15.2, U9.4 (T+)
/TC8/MISO_CH: R52.1, U9.11 (SDO)
/TC8/RAW_N: JTC8.2, R16.1
/TC8/RAW_P: JTC8.1, R15.1
/UART_RX: U1.14 (PD0), U15.4 (RxD)
/UART_TX: U1.15 (PD1), U15.7 (TxD)

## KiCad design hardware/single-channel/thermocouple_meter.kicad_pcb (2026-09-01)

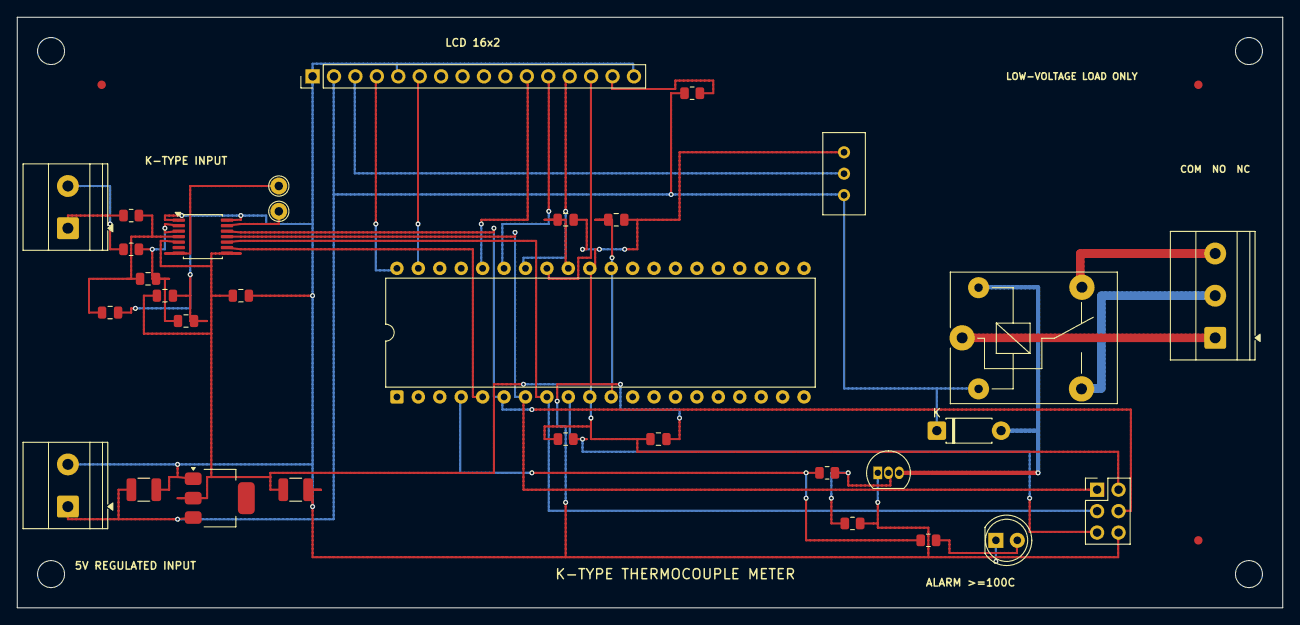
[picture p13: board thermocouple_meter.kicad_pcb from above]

Board: 2 copper layers, 150.0 x 70.0 mm, 39 parts (0 on the bottom side), 30 nets.

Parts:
C1, C2: 10uF 10V; C_1210_3225Metric
C3: 100nF MCU VCC; C_0805_2012Metric
C4: 100nF MCU AVCC; C_0805_2012Metric
C5: 100nF MAX AVDD; C_0805_2012Metric
C6: 100nF MAX DVDD; C_0805_2012Metric
C7: 100nF TC DIFF; C_0805_2012Metric
C8: 10nF TC+; C_0805_2012Metric
C9: 10nF TC-; C_0805_2012Metric
C10: 100nF AREF; C_0805_2012Metric
D1: 1N4007 FLYBACK; D_DO-41_SOD81_P7.62mm_Horizontal
D2: ALARM LED; LED_D5.0mm_Clear
FID1, FID2, FID3: FIDUCIAL; Fiducial_1mm_Mask2mm
H1, H2, H3, H4: M3; MountingHole_3.2mm_M3
J1: 5V_INPUT; TerminalBlock_Phoenix_MKDS-1,5-2_1x02_P5.00mm_Horizontal
J2: LCD_16x2; PinHeader_1x16_P2.54mm_Vertical
J3: K-TYPE; TerminalBlock_Phoenix_MKDS-1,5-2_1x02_P5.00mm_Horizontal
J4: AVR_ISP; PinHeader_2x03_P2.54mm_Vertical
J5: RELAY_COM_NO_NC; TerminalBlock_Phoenix_MKDS-1,5-3_1x03_P5.00mm_Horizontal
K1: SRD-05VDC-SL-C; Relay_SPDT_SANYOU_SRD_Series_Form_C
Q1: 2N3904 E-B-C; TO-92_Inline
R1, R2: 100R 0.1%; R_0805_2012Metric
R3: 10k RESET; R_0805_2012Metric
R4: 1k RELAY BASE; R_0805_2012Metric
R5: 10k BASE PULLDOWN; R_0805_2012Metric
R6: 1k ALARM LED; R_0805_2012Metric
R7: 100R LCD LED; R_0805_2012Metric
RV1: 10k LCD CONTRAST; Potentiometer_Bourns_3296W_Vertical
TP1: DRDY; TestPoint_THTPad_D2.0mm_Drill1.0mm
TP2: FAULT; TestPoint_THTPad_D2.0mm_Drill1.0mm
U1: ATmega32A-PU; DIP-40_W15.24mm
U2: MAX31856MUD+; TSSOP-14_4.4x5mm_P0.65mm
U3: AMS1117-3.3; SOT-223-3_TabPin2

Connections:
+3V3: C2.1, C3.1, C4.1, C5.1, C6.1, J4.2, R3.1, U1.10, U1.30, U2.5, U2.8, U3.2
+5V: C1.1, D1.1, J1.1, J2.2, K1.2, R7.1, RV1.3, U3.3
ALARM_BASE: Q1.2, R4.2, R5.1
ALARM_GPIO: R4.1, R6.1, U1.4
ALARM_LED_A: D2.2, R6.2
AREF: C10.1, U1.32
GND: C1.2, C2.2, C3.2, C4.2, C5.2, C6.2, C8.2, C9.2, C10.2, D2.1, J1.2, J2.1, J2.5, J2.16, J4.6, Q1.1, R5.2, RV1.1, U1.11, U1.31, U2.1, U2.14, U3.1
LCD_D4: J2.11, U1.36
LCD_D5: J2.12, U1.35
LCD_D6: J2.13, U1.34
LCD_D7: J2.14, U1.33
LCD_E: J2.6, U1.39
LCD_LED_A: J2.15, R7.2
LCD_RS: J2.4, U1.40
LCD_VO: J2.3, RV1.2
MAX_DRDY: TP1.1, U2.7
MAX_FAULT: TP2.1, U2.13
RELAY_COM: J5.1, K1.1
RELAY_LOW: D1.2, K1.5, Q1.3
RELAY_NC: J5.3, K1.4
RELAY_NO: J5.2, K1.3
RESET: J4.5, R3.2, U1.9
SPI_CS: U1.5, U2.9
SPI_MISO: J4.1, U1.7, U2.11
SPI_MOSI: J4.4, U1.6, U2.12
SPI_SCK: J4.3, U1.8, U2.10
TC_MINUS: C7.2, C9.1, R2.2, U2.2, U2.3
TC_PLUS: C7.1, C8.1, R1.2, U2.4
TC_RAW_MINUS: J3.2, R2.1
TC_RAW_PLUS: J3.1, R1.1

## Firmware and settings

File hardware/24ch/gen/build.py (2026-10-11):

"""Generate the 24-channel schematic, run ERC, and check the netlist against the model.

    python build.py            # writes ../thermo24*.kicad_sch, ../lib/thermo24.kicad_sym
"""
import json
import os
import shutil
import subprocess
import sys
import time
import xml.etree.ElementTree as ET
from collections import defaultdict

import customlib
from model import Part, Sheet
from emit import SheetWriter, uid, effects, prop
from sexp import Sym, dump
from c_bank import bank
from c_iso import isolation
from c_mcu import mcu
from c_out import outputs
from c_power import power

HERE = os.path.dirname(os.path.abspath(__file__))
OUT = os.environ.get("THERMO24_SCH_OUT") or os.path.dirname(HERE)   # env: test on a scratch folder
LIB = os.path.join(OUT, "lib")
PROJECT = "thermo24"
ROOT_UUID = uid("root")
CLI = os.environ.get("KICAD_CLI", r"C:\Program Files\KiCad\10.0\bin\kicad-cli.exe")


def sheets():
    return [power(), mcu(), isolation(), outputs(), bank(1), bank(2), bank(3)]


def add_flags(all_sheets):
    for s in all_sheets:
        if s.flags:
            s.block("Power flags (ERC only)", [
                Part(f"#FLG{s.name[:3]}{i}", "power:PWR_FLAG", "PWR_FLAG", {"1": net}, "",
                     in_bom=False, on_board=False) for i, net in enumerate(s.flags)])


PRINTABLE = ("A4", "A3")     # the owner prints A4 or A3 only (2026-10-08)


def paginate(s, all_nets):
    """Split a sheet into A3-or-smaller pages, keeping its blocks in order.

    Fit is tested with every net drawn as a (longer) global label, so the real
    page never comes out bigger than the test page."""
    def fits(blocks):
        t = Sheet(s.name, s.file, s.title, "A4")
        t.blocks = blocks
        SheetWriter(t, all_nets, PROJECT, ROOT_UUID, None, LIB).layout()
        return t.paper in PRINTABLE
    pages, cur = [], []
    for blk in s.blocks:
        if cur and not fits(cur + [blk]):
            pages.append(cur)
            cur = []
        cur.append(blk)
    pages.append(cur)
    if len(pages) == 1:
        s.paper = "A4"
        return [s]
    out = []
    base = s.file[:-len(".kicad_sch")]
    for i, blocks in enumerate(pages, 1):
        t = Sheet(f"{s.name}_{i}", f"{base}_{i}.kicad_sch", f"{s.title} - page {i}/{len(pages)}", "A4")
        t.blocks = blocks
        t.notes = s.notes if i == 1 else []
        out.append(t)
    return out


def root_parts():
    holes = []
    for i in (1, 2, 3, 10):
        holes.append(Part(f"H{i}", "Mechanical:MountingHole", "M3 NPTH island", {},
                          "MountingHole:MountingHole_3.2mm_M3", desc="insulating spacer"))
    for i in (4, 5):
        holes.append(Part(f"H{i}", "Mechanical:MountingHole_Pad", "M3 CHASSIS", {"1": "CHASSIS"},
                          "MountingHole:MountingHole_3.2mm_M3_Pad"))
    for i in range(6, 10):
        holes.append(Part(f"H{i}", "Mechanical:MountingHole", "M3 LCD standoff", {},
                          "MountingHole:MountingHole_3.2mm_M3"))
    return holes


def sheet_block(s, x, y, page):
    su = uid(f"sheet:{s.name}")
    w, h = 50.8, 20.32
    return su, [Sym("sheet"), [Sym("at"), x, y], [Sym("size"), w, h],
                [Sym("exclude_from_sim"), Sym("no")], [Sym("in_bom"), Sym("yes")],
                [Sym("on_board"), Sym("yes")], [Sym("dnp"), Sym("no")],
                [Sym("fields_autoplaced"), Sym("yes")],
                [Sym("stroke"), [Sym("width"), 0.1524], [Sym("type"), Sym("solid")]],
                [Sym("fill"), [Sym("color"), 0, 0, 0, 0.0]], [Sym("uuid"), su],
                prop("Sheetname", s.name, x, y - 0.7, justify="left bottom"),
                prop("Sheetfile", s.file, x, y + h + 0.6, justify="left top"),
                [Sym("instances"), [Sym("project"), PROJECT,
                 [Sym("path"), f"/{ROOT_UUID}", [Sym("page"), str(page)]]]]]


def main():
    os.makedirs(OUT, exist_ok=True)
    customlib.write(os.path.join(LIB, "thermo24.kicad_sym"))
    all_sheets = sheets()
    add_flags(all_sheets)
    all_nets = {n for sh in all_sheets for p in sh.parts() for n in p.resolve(LIB).values()}
    all_sheets = [pg for sh in all_sheets for pg in paginate(sh, all_nets)]
    for f in os.listdir(OUT):       # pages from an earlier split that no longer exist
        if f.endswith(".kicad_sch") and f != f"{PROJECT}.kicad_sch" and f not in {sh.file for sh in all_sheets}:
            os.remove(os.path.join(OUT, f))
    root = Sheet("ROOT", f"{PROJECT}.kicad_sch", "Thermo 24-channel protection unit - REV A3", "A3")
    root.block("Mounting holes: island NPTH + insulating spacers, control plated to CHASSIS, LCD standoffs",
               root_parts())
    model_parts = {}
    net_sheets = defaultdict(set)
    for s in all_sheets + [root]:
        for p in s.parts():
            if p.ref in model_parts:
                raise SystemExit(f"duplicate reference {p.ref}")
            model_parts[p.ref] = p
            for net in p.resolve(LIB).values():
                if net != "<NC>":
                    net_sheets[net].add(s.name)
    glob = {n for n, ss in net_sheets.items() if len(ss) > 1}
    blocks = []
    for i, s in enumerate(all_sheets):
        su, blk = sheet_block(s, 25.4 + (i % 5) * 76.2, 120 + (i // 5) * 35.56, i + 2)
        blocks.append(blk)
        text = SheetWriter(s, glob, PROJECT, ROOT_UUID, su, LIB).build()
        with open(os.path.join(OUT, s.file), "w", encoding="utf-8", newline="\n") as f:
            f.write(text)
    text = SheetWriter(root, glob, PROJECT, ROOT_UUID, None, LIB).build(extra=blocks)
    with open(os.path.join(OUT, root.file), "w", encoding="utf-8", newline="\n") as f:
        f.write(text)
    write_project()
    fplibs = sorted({p.footprint.split(":")[0] for p in model_parts.values() if p.footprint})
    with open(os.path.join(OUT, "fp-lib-table"), "w", encoding="utf-8", newline="\n") as f:
        f.write("(fp_lib_table\n  (version 7)\n")
        for lib in fplibs:
            f.write(f'  (lib (name "{lib}") (type "KiCad") (uri "${{KICAD10_FOOTPRINT_DIR}}/{lib}.pretty")'
                    ' (options "") (descr ""))\n')
        f.write(")\n")
    print(f"{len(model_parts)} symbols, {len(net_sheets)} nets ({len(glob)} global)")
    big = [f"{sh.file}={sh.paper}" for sh in all_sheets + [root] if sh.paper not in PRINTABLE]
    print("pages:", ", ".join(f"{sh.file}={sh.paper}" for sh in all_sheets + [root]))
    if big:
        raise SystemExit(f"pages larger than A3: {big}")
    ok = run_erc() & check_netlist(model_parts)
    sys.exit(0 if ok else 1)


def write_project():
    pro = os.path.join(OUT, f"{PROJECT}.kicad_pro")
    if not os.path.exists(pro):
        with open(pro, "w", encoding="utf-8") as f:
            json.dump({"meta": {"filename": f"{PROJECT}.kicad_pro", "version": 3}}, f, indent=2)
    table = os.path.join(OUT, "sym-lib-table")
    with open(table, "w", encoding="utf-8", newline="\n") as f:
        f.write('(sym_lib_table\n  (version 7)\n  (lib (name "thermo24")(type "KiCad")'
                '(uri "${KIPRJMOD}/lib/thermo24.kicad_sym")(options "")(descr "project parts"))\n)\n')


def kicad(args, out, ok=(0,)):
    """Run kicad-cli; return (returncode, text of `out`). Exits unless the tool ran,
    returned one of `ok`, and wrote `out` during this call (an old file proves nothing)."""
    if os.path.exists(out):
        os.remove(out)
    t0 = time.time() - 2          # file-system mtime granularity
    try:
        r = subprocess.run([CLI, *args], capture_output=True, text=True)
    except OSError as e:
        raise SystemExit(f"kicad-cli not runnable ({CLI}): {e}")
    if r.returncode not in ok:
        raise SystemExit(f"kicad-cli {' '.join(args[:3])} failed, exit {r.returncode}: "
                         f"{(r.stderr or r.stdout)[-400:]}")
    if not os.path.exists(out) or os.path.getmtime(out) < t0:
        raise SystemExit(f"kicad-cli {' '.join(args[:3])} exit {r.returncode} but wrote no fresh {out}")
    with open(out, encoding="utf-8") as f:
        return r.returncode, f.read()


def run_erc():
    """ERC gate: 0 errors and 0 warnings. kicad-cli exit 5 = violations found (fail, report
    printed); any other non-zero exit, or no fresh report, is a tool failure (exit)."""
    rpt = os.path.join(OUT, "erc-report.rpt")
    rc, txt = kicad(["sch", "erc", "--exit-code-violations", "--severity-error", "--severity-warning",
                     "-o", rpt, os.path.join(OUT, f"{PROJECT}.kicad_sch")], rpt, ok=(0, 5))
    tail = [l for l in txt.splitlines() if "ERC messages" in l or "Errors" in l]
    print("ERC:", " | ".join(tail) or txt[-300:], f"(kicad-cli exit {rc})")
    return rc == 0 and "** ERC messages: 0" in txt


def check_netlist(model_parts):
    xml = os.path.join(OUT, f"{PROJECT}.xml")
    _, txt = kicad(["sch", "export", "netlist", "--format", "kicadxml", "-o", xml,
                    os.path.join(OUT, f"{PROJECT}.kicad_sch")], xml)
    r = ET.fromstring(txt)
    got = {}
    for n in r.iter("net"):
        name = n.get("name").rsplit("/", 1)[-1]
        for nd in n.iter("node"):
            got[(nd.get("ref"), nd.get("pin"))] = name
    bad = 0
    for ref, p in model_parts.items():
        if ref.startswith("#"):
            continue
        for pin, net in p.pinmap.items():
            g = got.get((ref, pin))
            want_nc = net == "<NC>"
            if want_nc and (g is None or g.startswith("unconnected-")):
                continue
            if g != net:
                bad += 1
                if bad <= 20:
                    print(f"  NETLIST MISMATCH {ref}.{pin}: model {net} vs schematic {g}")
    comps = {c.get("ref") for c in r.iter("comp")}
    missing = [x for x in model_parts if not x.startswith("#") and x not in comps]
    print(f"netlist check: {bad} pin mismatches, {len(missing)} missing parts")
    return bad == 0 and not missing


if __name__ == "__main__":
    main()

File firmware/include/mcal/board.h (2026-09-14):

#ifndef MCAL_BOARD_H
#define MCAL_BOARD_H

#include "mcal/gpio.h"

#include <stdint.h>

/* Physical ATmega32A wiring used by both firmware variants. */
extern const mcal_gpio_port_t BOARD_LCD_PORT;
extern const mcal_gpio_pin_t BOARD_LCD_RS;
extern const mcal_gpio_pin_t BOARD_LCD_ENABLE;
extern const mcal_gpio_pin_t BOARD_SENSOR_CS;
extern const mcal_gpio_pin_t BOARD_SENSOR_CS_PINS[8];
extern const mcal_gpio_pin_t BOARD_ALARM_OUTPUT;
extern const mcal_gpio_pin_t BOARD_RUN_PERMIT;
extern const mcal_gpio_pin_t BOARD_RUN_PERMIT_SENSE;
extern const mcal_gpio_pin_t BOARD_BUTTON_NEXT;
extern const mcal_gpio_pin_t BOARD_BUTTON_UP;
extern const mcal_gpio_pin_t BOARD_BUTTON_DOWN;
extern const mcal_gpio_pin_t BOARD_BUTTON_SET;
extern const mcal_gpio_pin_t BOARD_BUTTON_ACK;

#define BOARD_LCD_DATA_MASK 0xF0u
#define BOARD_SENSOR_COUNT 8u

/* PB3 is ATmega32A DIP-40 physical pin 4. */
#define BOARD_ALARM_OUTPUT_PORT_NAME "PB3"
#define BOARD_ALARM_OUTPUT_DIP_PIN   4u

/* Run-permit driver read-back (I-016).
 *
 * REV A0 does NOT have it: PC2 is an unconnected SPARE pin, so the check is
 * compiled out and hal_run_permit_readback_agrees() always reports agreement.
 * The R53/R54 divider from RELAY_LOW is part of the REV A1 change set in
 * docs/decisions/0010; set this to 1 in the same commit that adds it.
 *
 * PC2 is ATmega32A DIP-40 physical pin 24, and JTAG TCK until JTAGEN is
 * unprogrammed.  Without that fuse the read-back is meaningless even on A1. */
#ifndef BOARD_HAS_RUN_PERMIT_SENSE
/* REV A1 fits R53/R54 from RELAY_LOW to PC2, so the driver can be read
 * back (I-016). This was 0 for as long as PC2 was unconnected: reading a
 * floating pin invents drive faults out of noise. Flip it back to 0 only
 * for a board without the divider. */
#define BOARD_HAS_RUN_PERMIT_SENSE 1
#endif
#define BOARD_RUN_PERMIT_SENSE_PORT_NAME "PC2"
#define BOARD_RUN_PERMIT_SENSE_DIP_PIN   24u

#endif

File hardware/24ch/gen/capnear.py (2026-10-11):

"""Find a spot for a decoupling capacitor beside its IC pin (I-111, `0034` D3).

For one (IC, pin, cap) it tries cap positions on a 0.1 mm grid in the four
orientations, keeps those whose pad on the pin's net is within LIMIT of the pin,
and scores each by what it would collide with: other footprints' courtyards,
other-net pads, other-net tracks and vias (clearance 0.21 mm + half the track
width), barrier bands and the board edge. Read-only unless --apply.
Run with KiCad's python:
    python capnear.py U403 1 C407 [--limit 2.6] [--apply] [--show N] [--soft-vias] [--rip] [--avoid NET,NET] [--step 0.1]
--apply moves the cap to the best spot with no collisions (else lists the best
spots and the tracks in the way, and changes nothing). Re-route afterwards with
`finish.py dangling`, `maze.py`; `pincaps.py` is the gate.
    python capnear.py via REF PAD       # a plane via beside a pad the pour cannot reach
"""
import math
import os
import sys

import pcbnew

HERE = os.path.dirname(os.path.abspath(__file__))
sys.path.insert(0, HERE)
from rules import domain, BANDS  # noqa: E402

HW = os.path.dirname(HERE)
BOARD = os.environ.get("THERMO24_BOARD", os.path.join(HW, "thermo24.kicad_pcb"))
T, mm = pcbnew.ToMM, pcbnew.FromMM
CLR = 0.21
STEP = float(sys.argv[sys.argv.index("--step") + 1]) if "--step" in sys.argv else 0.1
SOFT_VIAS = "--soft-vias" in sys.argv     # count vias in the way instead of refusing the spot


def rect(bb, grow=0.0):
    return (T(bb.GetLeft()) - grow, T(bb.GetTop()) - grow, T(bb.GetRight()) + grow, T(bb.GetBottom()) + grow)


def overlap(a, b):
    return a[0] < b[2] and b[0] < a[2] and a[1] < b[3] and b[1] < a[3]


def _pt_seg(px, py, x1, y1, x2, y2):
    dx, dy = x2 - x1, y2 - y1
    L = dx * dx + dy * dy
    u = 0.0 if L == 0 else max(0.0, min(1.0, ((px - x1) * dx + (py - y1) * dy) / L))
    return math.hypot(px - x1 - u * dx, py - y1 - u * dy)


def _cross(a, b, c, d):
    def o(p, q, r):
        return (q[0] - p[0]) * (r[1] - p[1]) - (q[1] - p[1]) * (r[0] - p[0])
    return o(a, b, c) * o(a, b, d) < 0 and o(c, d, a) * o(c, d, b) < 0


def _seg_seg(ax, ay, bx, by, cx, cy, dx, dy):
    if _cross((ax, ay), (bx, by), (cx, cy), (dx, dy)):
        return 0.0
    return min(_pt_seg(ax, ay, cx, cy, dx, dy), _pt_seg(bx, by, cx, cy, dx, dy),
               _pt_seg(cx, cy, ax, ay, bx, by), _pt_seg(dx, dy, ax, ay, bx, by))


def seg_rect_dist(x1, y1, x2, y2, r):
    """Exact distance from a segment to an axis-aligned rectangle (0 if they touch)."""
    if any(r[0] <= x <= r[2] and r[1] <= y <= r[3] for x, y in ((x1, y1), (x2, y2))):
        return 0.0
    cs = [(r[0], r[1]), (r[2], r[1]), (r[2], r[3]), (r[0], r[3])]
    if any(_cross((x1, y1), (x2, y2), cs[i], cs[(i + 1) % 4]) for i in range(4)):
        return 0.0
    d = min(_pt_seg(cx, cy, x1, y1, x2, y2) for cx, cy in cs)
    for x, y in ((x1, y1), (x2, y2)):
        d = min(d, math.hypot(max(r[0] - x, 0, x - r[2]), max(r[1] - y, 0, y - r[3])))
    return d


def candidates(b, ic, pin, cap, limit):
    icp = next(p for p in b.FindFootprintByReference(ic).Pads() if p.GetNumber() == pin)
    px, py = T(icp.GetPosition().x), T(icp.GetPosition().y)
    net = icp.GetNetCode()
    fp = b.FindFootprintByReference(cap)
    cnet = {p.GetNumber(): p.GetNetCode() for p in fp.Pads()}
    key = next(n for n, c in cnet.items() if c == net)
    dom = domain(px, py)
    old = (fp.GetPosition(), fp.GetOrientationDegrees())
    others = [f for f in b.GetFootprints() if f.GetReference() != cap]
    crts = [(f.GetReference(), rect(f.GetCourtyard(pcbnew.F_CrtYd).BBox()))
            for f in others if f.GetCourtyard(pcbnew.F_CrtYd).OutlineCount()]
    box = (px - limit - 6, py - limit - 6, px + limit + 6, py + limit + 6)
    pads = [(f.GetReference(), p.GetNetCode(), rect(p.GetBoundingBox())) for f in others for p in f.Pads()
            if overlap(rect(p.GetBoundingBox()), box)]
    tracks = []
    tht = any(p.GetAttribute() == pcbnew.PAD_ATTRIB_PTH for p in fp.Pads())
    for t in b.GetTracks():
        if not overlap(rect(t.GetBoundingBox()), box):
            continue
        if t.Type() == pcbnew.PCB_VIA_T:
            q = t.GetPosition()
            tracks.append((t, T(q.x), T(q.y), T(q.x), T(q.y), T(t.GetWidth(pcbnew.F_Cu)) / 2, True))
        elif t.GetLayer() == pcbnew.F_Cu or tht:      # a through-hole part meets every layer
            tracks.append((t, T(t.GetStart().x), T(t.GetStart().y), T(t.GetEnd().x), T(t.GetEnd().y),
                           T(t.GetWidth()) / 2, False))
    out = []
    step = STEP
    nstep = int(limit / step) + 3
    for rot in (0, 90, 180, 270):
        for i in range(-nstep, nstep + 1):
            for j in range(-nstep, nstep + 1):
                x, y = px + i * step, py + j * step
                fp.SetPosition(pcbnew.VECTOR2I(mm(x), mm(y)))
                fp.SetOrientationDegrees(rot)
                kp = next(p for p in fp.Pads() if p.GetNumber() == key)
                d = math.hypot(T(kp.GetPosition().x) - px, T(kp.GetPosition().y) - py)
                if d > limit:
                    continue
                c = rect(fp.GetCourtyard(pcbnew.F_CrtYd).BBox())
                if c[0] < 0.5 or c[1] < 0.5 or c[2] > 169.5 or c[3] > 144.5:
                    continue
                if any(domain(cx, cy) != dom for cx, cy in ((c[0], c[1]), (c[2], c[3]), (c[0], c[3]), (c[2], c[1]))):
                    continue
                hits = [r for r, cr in crts if overlap(c, cr)]
                if hits:
                    continue
                block = set()
                bad = False
                for p in fp.Pads():
                    pr = rect(p.GetBoundingBox())
                    for r, n, q in pads:
                        if n != p.GetNetCode() and overlap(pr, (q[0] - CLR, q[1] - CLR, q[2] + CLR, q[3] + CLR)):
                            bad = True
                    for k, (t, x1, y1, x2, y2, hw, isvia) in enumerate(tracks):
                        if t.GetNetCode() == p.GetNetCode():
                            continue
                        clr = 1.5 if t.GetNetname() == "CHASSIS" else CLR
                        if seg_rect_dist(x1, y1, x2, y2, pr) < clr + hw:
                            if isvia and not SOFT_VIAS:
                                bad = True
                            block.add(k)
                if not bad:
                    out.append((len(block), round(d, 2), x, y, rot, [tracks[k][0] for k in sorted(block)]))
    fp.SetPosition(old[0])
    fp.SetOrientationDegrees(old[1])
    out.sort(key=lambda o: (o[0], o[1]))
    return out
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

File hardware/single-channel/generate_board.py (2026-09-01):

"""Generate the editable KiCad PCB for the ATmega32/MAX31856 meter.

Run with KiCad's bundled Python, not the system Python:
  "C:\\Program Files\\KiCad\\10.0\\bin\\python.exe" generate_board.py
"""

from __future__ import annotations

import heapq
import math
from pathlib import Path

import pcbnew


ROOT = Path(__file__).resolve().parent
FP_ROOT = Path(r"C:\Program Files\KiCad\10.0\share\kicad\footprints")
OUT = ROOT / "thermocouple_meter.kicad_pcb"

GRID_MM = 0.5
BOARD_W = 150.0
BOARD_H = 70.0
MARGIN = 1.5
TRACK_MM = 0.25
POWER_TRACK_MM = 0.25
CONTACT_TRACK_MM = 1.00
VIA_MM = 0.60
VIA_DRILL_MM = 0.30


def v(x: float, y: float) -> pcbnew.VECTOR2I:
    return pcbnew.VECTOR2I(pcbnew.FromMM(x), pcbnew.FromMM(y))


def mm(value: int) -> float:
    return pcbnew.ToMM(value)


board = pcbnew.BOARD()

def add_footprint(lib: str, name: str, ref: str, value: str,
                  x: float, y: float, rotation: float = 0.0) -> pcbnew.FOOTPRINT:
    fp = pcbnew.FootprintLoad(str(FP_ROOT / f"{lib}.pretty"), name)
    if fp is None:
        raise RuntimeError(f"Footprint not found: {lib}:{name}")
    fp.SetReference(ref)
    fp.SetValue(value)
    fp.Reference().SetVisible(False)
    fp.Value().SetVisible(False)
    fp.SetPosition(v(x, y))
    fp.SetOrientationDegrees(rotation)
    board.Add(fp)
    return fp


footprints: dict[str, pcbnew.FOOTPRINT] = {}


def fp(*args, **kwargs):
    item = add_footprint(*args, **kwargs)
    footprints[item.GetReference()] = item
    return item


# Major parts. The LCD is connected by a 1x16 header so it can be panel mounted.
fp("Package_DIP", "DIP-40_W15.24mm", "U1", "ATmega32A-PU", 45, 45, 90)
fp("Package_SO", "TSSOP-14_4.4x5mm_P0.65mm", "U2", "MAX31856MUD+", 22, 26)
fp("Package_TO_SOT_SMD", "SOT-223-3_TabPin2", "U3", "AMS1117-3.3", 24, 57)
fp("Connector_PinHeader_2.54mm", "PinHeader_1x16_P2.54mm_Vertical", "J2", "LCD_16x2", 35, 7, 90)
fp("TerminalBlock_Phoenix", "TerminalBlock_Phoenix_MKDS-1,5-2_1x02_P5.00mm_Horizontal", "J3", "K-TYPE", 6, 25, 90)
fp("TerminalBlock_Phoenix", "TerminalBlock_Phoenix_MKDS-1,5-2_1x02_P5.00mm_Horizontal", "J1", "5V_INPUT", 6, 58, 90)
fp("Connector_PinHeader_2.54mm", "PinHeader_2x03_P2.54mm_Vertical", "J4", "AVR_ISP", 128, 56)
fp("Potentiometer_THT", "Potentiometer_Bourns_3296W_Vertical", "RV1", "10k LCD CONTRAST", 98, 16, 90)

# 100 C alarm output.  PB3 drives both a status LED and a protected 5 V relay.
fp("Relay_THT", "Relay_SPDT_SANYOU_SRD_Series_Form_C", "K1", "SRD-05VDC-SL-C", 112, 38)
fp("TerminalBlock_Phoenix", "TerminalBlock_Phoenix_MKDS-1,5-3_1x03_P5.00mm_Horizontal",
   "J5", "RELAY_COM_NO_NC", 142, 38, 90)
fp("Package_TO_SOT_THT", "TO-92_Inline", "Q1", "2N3904 E-B-C", 102, 54)
fp("Diode_THT", "D_DO-41_SOD81_P7.62mm_Horizontal", "D1", "1N4007 FLYBACK", 109, 49)
fp("LED_THT", "LED_D5.0mm_Clear", "D2", "ALARM LED", 116, 62)

# Input filter and supply decoupling.
res_fp = ("Resistor_SMD", "R_0805_2012Metric")
cap_fp = ("Capacitor_SMD", "C_0805_2012Metric")
cap_big_fp = ("Capacitor_SMD", "C_1210_3225Metric")

fp(*res_fp, "R1", "100R 0.1%", 13.5, 23.5)
fp(*res_fp, "R2", "100R 0.1%", 13.5, 27.5)
fp(*res_fp, "R3", "10k RESET", 65, 50)
fp(*res_fp, "R7", "100R LCD LED", 80, 9)
fp(*res_fp, "R4", "1k RELAY BASE", 96, 54)
fp(*res_fp, "R5", "10k BASE PULLDOWN", 99, 60)
fp(*res_fp, "R6", "1k ALARM LED", 108, 62)

fp(*cap_big_fp, "C1", "10uF 10V", 15, 56)
fp(*cap_big_fp, "C2", "10uF 10V", 33, 56)
fp(*cap_fp, "C3", "100nF MCU VCC", 76, 50)
fp(*cap_fp, "C4", "100nF MCU AVCC", 71, 24)
fp(*cap_fp, "C5", "100nF MAX AVDD", 17.5, 33)
fp(*cap_fp, "C6", "100nF MAX DVDD", 26.5, 33)
fp(*cap_fp, "C7", "100nF TC DIFF", 15.5, 31)
fp(*cap_fp, "C8", "10nF TC+", 11, 35)
fp(*cap_fp, "C9", "10nF TC-", 20, 36)
fp(*cap_fp, "C10", "100nF AREF", 65, 24)

fp("TestPoint", "TestPoint_THTPad_D2.0mm_Drill1.0mm", "TP1", "DRDY", 31, 20)
fp("TestPoint", "TestPoint_THTPad_D2.0mm_Drill1.0mm", "TP2", "FAULT", 31, 23)


def pad(ref: str, number: str) -> pcbnew.PAD:
    item = footprints[ref].FindPadByNumber(str(number))
    if item is None:
        raise RuntimeError(f"Missing pad {ref}.{number}")
    return item


net_endpoints: dict[str, list[tuple[str, str]]] = {
    "GND": [
        ("J1", "2"), ("J2", "1"), ("J2", "5"), ("J2", "16"), ("J4", "6"),
        ("U1", "11"), ("U1", "31"), ("U2", "1"), ("U2", "14"), ("U3", "1"),
        ("C1", "2"), ("C2", "2"), ("C3", "2"), ("C4", "2"), ("C5", "2"),
        ("C6", "2"), ("C8", "2"), ("C9", "2"), ("C10", "2"), ("RV1", "1"),
        ("Q1", "1"), ("R5", "2"), ("D2", "1"),
    ],
    "+5V": [
        ("J1", "1"), ("U3", "3"), ("C1", "1"), ("J2", "2"),
        ("RV1", "3"), ("R7", "1"), ("K1", "2"), ("D1", "1"),
    ],
    "+3V3": [
        ("U3", "2"), ("C2", "1"), ("U1", "10"), ("U1", "30"),
        ("U2", "5"), ("U2", "8"), ("C3", "1"), ("C4", "1"), ("C5", "1"),
        ("C6", "1"), ("R3", "1"), ("J4", "2"),
    ],
    "RESET": [("U1", "9"), ("R3", "2"), ("J4", "5")],
    "SPI_CS": [("U1", "5"), ("U2", "9")],
    "SPI_MOSI": [("U1", "6"), ("U2", "12"), ("J4", "4")],
    "SPI_MISO": [("U1", "7"), ("U2", "11"), ("J4", "1")],
    "SPI_SCK": [("U1", "8"), ("U2", "10"), ("J4", "3")],
    "MAX_DRDY": [("U2", "7"), ("TP1", "1")],
    "MAX_FAULT": [("U2", "13"), ("TP2", "1")],
    "TC_RAW_PLUS": [("J3", "1"), ("R1", "1")],
    "TC_PLUS": [("R1", "2"), ("U2", "4"), ("C7", "1"), ("C8", "1")],
    "TC_RAW_MINUS": [("J3", "2"), ("R2", "1")],
    "TC_MINUS": [("R2", "2"), ("U2", "2"), ("U2", "3"), ("C7", "2"), ("C9", "1")],
    "LCD_VO": [("RV1", "2"), ("J2", "3")],
    "LCD_RS": [("U1", "40"), ("J2", "4")],
    "LCD_E": [("U1", "39"), ("J2", "6")],
    "LCD_D4": [("U1", "36"), ("J2", "11")],
    "LCD_D5": [("U1", "35"), ("J2", "12")],
    "LCD_D6": [("U1", "34"), ("J2", "13")],
    "LCD_D7": [("U1", "33"), ("J2", "14")],
    "LCD_LED_A": [("R7", "2"), ("J2", "15")],
    "AREF": [("U1", "32"), ("C10", "1")],
    "ALARM_GPIO": [("U1", "4"), ("R4", "1"), ("R6", "1")],
    "ALARM_BASE": [("R4", "2"), ("R5", "1"), ("Q1", "2")],
    "RELAY_LOW": [("Q1", "3"), ("K1", "5"), ("D1", "2")],
    "ALARM_LED_A": [("R6", "2"), ("D2", "2")],
    "RELAY_COM": [("K1", "1"), ("J5", "1")],
    "RELAY_NO": [("K1", "3"), ("J5", "2")],
    "RELAY_NC": [("K1", "4"), ("J5", "3")],
}

nets: dict[str, pcbnew.NETINFO_ITEM] = {}
for name, endpoints in net_endpoints.items():
    net = pcbnew.NETINFO_ITEM(board, name)
    board.Add(net)
    nets[name] = net
    for ref, number in endpoints:
        pad(ref, number).SetNet(net)


# Board outline.
outline_points = [(0, 0), (BOARD_W, 0), (BOARD_W, BOARD_H), (0, BOARD_H), (0, 0)]
for a, b in zip(outline_points, outline_points[1:]):
    shape = pcbnew.PCB_SHAPE(board)
    shape.SetShape(pcbnew.SHAPE_T_SEGMENT)
    shape.SetLayer(pcbnew.Edge_Cuts)
    shape.SetStart(v(*a))
    shape.SetEnd(v(*b))
    shape.SetWidth(pcbnew.FromMM(0.1))
    board.Add(shape)
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

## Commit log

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2026-09-07 fix bugs
    [01_power.kicad_sch, 02_controller.kicad_sch, 03_channels_1_4.kicad_sch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]
2026-09-07 Firmware for the real board, sourcing, fuses; close 16 issues
    The eight-channel application linked the MAX6675 bank driver, so the
    MAX31856 board it is built for had no firmware at all (I-030). It has one
    now, and the safety gaps around it are closed.
    Firmware
    I-030 hal/temperature_max31856_bank.c - eight converters on one bus,
    per-channel state, configuration read back, a channel that loses
    the bus re-configured on its next scan
    I-031 hal/run_permit.* names the permit semantics; the legacy image
    drives the same pin with the opposite meaning, and no .hex is
    tracked any more so a stale one cannot be flashed by mistake
    I-012 setpoint in EEPROM behi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
    [01_power.kicad_sch, 02_controller.kicad_sch, 03_channels_1_4.kicad_sch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]
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2026-09-14 One KiCad MCP: Konnect over IPC; retire the Seeed server
    The Seeed MCP was installed on 2026-09-13 and is gone by 2026-09-14. Reading
    its source settled it: add_wire reads the file as text, strips the closing
    paren, concatenates and writes back - no parser, no pin lookup, no ERC. That is
    worse than populate_schematic.py, which resolves pin coordinates first.
    Replaced by Konnect (mixelpixx/Konnect v0.11.1) on KiCad 10's official IPC API.
    Measured on this machine rather than taken from docs: _eeschema.dll carries
    API_HANDLER_SCH, so the schematic is served today; BeginCommit/EndCommit put
    edits in KiCad's undo stack; there is no plot, export or run-DRC command, so
    verification stays with kica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
2026-09-14 Fix the Konnect MCP: one registration, not two
    Registered at both user scope (~/.claude.json) and project scope (.mcp.json),
    which is a name collision. The result was CONNECTION_CLOSED against a server
    that is provably healthy: it spawns in 0.01 s, survives 12 s idle, and answers
    initialize correctly under both an inherited and a minimal environment. The
    project entry was also never approved - enabledMcpjsonServers was empty.
    Keep the user-scope registration, which is what "global" means and needs no
    per-project approval. .mcp.json now declares no servers and carries the
    KICAD_API_SOCKET warning as a comment for anyone setting the project up on
    another machine.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
2026-09-24 Fix the cloud hook: KiCad 10 from ghcr.io when the PPA is blocked, never Ubuntu's KiCad 7; log I-057.
2026-09-24 Redraw the schematic with wires (I-002), fix the K1 relay coil pins (I-058) and the U12 symbol link (I-057).
    [thermocouple_8ch.kicad_sch]
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2026-09-26 REV A1 board regenerated and routed (I-061, I-060)
    Owner decisions: keep U14's 0.2 mm thermal vias and lower the board hole
    minimum (0017); J3 keeps COM/NO/NC and moves to line up with K1 (0018).
    Fixed on the way:
    - R59/R60 turned to 270 so R60's GND pad is not walled in by routing.
    - MAX31856 GND pins get fixed vias like the supply pins; left to the pour,
    one floated per run (U3.14, then U5.14).
    - route.py re-stitches pour pieces after closing gaps.
    Measured with KiCad 10.0.3: check_board.py all 6 ok; DRC with zone refill
    and schematic parity: 0 errors, 0 unconnected, 0 parity, 14 silkscreen
    warnings. validate.ps1 stops at ERC on I-063 (KiCad version), not the board.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
    [thermocouple_8ch.kicad_pcb]
2026-09-26 Silkscreen placed by measured boxes; REV A1 release documented
    The dry-contact marking ("LOW-VOLTAGE LOAD ONLY") was printed over K1's
    pads, where the fab clips silkscreen. place_labels() now puts free text at
    its first clear candidate and refuses to leave the required marking
    anywhere else; it now sits beside J3. Designators are checked with their
    real bounding boxes, with corner, 90-degree and nearest-clear-grid
    fallbacks. generate_board.py --silk-only applies this to a routed board
    without touching copper.
    validate.ps1 on KiCad 10.0.6: ERC 0/0, netlist IDENTICAL 201/162/645,
    DRC 0 errors, 0 warnings, 0 unconnected, 0 parity. check_board.py all ok.
    Docs: close I-006, I-016, I-024, I-032,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
    [thermocouple_8ch.kicad_pcb]
2026-09-26 Hierarchical schematic; U12 decoupling fixed; two blind gates fixed (I-062, I-045)
    Schematic (I-062, decision 0019): an A3 root plus channel.kicad_sch (A4)
    used by sheets TC1-TC8, derived by sch_layout/hier.py as the last step of
    build.py. Only channel-internal nets were renamed (/TCn_X -> /TCn/X, 40
    nets); JTC1-8 value -> K_TYPE (KiCad 10 keeps one value per symbol).
    netlist_fingerprint.py --allow-renames proved all 645 pins on the same
    nets; the baseline was regenerated from that netlist with the reason in it.
    apply_rules.py patterns follow (without them: 499 isolation violations on a
    test copy); board nets renamed in place by rename_board_nets.py.
    Board (I-045): C45, U12's input cap, sat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
    [channel.kicad_sch, thermocouple_8ch.kicad_pcb, thermocouple_8ch.kicad_sch]
2026-09-26 Close I-027 from the MAX31856 datasheet; silkscreen said REV A0 on REV A1
    MAX31856 datasheet 19-7534 Rev 0 added (from LCSC C116632; analog.com resets
    the workstation's connection). "T- is biased to approximately 0.735V by the
    BIAS output" and the typical circuit is a floating thermocouple with BIAS on
    T-, which every channel already has; BIAS floats between conversions and the
    bank driver runs continuous mode. Ungrounded probes need no extra resistor.
    The REV A1 board carried "THERMO-8CH REV A0" on its silkscreen: BOARD_REV was
    never bumped. Now A1; place_labels() rewrites the revision line so
    generate_board.py --silk-only carries a bump to a routed board.
    validate.ps1: ERC 0/0, netlist I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
    [thermocouple_8ch.kicad_pcb]
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2026-09-26 Repo hygiene: .gitignore tidied, archive rule for ordered revisions, stale docs corrected
    .gitignore: 14 redundant firmware/build lines removed, stale baseline
    comment corrected, konnect/ log folder ignored, and a rule that an ordered
    revision's upload zip is committed under hardware/8ch/fabricated/<rev>/.
    TOOLS.md said REV A0 was fabricated (0014: it was not). hardware/8ch
    README and the datasheet index no longer describe the pre-I-002
    schematic, the closed I-035 conflict, or the missing MAX31856.
2026-09-26 ADM2587E datasheet added; its 120 mA max replaces the 100 mA estimate (I-028 d)
    Load 0.405 -> 0.425 A, inside the 0.6 A design current. Input 98 mA at 24 V,
    0.39 A at the 6 V floor; the 1 A panel fuse keeps 2.5x.
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2026-09-27 REV A2: pre-fabrication fixes I-065..I-069 (decision 0022)
    - U10/U11 ISO7760DWR/ISO7761DWR (no F: open input -> HIGH) + R61 2k2 on
    U11 OUTF -> MISO_CTRL so in-circuit ISP works (I-065)
    - Q1 BSS131 240 V SOT-23 replaces the 60 V 2N7000 (I-066)
    - R53/R54 100k/22k: 0.28 mA into PC2's clamp at 58 V (I-067)
    - F1 1812L075/60GR, 60 V 0.75 A 1812 (I-068)
    - D2 drawn unidirectional, D3 = M7 SMA, U12 sourcing warning (I-069)
    - netlist-baseline-reva2.json (202/163/647), BOARD_REV A2
    - board regenerated and re-routed; one hand via for C41.1 (+5V_CTRL)
    - run_all.ps1 no longer calls populate_schematic.py (hierarchical sheet)
    validate.ps1 2026-09-28 01:07: ERC 0/0, netlist IDENTICAL, DRC 0/0/0/0;
    check_b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
    [channel.kicad_sch, isolation.kicad_sch, mcu.kicad_sch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]
2026-09-27 U14 thermal vias 0.3 mm (0023, supersedes 0017); C41.1 fixed via; REV A2 re-routed
    Smallest hole on the board is now 0.3 mm. Board fully generated, no hand edits.
    validate.ps1 2026-09-28 01:43: ERC 0/0, netlist IDENTICAL 202/163/647,
    DRC 0/0/0/0; check_board.py all 6 ok.
    [channel.kicad_sch, isolation.kicad_sch, mcu.kicad_sch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]
2026-09-30 2026-09-29 review (24-channel scope, I-070..I-087) and ISSUES.md as a priority index (0025)
    - Review by another agent: 24 thermocouples (0024), I-073 unsafe ACK repro,
    I-075 U14 vias 0.4 mm, I-076 buck layout, I-079 coil 1.44 kOhm, and more
    - Agreed 2026-10-01: 3 autonomous REV A2 modules (0024 update); overstated
    findings kept with 'Review weight' (I-077, I-080, I-081, I-086 -> P3)
    - ISSUES.md: P0-P3, short rows, 72 KB -> 11 KB; closed rows -> ISSUES-closed.md
    - REV A2 package on hold for P0
2026-09-30 P0: U14 power stage drawn by the generator (0026), via re-drill after SES import (I-075), unsafe ACK fixed (I-073)
    - route.py restores a 0.15 mm ring on the 41 vias the SES import re-drilled
    to 0.4 mm; apply_rules.py min_via_annular_width 0.15 so DRC catches it
    - board/powerstage.py + placement: C63/C54 at U14.1-2, SW one 1.0 mm track
    to L1, BST 3 mm; protected in the DSN. VIN-C63 19.5 -> 3.5 mm
    - protection.c: a recovered save fault passes the normal ACK checks; 5
    regression tests (sub-agent, reviewed); version REVA2; CI uses reva2
    validate.ps1 2026-10-01 00:44: ERC 0/0, netlist IDENTICAL 202/163/647,
    DRC 0/0/0/0; check_board all ok; .drl: six 0.3 mm at U14; build.ps1 PASS.
    Co-Author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
    [thermocouple_8ch.kicad_pcb]
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2026-09-30 Every power-up waits for ACK (I-074, FW 0.2.1); technician kit list (kit_list.py); I-089
    - STARTUP latch at boot: START: PRESS ACK, never SAFE; ACK only when all
    channels valid and cool. Sonnet sub-agent, reviewed; build.ps1 exit 0,
    3 suites PASS, 8ch 5918 B
    - kit_list.py: through-hole parts read from the board + socket, LCD, cable,
    shunts, panel fuse; x3 boards
    - I-089: a watchdog/brown-out reset while running also waits for ACK
    - .gitignore: .claude/worktrees/
2026-10-07 REV A3 plan agreed (0030): stacked modules, probe-bias option, signal contact, work split
    - 0030: three identical 8-ch modules stacked, each trips alone, contacts in
    series; master display by jumper (one firmware image); ACK one button with
    three contacts; non-isolated RS-485 in one panel; 30 VDC / 1 A signal relay;
    per-channel BIAS footprint (0 ohm default) + module reference (bench-qualify)
    - I-101 probe bias (blocker), I-102 panel fuse for three modules
    - CALCULATIONS 6: BIAS-fight arithmetic, three-module fuse I2t; 0008 slip fixed
    - Plan reviewed read-only by Codex gpt-6.1-sol
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2026-10-09 24-ch decisions 0031-0033 and the engineering record
    One 24-channel board with 3x AD7124-8 (0031), front-end circuit and part
    picks (0032), board size 170x145 / NORI turnkey / routing method / A3-A4
    schematic pages (0033). STATE, ISSUES (I-106..I-110), TOOLS (24-ch routing
    workflow, maze tool, GUI driving, Codex sandbox workaround) updated.
2026-10-09 24-ch board: generator, schematic (12 pages, ERC 0) and routed PCB
    Routed board thermo24.kicad_pcb: KiCad DRC 0 violations, 2 unconnected
    (TC21_NA, CS_CJ5_ISO) - finishing by hand next. Tools: finish.py
    (incremental fixes), maze.py (grid router), cost.py, view.py, kicad_ui.ps1.
    [bank_a_1.kicad_sch, bank_a_2.kicad_sch, bank_b_1.kicad_sch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]
2026-10-09 24-ch board routed: DRC 0 violations, 0 unconnected, 0 footprint errors
    Last two connections finished (TC21 pair re-assigned, TC21_PA and two
    CS_CJ5_ISO pieces on In2.Cu - 0033 D4). rules.py full: outer pours, NORI
    pad-to-track 0.2 mm on pads, relay_area only for contact nets. finish.py
    gains nori (push tracks off pads), dangling (delete router stubs, each
    checked by DRC on a copy); maze.py can use In2.Cu and starts from vias.
    pcb sync applied (C8545, C28260; 0 pad changes). Report:
    output/drc-synced.rpt (0/0/0, schematic parity).
    [thermo24.kicad_pcb]
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2026-10-09 24-ch: installer silkscreen and first fab set
    silk.py rewritten: every terminal pin labelled (+ n - for the 24 TCs,
    +24V/0V/SH, C/NO/NC with TRIP/ALARM, RS-485 A B GND), buttons/LEDs/test
    points by function, placed by obstacle search; barrier outline broken at
    the isolators. 0 silkscreen warnings. fab.py saves the refilled pours
    before plotting, names the Gerber layers, adds a drill map and leaves
    test pads out of BOM/CPL. production/24ch-reva3-20261009: DRC 0/0/0,
    BOM 93 lines (5 buttons without LCSC code, I-108).
    [thermo24.kicad_pcb]
2026-10-09 Astra review recorded: 0034, ISSUES I-111..I-120, entry points on 24ch
    Whole-project review by Codex GPT-6-Astra (docs/reference/review-20261009-astra.md).
    Accepted: decoupling/buck parts far from pins (I-111, re-measured), fiducials,
    RUN PERMIT labelling, CJ distance, 24-ch gates, accessory BOM, heartbeat and
    firmware port list, test matrix. 0034: open thermocouple trips by default
    (owner), board buttons + parallel panel-button header, local layout repair.
    I-101 engine-ground measurement moved to the first engine test (owner).
    AGENTS/README now point at hardware/24ch as the active board.
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2026-10-12 24ch cheaper-parts variant (0036): TMP126, CA-IS3761HW, RS-485 DNP, drop-in swaps
    - CJ sensors ADT7310 x6 -> TMP126DCKR (C5219998); R443 22k DIN_ISO-DOUT_ISO for the
    3-wire SIO, R415 removed, ALERT grounded. Sensors moved <= 8 mm to clear spots beside
    their 100 nF (no closer spot to the terminals without touching TC traces, 0035 D2).
    - ISO7761 -> CA-IS3761HW (same pinout, 5F/1R, default high); BOCHEN 3296W trimmer;
    SAMWHA 22u 1210.
    - RS-485 block DNP: footprints kept; fab.py drops DNP parts from BOM/CPL and writes
    DNP.txt; cost.py skips them. External window watchdog tried and removed (owner).
    - gen/delta.py: carry a schematic change onto the routed board (replace/add/remove,
    re-ne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
2026-10-12 24ch 0036 D7/D8: screw terminals face the board edge; supplier files as an RFQ
    - J601/J701/J702/J703 turned 180 deg about the middle pin (wire entry was blocked by the
    relays ~2 mm in front); pin numbers 1<->3 swapped in the generator so every position keeps
    its net, label and copper. RS-485 row (DNP) moved 0.5 mm with its track ends, BIAS_B routed
    around J703 pin 1, TRIP_COM stub extended to the round pad.
    - delta.py: MPN/LCSC/Manufacturer fields go to F.Fab hidden (were printed on the silkscreen of
    the six TMP126), new footprints hide reference/value like the rest of the board.
    - fab.py: ORDER-NOTES rewritten as a friendly request for quotation (LCSC = reference only,
    equivalents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
2026-10-14 docs 0037: one board family (8/24/36 ch), one firmware, state per product
    - decision 0037: the 8-ch option and the 36-ch board derive from the 24-ch
    architecture (1/3/5 banks of AD7124-8); one family firmware; products are
    folders, branches are variants or one chat's work; tag 24ch-premium.
    - docs/STATE.md is an index; hardware/24ch, hardware/8ch and firmware keep
    their own STATE.md (60 lines each, checked by check_docs.py).
    - RS-485/Modbus fitted again (owner 2026-10-14, reverses 0036 D2): GOAL R-9
    says so; the release change is the next job, in branch 24ch-order.
    - Branches: 24ch-order, firmware (+ simulation), 8ch, 36ch.
2026-10-14 24ch 0036 D9: RS-485/Modbus fitted again (owner), release tooling for no DNP
    - c_out.py: the 16 RS-485 parts are fitted (reverses 0036 D2); build.py
    ERC 0/0, netlist check 0/0. delta.py cleared the 16 DNP flags on the
    board, no copper changed (0 tracks deleted); pincaps 0 over the limit.
    - fab.py: DNP.txt says "none" when every footprint is fitted; jumper shunts
    for JP731-JP733 go to the supplier accessories; J703 in the terminal
    orientation note.
    - assembly_spec.py: counts and the through-hole list read from BOM.csv;
    section 6 adapts to a release without DNP; U703 and J703 in the checklist.
    - docs: 0036 D9, I-094, CALCULATIONS 8.1 (+$8.64/board).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
2026-10-15 24ch REV A4 (WIP): gated TMP126 SIO driver, PD5 = SIO_WR_N, ESC via diodes
    - PD5 (was BTN_ESC) drives SIO_WR_N through spare U405 channel C to U411
    74LVC1G125 (OE); DIN -> U411 -> R446 220R -> DOUT_ISO; R445 10k, R447 100k,
    C421 100n, R439 10k pull-up. R443 22k removed (R446 reuses its footprint).
    Same circuit as hardware/family (fixes the TMP126 SIO edge, 1.2-1.6 us vs 100 ns).
    - ESC button kept: D501/D502 1N4148W pull BTN_UP and BTN_DOWN together;
    firmware reads UP+DOWN as ESC.
    - Board edited incrementally (delta.py, capnear.py, maze.py with In2 for
    SIO_DRV / SIO_WR_N_ISO); dead DIN branch to the old R443 pad removed.
    - Gates: build.py ERC 0 errors 0 warnings, netlist 0 mismatche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
2026-10-15 24ch REV A4: silkscreen, release, decision 0041 and calculations
    - silk.py: REV A4 title; the --strip child now runs under the parent's
    writer claim (it refused against its own parent before).
    - Release production/24ch-reva4-20261015-055057-fc0aac (not committed):
    DRC errors/unconnected/parity 0/0/0 refilled, pincaps 0 over, BOM 96 lines.
    - decisions/0041: gated TMP126 SIO driver, PD5 from ESC, ESC via diodes,
    alternatives rejected, firmware requirements.
    - CALCULATIONS 8.5 (supersedes 8.3): SIO edge ~19 ns vs 100 ns, DOUT load
    33 uA, ESC diode levels. superseded.txt, README, STATE, I-119 swept.
    - check_docs 0 findings.
2026-10-15 24ch REV A4: terminal labels from the pad net (review C-1)
    silk.py paired fixed names with pin numbers; after the 0036 D7 180-degree
    turn that mirrored +24V/CHAS on J601 and C/NC on J701/J702 when the A4 silk
    was regenerated (A3 had them hand-corrected). Labels now come from each pad's
    net; checked: J601 +24V/0V/CHAS, J701 and J702 C/NO/NC over the right pads.
2026-10-15 24ch REV A4: pre-order review results, release b4c4e2
    Four reviewers (power, measurement chain, MCU/trip/alarm, BOM/footprint/
    mechanics) found no circuit, pinout or package error; the one blocking
    finding (mirrored terminal labels) is fixed in 0c83f2e. New release
    24ch-reva4-20261015-194355-b4c4e2: DRC 0/0/0, BOM 96 lines; the fc0aac
    release with the wrong labels is in production/_OLD_DO_NOT_ORDER.
2026-10-15 24ch REV A4: Astra review fixes, release 195548-b4c4e2
    Astra (gpt-6-astra, high): no redesign blocker. Fixed its documentation
    findings: schematic title REV A4 and RS-485 block no longer called DNP;
    ASSEMBLY-SPEC.pdf generated into the release; I-085 now says J601 pin 1 =
    CHASSIS, pin 3 = +24V (0036 D7 turn); TMP126 write transactions keep
    SIO_WR_N low through data and CRC (0041, c_iso.py note).
    ERC 0/0, netlist 0 mismatches, board unchanged (delta dry: 0), release DRC
    0/0/0, BOM 96 lines. Previous releases archived in _OLD_DO_NOT_ORDER.
2026-10-15 24ch REV A4: Astra values/completeness review recorded
    No missing part or wrong value that blocks the order. CALCULATIONS 8.5:
    SIO bus ~180 pF (not 85) -> edge ~40 ns, still < 100 ns; charge-pump gate
    vs PWM frequency (>= 1 kHz). 0041: firmware rules and the optional,
    not-done items (ADM2587E 100 nF pairs, REF3030 input cap, crystal CL).
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2026-10-15 24ch REV A4: via fixes from Astra review 3, release 231449-c7a3f0
    Removed 3 overlapping/duplicate plane vias left by today's routing (+5V near
    R438/R439, +3V3_ISO near R445/C421). Moved 7 A3-era vias out of solder pads
    (U302.6 TMP126 VDD, C190.2, C290.2, C503.1, C506.1, U703.10, U403.13); the
    CS_CJ6 via at U405.15 grazes the pad edge by 0.075 mm and has no clear spot,
    left as in A3. DRC errors/unconnected/parity 0/0/0; full DRC: no hole
    warnings, only the 15 dangling-stub warnings A3 had; pincaps 0 over.
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2026-10-18 8ch REV B0-2L: two-layer variant for a local fab (0040)
    Placement spread to 150 x 154 mm, ground poured on both layers, local-fab rules; last 12 connections routed from a Sol route list; Astra review fixes (vias 0.7/0.3, relay rule not for pours I-129, fab limits in ORDER-NOTES). Release candidate 8ch-revb0-2l-20261016-203125-6a2893, DRC 0/0/0.
2026-10-18 docs: 0039 8/40-ch plan, 40-ch calculations, family state; ISSUES I-128..I-130
    GOAL/README/AGENTS/STATE for the family (36 -> 40 ch), check_docs knows the new product STATE files, TOOLS family section, CALCULATIONS sec. 10, superseded wording. I-129 relay rule hugging pours, I-130 island mounting hardware (both also on the 24-ch).
2026-10-18 24ch: nylon standoffs on the island holes; relay clearance rule checked on A4
2026-10-18 24ch: pours out of the relay clearance exception (main I-129), release 011858
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2026-10-18 40ch REV A0: PT100 area re-layout after Astra review, DRC 0/0/0, pincaps 0
    Sol round 10 + two fix-ups: RTD sense pairs 9-12 mm (RTD2 was 35/125 mm), R1092 Kelvin,
    leads split at the terminal pads, C1096 loop 1.77 mm, no vias in small IC pads, no
    digital/sense crossings. Release 40ch-reva0-20261019-024508-4774af; 20261017 archived.
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2026-10-19 40ch REV A0: drill-hole overlaps and via holes in SMD lands fixed (Astra re-review)
    Sol round 11: hole pairs under 0.25 mm 19 -> 0 (KiCad hole_to_hole/holes_co_located 0),
    via hole to small SMD land under 0.10 mm 61 -> 0, SAC/SBC partly shortened. DRC 0/0/0,
    pincaps 0. Release 40ch-reva0-20261019-040422-9bed30; 024508 archived.
2026-10-19 40ch, 8ch-new, 8ch-2l: hole_to_hole and holes_co_located are DRC errors (I-131)
    The release DRC counts errors only, so overlapping drill holes passed as warnings.
    40ch release board: 0; 8ch-new: 23 (being fixed).
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2026-10-19 8ch REV B0: overlapping drill holes and vias in SMD lands fixed (I-131)
    12 hole_to_hole + 11 co-located holes and 3 vias into lands removed/moved; DRC 0/0/0
    with hole rules as errors, pincaps 0. Release 8ch-revb0-20261019-042934-2d12ea.
2026-10-19 8ch REV B0-2L: vias out of U703.10 and U101.24 lands (I-131)
    DRC 0/0/0 with hole rules as errors, pincaps 0. Release 8ch-revb0-2l-20261019-042949-393f63.
2026-10-19 ISSUES I-131: drill-hole overlaps and vias in SMD lands, 40/8/8-2L fixed, 24-ch noted
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2026-10-19 family tools: stdlib board reader and clearance/hole checker (no KiCad)
    For cloud sessions and agents without KiCad, fast planning and a second opinion.
    0 clearance/hole findings on 40ch/8ch-new/8ch-2l, matches KiCad's pre-r10 hole pairs
    by UUID; approximations listed in its output. TOOLS.md section, family STATE.
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2026-10-20 firmware spec: T_WIN 900 ms, PWM 2 kHz, save-failure split, power counter wear
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2026-10-20 firmware spec rev 4: Astra re-check fixes (internal-signal UV exception, readback states, MCLK repeated read, one timing model, staged calibration bound to channel type)
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2026-10-20 family firmware lane A (Sol): F0 for the 24-ch - board_cfg, MCAL + fakes, iso_spi/ad7124/tmp126/lcd/keys/relays/rs485, scan with all diagnostic slots, service mode, F0 main (RUN never granted); 715 h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
2026-10-20 family firmware lane C (Sol, independent): acceptance tests from the spec only - 14182 assertions, 12 fail (OFF-channel C faults raise alarm; same-call ACK+scan starts PWM; scan of an old settings se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
2026-10-21 family firmware F1c (Sol): Astra findings 1,2,4,5 + service entry fixed (sticky Timer2 expiry, key-press aborts relay test, single ACK timestamp, newest evidence clears alarms, invalid settings -> CO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
2026-10-23 24ch: clean DRC-dangling tracks (7 overshoots trimmed 0.3-4.7 mm, 3 leftover bits + overlapping DIN_ISO stub removed; 6 junction vias kept), new gen/dangling.py; fab.py adds a warnings DRC pass and b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
2026-10-23 family fw F5-F8, C4: Astra fixes, 24-ch only, cppcheck, program.ps1, 60-day soak, scan gap, REF retry, identity
    F5: Astra full-review fixes (G01 after first save, scan vs loop cadence, ACK refusal channel,
    C10/C11 cause order, stack high-water). F6: 24-ch only (MAX_CHANNELS 24, MAX_BANKS 3, owner
    2026-10-23, 0043 9), cppcheck 2.22 gate, program.ps1 (USBasp, fuse read-back), .init order gate,
    60-day soak (found/fixed REF-test window expiry and event timestamps at the ms wrap). C4: acceptance
    24-only. F7: gap between validated scans bounded under loop jitter (Astra: 1230 ms -> <= ~1050 ms),
    limits unchanged (I-124). F8: REF retry after a transient G08; firmware identity record at 0x1FF80
    in th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
